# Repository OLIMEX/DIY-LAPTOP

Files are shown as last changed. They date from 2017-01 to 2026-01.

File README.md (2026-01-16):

OLIMEX Company Logo
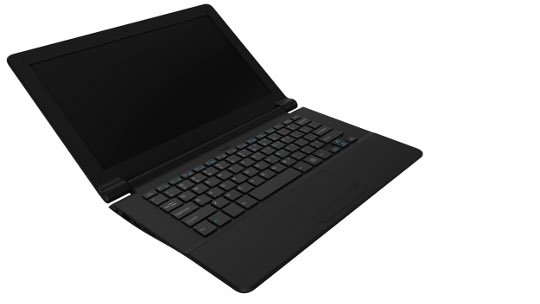
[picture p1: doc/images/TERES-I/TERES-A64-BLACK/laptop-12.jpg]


<br clear="right">

# TERES-I

<br><br>

## Overview

TERES-I is a Do-It-Yourself (DIY) Free/Open Source Hardware ([FOSH](https://wikipedia.org/wiki/Open-source_hardware)) and Software ([FOSS](https://wikipedia.org/wiki/Free_and_open-source_software)) laptop.
Stylish, elegant and lightweight, TERES-I is a convenient travel companion and is great for playing videos, browsing the web, or using a plethora of development suites.
It runs Linux on 64-bit ARM64 and x86 processors.

NOTE: TERES-I is currently considered an [evaluation board](doc/web/evaluation-board-notice.md) and not yet an end-product.

[Purchase your TERES-I here!](https://www.olimex.com/Products/DIY-Laptop/KITS)

| FEATURE | DESCRIPTION |
|:---:|:---:|
| **CPU** | [Quad-Core Allwinner A64 64-bit Cortex-A53](doc/datasheets/Allwinner-A64/A64_Datasheet_V1.1.pdf) |
| **Memory** | 2GB DDR3L RAM memory [2x Hynix H5TC8G63AMR-PBA](doc/datasheets/RAM/H5TC8G63AMR-PBA.pdf) |
| **Internal Storage** | 16GB eMMC memory [MTFC16GAKAENA-4M](doc/datasheets/eMMC/emmc_1664gb_ps8222_153b_v50_it.pdf) |
| **Monitor** | [LCD 11.6" 1366x768 resolution](doc/datasheets/TERES-015-LCD11.6/N116BGE-EA2.pdf) |
| **Video In** | [VGA 640x480 camera](HARDWARE/A64-TERES/TERES-019-Camera/N03A61B36DL32.pdf) |
| **Video Out** | mini HDMI |
| **Audio In/Out** | 2x (stereo) speakers; 2x 3.5mm audio jack (1x microphone in, 1x stereo out) |
| **Wireless** | Realtek 8723BS (WiFi 150Mb, BLE 4.0) |
| **USB** | 2x USB 2.0 |
| **Power** | 1x 9500mAh [battery](doc/datasheets/LiPo-Battery/JA426992P2P-Spec-Data-Sheet-3.7V-7000mAh--161201.pdf); 5V/3A input |
| **Weight** | 980 g (2.16 lb) |

## [Hardware](HARDWARE)

* [TERES-A64-WHITE](https://www.olimex.com/Products/DIY-Laptop/KITS/TERES-A64-WHITE)
* [TERES-A64-BLACK](https://www.olimex.com/Products/DIY-Laptop/KITS/TERES-A64-BLACK)
* [Spare parts](https://www.olimex.com/Products/DIY-Laptop/SPARE-PARTS)
* [Assembling your TERES-I](doc/web/hw_assembly.md)

## [Software](SOFTWARE)

TERES-I was designed to run on Linux distributions, but may also run Android and Windows operating systems.
The laptop's mainboard has eMMC flash loaded with Ubuntu Mate and basic programs – Internet browser, Open Office, Arduino IDE, IceStorm FPGA Verilog tools, a video player, etc.
Additional software is also available from Ubuntu repositories.

* [Installing an image](doc/web/sw_fresh-os.md)
* [Updating an image](doc/web/sw_updating-os.md)
* Building an image
  * [Internal script](SOFTWARE/A64-TERES/scripts/README.md)
  * [Manual build reference](http://linux-sunxi.org/Manual_build_howto)

## Other resources

* [FAQ](doc/web/res_faq.md)
* [Troubleshooting](https://www.olimex.com/forum/index.php?board=39.0)
* [Assembly manuals (PDF)](doc/manuals)
* [What's next?](doc/web/res_next-steps.md)
* [linux-sunxi Laptop Page](https://linux-sunxi.org/Olimex_Teres-A64) including hardware mods
* [Community Links](doc/web/res_community.md)
* 
## Community links

* Discord: #teres on Olimex [discord](https://discord.com/invite/QQEBXZk7y8) server
* IRC: #teres on OFTC.net, [webchat](https://webchat.oftc.net/?channels=#teres)

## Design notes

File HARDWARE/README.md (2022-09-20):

# Hardware

## Overview

All hardware schematics and board files are designed using [KiCad](http://kicad-pcb.org) open-source CAD software.

> KiCad is free software. KiCad is made available under the [GNU General Public License (GPL) version 3](https://www.gnu.org/licenses/gpl-3.0.en.html) or greater.

You may download KiCad and open for reviewing or editing each of the PCB files.
The schematics are also available as PDF files for easier viewing and/or printing.

**NOTE**: Please use the latest KiCad nightly development build, as the latest stable build may not have all required features.

## Introduction to the hardware of TERES-I

TERES-I internal electronics consists of the folowing boards:

### Main board ([PCB1-A64-MAIN](A64-TERES/TERES-PCB1-A64-MAIN))

The main board (**PCB1-A64-MAIN**) is comprised of:

* A64 processor
* RAM and flash NAND memories
* Power management unit
* LCD converter
* Connectors to different interfaces
* and others

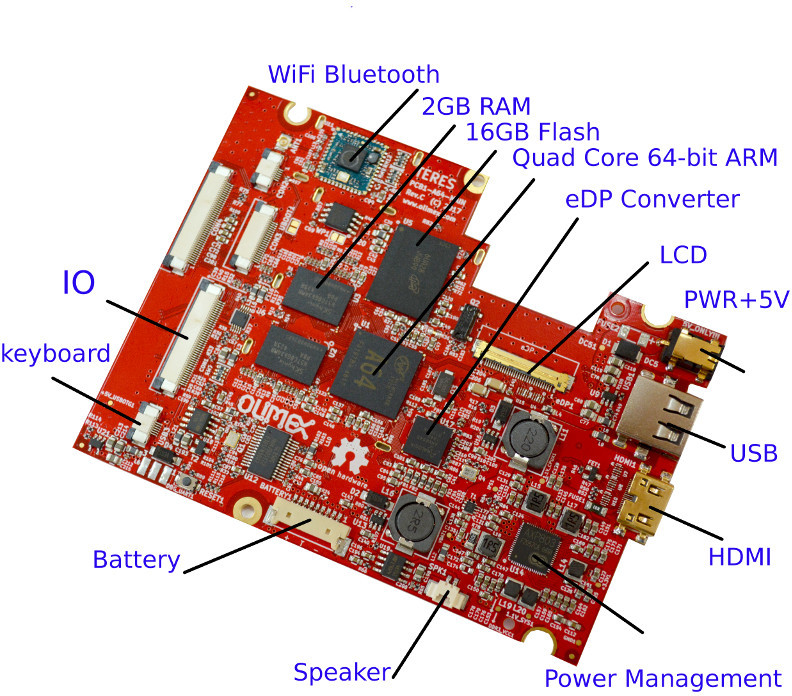
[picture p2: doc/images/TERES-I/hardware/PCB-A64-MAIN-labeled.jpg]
Main Board with Labels


Alternative main board processors and memory configuration options will be available in the future.
These should be compatible with all other existing boards.
Subsequent revisions are expected to have increased processing speed and improved memory performance.

### Keyboard controller ([TERES-PCB5-KEYBOARD](A64-TERES/TERES-PCB5-KEYBOARD))

The **KEYBOARD controller** board (**TERES-PCB5-KEYBOARD**) is responsible for handling the keyboard and touch pad interfaces.
This keyboard controller board allows you to completely reprogram the keyboard mapping and response according to your own taste.

This board contains an AVR processor.
Sources, binaries and update procedures for AVR firmware are available at GitHub.
Keyboard/touch controller firmware may be updated live on the board itself.
It can also be programmed using an Arduino microcontroller.
Touch screen parameters can also be changed.

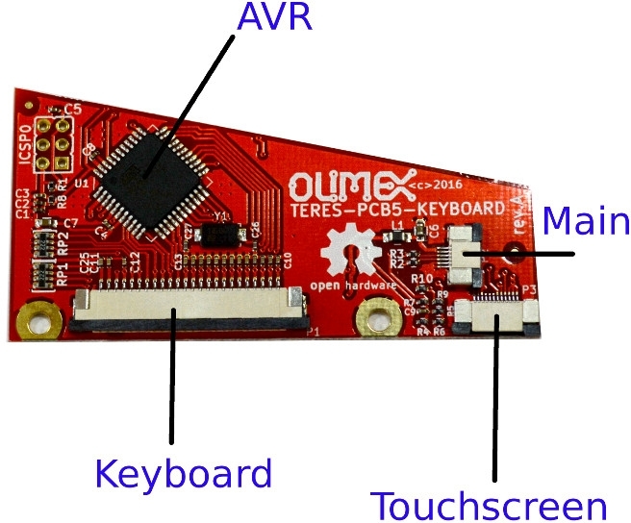
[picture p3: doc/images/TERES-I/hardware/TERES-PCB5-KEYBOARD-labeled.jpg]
Keyboard PCB with Labels


### I/O board ([TERES-PCB2-IO](A64-TERES/TERES-PCB2-IO))

The **IO** board (**TERES-PCB2-IO**) is comprised of:

- USB connector
- Headphone/debug connector
- SD card
- Speaker connector
- Microphone

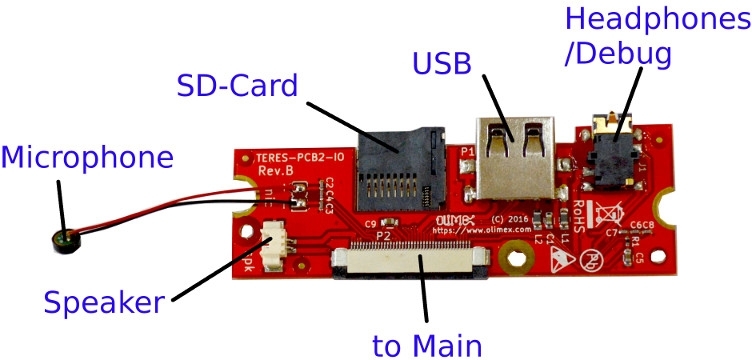
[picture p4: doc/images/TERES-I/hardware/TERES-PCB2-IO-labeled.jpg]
Power Button PCB with Labels


### Power button ([TERES-PCB4-PWR-BTN](A64-TERES/TERES-PCB4-PWR-BTN))

The **PWR** button board (**TERES-PCB4-PWR-BTN**) handles the keys for powering on and off the laptop.

Power Button PCB

### Touch buttons ([TERES-PCB3-TOUCH-BTN](A64-TERES/TERES-PCB3-TOUCH-BTN))

The **TOUCH** buttons board (**TERES-PCB3-TOUCH-BTN**) contains two buttons for left and right mouse click emulation.

Touch Button PCB - Front
Touch Button PCB - Rear

### Camera ([TERES-019-Camera](A64-TERES/TERES-019-Camera))

Camera PCB

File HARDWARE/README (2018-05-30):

# Hardware

## Overview

All hardware schematics and board files are designed using [KiCad](http://kicad-pcb.org) open-source CAD software.

> KiCad is free software. KiCad is made available under the GNU General Public License(GPL) version 3 or greater.

All KiCad design files are available within the [HARDWARE](HARDWARE) directory within this repository.
You may download KiCad* and open for reviewing or editing each of the PCB files.
The schematics are also available as PDF files for easier viewing and/or printing.

**NOTE**: Make sure to download the latest KiCad nightly development build.
The latest stable build may not have the features required.

## Introduction to the hardware of TERES-I

The TERES-I electronics part consists of five boards:

### Main board (PCB1-A64-MAIN)

The main board (PCB1-A64-MAIN) contains:

* A64 processor
* RAM and flash NAND memories
* Power management unit
* LCD converter
* Connectors to different interfaces
* and others

It looks like this:

Main Board with Labels

We expect to release extra main boards with different processors and memory configurations in the future.
These should work with all other existing boards.
It is expected newer main boards to have higher laptop speed and improved memory performance.

### Keyboard controller (TERES-PCB5-KEYBOARD)

The **KEYBOARD controller** board (**TERES-PCB5-KEYBOARD**) is responsible for handling the keyboard and touch pad interfaces.
This keyboard controller board allows you to completely reprogram the keyboard mapping and response according to your own taste.

The TERES-PCB5-KEYBOARD contains an AVR processor.
Sources, binaries and update procedures for the AVR firmware are available at GitHub.
You can update the firmware of the keyboard/touch controller live on the board itself.
It can also be programmed via an Arduino microcontroller.
Touch screen parameters can also be changed.

Keyboard PCB with Labels

### I/O board (TERES-PCB2-IO)

The **IO** board (**TERES-PCB2-IO**) contains the USB connector, headphone/debug connector, SD card, speaker connector and microphone.

Power Button PCB with Labels

### Power button (PCB4-PWR-BTN)

The **PWR** button board (**PCB4-PWR-BTN**) handles the keys for powering on and off the laptop.

Power Button PCB

### Touch buttons (TERES-PCB3-TOUCH-BTN)

The **TOUCH** buttons board (**TERES-PCB3-TOUCH-BTN**) contains two buttons for left and right mouse click emulation.

Touch Button PCB - Front
Touch Button PCB - Rear

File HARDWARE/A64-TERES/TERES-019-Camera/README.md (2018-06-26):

The camera module is not designed by Olimex LTD. It is a standard camera module and it is purchased separately.

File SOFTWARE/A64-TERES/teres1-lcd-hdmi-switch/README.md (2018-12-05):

# LCD(eDP)<->HDMI video switcher for Teres-I laptop

Script and DTB files that allow to switch video output medium 
from LCD(1366x768) to Dual display mode LCD(1366x768)+HDMI(1920x1080) and the other way around.

**WARNING! You need cable with mini HDMI connector to connect your monitor or TV 
(THE MINI HDMI CONNECTOR IS DIFFERENT FROM THE REGULAR HDMI CONNECTOR)**

	Ensure that you have a cable with proper connector and native HDMI monitor
	BEFORE YOU SET THE OUTPUT TO HDMI, ELSE IT WOULD BE HARD TO REVERT TO LCD.
 
If you set output to HDMI and you don't have HDMI monitor or 

How to install?

0. Download the files from this repository.

1. Copy files opt/teres... to /opt/teres recoursive. The command should be:
```
# sudo cp _path_to_file/teres /opt/teres -R
```
2. copy change-display in /usr/sbin directory
```
# sudo cp path_to_file/change-display /usr/local/sbin
```
3. Start the script change-display with 
```
# sudo change-display 
```
and follow the on-screen instructions.

4. Reboot the laptop.

## FAQ:

1. Can I have HDMI and LCD working at the same time?

A: Yes.

2. Does this work when I boot from the eMMC (e.g. I don't boot from a card)???

A: Yes.

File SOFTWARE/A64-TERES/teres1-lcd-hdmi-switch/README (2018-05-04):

# LCD(eDP)<->HDMI video switcher for Teres-I laptop

Script and DTB files that allow to switch video output medium 
from LCD(1366x768) to HDMI(1280x720) and the other way around.

**WARNING! You need cable with mini HDMI connector to connect your monitor or TV 
(THE MINI HDMI CONNECTOR IS DIFFERENT FROM THE REGULAR HDMI CONNECTOR)**

	Ensure that you have a cable with proper connector and native HDMI monitor
	BEFORE YOU SET THE OUTPUT TO HDMI, ELSE IT WOULD BE HARD TO REVERT TO LCD.
 
If you set output to HDMI and you don't have HDMI monitor or 

How to install?

0. Download the files from this repository.

1. Copy a64-olinuxino-hdmi.dtb and a64-olinuxino-lcd.dtb in /boot/a64/ directory,
where the default a64-olinuxino.dtb file is located. The command should be:
```
# sudo cp _path_to_file/a64-olinuxino-hdmi.dtb /boot/a64/
# sudo cp _path_to_file/a64-olinuxino-lcd.dtb /boot/a64/
```
2. copy change-display in /usr/sbin directory
```
# sudo cp path_to_file/change-display /usr/sbin
```
3. Start the script change-display with 
```
# sudo change-display 
```
and follow the on-screen instructions.

4. Reboot the laptop.

## FAQ:

1. Can I have HDMI and LCD working at the same time?

A: It might be possible but we couldn't get it working. If you manage to do it,
please share what you did so we can update this guide, we would test and publish it.

2. I changed the video output to HDMI but I don't have a cable with fitting mini HDMI 
connector nor HDMI minotor? What now?

A: Either find a cable with fitting connector and HDMI monitor or re-write 
the official image to a micro SD card and transfer it to the eMMC. Refer to 
chapter 10 of the user's manual "10. Installing a fresh official image to TERES-I".

3. Does this work when I boot from the eMMC (e.g. I don't boot from a card)???

A: Yes.

First experimental release.

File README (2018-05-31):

OLIMEX Company Logo


<br>

# TERES-I Laptop

<br><br>

## Overview

TERES-I is a Do-It-Yourself (DIY) Free/Open Source Hardware ([FOSH](https://wikipedia.org/wiki/Open-source_hardware)) and Software ([FOSS](https://wikipedia.org/wiki/Free_and_open-source_software)) laptop design leveraging ARM64 and x86 processors.
DIY kits are ready-to-assemble using the [instructions provided](doc/web/hw_assembly.md) and may be purchased [here](https://www.olimex.com/Products/DIY-Laptop/KITS).

* [What is TERES-I?](doc/web/intro_what-is-teres-i.md)
* [Where does the name TERES come from?](doc/web/intro_name-origin.md)
* [What makes this laptop so different?](doc/web/intro_what-is-unique.md)
* [Why does open-source matter so much?](doc/web/intro_importance-of-open-source.md)
* [Where are the open-source materials?](doc/web/intro_sources.md)

## Assembling your TERES-I

* [What do you get in the package?](doc/web/hw_in-the-box.md)
* [Assembling your TERES-I laptop](doc/web/hw_assembly.md)

## Hardware

* [TERES-A64-WHITE](https://www.olimex.com/Products/DIY-Laptop/KITS/TERES-A64-WHITE/open-source-hardware)
* [TERES-A64-BLACK](https://www.olimex.com/Products/DIY-Laptop/KITS/TERES-A64-BLACK/open-source-hardware)
* [Spare parts](https://www.olimex.com/Products/DIY-Laptop/SPARE-PARTS/)

## Software

TERES-I was designed to run on Linux distributions, but may also run Android and Windows operating systems.

* [Installing a fresh official image to TERES-I](doc/web/sw_fresh-os.md)
* [Updating an image](doc/web/sw_updating-os.md)
* [Building an image](SOFTWARE/A64-TERES/scripts/README.md)

## Other resources

* [FAQ](doc/web/res_faq.md)
* [Troubleshooting](doc/web/res_troubleshooting.md)
* [Download manuals](doc/manuals)
* [What's next?](doc/web/res_next-steps.md)
* [Community Links](doc/web/res_community.md)

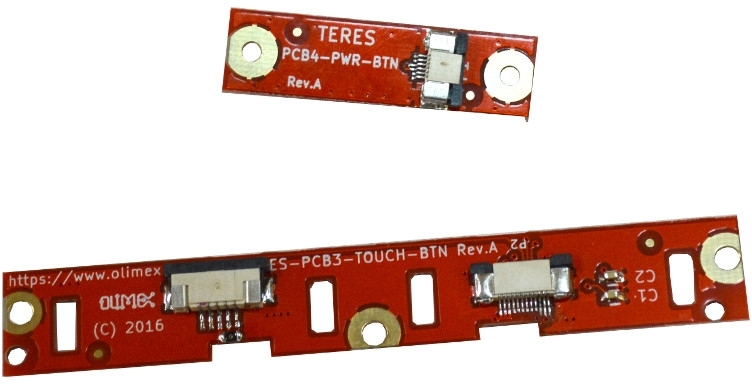
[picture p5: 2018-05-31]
doc/images/TERES-I/hardware/TERES-PCB3-TOUCH-BTN.jpg

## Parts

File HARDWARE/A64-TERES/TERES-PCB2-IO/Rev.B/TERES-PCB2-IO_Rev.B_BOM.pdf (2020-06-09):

TERES-PCB2-IO

Артикул
B

Ревизия

| Съставен елемент | Реви зия | Количество | Забележка
1 | ELECTRETE MICROPHONE 4x1.5mm (TERES) | | 1 | бр. | MIC
2 | SMD CAP 0402 10 PF NP0 50VDC | | 1 | бр. | C4
3 | SMD CAP 0402 33 PF 50VDC 5% | | 5 | бр. | C2, C3, C6, C7, C8
4 | SMD CAP 0603 10 UF 6.3V | | 3 | бр. | C1, C5, C9
5 | SMD CON 53261021 (TERES) | | 1 | бр. | P4
6 | SMD CON EZ-PJ-3510A-W-H (TERES) | | 1 | бр. | J1
7 | SMD CON FPV-WZA21-40LF | | 1 | бр. | P2
8 | SMD CON TF-9P-01 (TERES) | | 1 | бр. | MICRO_SD1
9 | SMD CON USB-3.5MM-DIP (TERES) | | 1 | бр. | P1
10 | SMD IND 0805 600 OHM 2A HIGH CURRENT | | 2 | бр. | L1, L2
11 | SMD RES 0402 2.2 K 5% | | 1 | бр. | R1
12 | ГПП TERES-PCB2 IO | B | 1 | бр. | PCB

# Bill Of Materials

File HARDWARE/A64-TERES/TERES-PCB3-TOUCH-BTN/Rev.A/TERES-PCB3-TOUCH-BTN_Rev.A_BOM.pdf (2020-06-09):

TERES-PCB3-TOUCH

Артикул
A

Ревизия

| Съставен елемент | Реви зия | Количество | Забележка
1 | SMD CAP 0603 10 NF X7R 50VDC 10% | | 2 | бр. | C1, C2
2 | SMD CON FPA-WZB25-05-LF (TERES) | | 1 | бр. | P1
3 | SMD CON FPV-WZA21-12-LF (TERES) | | 1 | бр. | P2
4 | SMD RES 0805 0 OHM 5% | | 1 | бр. | доработка на P1
5 | SMD SWITCH ТАКТИЛЕН TS-1187 (TERES) | | 2 | бр. | SWR1, SWL1
6 | ГПП TERES-PCB3 TOUCH | A | 1 | бр. | PCB

# Bill Of Materials

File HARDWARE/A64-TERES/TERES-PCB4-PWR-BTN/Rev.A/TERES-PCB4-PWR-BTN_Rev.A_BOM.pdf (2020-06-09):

TERES-PCB4-BTN

Артикул
A

Ревизия

| Съставен елемент | Реви зия | Количество | Забележка
1 | SMD CON FPV-WZA21-06-LF (TERES) | | 1 | бр. | P1
2 | SMD SWITCH ТАКТИЛЕН TS-1187 (TERES) | | 1 | бр. | SW1
3 | ГПП TERES-PCB4 BTN | A | 1 | бр. | PCB

# Bill Of Materials

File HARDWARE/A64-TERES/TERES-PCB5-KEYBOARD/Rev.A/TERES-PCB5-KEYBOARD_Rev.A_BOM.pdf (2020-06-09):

TERES-PCB5-KEYBOARD

Артикул
A1

Ревизия

| Съставен елемент | Реви зия | Количество | Забележка
1 | SMD CAP 0402 1 NF X7R 50VDC | | 16 | бр. | C10---C25
2 | SMD CAP 0402 100 NF 10% 10VDC | | 5 | бр. | C3, C4, C5, C8, C9
3 | SMD CAP 0402 22 PF NP0 5% | | 2 | бр. | C26, C27
4 | SMD CAP 0402 220 NF +80-20% 10VDC | | 2 | бр. | C1, C2
5 | SMD CAP 0603 1 UF 10V X5R | | 2 | бр. | C6, C7
6 | SMD CON FPA-WZB25-24-LF (TERES) | | 1 | бр. | P1
7 | SMD CON FPV-WZA21-06-LF (TERES) | | 1 | бр. | P2
8 | SMD CON FPV-WZA21-12-LF (TERES) | | 1 | бр. | P3
9 | SMD IC ATMEGA32U4-AU | | 1 | бр. | U1
10 | SMD IND 0805 600 OHM 2A HIGH CURRENT | | 1 | бр. | L1
11 | SMD QUARTZ 5x3.2mm 16 Mhz 20PPM 2P 12PF | | 1 | бр. | Y1
12 | SMD RES 0402 10 K 1% | | 7 | бр. | R1, R4, R5, R6, R7, R9, R10
13 | SMD RES 0402 22 OHM 5% | | 3 | бр. | R2, R3, R8
14 | SMD RMAT (4x0603) 1.5 K 5% | | 2 | бр. | RP1, RP2
15 | ГПП TERES-PCB5 KEYB | A | 1 | бр. | PCB

# Bill Of Materials

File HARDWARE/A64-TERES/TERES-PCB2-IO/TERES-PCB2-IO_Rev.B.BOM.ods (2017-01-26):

Designation | Quantity | Designator | Package
SMD КОНД 0603 10 UF 10V 20% | 3 | C1,C9,C5 | C_0603_5MIL_DWS
SMD КОНД 0402 33 PF +-0.25 PF | 5 | C2,C3,C6,C7,C8 | C_0402_SMALL
SMD КОНД 0402 10 PF NP0 50VDC | 1 | C4 | C_0402_SMALL
SMD СЪЕДИНИТЕЛ EZ-PJ-3510A-W-H | 1 | J1 | EZ-PJ-3510A-W-H
SMD ИНД 0805 600 OHM 2A HIGH CURRENT | 2 | L1,L2 | L_0805_5MIL_DWS
SMD СЪЕДИНИТЕЛ TF-9P-01 (TERES) | 1 | MICRO_SD1 | uSD-CARD-TERES
SMD СЪЕДИНИТЕЛ USB-3.5MM (TERES) | 1 | P1 | USB-A-THERES
SMD СЪЕДИНИТЕЛ FPV-WZA21-40LF | 1 | P2 | FPV-WZA21-40-LF
SMD СЪЕДИНИТЕЛ 53261021 (TERES) | 1 | P4 | CON-SPK-HERMES
SMD РЕЗ 0402 2.2 K 5% | 1 | R1 | R_0402_SMALL

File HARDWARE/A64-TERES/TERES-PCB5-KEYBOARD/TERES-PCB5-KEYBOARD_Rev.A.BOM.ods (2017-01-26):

Designation | Quantity | Designator | Package
SMD РЕЗ. 5x3.2mm 16 Mhz 30PPM 12PF | 1 | Y1 | Q5x3.25
SMD ИС ATMEGA32U4-AU | 1 | U1 | TQFP44
FPV-WZB25-24-LF | 1 | P1 | FLEX-CONN-KBD-TERES-24x1
SMD КОНД 0402 220 NF +80-20% 10VDC | 2 | C1, C2 | C0402
SMD КОНД 0402 100 NF 10% 10VDC | 5 | C3,C4,C5,C8,C9 | C0402
SMD КОНД 0603 1 UF 10V X5R | 2 | C6,C7 | C_0603_5MIL_DWS
SMD КОНД 0402 1 NF X7R 50VDC | 16 | C10,C11,C12,C13,C14,C15,C16,C17,C18,C19,C20,C21,C22,C23,C24,C25 | C0402
SMD КОНД 0402 22 PF NP0 5% | 2 | C26,C27 | C0402
SMD ИНД 0805 600 OHM 2A HIGH CURRENT | 1 | L1 | L_0805_5MIL_DWS
SMD РЕЗ 0402 10 K 5% | 1 | R1, R4,R5,R6,R7,R9,R10 | R_0402_5MIL_DWS
SMD РЕЗ 0402 22 OHM 5% | 3 | R2,R3,R8 | R_0402_5MIL_DWS
SMD РЕЗ.МАТРИЦА (4x0603) 1.5 K 5% | 2 | RP1,RP2 | R_MATRIX_4_KICAD
SMD СЪЕДИНИТЕЛ FPA-WZB25-05-LF (TERES) | 1 | P3 | FLEXCON-0.5-12
SMD СЪЕДИНИТЕЛ FPV-WZB201-06-LF | 1 | P2 | FLEXCON-0.5-6

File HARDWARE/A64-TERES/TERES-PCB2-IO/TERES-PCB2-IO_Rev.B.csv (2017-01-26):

Id | Designator | Package | Quantity | Designation | Supplier and ref
1 | J1 | EZ-PJ-3510A-W-H | 1 | AUDIOJACK_THERES
2 | P1 | USB-A-THERES | 1 | USB_A
3 | ,,,,, | Fiducial1x3_transp | 6
4 | Ref**,Ref**,Ref**,Ref**,Ref**,Ref**,Ref**,Ref**,Ref**,Ref** | via_09_07 | 10 | Val**
5 | MountingHole,MountingHole,MountingHole | Mounting_hole_2.5mm | 3 | Mounting_hole_3.3mm
6 | MountingHole,MountingHole | Mounting_hole_THERES | 2 | Mounting_hole_3.3mm
7 | P4 | CON-SPK-HERMES | 1 | CONN_01X02
8 | P2 | FPV-WZA21-40-LF | 1 | CONN_01X40
9 | C1,C9,C5 | C_0603_5MIL_DWS | 3 | 10uF
10 | C2,C3,C6,C7,C8 | C_0402_SMALL | 5 | 33pF
11 | C4 | C_0402_SMALL | 1 | 10pF
12 | L1,L2 | L_0805_5MIL_DWS | 2 | FB0805
13 | P3 | MIC-TERES | 1 | CONN_01X02
14 | R1 | R_0402_SMALL | 1 | 2.2K
15 |  | OLIMEX_LOGO_SMALL_TB | 1
16 | Ref** | LOGO_ANTISTATIC_SMALL_4.5mmX2.8mm | 1 | Val**
17 |  | LOGO_PBFREE | 1
18 |  | LOGO_RECYCLEBIN_1 | 1
19 | MICRO_SD1 | uSD-CARD-TERES | 1 | MICRO_SD(TFC-WXCP11-08-LF)

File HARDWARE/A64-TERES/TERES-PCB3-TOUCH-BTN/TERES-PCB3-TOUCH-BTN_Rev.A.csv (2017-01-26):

Id | Designator | Package | Quantity | Designation | Supplier and ref
1 | ,,,,,,,,,,,, | via_04_055 | 13
2 | MountingHole,MountingHole,MountingHole | Mounting_hole_TERES | 3 | Mounting_hole_3.3mm
3 | ,,, | Fiducial1x3_transp | 4
4 | C1,C2 | C_0603_5MIL_DWS | 2 | 10nF
5 | P2 | FLEXCON-0.5-12 | 1 | CONN_01X12
6 | P1 | FLEXCON_5x1mm | 1 | CONN_01X05
7 | SWR1,SWL1 | tacktil_5x5_teres | 2 | SW_PUSH
8 | MountingHole,MountingHole | NPTH_2.2mm | 2 | Mounting_hole_2.5mm

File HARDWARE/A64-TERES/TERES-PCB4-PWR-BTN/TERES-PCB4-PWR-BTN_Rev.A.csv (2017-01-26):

Id | Designator | Package | Quantity | Designation | Supplier and ref
1 | SW1 | tacktil_5x5_teres | 1 | SW_PUSH
2 | ,,, | Fiducial1x3_transp | 4
3 | MountingHole,MountingHole | Mounting_hole_2.5mm | 2 | Mounting_hole_2.5mm
4 | P1 | FLEXCON-0.5-6 | 1 | CONN_01X06

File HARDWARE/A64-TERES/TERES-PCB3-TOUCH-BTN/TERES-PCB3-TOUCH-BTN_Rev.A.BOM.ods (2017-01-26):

Designation | Quantity | Designator | Package
SMD КОНД 0603 10 NF X7R 50VDC 10% | 2 | C1,C2 | C_0603_5MIL_DWS
SMD СЪЕДИНИТЕЛ FPA-WZB25-05-LF (TERES) | 1 | P2 | FLEXCON-0.5-12
SMD СЪЕДИНИТЕЛ FPA-WZB25-05-LF (TERES) | 1 | P1 | FLEXCON_5x1mm
SMD КЛЮЧ ТАКТИЛЕН TS-1187 (TERES) | 2 | SWR1,SWL1 | tacktil_5x5_teres

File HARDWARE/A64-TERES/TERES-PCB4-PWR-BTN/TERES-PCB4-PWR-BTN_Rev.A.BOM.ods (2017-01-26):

Designation | Quantity | Designator | Package
SMD КЛЮЧ ТАКТИЛЕН TS-1187 (TERES) | 1 | SW1 | tacktil_5x5_teres
SMD СЪЕДИНИТЕЛ FPV-WZB201-06-LF | 1 | P1 | FLEXCON-0.5-6

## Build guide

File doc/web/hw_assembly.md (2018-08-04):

# TERES-I Assembly

## Table of Contents

* [Preparation](#preparation)
* [Included Materials](#included-materials)
* [Touchpad](#touchpad)
* [Touchpad Buttons](#touchpad-buttons)
* [Microphone](#microphone)
* [Power Buton](#power-button)
* [Mainboard](#mainboard)
* [Cabling](#cabling)
* [Speakers](#speakers)
* [Body Panels](#body-panels)
* [Camera](#camera)
* [WiFi](#wifi)
* [More Cabling](#more-cabling)
* [Magnet](#magnet)
* [Battery](#battery)
* [FInal Steps](#final-steps)

## Preparation

First, prepare a workspace with enough room and light to assemble the laptop.
Cover the workspace with soft material to prevent scratching the laptop's plastic parts.
Ideally use a grounded electronics mat.
Read and follow the instructions carefully and do not rush!
Disassembling the finished unit to fix earlier mistakes is considerably harder than assembling the unit!

## [Included Materials](hw_in-the-box.md)

## Touchpad

The assembly process begins with the **TERES-006-Keyboard**:

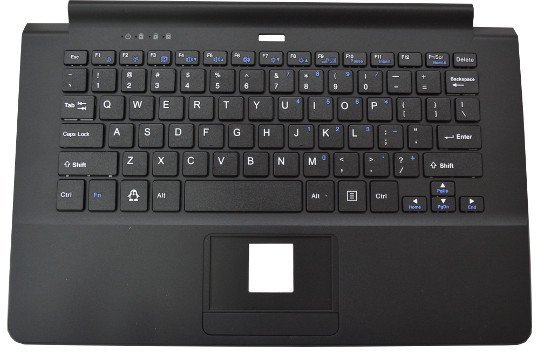
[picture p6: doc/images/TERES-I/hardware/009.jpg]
TERES-006-Keyboard 1
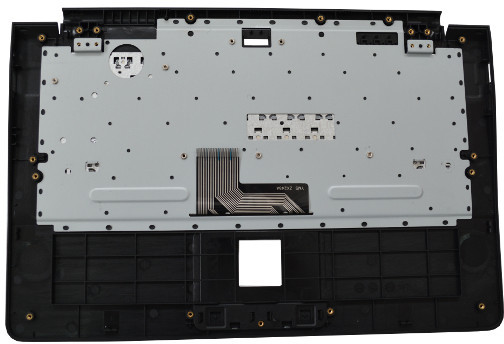
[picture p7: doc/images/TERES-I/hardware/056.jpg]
TERES-006-Keyboard 2
 

First attach the touchpad **TERES-023-Touch** to the keyboard's body:

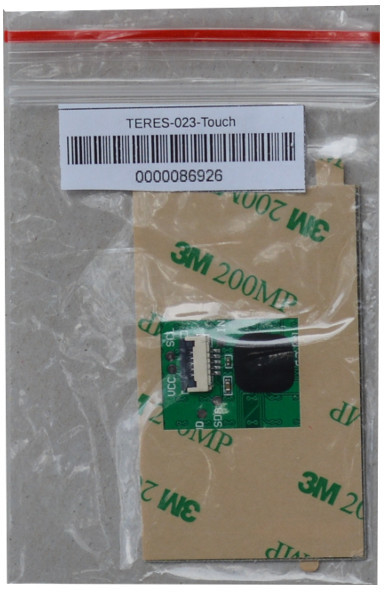
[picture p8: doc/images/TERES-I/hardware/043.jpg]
TERES-023-Touch 1
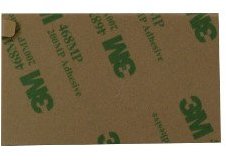
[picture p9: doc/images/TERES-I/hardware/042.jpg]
TERES-023-Touch 2
 

The touchpad uses double sided adhesive tape.
Remove the protective foil and place it on the top side of the keyboard body like shown in the pictures below:

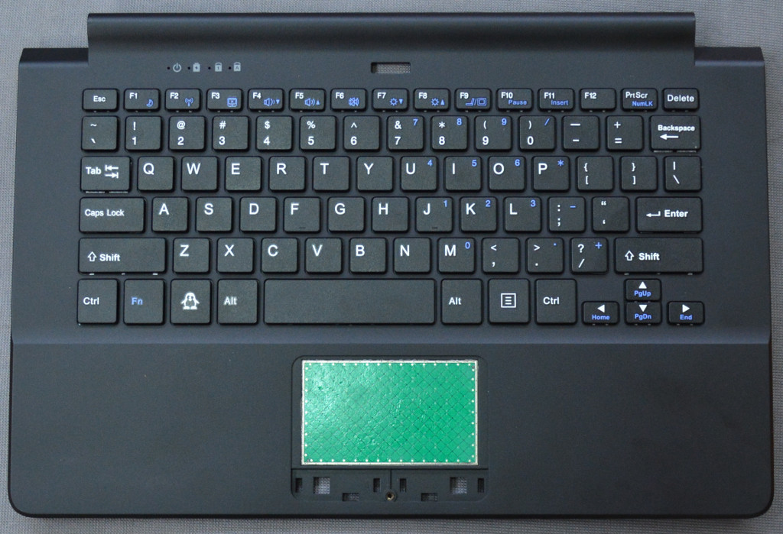
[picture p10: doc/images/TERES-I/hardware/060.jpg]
Tape install 1
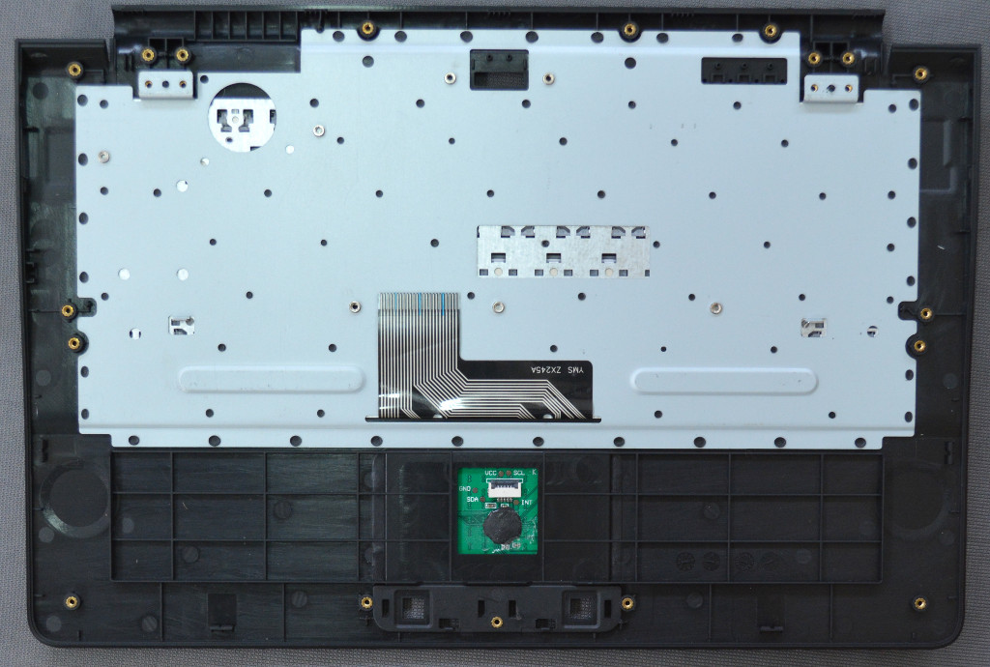
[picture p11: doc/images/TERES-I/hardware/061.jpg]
Tape install 2
 

Be careful to place the touchpad connector so that it faces the correct way!
The exposed pins of the connector must be pointing **up**.

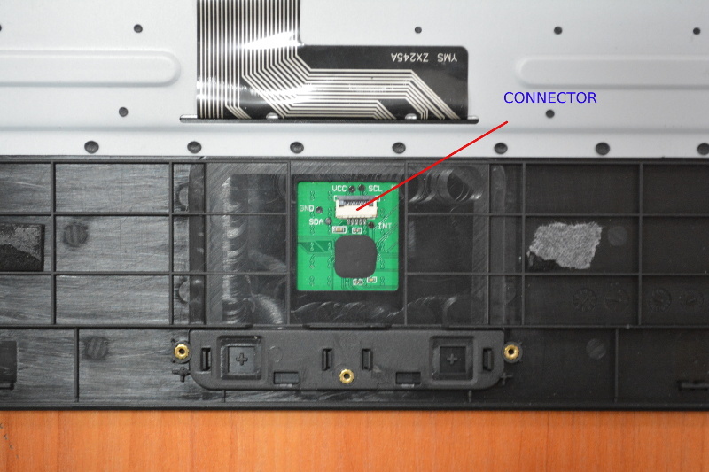
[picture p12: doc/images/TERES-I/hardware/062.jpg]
Touchpad connector


The touchpad snaps tightly to the upper side plastic.
You should place the pastic cover on an even surface and make sure the touchpad connector is fully inserted.

Next, turn over the cover and place **TERES-022-Touch-Cover** and **TERES-010-Touch-Btns** on top of the touchpad:

TERES-022-Touch-Cover TERES-010-Touch-Btns

The final result looks like this:

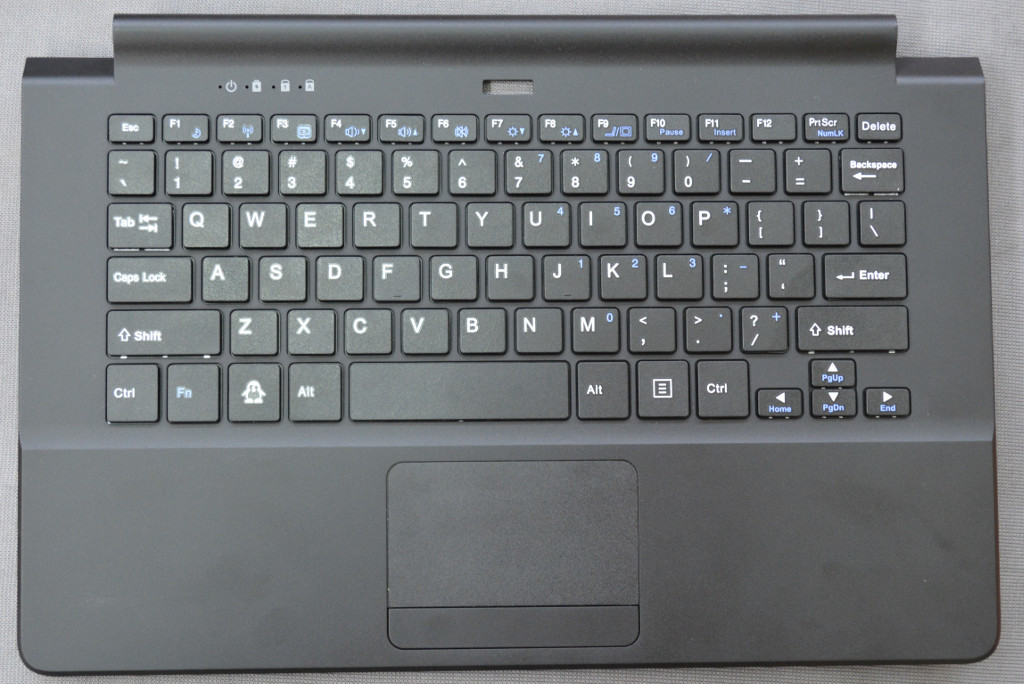
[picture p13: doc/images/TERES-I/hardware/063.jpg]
Keyboard top
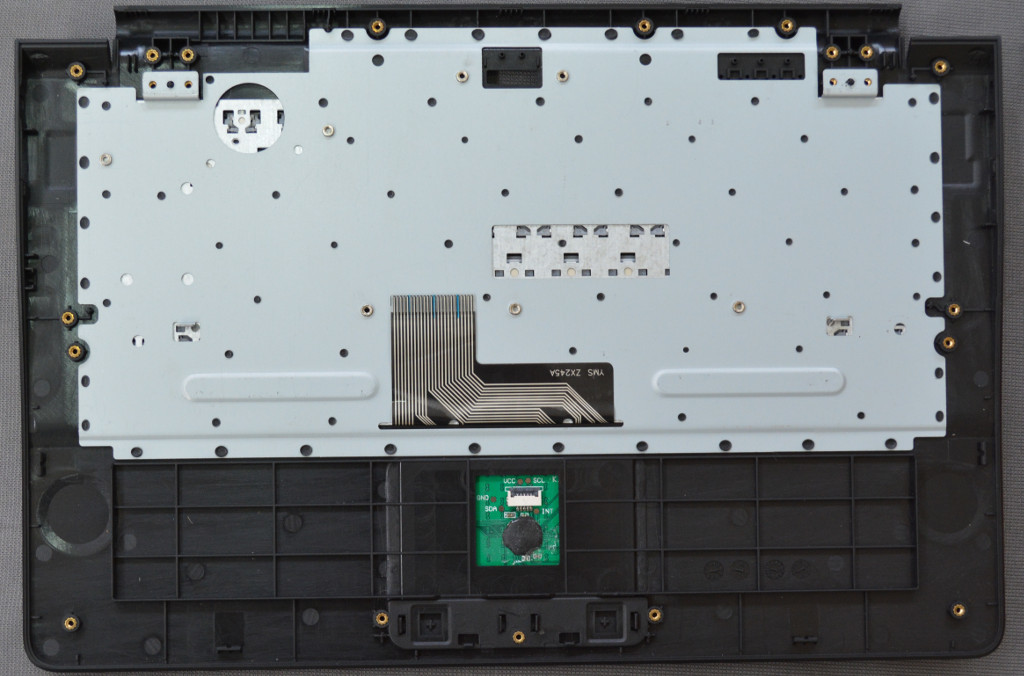
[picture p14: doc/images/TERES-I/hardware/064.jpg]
 

## Touchpad Buttons

The next step is to attach the TERES printed circuit boards to the keyboard body.
For this purpose use the **TERES-014-Screw-Set**.
Note that in this set there are 42 screws of different lengths:

* M2 x 1.5 ( 4 pcs)
* M2 x 3   ( 9 pcs)
* M2 x 4   (17 pcs)
* M2 x 5   (12 pcs)

It is a good practice to:

* Sort all the screws before you begin, as each screw must be placed in a specific location based on length
* Do not mix the lengths of the screws during installation; doing so may damage the plastic parts
* Be gentle! Do not torque the srews as tight as possible; this may break the plastic

All screws have same diameter (**M2**), but different lengths.
Use a metric ruler if you have difficulties determining the length.
For example, the **M2 x 5** screw would have **5mm** thread length (i.e. not including the head).

For the PCBs the **M2 x 3** screws must be used.

Now we assemble the **TERES-PCB3-Touch** PCB:

TERES-PCB3-Touch 1 TERES-PCB3-Touch 2

It is shown below, attached to the keyboard body.
Note that only the middle screw is used.
The other two screws will later be used when fixing the bottom plastic cover:

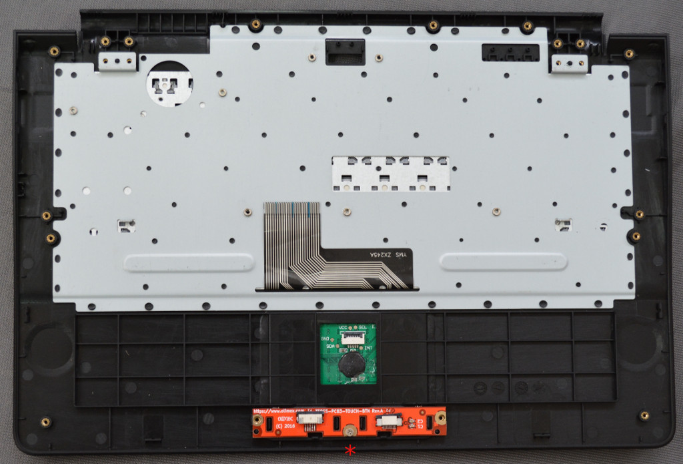
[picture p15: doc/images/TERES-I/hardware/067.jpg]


The next PCB to attach is the **TERES-PCB2-IO**:

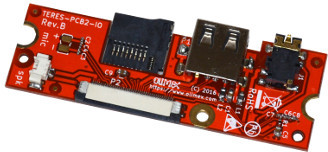
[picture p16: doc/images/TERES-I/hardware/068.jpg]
TERES-PCB2-IO 1
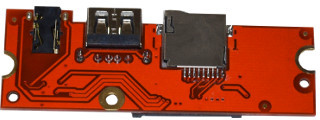
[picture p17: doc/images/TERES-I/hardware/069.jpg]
TERES-PCB2-IO 2
 

The PCB2 board has a microphone which has to be placed in the side pocket specially designated for it.

## Microphone

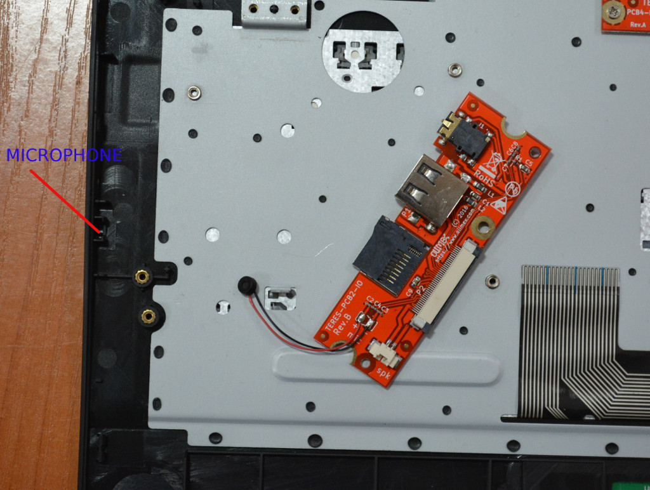
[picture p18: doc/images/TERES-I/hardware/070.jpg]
Microphone


After the microphone is put in place, slip the board at an angle into the side openings for the SD card, USB, and audio connector, then place it down.

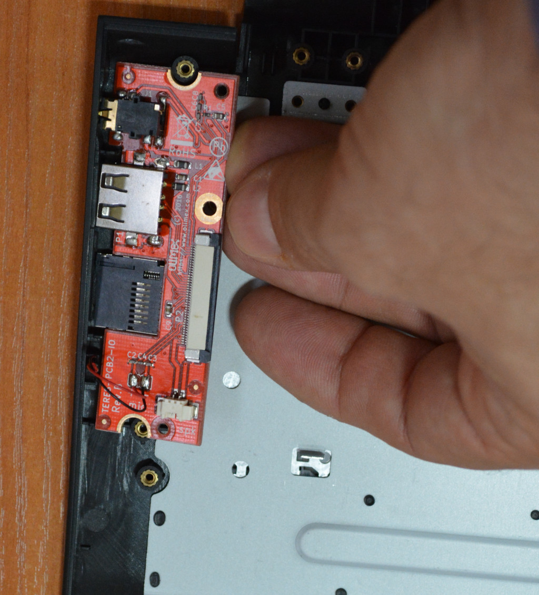
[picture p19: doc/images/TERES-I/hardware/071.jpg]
Placement


Then use one **M2 x 3** screw to fix the board:

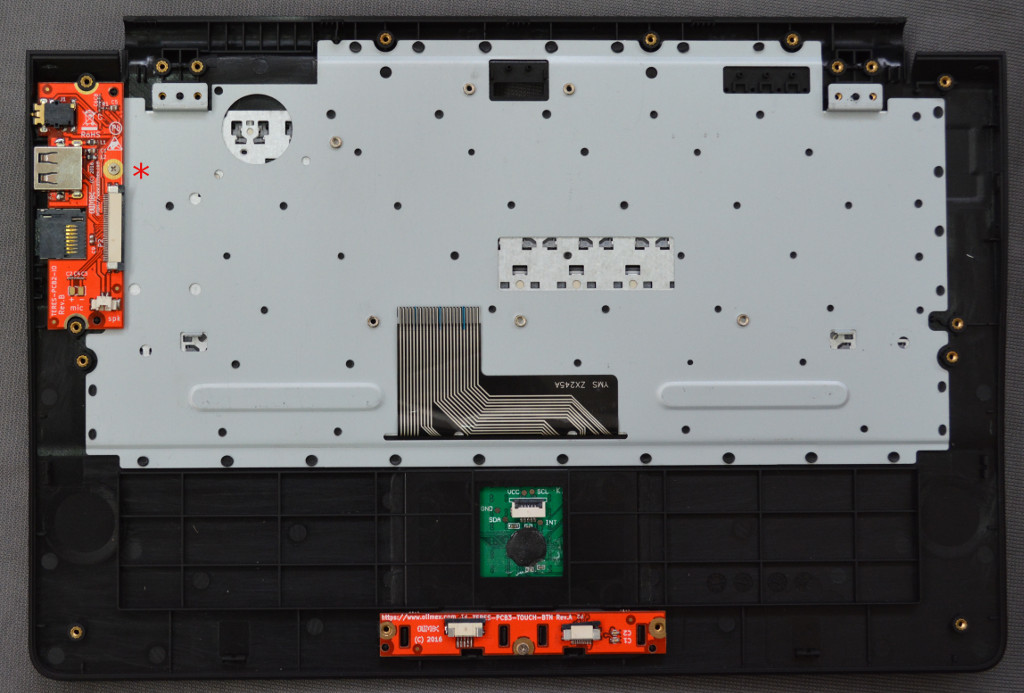
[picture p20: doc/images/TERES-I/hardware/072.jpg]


Please make sure that the side connectors are well aligned:

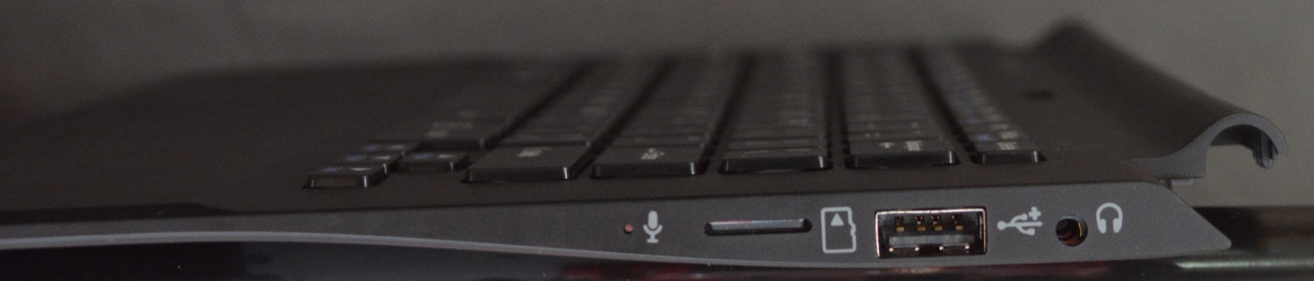
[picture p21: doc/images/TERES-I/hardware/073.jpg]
Keyboard side


## Power Button

Next you put the PWR button plastic:

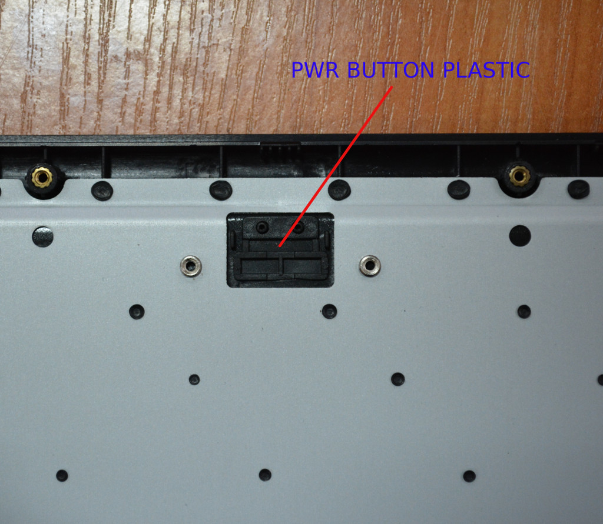
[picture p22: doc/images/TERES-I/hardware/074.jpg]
PWR button install
 PWR button

Then the LED pipe:

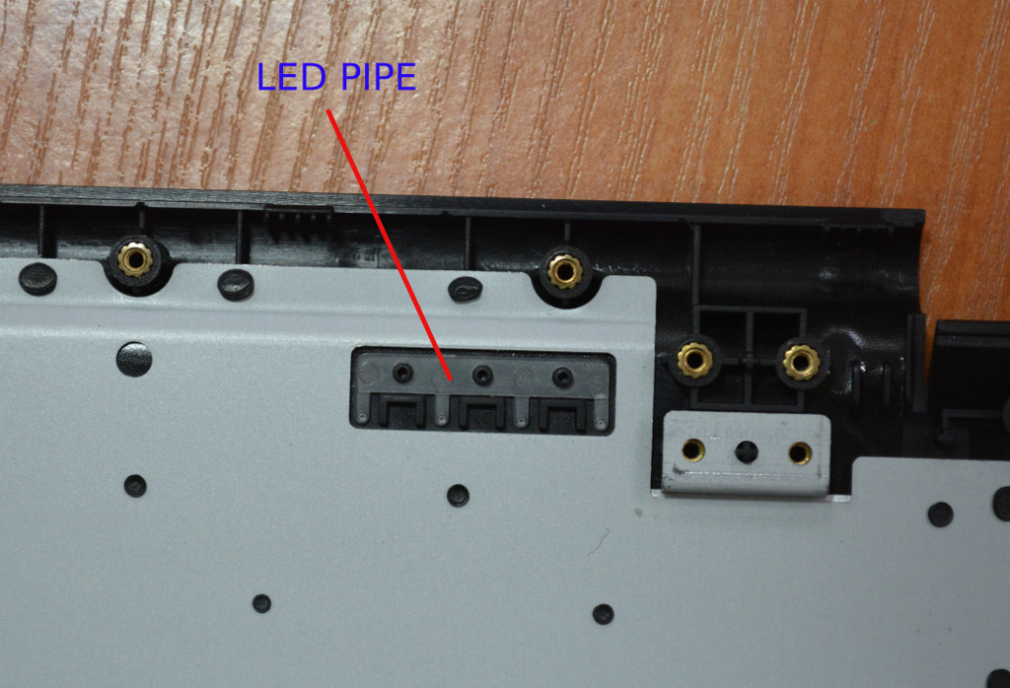
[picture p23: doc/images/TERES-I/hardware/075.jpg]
LED Pipe install
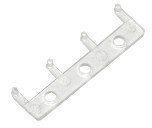
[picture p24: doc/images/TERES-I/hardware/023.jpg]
LED Pipe
 

Next attach the TERES-PCB4-Btn (the power button):

TERES-PCB4-Btn 1 TERES-PCB4-Btn 2

The TERES-PCB4-Btn is attached with two **M2 x 3** screws with the connector pointing to the right side:

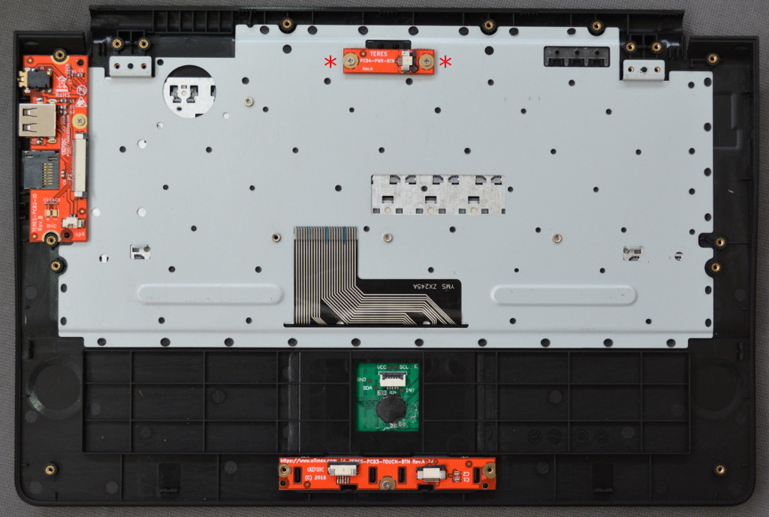
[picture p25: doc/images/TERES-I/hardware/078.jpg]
TERES-PCB4-Btn 3


## Mainboard

The next step is to assemble the big **TERES-PCB1-A64**:

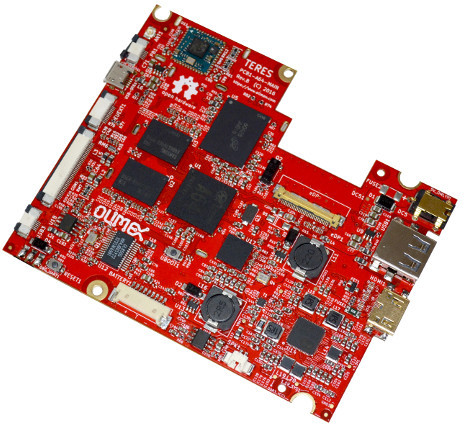
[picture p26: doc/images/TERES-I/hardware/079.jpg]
TERES-PCB1-A64 1
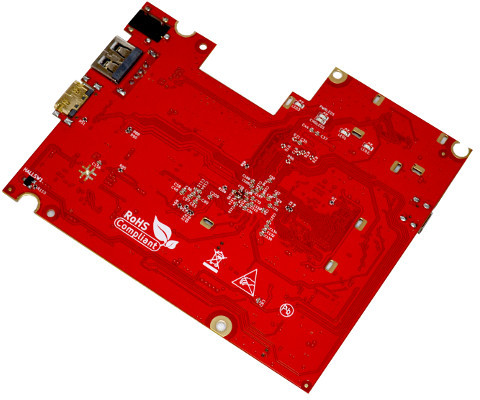
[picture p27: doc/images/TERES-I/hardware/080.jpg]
TERES-PCB1-A64 2
 

This is the main board and you should handle it very carefully.
Do not bend it, do not drop it, etc.
This board is very sensitive to static electricity; a grounding strap is recommended for use during handling.

It is a bit tricky to place the mainboard in the correct position as you must slide it in a way that the connectors enter properly in the plastic body side openings.
If you succeed you will see all the PCB support nuts from the keyboard body pass exactly through the openings of the PCB.
You need to use two **M2 x 3** screws to attach it:

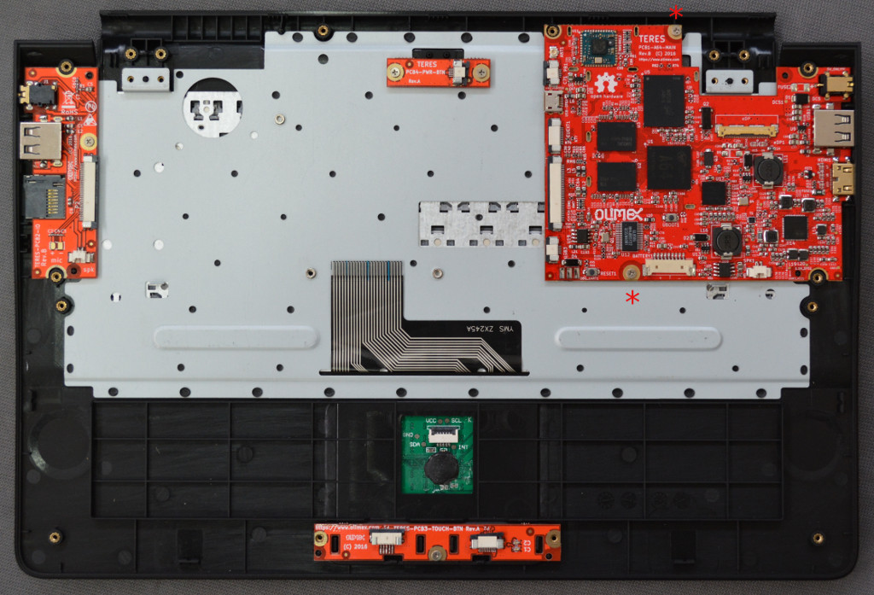
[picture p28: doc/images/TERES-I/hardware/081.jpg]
TERES-PCB1-A64 3


Again, ensure that the side connectors are properly aligned:

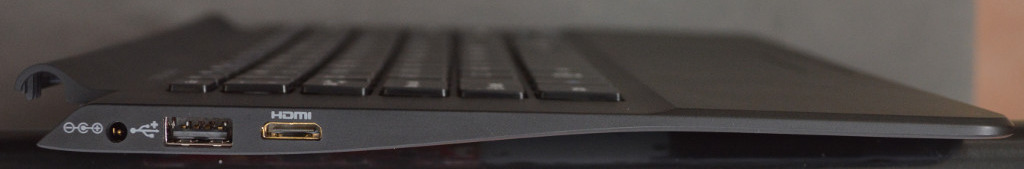
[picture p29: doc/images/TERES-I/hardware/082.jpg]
Keyboard left


## Cabling

Now connect **TERES-PCB2-IO** with **TERES-PCB1-A64**.
For this purpose, use the Flat Cable **TERES-027-FPC-IO-Main**. 

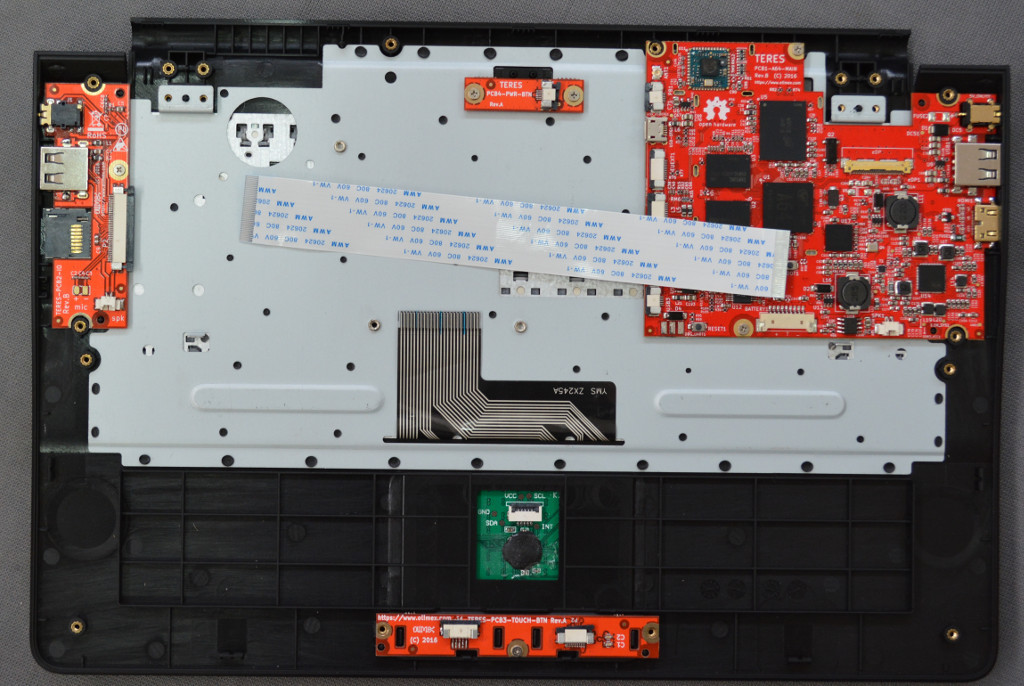
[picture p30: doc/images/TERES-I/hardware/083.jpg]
TERES-PCB2-IO 1


There are two 40-pin connectors on **TERES-PCB2-IO** and **TERES-PCB1-A64**.
You have to open the latch – pull the dark plastic of the connector up and insert the FPC cable above it with the contacts up:

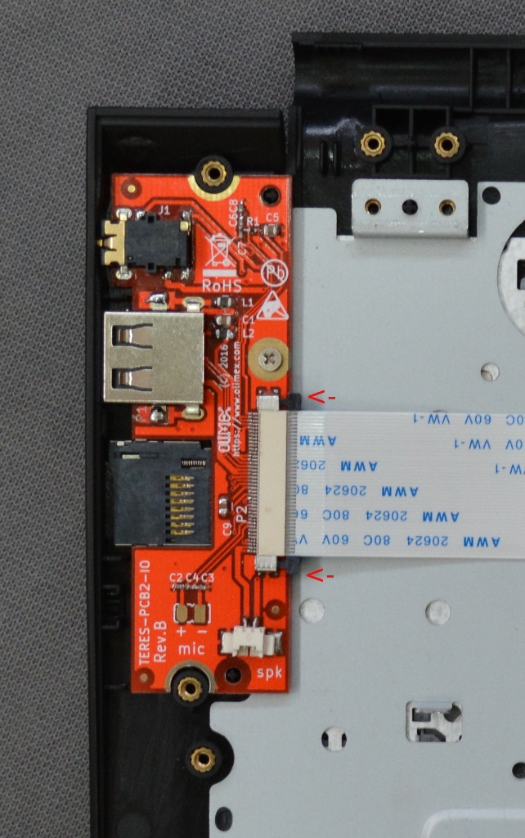
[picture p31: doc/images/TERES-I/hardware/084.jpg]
TERES-PCB2-IO 2


After you have inserted the cable, push the dark plastic back down so it locks the cable to the connector:

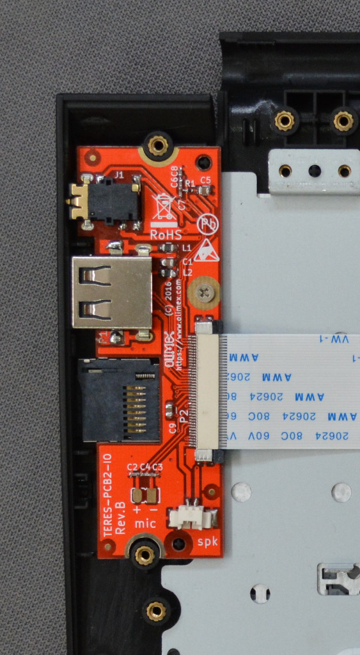
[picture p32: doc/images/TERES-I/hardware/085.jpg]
TERES-PCB2-IO 3


Repeat the same with the **TERES-PCB1-A64**.
**TERES-PCB2-IO** and **TERES-PCB1-A64** are now connected together:

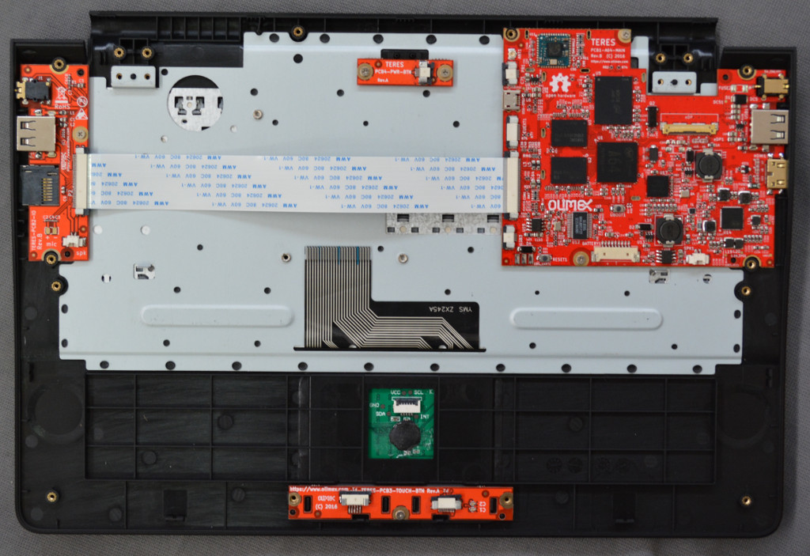
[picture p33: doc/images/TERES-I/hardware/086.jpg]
TERES-PCB2-IO 4


Do the same for **TERES-PCB4-Btn** and **TERES-PCB1-A64**.
Use the small flat cable **TERES-028-FPC-Pwr-Main**.
These connectors are similar to the previous ones.
You should again disengage the lock (pull the dark plastic up), then insert the flat cable with the contacts pointing UP between the white and dark plastic then push the dark plastic back.
Here is the flat cable connected to both connectors:

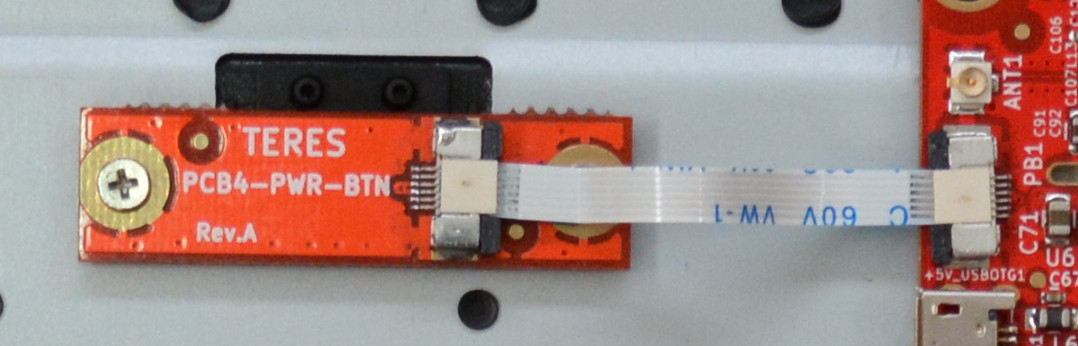
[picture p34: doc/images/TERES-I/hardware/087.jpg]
TERES-PCB4-Btn


The next step is to connect the touch panel **TERES-023-Touch** to the board with touch buttons **TERES-PCB3-TOUCH**.
Use the flat cable **TERES-029-FPC-Touch-Btn**.
Note that these connectors are different; the touch panel connector has a hinge and the dark plastic gets opened upside as on this picture:

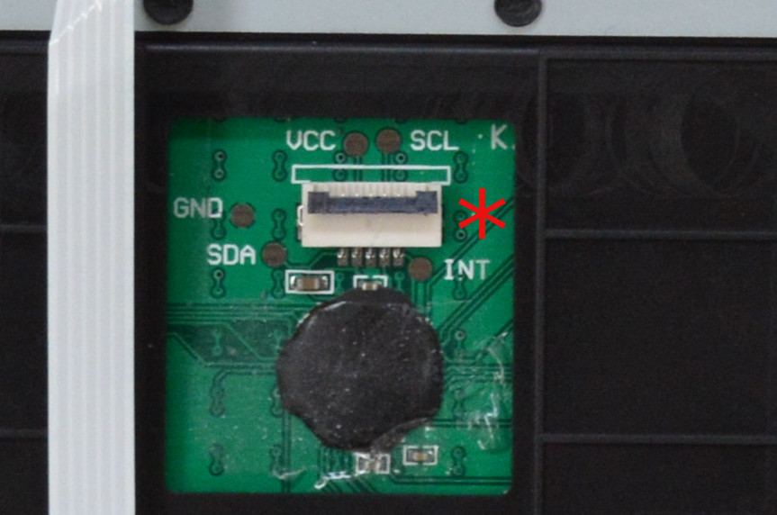
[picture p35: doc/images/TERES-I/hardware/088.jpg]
TERES-023-Touch 1


The flat cable is also inserted with the contacts pointing down and blue back up:

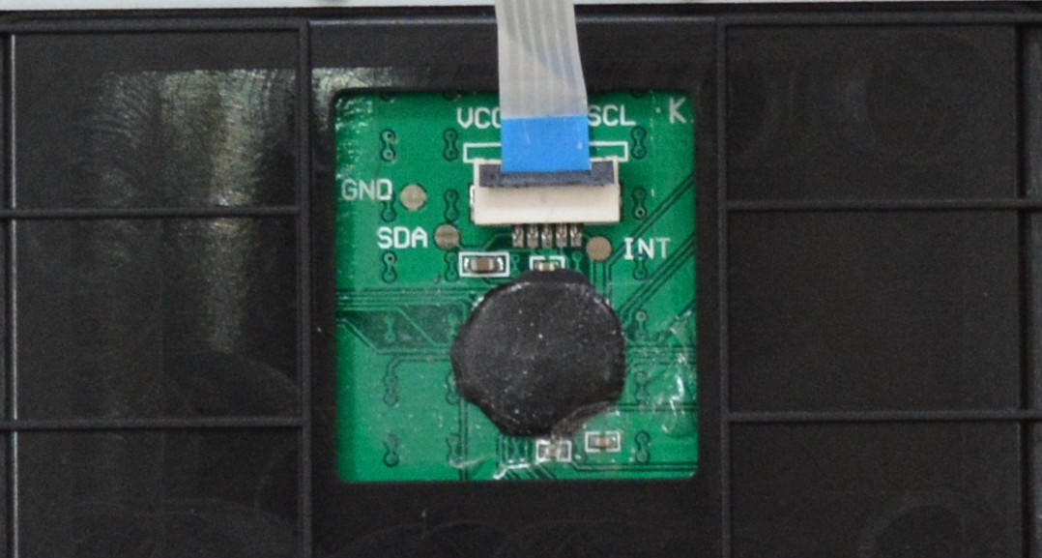
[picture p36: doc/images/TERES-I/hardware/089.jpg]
TERES-023-Touch 2


The connector on **TERES-PCB3-TOUCH** is also different so the cable is inserted below the dark plastic again with blue back pointing up:

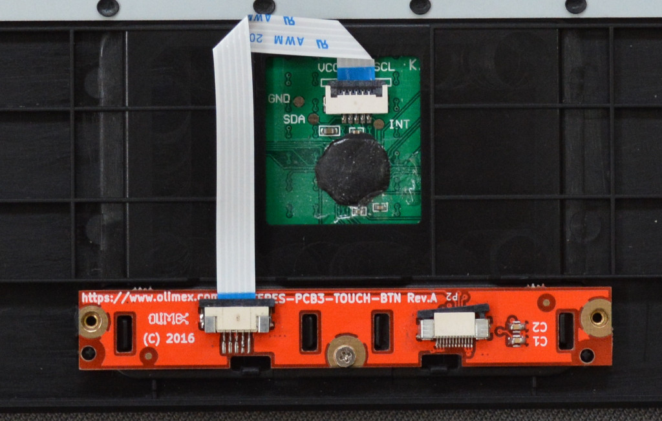
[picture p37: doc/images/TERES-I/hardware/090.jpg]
TERES-023-Touch 3


You have to bend the cable twice.
Do not bend at a very sharp angle and don't bend it too hard, or else it might get damaged!

The next step is to attach the **TERES-PCB5-KEYBOARD** to the keyboard flat cable as shown on the picture below.
Note that the cable goes under the black sliding plastic of the connector:

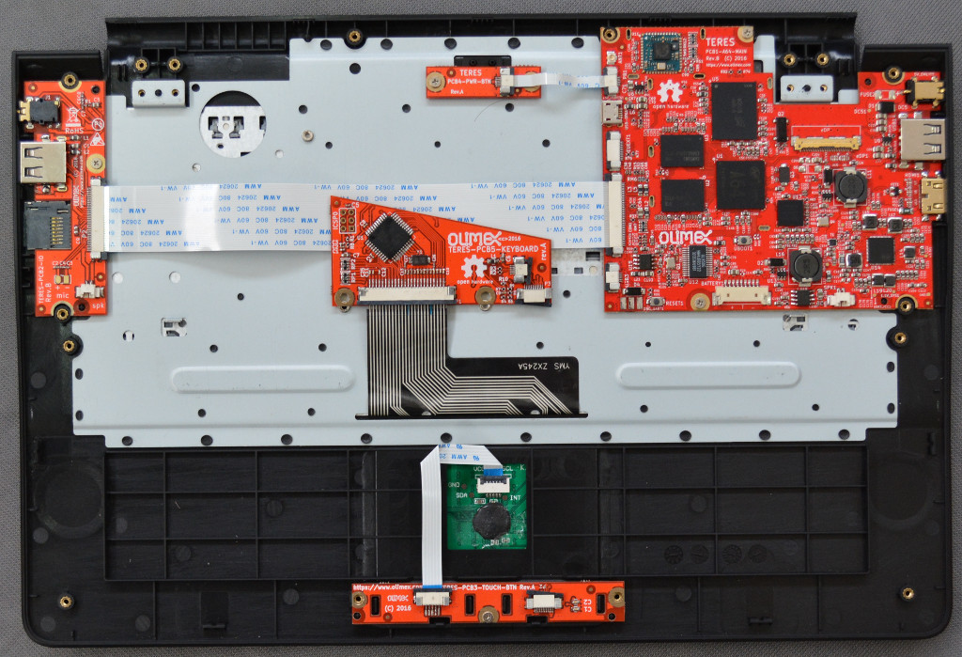
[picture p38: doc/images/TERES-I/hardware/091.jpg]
TERES-PCB5-KEYBOARD 1


Do not assemble the keyboard PCB to the plastic base at this time.

The next step is to connect **TERES-PCB5-KEYBOARD** with **TERES-PCB3-TOUCH**.
Use the **TERES-031-FPC-Kbd-Btn** flat cable for this purpose.
The cable is inserted with contacts up above the black plastic of the connector, in the same way as the power button and main board cables:

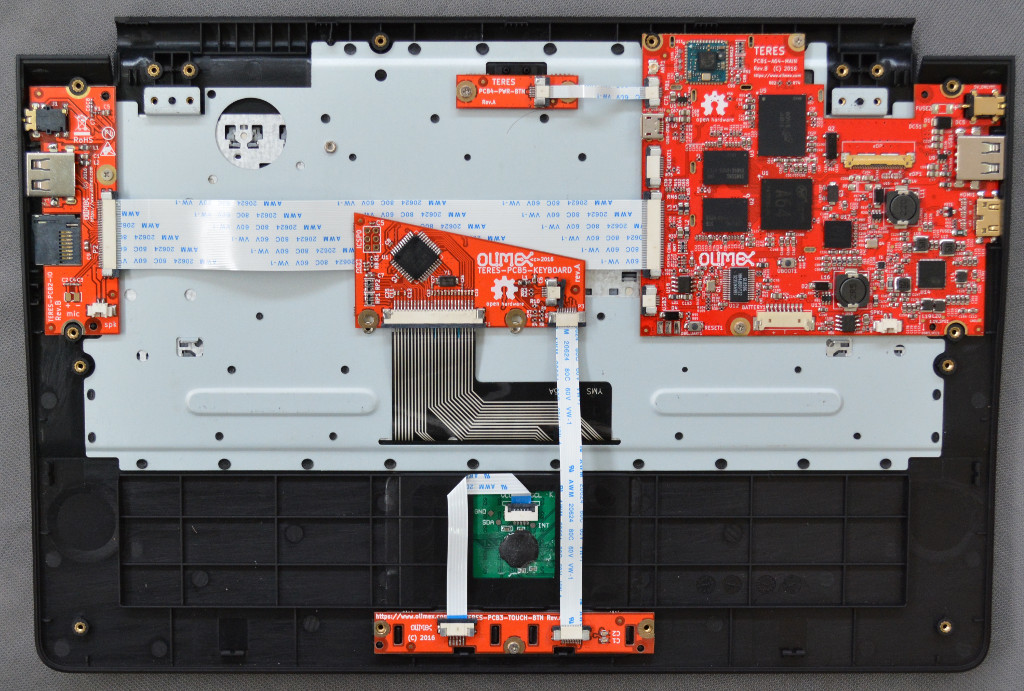
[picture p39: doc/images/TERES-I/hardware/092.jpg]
TERES-PCB5-KEYBOARD 2


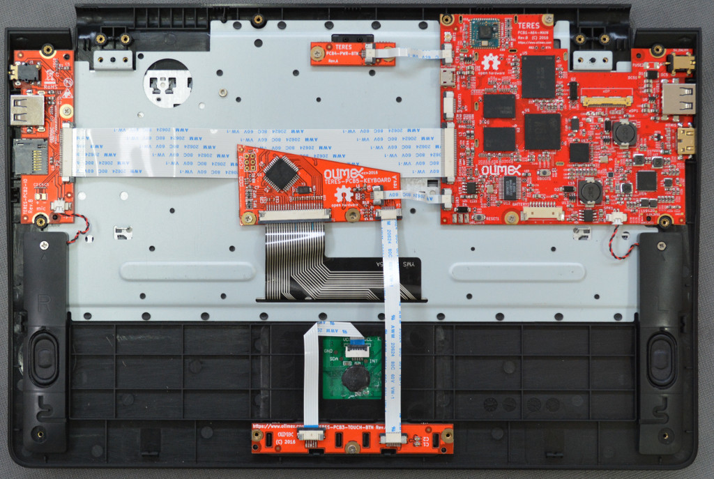
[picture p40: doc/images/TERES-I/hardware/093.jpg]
TERES-PCB5-KEYBOARD 3


Next connect **TERES-PCB5-KEYBOARD** with **TERES-PCB1-A64** and using one **M2 x 3** screw attach **TERES-PCB5-KEYBOARD** to the plastic body.
Note that only the left screw is placed.
The right screw will be installed later when attaching the bottom plastic.

## Speakers

The final assembly step is to attach the left and right speakers.
Look at the bottom side you will notice that **right** speaker is assembled at the **left** hand side, and the **left** speaker at the **right** hand side.

For this purpose use **M2 x 4** screws and only screw in the upper one.
The speaker connectors should be inserted in **TERES-PCB2-IO** and **TERES-PCB1-A64** boards.

## Body Panels

Now continue with LCD frame assembly using the **TERES-008-LCD-Back** as base:

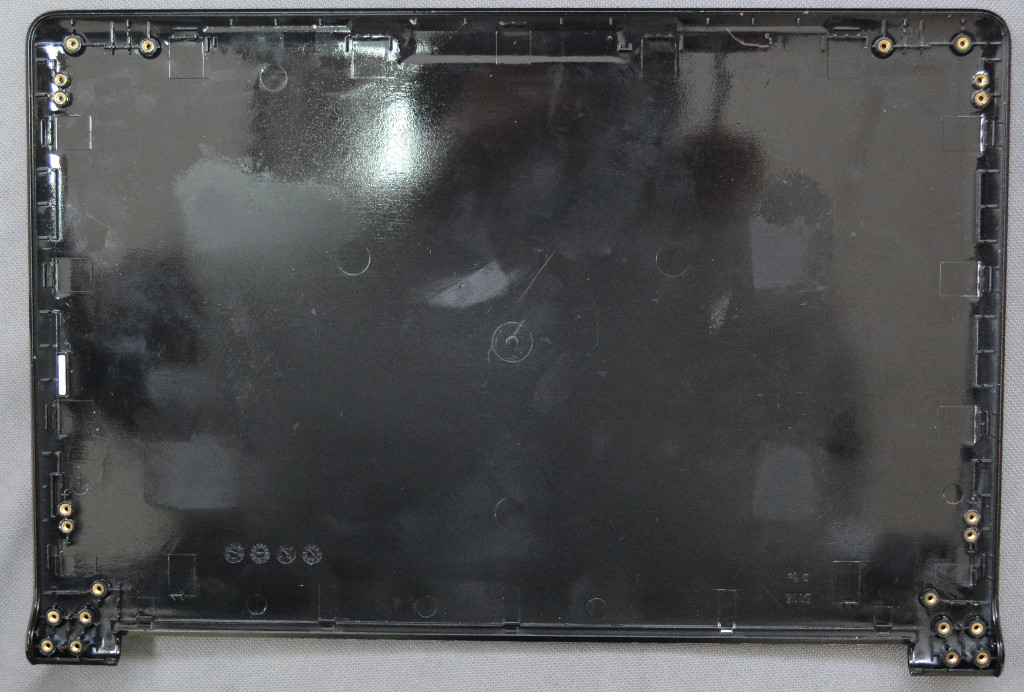
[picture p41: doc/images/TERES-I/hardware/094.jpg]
TERES-008-LCD-Back 1


First attach the metal hinges to the **TERES-016-Hinge-Set** using 8 pcs M2 x 4 screws:

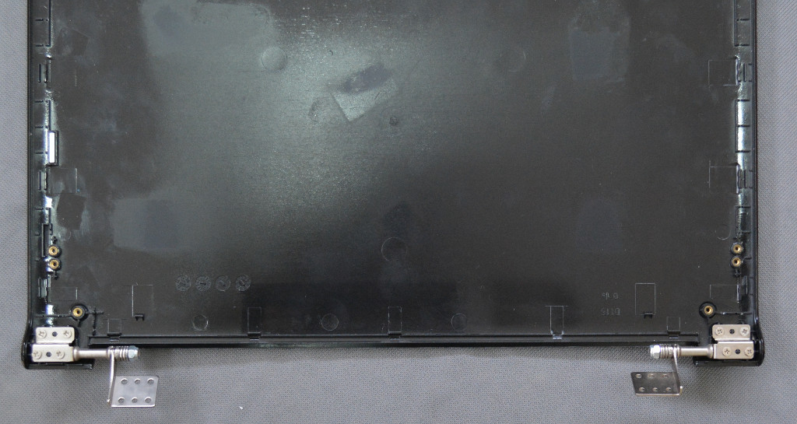
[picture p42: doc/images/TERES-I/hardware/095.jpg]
TERES-008-LCD-Back 2


Next attach **TERES-026-LCD-cable** to the **TERES-015-LCD** 11.6" panel ([datasheet](../datasheets/TERES-015-LCD11.6/N116BGE-EA2.pdf)):

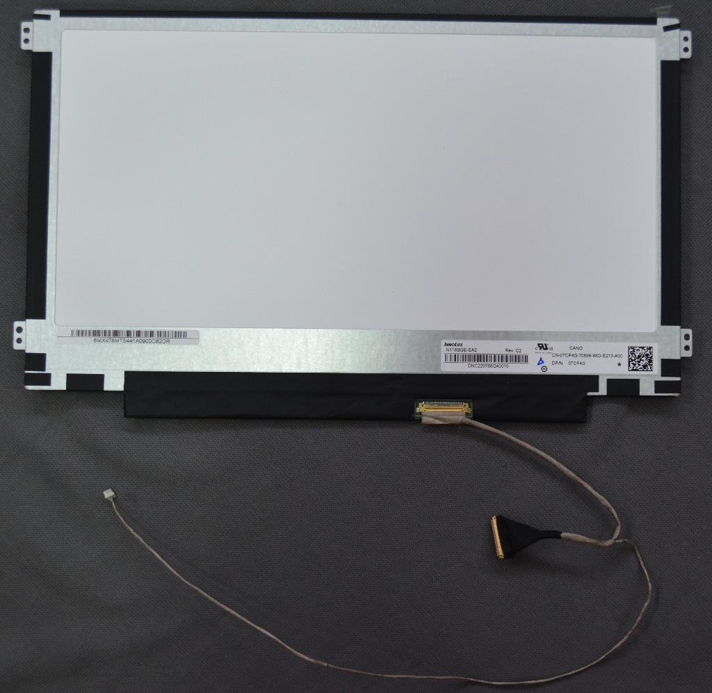
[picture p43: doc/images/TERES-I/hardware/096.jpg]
TERES-008-LCD-Back 3


With **M2 x 1.5** screws assemble the LCD to the plastic.
Note that only 4 screws are used!

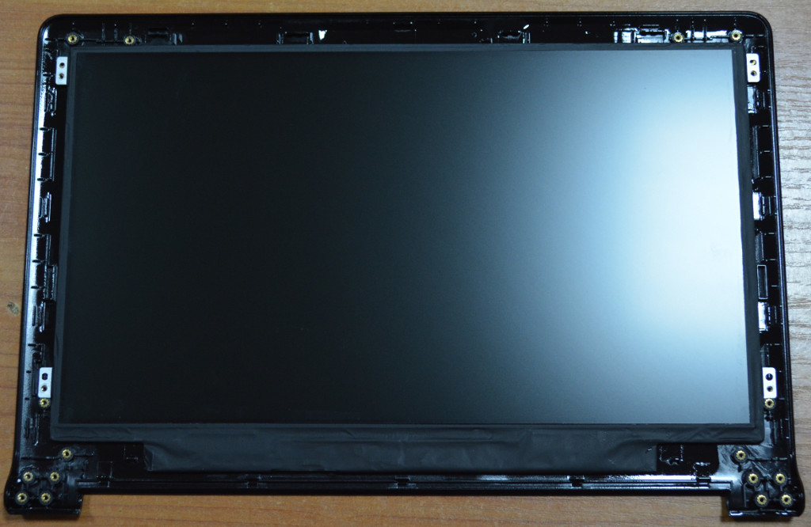
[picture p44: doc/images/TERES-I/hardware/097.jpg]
TERES-008-LCD-Back 4
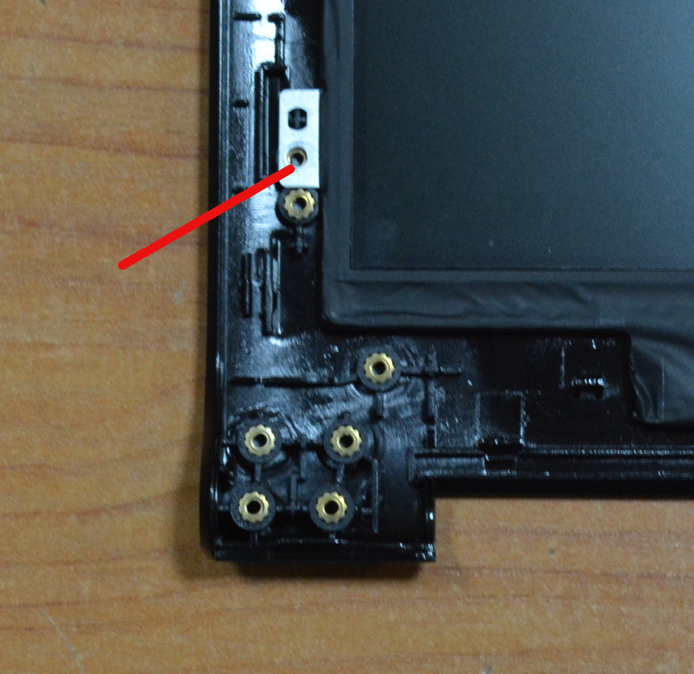
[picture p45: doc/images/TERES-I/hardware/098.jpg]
TERES-008-LCD-Back 5
  TERES-008-LCD-Back 6

## Camera

Connect the **TERES-019-Camera** to the four pin connector of the **TERES-026-LCD-cable**.
There are two holes in the camera board which attach to two pins on the plastic body.

TERES-019-Camera 1

TERES-019-Camera 2

## WiFi

On the other side attach **TERES-025-WiFi-Antenna** with double-sided adhesive tape to the plastic body:

TERES-025-WiFi-Antenna

## More Cabling

Follow the wiring shown on the picture below for the correct path of the LCD and WiFi cables.
Pay attention on how the cables go around the plastic locks and hinges!
The LCD cable wiring is probably most difficult part of the whole assembly and it is **incredibly important** to keep **EXACTLY** the same layout else the cover will **NOT** snap together properly later.

TERES-008-LCD-Back 3

## Magnet

The **018-Magnet** is placed in special place on the left hand of the LCD:

018-Magnet

Now place the panel.
If you did the wiring correctly, the panel will snap tightly.
You will have something like this:

TERES-008-LCD-Back 4

If the panel doesn't snap properly and you have to remove the cover to re-do the wiring, please, be patient else the plastic locks can break.
You can use a credit card or other similar card as a lever to separate the bottom and top parts of the display.

Then fix the upper corners with **M2 x 3** mm screws like this:

TERES-008-LCD-Back 5

Now place the **TERES-020-Camera-Lens** above the camera sensor and rubber mats over the two screws:

TERES-008-LCD-Back 6

Now assemble the LCD part with the keyboard body.
Use 6 screws **M2 x 4** mm for this purpose:

TERES-008-LCD-Back 7

Note that there are four places on the hinges but only three get assembled with screws.
The fourth hole should be left empty; the extra screw will come from the bottom plastic body attachment.
The places where you have to put screws are stamped at the metal hinges with arrows.

Next connect the WiFi antenna cable and LCD cable to **TERES-PCB1-A64**:

WiFi/LCD

## Battery

The next step is to attach four double adhesive mats that would hold the LiPo battery in place:

Battery 1

Attach the battery and plug the battery connector to the PCB1.
Mind the orientation of the cable and polarity!
Red cables should go to the left side.

Battery 2

## Final Steps

Next put the **TERES-021-Dust-Protectors** at the openings of the bottom plastic **TERES-005-Bottom**:

TERES-005-Bottom 1

In the next image, you see the dust covers placed over the two openings:

TERES-005-Bottom 2

Next assemble the bottom plastic using 12 **M2 x 5** screws:

TERES-005-Bottom 3

The final step is to attach the rubber mats to the four locations at the bottom:

TERES-005-Bottom 4

The assembly is now complete.
Now press the power button and the laptop will boot:

TERES-Assembled

Congratulations! You assembled your TERES-I laptop!

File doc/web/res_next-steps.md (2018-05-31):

# What's next?

This product is a [work-in-progress](evaluation-board-notice.md).

## More capability

We are designing new main boards with newer and more powerful processors with more RAM and NAND flash (the trade-off would be a shorter battery life, of course).

TERES-I comes with 1376x768 LCD configuration.
Future main boards aim at 1920x1080 pixels.

## More extensibility

A set of expansion boards are being considered that can turn the TERES-I into a "portable lab".
This may include capabilities such as a digital storage oscilloscope and logic analyzer.

Different main board configurations: the first iteration comes with ARM64 and x86 support.
The MIPS architecture is coming soon with other architectures to follow.
The concept is to make templates which others may use to customize so other SOCs may be used for a main board.

## More adoption

Being OSHW, community members are welcome to release their own ideas, software and hardware projects and designs compatible with the TERES-I.
We would love for you to help [contribute](../../CONTRIBUTING.md)!

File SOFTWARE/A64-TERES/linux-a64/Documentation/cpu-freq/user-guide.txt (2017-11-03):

     CPU frequency and voltage scaling code in the Linux(TM) kernel

		         L i n u x    C P U F r e q

			     U S E R   G U I D E

		    Dominik Brodowski  <linux@brodo.de>

   Clock scaling allows you to change the clock speed of the CPUs on the
    fly. This is a nice method to save battery power, because the lower
            the clock speed, the less power the CPU consumes.

Contents:
---------
1. Supported Architectures and Processors
1.1 ARM
1.2 x86
1.3 sparc64
1.4 ppc
1.5 SuperH
1.6 Blackfin

2. "Policy" / "Governor"?
2.1 Policy
2.2 Governor

3. How to change the CPU cpufreq policy and/or speed
3.1 Preferred interface: sysfs

1. Supported Architectures and Processors
=========================================

1.1 ARM
-------

The following ARM processors are supported by cpufreq:

ARM Integrator
ARM-SA1100
ARM-SA1110
Intel PXA

1.2 x86
-------

The following processors for the x86 architecture are supported by cpufreq:

AMD Elan - SC400, SC410
AMD mobile K6-2+
AMD mobile K6-3+
AMD mobile Duron
AMD mobile Athlon
AMD Opteron
AMD Athlon 64
Cyrix Media GXm
Intel mobile PIII and Intel mobile PIII-M on certain chipsets
Intel Pentium 4, Intel Xeon
Intel Pentium M (Centrino)
National Semiconductors Geode GX
Transmeta Crusoe
Transmeta Efficeon
VIA Cyrix 3 / C3
various processors on some ACPI 2.0-compatible systems [*]

[*] Only if "ACPI Processor Performance States" are available
to the ACPI<->BIOS interface.

1.3 sparc64
-----------

The following processors for the sparc64 architecture are supported by
cpufreq:

UltraSPARC-III

1.4 ppc
-------

Several "PowerBook" and "iBook2" notebooks are supported.

1.5 SuperH
----------

All SuperH processors supporting rate rounding through the clock
framework are supported by cpufreq.

1.6 Blackfin
------------

The following Blackfin processors are supported by cpufreq:

BF522, BF523, BF524, BF525, BF526, BF527, Rev 0.1 or higher
BF531, BF532, BF533, Rev 0.3 or higher
BF534, BF536, BF537, Rev 0.2 or higher
BF561, Rev 0.3 or higher
BF542, BF544, BF547, BF548, BF549, Rev 0.1 or higher

2. "Policy" / "Governor" ?
==========================

Some CPU frequency scaling-capable processor switch between various
frequencies and operating voltages "on the fly" without any kernel or
user involvement. This guarantees very fast switching to a frequency
which is high enough to serve the user's needs, but low enough to save
power.

2.1 Policy
----------

On these systems, all you can do is select the lower and upper
frequency limit as well as whether you want more aggressive
power-saving or more instantly available processing power.

2.2 Governor
------------

On all other cpufreq implementations, these boundaries still need to
be set. Then, a "governor" must be selected. Such a "governor" decides
what speed the processor shall run within the boundaries. One such
"governor" is the "userspace" governor. This one allows the user - or
a yet-to-implement userspace program - to decide what specific speed
the processor shall run at.

3. How to change the CPU cpufreq policy and/or speed
====================================================

3.1 Preferred Interface: sysfs
------------------------------

The preferred interface is located in the sysfs filesystem. If you
mounted it at /sys, the cpufreq interface is located in a subdirectory
"cpufreq" within the cpu-device directory
(e.g. /sys/devices/system/cpu/cpu0/cpufreq/ for the first CPU).

cpuinfo_min_freq :		this file shows the minimum operating
				frequency the processor can run at(in kHz) 
cpuinfo_max_freq :		this file shows the maximum operating
				frequency the processor can run at(in kHz) 
cpuinfo_transition_latency	The time it takes on this CPU to
				switch between two frequencies in nano
				seconds. If unknown or known to be
				that high that the driver does not
				work with the ondemand governor, -1
				(CPUFREQ_ETERNAL) will be returned.
				Using this information can be useful
				to choose an appropriate polling
				frequency for a kernel governor or
				userspace daemon. Make sure to not
				switch the frequency too often
				resulting in performance loss.
scaling_driver :		this file shows what cpufreq driver is
				used to set the frequency on this CPU

scaling_available_governors :	this file shows the CPUfreq governors
				available in this kernel. You can see the
				currently activated governor in

scaling_governor,		and by "echoing" the name of another
				governor you can change it. Please note
				that some governors won't load - they only
				work on some specific architectures or
				processors.

cpuinfo_cur_freq :		Current frequency of the CPU as obtained from
				the hardware, in KHz. This is the frequency
				the CPU actually runs at.

scaling_available_frequencies : List of available frequencies, in KHz.

scaling_min_freq and
scaling_max_freq		show the current "policy limits" (in
				kHz). By echoing new values into these
				files, you can change these limits.
				NOTE: when setting a policy you need to
				first set scaling_max_freq, then
				scaling_min_freq.

affected_cpus :			List of Online CPUs that require software
				coordination of frequency.

related_cpus :			List of Online + Offline CPUs that need software
				coordination of frequency.

scaling_driver :		Hardware driver for cpufreq.

scaling_cur_freq :		Current frequency of the CPU as determined by
				the governor and cpufreq core, in KHz. This is
				the frequency the kernel thinks the CPU runs
				at.

bios_limit :			If the BIOS tells the OS to limit a CPU to
				lower frequencies, the user can read out the
				maximum available frequency from this file.
				This typically can happen through (often not
				intended) BIOS settings, restrictions
				triggered through a service processor or other
				BIOS/HW based implementations.
				This does not cover thermal ACPI limitations
				which can be detected through the generic
				thermal driver.

If you have selected the "userspace" governor which allows you to
set the CPU operating frequency to a specific value, you can read out
the current frequency in

scaling_setspeed.		By "echoing" a new frequency into this
				you can change the speed of the CPU,
				but only within the limits of
				scaling_min_freq and scaling_max_freq.

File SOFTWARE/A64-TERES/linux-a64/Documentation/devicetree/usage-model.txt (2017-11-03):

Linux and the Device Tree
-------------------------
The Linux usage model for device tree data

Author: Grant Likely <grant.likely@secretlab.ca>

This article describes how Linux uses the device tree.  An overview of
the device tree data format can be found on the device tree usage page
at devicetree.org[1].

[1] http://devicetree.org/Device_Tree_Usage

The "Open Firmware Device Tree", or simply Device Tree (DT), is a data
structure and language for describing hardware.  More specifically, it
is a description of hardware that is readable by an operating system
so that the operating system doesn't need to hard code details of the
machine.

Structurally, the DT is a tree, or acyclic graph with named nodes, and
nodes may have an arbitrary number of named properties encapsulating
arbitrary data.  A mechanism also exists to create arbitrary
links from one node to another outside of the natural tree structure.

Conceptually, a common set of usage conventions, called 'bindings',
is defined for how data should appear in the tree to describe typical
hardware characteristics including data busses, interrupt lines, GPIO
connections, and peripheral devices.

As much as possible, hardware is described using existing bindings to
maximize use of existing support code, but since property and node
names are simply text strings, it is easy to extend existing bindings
or create new ones by defining new nodes and properties.  Be wary,
however, of creating a new binding without first doing some homework
about what already exists.  There are currently two different,
incompatible, bindings for i2c busses that came about because the new
binding was created without first investigating how i2c devices were
already being enumerated in existing systems.

1. History
----------
The DT was originally created by Open Firmware as part of the
communication method for passing data from Open Firmware to a client
program (like to an operating system).  An operating system used the
Device Tree to discover the topology of the hardware at runtime, and
thereby support a majority of available hardware without hard coded
information (assuming drivers were available for all devices).

Since Open Firmware is commonly used on PowerPC and SPARC platforms,
the Linux support for those architectures has for a long time used the
Device Tree.

In 2005, when PowerPC Linux began a major cleanup and to merge 32-bit
and 64-bit support, the decision was made to require DT support on all
powerpc platforms, regardless of whether or not they used Open
Firmware.  To do this, a DT representation called the Flattened Device
Tree (FDT) was created which could be passed to the kernel as a binary
blob without requiring a real Open Firmware implementation.  U-Boot,
kexec, and other bootloaders were modified to support both passing a
Device Tree Binary (dtb) and to modify a dtb at boot time.  DT was
also added to the PowerPC boot wrapper (arch/powerpc/boot/*) so that
a dtb could be wrapped up with the kernel image to support booting
existing non-DT aware firmware.

Some time later, FDT infrastructure was generalized to be usable by
all architectures.  At the time of this writing, 6 mainlined
architectures (arm, microblaze, mips, powerpc, sparc, and x86) and 1
out of mainline (nios) have some level of DT support.

2. Data Model
-------------
If you haven't already read the Device Tree Usage[1] page,
then go read it now.  It's okay, I'll wait....

2.1 High Level View
-------------------
The most important thing to understand is that the DT is simply a data
structure that describes the hardware.  There is nothing magical about
it, and it doesn't magically make all hardware configuration problems
go away.  What it does do is provide a language for decoupling the
hardware configuration from the board and device driver support in the
Linux kernel (or any other operating system for that matter).  Using
it allows board and device support to become data driven; to make
setup decisions based on data passed into the kernel instead of on
per-machine hard coded selections.

Ideally, data driven platform setup should result in less code
duplication and make it easier to support a wide range of hardware
with a single kernel image.

Linux uses DT data for three major purposes:
1) platform identification,
2) runtime configuration, and
3) device population.

2.2 Platform Identification
---------------------------
First and foremost, the kernel will use data in the DT to identify the
specific machine.  In a perfect world, the specific platform shouldn't
matter to the kernel because all platform details would be described
perfectly by the device tree in a consistent and reliable manner.
Hardware is not perfect though, and so the kernel must identify the
machine during early boot so that it has the opportunity to run
machine-specific fixups.

In the majority of cases, the machine identity is irrelevant, and the
kernel will instead select setup code based on the machine's core
CPU or SoC.  On ARM for example, setup_arch() in
arch/arm/kernel/setup.c will call setup_machine_fdt() in
arch/arm/kernel/devicetree.c which searches through the machine_desc
table and selects the machine_desc which best matches the device tree
data.  It determines the best match by looking at the 'compatible'
property in the root device tree node, and comparing it with the
dt_compat list in struct machine_desc.

The 'compatible' property contains a sorted list of strings starting
with the exact name of the machine, followed by an optional list of
boards it is compatible with sorted from most compatible to least.  For
example, the root compatible properties for the TI BeagleBoard and its
successor, the BeagleBoard xM board might look like:

	compatible = "ti,omap3-beagleboard", "ti,omap3450", "ti,omap3";
	compatible = "ti,omap3-beagleboard-xm", "ti,omap3450", "ti,omap3";

Where "ti,omap3-beagleboard-xm" specifies the exact model, it also
claims that it compatible with the OMAP 3450 SoC, and the omap3 family
of SoCs in general.  You'll notice that the list is sorted from most
specific (exact board) to least specific (SoC family).

Astute readers might point out that the Beagle xM could also claim
compatibility with the original Beagle board.  However, one should be
cautioned about doing so at the board level since there is typically a
high level of change from one board to another, even within the same
product line, and it is hard to nail down exactly what is meant when one
board claims to be compatible with another.  For the top level, it is
better to err on the side of caution and not claim one board is
compatible with another.  The notable exception would be when one
board is a carrier for another, such as a CPU module attached to a
carrier board.

One more note on compatible values.  Any string used in a compatible
property must be documented as to what it indicates.  Add
documentation for compatible strings in Documentation/devicetree/bindings.

Again on ARM, for each machine_desc, the kernel looks to see if
any of the dt_compat list entries appear in the compatible property.
If one does, then that machine_desc is a candidate for driving the
machine.  After searching the entire table of machine_descs,
setup_machine_fdt() returns the 'most compatible' machine_desc based
on which entry in the compatible property each machine_desc matches
against.  If no matching machine_desc is found, then it returns NULL.

The reasoning behind this scheme is the observation that in the majority
of cases, a single machine_desc can support a large number of boards
if they all use the same SoC, or same family of SoCs.  However,
invariably there will be some exceptions where a specific board will
require special setup code that is not useful in the generic case.
Special cases could be handled by explicitly checking for the
troublesome board(s) in generic setup code, but doing so very quickly
becomes ugly and/or unmaintainable if it is more than just a couple of
cases.

Instead, the compatible list allows a generic machine_desc to provide
support for a wide common set of boards by specifying "less
compatible" value in the dt_compat list.  In the example above,
generic board support can claim compatibility with "ti,omap3" or
"ti,omap3450".  If a bug was discovered on the original beagleboard
that required special workaround code during early boot, then a new
machine_desc could be added which implements the workarounds and only
matches on "ti,omap3-beagleboard".

PowerPC uses a slightly different scheme where it calls the .probe()
hook from each machine_desc, and the first one returning TRUE is used.
However, this approach does not take into account the priority of the
compatible list, and probably should be avoided for new architecture
support.

2.3 Runtime configuration
-------------------------
In most cases, a DT will be the sole method of communicating data from
firmware to the kernel, so also gets used to pass in runtime and
configuration data like the kernel parameters string and the location
of an initrd image.

Most of this data is contained in the /chosen node, and when booting
Linux it will look something like this:

	chosen {
		bootargs = "console=ttyS0,115200 loglevel=8";
		initrd-start = <0xc8000000>;
		initrd-end = <0xc8200000>;
	};

The bootargs property contains the kernel arguments, and the initrd-*
properties define the address and size of an initrd blob.  Note that
initrd-end is the first address after the initrd image, so this doesn't
match the usual semantic of struct resource.  The chosen node may also
optionally contain an arbitrary number of additional properties for
platform-specific configuration data.

During early boot, the architecture setup code calls of_scan_flat_dt()
several times with different helper callbacks to parse device tree
data before paging is setup.  The of_scan_flat_dt() code scans through
the device tree and uses the helpers to extract information required
during early boot.  Typically the early_init_dt_scan_chosen() helper
is used to parse the chosen node including kernel parameters,
early_init_dt_scan_root() to initialize the DT address space model,
and early_init_dt_scan_memory() to determine the size and
location of usable RAM.

On ARM, the function setup_machine_fdt() is responsible for early
scanning of the device tree after selecting the correct machine_desc
that supports the board.

2.4 Device population
---------------------
After the board has been identified, and after the early configuration data
has been parsed, then kernel initialization can proceed in the normal
way.  At some point in this process, unflatten_device_tree() is called
to convert the data into a more efficient runtime representation.
This is also when machine-specific setup hooks will get called, like
the machine_desc .init_early(), .init_irq() and .init_machine() hooks
on ARM.  The remainder of this section uses examples from the ARM
implementation, but all architectures will do pretty much the same
thing when using a DT.

As can be guessed by the names, .init_early() is used for any machine-
specific setup that needs to be executed early in the boot process,
and .init_irq() is used to set up interrupt handling.  Using a DT
doesn't materially change the behaviour of either of these functions.
If a DT is provided, then both .init_early() and .init_irq() are able
to call any of the DT query functions (of_* in include/linux/of*.h) to
get additional data about the platform.

The most interesting hook in the DT context is .init_machine() which
is primarily responsible for populating the Linux device model with
data about the platform.  Historically this has been implemented on
embedded platforms by defining a set of static clock structures,
platform_devices, and other data in the board support .c file, and
registering it en-masse in .init_machine().  When DT is used, then
instead of hard coding static devices for each platform, the list of
devices can be obtained by parsing the DT, and allocating device
structures dynamically.

The simplest case is when .init_machine() is only responsible for
registering a block of platform_devices.  A platform_device is a concept
used by Linux for memory or I/O mapped devices which cannot be detected
by hardware, and for 'composite' or 'virtual' devices (more on those
later).  While there is no 'platform device' terminology for the DT,
platform devices roughly correspond to device nodes at the root of the
tree and children of simple memory mapped bus nodes.

About now is a good time to lay out an example.  Here is part of the
device tree for the NVIDIA Tegra board.

/{
	compatible = "nvidia,harmony", "nvidia,tegra20";
	#address-cells = <1>;
	#size-cells = <1>;
	interrupt-parent = <&intc>;

	chosen { };
	aliases { };

	memory {
		device_type = "memory";
		reg = <0x00000000 0x40000000>;
	};

	soc {
		compatible = "nvidia,tegra20-soc", "simple-bus";
		#address-cells = <1>;
		#size-cells = <1>;
		ranges;

		intc: interrupt-controller@50041000 {
			compatible = "nvidia,tegra20-gic";
			interrupt-controller;
			#interrupt-cells = <1>;
			reg = <0x50041000 0x1000>, < 0x50040100 0x0100 >;
		};

		serial@70006300 {
			compatible = "nvidia,tegra20-uart";
			reg = <0x70006300 0x100>;
			interrupts = <122>;
		};

		i2s1: i2s@70002800 {
			compatible = "nvidia,tegra20-i2s";
			reg = <0x70002800 0x100>;
			interrupts = <77>;
			codec = <&wm8903>;
		};

		i2c@7000c000 {
			compatible = "nvidia,tegra20-i2c";
			#address-cells = <1>;
			#size-cells = <0>;
			reg = <0x7000c000 0x100>;
			interrupts = <70>;

			wm8903: codec@1a {
				compatible = "wlf,wm8903";
				reg = <0x1a>;
				interrupts = <347>;
			};
		};
	};

	sound {
		compatible = "nvidia,harmony-sound";
		i2s-controller = <&i2s1>;
		i2s-codec = <&wm8903>;
	};
};

At .init_machine() time, Tegra board support code will need to look at
this DT and decide which nodes to create platform_devices for.
However, looking at the tree, it is not immediately obvious what kind
of device each node represents, or even if a node represents a device
at all.  The /chosen, /aliases, and /memory nodes are informational
nodes that don't describe devices (although arguably memory could be
considered a device).  The children of the /soc node are memory mapped
devices, but the codec@1a is an i2c device, and the sound node
represents not a device, but rather how other devices are connected
together to create the audio subsystem.  I know what each device is
because I'm familiar with the board design, but how does the kernel
know what to do with each node?

The trick is that the kernel starts at the root of the tree and looks
for nodes that have a 'compatible' property.  First, it is generally
assumed that any node with a 'compatible' property represents a device
of some kind, and second, it can be assumed that any node at the root
of the tree is either directly attached to the processor bus, or is a
miscellaneous system device that cannot be described any other way.
For each of these nodes, Linux allocates and registers a
platform_device, which in turn may get bound to a platform_driver.

Why is using a platform_device for these nodes a safe assumption?
Well, for the way that Linux models devices, just about all bus_types
assume that its devices are children of a bus controller.  For
example, each i2c_client is a child of an i2c_master.  Each spi_device
is a child of an SPI bus.  Similarly for USB, PCI, MDIO, etc.  The
same hierarchy is also found in the DT, where I2C device nodes only
ever appear as children of an I2C bus node.  Ditto for SPI, MDIO, USB,
etc.  The only devices which do not require a specific type of parent
device are platform_devices (and amba_devices, but more on that
later), which will happily live at the base of the Linux /sys/devices
tree.  Therefore, if a DT node is at the root of the tree, then it
really probably is best registered as a platform_device.

Linux board support code calls of_platform_populate(NULL, NULL, NULL, NULL)
to kick off discovery of devices at the root of the tree.  The
parameters are all NULL because when starting from the root of the
tree, there is no need to provide a starting node (the first NULL), a
parent struct device (the last NULL), and we're not using a match
table (yet).  For a board that only needs to register devices,
.init_machine() can be completely empty except for the
of_platform_populate() call.

In the Tegra example, this accounts for the /soc and /sound nodes, but
what about the children of the SoC node?  Shouldn't they be registered
as platform devices too?  For Linux DT support, the generic behaviour
is for child devices to be registered by the parent's device driver at
driver .probe() time.  So, an i2c bus device driver will register a
i2c_client for each child node, an SPI bus driver will register
its spi_device children, and similarly for other bus_types.
According to that model, a driver could be written that binds to the
SoC node and simply registers platform_devices for each of its
children.  The board support code would allocate and register an SoC
device, a (theoretical) SoC device driver could bind to the SoC device,
and register platform_devices for /soc/interrupt-controller, /soc/serial,
/soc/i2s, and /soc/i2c in its .probe() hook.  Easy, right?

Actually, it turns out that registering children of some
platform_devices as more platform_devices is a common pattern, and the
device tree support code reflects that and makes the above example
simpler.  The second argument to of_platform_populate() is an
of_device_id table, and any node that matches an entry in that table
will also get its child nodes registered.  In the tegra case, the code
can look something like this:

static void __init harmony_init_machine(void)
{
	/* ... */
	of_platform_populate(NULL, of_default_bus_match_table, NULL, NULL);
}

"simple-bus" is defined in the ePAPR 1.0 specification as a property
meaning a simple memory mapped bus, so the of_platform_populate() code
could be written to just assume simple-bus compatible nodes will
always be traversed.  However, we pass it in as an argument so that
board support code can always override the default behaviour.

[Need to add discussion of adding i2c/spi/etc child devices]

Appendix A: AMBA devices
------------------------

ARM Primecells are a certain kind of device attached to the ARM AMBA
bus which include some support for hardware detection and power
management.  In Linux, struct amba_device and the amba_bus_type is
used to represent Primecell devices.  However, the fiddly bit is that
not all devices on an AMBA bus are Primecells, and for Linux it is
typical for both amba_device and platform_device instances to be
siblings of the same bus segment.

When using the DT, this creates problems for of_platform_populate()
because it must decide whether to register each node as either a
platform_device or an amba_device.  This unfortunately complicates the
device creation model a little bit, but the solution turns out not to
be too invasive.  If a node is compatible with "arm,amba-primecell", then
of_platform_populate() will register it as an amba_device instead of a
platform_device.

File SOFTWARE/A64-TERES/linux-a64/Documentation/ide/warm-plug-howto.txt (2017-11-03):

IDE warm-plug HOWTO
===================

To warm-plug devices on a port 'idex':

# echo -n "1" > /sys/class/ide_port/idex/delete_devices

unplug old device(s) and plug new device(s)

# echo -n "1" > /sys/class/ide_port/idex/scan

done

NOTE: please make sure that partitions are unmounted and that there are
no other active references to devices before doing "delete_devices" step,
also do not attempt "scan" step on devices currently in use -- otherwise
results may be unpredictable and lead to data loss if you're unlucky

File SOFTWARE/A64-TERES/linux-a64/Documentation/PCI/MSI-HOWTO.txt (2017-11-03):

		The MSI Driver Guide HOWTO
	Tom L Nguyen tom.l.nguyen@intel.com
			10/03/2003
	Revised Feb 12, 2004 by Martine Silbermann
		email: Martine.Silbermann@hp.com
	Revised Jun 25, 2004 by Tom L Nguyen
	Revised Jul  9, 2008 by Matthew Wilcox <willy@linux.intel.com>
		Copyright 2003, 2008 Intel Corporation

1. About this guide

This guide describes the basics of Message Signaled Interrupts (MSIs),
the advantages of using MSI over traditional interrupt mechanisms, how
to change your driver to use MSI or MSI-X and some basic diagnostics to
try if a device doesn't support MSIs.

2. What are MSIs?

A Message Signaled Interrupt is a write from the device to a special
address which causes an interrupt to be received by the CPU.

The MSI capability was first specified in PCI 2.2 and was later enhanced
in PCI 3.0 to allow each interrupt to be masked individually.  The MSI-X
capability was also introduced with PCI 3.0.  It supports more interrupts
per device than MSI and allows interrupts to be independently configured.

Devices may support both MSI and MSI-X, but only one can be enabled at
a time.

3. Why use MSIs?

There are three reasons why using MSIs can give an advantage over
traditional pin-based interrupts.

Pin-based PCI interrupts are often shared amongst several devices.
To support this, the kernel must call each interrupt handler associated
with an interrupt, which leads to reduced performance for the system as
a whole.  MSIs are never shared, so this problem cannot arise.

When a device writes data to memory, then raises a pin-based interrupt,
it is possible that the interrupt may arrive before all the data has
arrived in memory (this becomes more likely with devices behind PCI-PCI
bridges).  In order to ensure that all the data has arrived in memory,
the interrupt handler must read a register on the device which raised
the interrupt.  PCI transaction ordering rules require that all the data
arrive in memory before the value may be returned from the register.
Using MSIs avoids this problem as the interrupt-generating write cannot
pass the data writes, so by the time the interrupt is raised, the driver
knows that all the data has arrived in memory.

PCI devices can only support a single pin-based interrupt per function.
Often drivers have to query the device to find out what event has
occurred, slowing down interrupt handling for the common case.  With
MSIs, a device can support more interrupts, allowing each interrupt
to be specialised to a different purpose.  One possible design gives
infrequent conditions (such as errors) their own interrupt which allows
the driver to handle the normal interrupt handling path more efficiently.
Other possible designs include giving one interrupt to each packet queue
in a network card or each port in a storage controller.

4. How to use MSIs

PCI devices are initialised to use pin-based interrupts.  The device
driver has to set up the device to use MSI or MSI-X.  Not all machines
support MSIs correctly, and for those machines, the APIs described below
will simply fail and the device will continue to use pin-based interrupts.

4.1 Include kernel support for MSIs

To support MSI or MSI-X, the kernel must be built with the CONFIG_PCI_MSI
option enabled.  This option is only available on some architectures,
and it may depend on some other options also being set.  For example,
on x86, you must also enable X86_UP_APIC or SMP in order to see the
CONFIG_PCI_MSI option.

4.2 Using MSI

Most of the hard work is done for the driver in the PCI layer.  It simply
has to request that the PCI layer set up the MSI capability for this
device.

4.2.1 pci_enable_msi

int pci_enable_msi(struct pci_dev *dev)

A successful call allocates ONE interrupt to the device, regardless
of how many MSIs the device supports.  The device is switched from
pin-based interrupt mode to MSI mode.  The dev->irq number is changed
to a new number which represents the message signaled interrupt;
consequently, this function should be called before the driver calls
request_irq(), because an MSI is delivered via a vector that is
different from the vector of a pin-based interrupt.

4.2.2 pci_enable_msi_block

int pci_enable_msi_block(struct pci_dev *dev, int count)

This variation on the above call allows a device driver to request multiple
MSIs.  The MSI specification only allows interrupts to be allocated in
powers of two, up to a maximum of 2^5 (32).

If this function returns 0, it has succeeded in allocating at least as many
interrupts as the driver requested (it may have allocated more in order
to satisfy the power-of-two requirement).  In this case, the function
enables MSI on this device and updates dev->irq to be the lowest of
the new interrupts assigned to it.  The other interrupts assigned to
the device are in the range dev->irq to dev->irq + count - 1.

If this function returns a negative number, it indicates an error and
the driver should not attempt to request any more MSI interrupts for
this device.  If this function returns a positive number, it is
less than 'count' and indicates the number of interrupts that could have
been allocated.  In neither case is the irq value updated or the device
switched into MSI mode.

The device driver must decide what action to take if
pci_enable_msi_block() returns a value less than the number requested.
For instance, the driver could still make use of fewer interrupts;
in this case the driver should call pci_enable_msi_block()
again.  Note that it is not guaranteed to succeed, even when the
'count' has been reduced to the value returned from a previous call to
pci_enable_msi_block().  This is because there are multiple constraints
on the number of vectors that can be allocated; pci_enable_msi_block()
returns as soon as it finds any constraint that doesn't allow the
call to succeed.

4.2.3 pci_enable_msi_block_auto

int pci_enable_msi_block_auto(struct pci_dev *dev, unsigned int *count)

This variation on pci_enable_msi() call allows a device driver to request
the maximum possible number of MSIs.  The MSI specification only allows
interrupts to be allocated in powers of two, up to a maximum of 2^5 (32).

If this function returns a positive number, it indicates that it has
succeeded and the returned value is the number of allocated interrupts. In
this case, the function enables MSI on this device and updates dev->irq to
be the lowest of the new interrupts assigned to it.  The other interrupts
assigned to the device are in the range dev->irq to dev->irq + returned
value - 1.

If this function returns a negative number, it indicates an error and
the driver should not attempt to request any more MSI interrupts for
this device.

If the device driver needs to know the number of interrupts the device
supports it can pass the pointer count where that number is stored. The
device driver must decide what action to take if pci_enable_msi_block_auto()
succeeds, but returns a value less than the number of interrupts supported.
If the device driver does not need to know the number of interrupts
supported, it can set the pointer count to NULL.

4.2.4 pci_disable_msi

void pci_disable_msi(struct pci_dev *dev)

This function should be used to undo the effect of pci_enable_msi() or
pci_enable_msi_block() or pci_enable_msi_block_auto().  Calling it restores
dev->irq to the pin-based interrupt number and frees the previously
allocated message signaled interrupt(s).  The interrupt may subsequently be
assigned to another device, so drivers should not cache the value of
dev->irq.

Before calling this function, a device driver must always call free_irq()
on any interrupt for which it previously called request_irq().
Failure to do so results in a BUG_ON(), leaving the device with
MSI enabled and thus leaking its vector.

4.3 Using MSI-X

The MSI-X capability is much more flexible than the MSI capability.
It supports up to 2048 interrupts, each of which can be controlled
independently.  To support this flexibility, drivers must use an array of
`struct msix_entry':

struct msix_entry {
	u16 	vector; /* kernel uses to write alloc vector */
	u16	entry; /* driver uses to specify entry */
};

This allows for the device to use these interrupts in a sparse fashion;
for example, it could use interrupts 3 and 1027 and yet allocate only a
two-element array.  The driver is expected to fill in the 'entry' value
in each element of the array to indicate for which entries the kernel
should assign interrupts; it is invalid to fill in two entries with the
same number.

4.3.1 pci_enable_msix

int pci_enable_msix(struct pci_dev *dev, struct msix_entry *entries, int nvec)

Calling this function asks the PCI subsystem to allocate 'nvec' MSIs.
The 'entries' argument is a pointer to an array of msix_entry structs
which should be at least 'nvec' entries in size.  On success, the
device is switched into MSI-X mode and the function returns 0.
The 'vector' member in each entry is populated with the interrupt number;
the driver should then call request_irq() for each 'vector' that it
decides to use.  The device driver is responsible for keeping track of the
interrupts assigned to the MSI-X vectors so it can free them again later.

If this function returns a negative number, it indicates an error and
the driver should not attempt to allocate any more MSI-X interrupts for
this device.  If it returns a positive number, it indicates the maximum
number of interrupt vectors that could have been allocated. See example
below.

This function, in contrast with pci_enable_msi(), does not adjust
dev->irq.  The device will not generate interrupts for this interrupt
number once MSI-X is enabled.

Device drivers should normally call this function once per device
during the initialization phase.

It is ideal if drivers can cope with a variable number of MSI-X interrupts;
there are many reasons why the platform may not be able to provide the
exact number that a driver asks for.

A request loop to achieve that might look like:

static int foo_driver_enable_msix(struct foo_adapter *adapter, int nvec)
{
	while (nvec >= FOO_DRIVER_MINIMUM_NVEC) {
		rc = pci_enable_msix(adapter->pdev,
				     adapter->msix_entries, nvec);
		if (rc > 0)
			nvec = rc;
		else
			return rc;
	}

	return -ENOSPC;
}

4.3.2 pci_disable_msix

void pci_disable_msix(struct pci_dev *dev)

This function should be used to undo the effect of pci_enable_msix().  It frees
the previously allocated message signaled interrupts.  The interrupts may
subsequently be assigned to another device, so drivers should not cache
the value of the 'vector' elements over a call to pci_disable_msix().

Before calling this function, a device driver must always call free_irq()
on any interrupt for which it previously called request_irq().
Failure to do so results in a BUG_ON(), leaving the device with
MSI-X enabled and thus leaking its vector.

4.3.3 The MSI-X Table

The MSI-X capability specifies a BAR and offset within that BAR for the
MSI-X Table.  This address is mapped by the PCI subsystem, and should not
be accessed directly by the device driver.  If the driver wishes to
mask or unmask an interrupt, it should call disable_irq() / enable_irq().

4.4 Handling devices implementing both MSI and MSI-X capabilities

If a device implements both MSI and MSI-X capabilities, it can
run in either MSI mode or MSI-X mode, but not both simultaneously.
This is a requirement of the PCI spec, and it is enforced by the
PCI layer.  Calling pci_enable_msi() when MSI-X is already enabled or
pci_enable_msix() when MSI is already enabled results in an error.
If a device driver wishes to switch between MSI and MSI-X at runtime,
it must first quiesce the device, then switch it back to pin-interrupt
mode, before calling pci_enable_msi() or pci_enable_msix() and resuming
operation.  This is not expected to be a common operation but may be
useful for debugging or testing during development.

4.5 Considerations when using MSIs

4.5.1 Choosing between MSI-X and MSI

If your device supports both MSI-X and MSI capabilities, you should use
the MSI-X facilities in preference to the MSI facilities.  As mentioned
above, MSI-X supports any number of interrupts between 1 and 2048.
In constrast, MSI is restricted to a maximum of 32 interrupts (and
must be a power of two).  In addition, the MSI interrupt vectors must
be allocated consecutively, so the system might not be able to allocate
as many vectors for MSI as it could for MSI-X.  On some platforms, MSI
interrupts must all be targeted at the same set of CPUs whereas MSI-X
interrupts can all be targeted at different CPUs.

4.5.2 Spinlocks

Most device drivers have a per-device spinlock which is taken in the
interrupt handler.  With pin-based interrupts or a single MSI, it is not
necessary to disable interrupts (Linux guarantees the same interrupt will
not be re-entered).  If a device uses multiple interrupts, the driver
must disable interrupts while the lock is held.  If the device sends
a different interrupt, the driver will deadlock trying to recursively
acquire the spinlock.

There are two solutions.  The first is to take the lock with
spin_lock_irqsave() or spin_lock_irq() (see
Documentation/DocBook/kernel-locking).  The second is to specify
IRQF_DISABLED to request_irq() so that the kernel runs the entire
interrupt routine with interrupts disabled.

If your MSI interrupt routine does not hold the lock for the whole time
it is running, the first solution may be best.  The second solution is
normally preferred as it avoids making two transitions from interrupt
disabled to enabled and back again.

4.6 How to tell whether MSI/MSI-X is enabled on a device

Using 'lspci -v' (as root) may show some devices with "MSI", "Message
Signalled Interrupts" or "MSI-X" capabilities.  Each of these capabilities
has an 'Enable' flag which is followed with either "+" (enabled)
or "-" (disabled).

5. MSI quirks

Several PCI chipsets or devices are known not to support MSIs.
The PCI stack provides three ways to disable MSIs:

1. globally
2. on all devices behind a specific bridge
3. on a single device

5.1. Disabling MSIs globally

Some host chipsets simply don't support MSIs properly.  If we're
lucky, the manufacturer knows this and has indicated it in the ACPI
FADT table.  In this case, Linux automatically disables MSIs.
Some boards don't include this information in the table and so we have
to detect them ourselves.  The complete list of these is found near the
quirk_disable_all_msi() function in drivers/pci/quirks.c.

If you have a board which has problems with MSIs, you can pass pci=nomsi
on the kernel command line to disable MSIs on all devices.  It would be
in your best interests to report the problem to linux-pci@vger.kernel.org
including a full 'lspci -v' so we can add the quirks to the kernel.

5.2. Disabling MSIs below a bridge

Some PCI bridges are not able to route MSIs between busses properly.
In this case, MSIs must be disabled on all devices behind the bridge.

Some bridges allow you to enable MSIs by changing some bits in their
PCI configuration space (especially the Hypertransport chipsets such
as the nVidia nForce and Serverworks HT2000).  As with host chipsets,
Linux mostly knows about them and automatically enables MSIs if it can.
If you have a bridge unknown to Linux, you can enable
MSIs in configuration space using whatever method you know works, then
enable MSIs on that bridge by doing:

       echo 1 > /sys/bus/pci/devices/$bridge/msi_bus

where $bridge is the PCI address of the bridge you've enabled (eg
0000:00:0e.0).

To disable MSIs, echo 0 instead of 1.  Changing this value should be
done with caution as it could break interrupt handling for all devices
below this bridge.

Again, please notify linux-pci@vger.kernel.org of any bridges that need
special handling.

5.3. Disabling MSIs on a single device

Some devices are known to have faulty MSI implementations.  Usually this
is handled in the individual device driver, but occasionally it's necessary
to handle this with a quirk.  Some drivers have an option to disable use
of MSI.  While this is a convenient workaround for the driver author,
it is not good practise, and should not be emulated.

5.4. Finding why MSIs are disabled on a device

From the above three sections, you can see that there are many reasons
why MSIs may not be enabled for a given device.  Your first step should
be to examine your dmesg carefully to determine whether MSIs are enabled
for your machine.  You should also check your .config to be sure you
have enabled CONFIG_PCI_MSI.

Then, 'lspci -t' gives the list of bridges above a device.  Reading
/sys/bus/pci/devices/*/msi_bus will tell you whether MSIs are enabled (1)
or disabled (0).  If 0 is found in any of the msi_bus files belonging
to bridges between the PCI root and the device, MSIs are disabled.

It is also worth checking the device driver to see whether it supports MSIs.
For example, it may contain calls to pci_enable_msi(), pci_enable_msix() or
pci_enable_msi_block().

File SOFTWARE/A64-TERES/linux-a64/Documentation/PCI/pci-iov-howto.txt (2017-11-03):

		PCI Express I/O Virtualization Howto
		Copyright (C) 2009 Intel Corporation
		    Yu Zhao <yu.zhao@intel.com>

		Update: November 2012
			-- sysfs-based SRIOV enable-/disable-ment
		Donald Dutile <ddutile@redhat.com>

1. Overview

1.1 What is SR-IOV

Single Root I/O Virtualization (SR-IOV) is a PCI Express Extended
capability which makes one physical device appear as multiple virtual
devices. The physical device is referred to as Physical Function (PF)
while the virtual devices are referred to as Virtual Functions (VF).
Allocation of the VF can be dynamically controlled by the PF via
registers encapsulated in the capability. By default, this feature is
not enabled and the PF behaves as traditional PCIe device. Once it's
turned on, each VF's PCI configuration space can be accessed by its own
Bus, Device and Function Number (Routing ID). And each VF also has PCI
Memory Space, which is used to map its register set. VF device driver
operates on the register set so it can be functional and appear as a
real existing PCI device.

2. User Guide

2.1 How can I enable SR-IOV capability

Multiple methods are available for SR-IOV enablement.
In the first method, the device driver (PF driver) will control the
enabling and disabling of the capability via API provided by SR-IOV core.
If the hardware has SR-IOV capability, loading its PF driver would
enable it and all VFs associated with the PF.  Some PF drivers require
a module parameter to be set to determine the number of VFs to enable.
In the second method, a write to the sysfs file sriov_numvfs will
enable and disable the VFs associated with a PCIe PF.  This method
enables per-PF, VF enable/disable values versus the first method,
which applies to all PFs of the same device.  Additionally, the
PCI SRIOV core support ensures that enable/disable operations are
valid to reduce duplication in multiple drivers for the same
checks, e.g., check numvfs == 0 if enabling VFs, ensure
numvfs <= totalvfs.
The second method is the recommended method for new/future VF devices.

2.2 How can I use the Virtual Functions

The VF is treated as hot-plugged PCI devices in the kernel, so they
should be able to work in the same way as real PCI devices. The VF
requires device driver that is same as a normal PCI device's.

3. Developer Guide

3.1 SR-IOV API

To enable SR-IOV capability:
(a) For the first method, in the driver:
	int pci_enable_sriov(struct pci_dev *dev, int nr_virtfn);
	'nr_virtfn' is number of VFs to be enabled.
(b) For the second method, from sysfs:
	echo 'nr_virtfn' > \
        /sys/bus/pci/devices/<DOMAIN:BUS:DEVICE.FUNCTION>/sriov_numvfs

To disable SR-IOV capability:
(a) For the first method, in the driver:
	void pci_disable_sriov(struct pci_dev *dev);
(b) For the second method, from sysfs:
	echo  0 > \
        /sys/bus/pci/devices/<DOMAIN:BUS:DEVICE.FUNCTION>/sriov_numvfs

To notify SR-IOV core of Virtual Function Migration:
(a) In the driver:
	irqreturn_t pci_sriov_migration(struct pci_dev *dev);

3.2 Usage example

Following piece of code illustrates the usage of the SR-IOV API.

static int dev_probe(struct pci_dev *dev, const struct pci_device_id *id)
{
	pci_enable_sriov(dev, NR_VIRTFN);

	...

	return 0;
}

static void dev_remove(struct pci_dev *dev)
{
	pci_disable_sriov(dev);

	...
}

static int dev_suspend(struct pci_dev *dev, pm_message_t state)
{
	...

	return 0;
}

static int dev_resume(struct pci_dev *dev)
{
	...

	return 0;
}

static void dev_shutdown(struct pci_dev *dev)
{
	...
}

static int dev_sriov_configure(struct pci_dev *dev, int numvfs)
{
	if (numvfs > 0) {
		...
		pci_enable_sriov(dev, numvfs);
		...
		return numvfs;
	}
	if (numvfs == 0) {
		....
		pci_disable_sriov(dev);
		...
		return 0;
	}
}

static struct pci_driver dev_driver = {
	.name =		"SR-IOV Physical Function driver",
	.id_table =	dev_id_table,
	.probe =	dev_probe,
	.remove =	dev_remove,
	.suspend =	dev_suspend,
	.resume =	dev_resume,
	.shutdown =	dev_shutdown,
	.sriov_configure = dev_sriov_configure,
};

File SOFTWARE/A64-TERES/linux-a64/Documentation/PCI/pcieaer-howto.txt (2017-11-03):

   The PCI Express Advanced Error Reporting Driver Guide HOWTO
		T. Long Nguyen	<tom.l.nguyen@intel.com>
		Yanmin Zhang	<yanmin.zhang@intel.com>
				07/29/2006

1. Overview

1.1 About this guide

This guide describes the basics of the PCI Express Advanced Error
Reporting (AER) driver and provides information on how to use it, as
well as how to enable the drivers of endpoint devices to conform with
PCI Express AER driver.

1.2 Copyright (C) Intel Corporation 2006.

1.3 What is the PCI Express AER Driver?

PCI Express error signaling can occur on the PCI Express link itself
or on behalf of transactions initiated on the link. PCI Express
defines two error reporting paradigms: the baseline capability and
the Advanced Error Reporting capability. The baseline capability is
required of all PCI Express components providing a minimum defined
set of error reporting requirements. Advanced Error Reporting
capability is implemented with a PCI Express advanced error reporting
extended capability structure providing more robust error reporting.

The PCI Express AER driver provides the infrastructure to support PCI
Express Advanced Error Reporting capability. The PCI Express AER
driver provides three basic functions:

-	Gathers the comprehensive error information if errors occurred.
-	Reports error to the users.
-	Performs error recovery actions.

AER driver only attaches root ports which support PCI-Express AER
capability.

2. User Guide

2.1 Include the PCI Express AER Root Driver into the Linux Kernel

The PCI Express AER Root driver is a Root Port service driver attached
to the PCI Express Port Bus driver. If a user wants to use it, the driver
has to be compiled. Option CONFIG_PCIEAER supports this capability. It
depends on CONFIG_PCIEPORTBUS, so pls. set CONFIG_PCIEPORTBUS=y and
CONFIG_PCIEAER = y.

2.2 Load PCI Express AER Root Driver
There is a case where a system has AER support in BIOS. Enabling the AER
Root driver and having AER support in BIOS may result unpredictable
behavior. To avoid this conflict, a successful load of the AER Root driver
requires ACPI _OSC support in the BIOS to allow the AER Root driver to
request for native control of AER. See the PCI FW 3.0 Specification for
details regarding OSC usage. Currently, lots of firmwares don't provide
_OSC support while they use PCI Express. To support such firmwares,
forceload, a parameter of type bool, could enable AER to continue to
be initiated although firmwares have no _OSC support. To enable the
walkaround, pls. add aerdriver.forceload=y to kernel boot parameter line
when booting kernel. Note that forceload=n by default.

nosourceid, another parameter of type bool, can be used when broken
hardware (mostly chipsets) has root ports that cannot obtain the reporting
source ID. nosourceid=n by default.

2.3 AER error output
When a PCI-E AER error is captured, an error message will be outputed to
console. If it's a correctable error, it is outputed as a warning.
Otherwise, it is printed as an error. So users could choose different
log level to filter out correctable error messages.

Below shows an example:
0000:50:00.0: PCIe Bus Error: severity=Uncorrected (Fatal), type=Transaction Layer, id=0500(Requester ID)
0000:50:00.0:   device [8086:0329] error status/mask=00100000/00000000
0000:50:00.0:    [20] Unsupported Request    (First)
0000:50:00.0:   TLP Header: 04000001 00200a03 05010000 00050100

In the example, 'Requester ID' means the ID of the device who sends
the error message to root port. Pls. refer to pci express specs for
other fields.

3. Developer Guide

To enable AER aware support requires a software driver to configure
the AER capability structure within its device and to provide callbacks.

To support AER better, developers need understand how AER does work
firstly.

PCI Express errors are classified into two types: correctable errors
and uncorrectable errors. This classification is based on the impacts
of those errors, which may result in degraded performance or function
failure.

Correctable errors pose no impacts on the functionality of the
interface. The PCI Express protocol can recover without any software
intervention or any loss of data. These errors are detected and
corrected by hardware. Unlike correctable errors, uncorrectable
errors impact functionality of the interface. Uncorrectable errors
can cause a particular transaction or a particular PCI Express link
to be unreliable. Depending on those error conditions, uncorrectable
errors are further classified into non-fatal errors and fatal errors.
Non-fatal errors cause the particular transaction to be unreliable,
but the PCI Express link itself is fully functional. Fatal errors, on
the other hand, cause the link to be unreliable.

When AER is enabled, a PCI Express device will automatically send an
error message to the PCIe root port above it when the device captures
an error. The Root Port, upon receiving an error reporting message,
internally processes and logs the error message in its PCI Express
capability structure. Error information being logged includes storing
the error reporting agent's requestor ID into the Error Source
Identification Registers and setting the error bits of the Root Error
Status Register accordingly. If AER error reporting is enabled in Root
Error Command Register, the Root Port generates an interrupt if an
error is detected.

Note that the errors as described above are related to the PCI Express
hierarchy and links. These errors do not include any device specific
errors because device specific errors will still get sent directly to
the device driver.

3.1 Configure the AER capability structure

AER aware drivers of PCI Express component need change the device
control registers to enable AER. They also could change AER registers,
including mask and severity registers. Helper function
pci_enable_pcie_error_reporting could be used to enable AER. See
section 3.3.

3.2. Provide callbacks

3.2.1 callback reset_link to reset pci express link

This callback is used to reset the pci express physical link when a
fatal error happens. The root port aer service driver provides a
default reset_link function, but different upstream ports might
have different specifications to reset pci express link, so all
upstream ports should provide their own reset_link functions.

In struct pcie_port_service_driver, a new pointer, reset_link, is
added.

pci_ers_result_t (*reset_link) (struct pci_dev *dev);

Section 3.2.2.2 provides more detailed info on when to call
reset_link.

3.2.2 PCI error-recovery callbacks

The PCI Express AER Root driver uses error callbacks to coordinate
with downstream device drivers associated with a hierarchy in question
when performing error recovery actions.

Data struct pci_driver has a pointer, err_handler, to point to
pci_error_handlers who consists of a couple of callback function
pointers. AER driver follows the rules defined in
pci-error-recovery.txt except pci express specific parts (e.g.
reset_link). Pls. refer to pci-error-recovery.txt for detailed
definitions of the callbacks.

Below sections specify when to call the error callback functions.

3.2.2.1 Correctable errors

Correctable errors pose no impacts on the functionality of
the interface. The PCI Express protocol can recover without any
software intervention or any loss of data. These errors do not
require any recovery actions. The AER driver clears the device's
correctable error status register accordingly and logs these errors.

3.2.2.2 Non-correctable (non-fatal and fatal) errors

If an error message indicates a non-fatal error, performing link reset
at upstream is not required. The AER driver calls error_detected(dev,
pci_channel_io_normal) to all drivers associated within a hierarchy in
question. for example,
EndPoint<==>DownstreamPort B<==>UpstreamPort A<==>RootPort.
If Upstream port A captures an AER error, the hierarchy consists of
Downstream port B and EndPoint.

A driver may return PCI_ERS_RESULT_CAN_RECOVER,
PCI_ERS_RESULT_DISCONNECT, or PCI_ERS_RESULT_NEED_RESET, depending on
whether it can recover or the AER driver calls mmio_enabled as next.

If an error message indicates a fatal error, kernel will broadcast
error_detected(dev, pci_channel_io_frozen) to all drivers within
a hierarchy in question. Then, performing link reset at upstream is
necessary. As different kinds of devices might use different approaches
to reset link, AER port service driver is required to provide the
function to reset link. Firstly, kernel looks for if the upstream
component has an aer driver. If it has, kernel uses the reset_link
callback of the aer driver. If the upstream component has no aer driver
and the port is downstream port, we will perform a hot reset as the
default by setting the Secondary Bus Reset bit of the Bridge Control
register associated with the downstream port. As for upstream ports,
they should provide their own aer service drivers with reset_link
function. If error_detected returns PCI_ERS_RESULT_CAN_RECOVER and
reset_link returns PCI_ERS_RESULT_RECOVERED, the error handling goes
to mmio_enabled.

3.3 helper functions

3.3.1 int pci_enable_pcie_error_reporting(struct pci_dev *dev);
pci_enable_pcie_error_reporting enables the device to send error
messages to root port when an error is detected. Note that devices
don't enable the error reporting by default, so device drivers need
call this function to enable it.

3.3.2 int pci_disable_pcie_error_reporting(struct pci_dev *dev);
pci_disable_pcie_error_reporting disables the device to send error
messages to root port when an error is detected.

3.3.3 int pci_cleanup_aer_uncorrect_error_status(struct pci_dev *dev);
pci_cleanup_aer_uncorrect_error_status cleanups the uncorrectable
error status register.

3.4 Frequent Asked Questions

Q: What happens if a PCI Express device driver does not provide an
error recovery handler (pci_driver->err_handler is equal to NULL)?

A: The devices attached with the driver won't be recovered. If the
error is fatal, kernel will print out warning messages. Please refer
to section 3 for more information.

Q: What happens if an upstream port service driver does not provide
callback reset_link?

A: Fatal error recovery will fail if the errors are reported by the
upstream ports who are attached by the service driver.

Q: How does this infrastructure deal with driver that is not PCI
Express aware?

A: This infrastructure calls the error callback functions of the
driver when an error happens. But if the driver is not aware of
PCI Express, the device might not report its own errors to root
port.

Q: What modifications will that driver need to make it compatible
with the PCI Express AER Root driver?

A: It could call the helper functions to enable AER in devices and
cleanup uncorrectable status register. Pls. refer to section 3.3.

4. Software error injection

Debugging PCIe AER error recovery code is quite difficult because it
is hard to trigger real hardware errors. Software based error
injection can be used to fake various kinds of PCIe errors.

First you should enable PCIe AER software error injection in kernel
configuration, that is, following item should be in your .config.

CONFIG_PCIEAER_INJECT=y or CONFIG_PCIEAER_INJECT=m

After reboot with new kernel or insert the module, a device file named
/dev/aer_inject should be created.

Then, you need a user space tool named aer-inject, which can be gotten
from:
    http://www.kernel.org/pub/linux/utils/pci/aer-inject/

More information about aer-inject can be found in the document comes
with its source code.

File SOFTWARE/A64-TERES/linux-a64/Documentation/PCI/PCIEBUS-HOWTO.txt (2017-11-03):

		The PCI Express Port Bus Driver Guide HOWTO
	Tom L Nguyen tom.l.nguyen@intel.com
			11/03/2004

1. About this guide

This guide describes the basics of the PCI Express Port Bus driver
and provides information on how to enable the service drivers to
register/unregister with the PCI Express Port Bus Driver.

2. Copyright 2004 Intel Corporation

3. What is the PCI Express Port Bus Driver

A PCI Express Port is a logical PCI-PCI Bridge structure. There
are two types of PCI Express Port: the Root Port and the Switch
Port. The Root Port originates a PCI Express link from a PCI Express
Root Complex and the Switch Port connects PCI Express links to
internal logical PCI buses. The Switch Port, which has its secondary
bus representing the switch's internal routing logic, is called the
switch's Upstream Port. The switch's Downstream Port is bridging from
switch's internal routing bus to a bus representing the downstream
PCI Express link from the PCI Express Switch.

A PCI Express Port can provide up to four distinct functions,
referred to in this document as services, depending on its port type.
PCI Express Port's services include native hotplug support (HP),
power management event support (PME), advanced error reporting
support (AER), and virtual channel support (VC). These services may
be handled by a single complex driver or be individually distributed
and handled by corresponding service drivers.

4. Why use the PCI Express Port Bus Driver?

In existing Linux kernels, the Linux Device Driver Model allows a
physical device to be handled by only a single driver. The PCI
Express Port is a PCI-PCI Bridge device with multiple distinct
services. To maintain a clean and simple solution each service
may have its own software service driver. In this case several
service drivers will compete for a single PCI-PCI Bridge device.
For example, if the PCI Express Root Port native hotplug service
driver is loaded first, it claims a PCI-PCI Bridge Root Port. The
kernel therefore does not load other service drivers for that Root
Port. In other words, it is impossible to have multiple service
drivers load and run on a PCI-PCI Bridge device simultaneously
using the current driver model.

To enable multiple service drivers running simultaneously requires
having a PCI Express Port Bus driver, which manages all populated
PCI Express Ports and distributes all provided service requests
to the corresponding service drivers as required. Some key
advantages of using the PCI Express Port Bus driver are listed below:

	- Allow multiple service drivers to run simultaneously on
	  a PCI-PCI Bridge Port device.

	- Allow service drivers implemented in an independent
	  staged approach.

	- Allow one service driver to run on multiple PCI-PCI Bridge
	  Port devices.

	- Manage and distribute resources of a PCI-PCI Bridge Port
	  device to requested service drivers.

5. Configuring the PCI Express Port Bus Driver vs. Service Drivers

5.1 Including the PCI Express Port Bus Driver Support into the Kernel

Including the PCI Express Port Bus driver depends on whether the PCI
Express support is included in the kernel config. The kernel will
automatically include the PCI Express Port Bus driver as a kernel
driver when the PCI Express support is enabled in the kernel.

5.2 Enabling Service Driver Support

PCI device drivers are implemented based on Linux Device Driver Model.
All service drivers are PCI device drivers. As discussed above, it is
impossible to load any service driver once the kernel has loaded the
PCI Express Port Bus Driver. To meet the PCI Express Port Bus Driver
Model requires some minimal changes on existing service drivers that
imposes no impact on the functionality of existing service drivers.

A service driver is required to use the two APIs shown below to
register its service with the PCI Express Port Bus driver (see
section 5.2.1 & 5.2.2). It is important that a service driver
initializes the pcie_port_service_driver data structure, included in
header file /include/linux/pcieport_if.h, before calling these APIs.
Failure to do so will result an identity mismatch, which prevents
the PCI Express Port Bus driver from loading a service driver.

5.2.1 pcie_port_service_register

int pcie_port_service_register(struct pcie_port_service_driver *new)

This API replaces the Linux Driver Model's pci_register_driver API. A
service driver should always calls pcie_port_service_register at
module init. Note that after service driver being loaded, calls
such as pci_enable_device(dev) and pci_set_master(dev) are no longer
necessary since these calls are executed by the PCI Port Bus driver.

5.2.2 pcie_port_service_unregister

void pcie_port_service_unregister(struct pcie_port_service_driver *new)

pcie_port_service_unregister replaces the Linux Driver Model's
pci_unregister_driver. It's always called by service driver when a
module exits.

5.2.3 Sample Code

Below is sample service driver code to initialize the port service
driver data structure.

static struct pcie_port_service_id service_id[] = { {
	.vendor = PCI_ANY_ID,
	.device = PCI_ANY_ID,
	.port_type = PCIE_RC_PORT,
	.service_type = PCIE_PORT_SERVICE_AER,
	}, { /* end: all zeroes */ }
};

static struct pcie_port_service_driver root_aerdrv = {
	.name		= (char *)device_name,
	.id_table	= &service_id[0],

	.probe		= aerdrv_load,
	.remove		= aerdrv_unload,

	.suspend	= aerdrv_suspend,
	.resume		= aerdrv_resume,
};

Below is a sample code for registering/unregistering a service
driver.

static int __init aerdrv_service_init(void)
{
	int retval = 0;

	retval = pcie_port_service_register(&root_aerdrv);
	if (!retval) {
		/*
		 * FIX ME
		 */
	}
	return retval;
}

static void __exit aerdrv_service_exit(void)
{
	pcie_port_service_unregister(&root_aerdrv);
}

module_init(aerdrv_service_init);
module_exit(aerdrv_service_exit);

6. Possible Resource Conflicts

Since all service drivers of a PCI-PCI Bridge Port device are
allowed to run simultaneously, below lists a few of possible resource
conflicts with proposed solutions.

6.1 MSI Vector Resource

The MSI capability structure enables a device software driver to call
pci_enable_msi to request MSI based interrupts. Once MSI interrupts
are enabled on a device, it stays in this mode until a device driver
calls pci_disable_msi to disable MSI interrupts and revert back to
INTx emulation mode. Since service drivers of the same PCI-PCI Bridge
port share the same physical device, if an individual service driver
calls pci_enable_msi/pci_disable_msi it may result unpredictable
behavior. For example, two service drivers run simultaneously on the
same physical Root Port. Both service drivers call pci_enable_msi to
request MSI based interrupts. A service driver may not know whether
any other service drivers have run on this Root Port. If either one
of them calls pci_disable_msi, it puts the other service driver
in a wrong interrupt mode.

To avoid this situation all service drivers are not permitted to
switch interrupt mode on its device. The PCI Express Port Bus driver
is responsible for determining the interrupt mode and this should be
transparent to service drivers. Service drivers need to know only
the vector IRQ assigned to the field irq of struct pcie_device, which
is passed in when the PCI Express Port Bus driver probes each service
driver. Service drivers should use (struct pcie_device*)dev->irq to
call request_irq/free_irq. In addition, the interrupt mode is stored
in the field interrupt_mode of struct pcie_device.

6.2 MSI-X Vector Resources

Similar to the MSI a device driver for an MSI-X capable device can
call pci_enable_msix to request MSI-X interrupts. All service drivers
are not permitted to switch interrupt mode on its device. The PCI
Express Port Bus driver is responsible for determining the interrupt
mode and this should be transparent to service drivers. Any attempt
by service driver to call pci_enable_msix/pci_disable_msix may
result unpredictable behavior. Service drivers should use
(struct pcie_device*)dev->irq and call request_irq/free_irq.

6.3 PCI Memory/IO Mapped Regions

Service drivers for PCI Express Power Management (PME), Advanced
Error Reporting (AER), Hot-Plug (HP) and Virtual Channel (VC) access
PCI configuration space on the PCI Express port. In all cases the
registers accessed are independent of each other. This patch assumes
that all service drivers will be well behaved and not overwrite
other service driver's configuration settings.

6.4 PCI Config Registers

Each service driver runs its PCI config operations on its own
capability structure except the PCI Express capability structure, in
which Root Control register and Device Control register are shared
between PME and AER. This patch assumes that all service drivers
will be well behaved and not overwrite other service driver's
configuration settings.

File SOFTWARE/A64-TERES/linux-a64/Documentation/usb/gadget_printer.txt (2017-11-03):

                       Linux USB Printer Gadget Driver
                                 06/04/2007

              Copyright (C) 2007 Craig W. Nadler <craig@nadler.us>

GENERAL
=======

This driver may be used if you are writing printer firmware using Linux as
the embedded OS. This driver has nothing to do with using a printer with
your Linux host system.

You will need a USB device controller and a Linux driver for it that accepts
a gadget / "device class" driver using the Linux USB Gadget API. After the
USB device controller driver is loaded then load the printer gadget driver.
This will present a printer interface to the USB Host that your USB Device
port is connected to.

This driver is structured for printer firmware that runs in user mode. The
user mode printer firmware will read and write data from the kernel mode
printer gadget driver using a device file. The printer returns a printer status
byte when the USB HOST sends a device request to get the printer status.  The
user space firmware can read or write this status byte using a device file
/dev/g_printer . Both blocking and non-blocking read/write calls are supported.

HOWTO USE THIS DRIVER
=====================

To load the USB device controller driver and the printer gadget driver. The
following example uses the Netchip 2280 USB device controller driver:

modprobe net2280
modprobe g_printer

The follow command line parameter can be used when loading the printer gadget
(ex: modprobe g_printer idVendor=0x0525 idProduct=0xa4a8 ):

idVendor - This is the Vendor ID used in the device descriptor. The default is
	the Netchip vendor id 0x0525. YOU MUST CHANGE TO YOUR OWN VENDOR ID
	BEFORE RELEASING A PRODUCT. If you plan to release a product and don't
	already have a Vendor ID please see www.usb.org for details on how to
	get one.

idProduct - This is the Product ID used in the device descriptor. The default
	is 0xa4a8, you should change this to an ID that's not used by any of
	your other USB products if you have any. It would be a good idea to
	start numbering your products starting with say 0x0001.

bcdDevice - This is the version number of your product. It would be a good idea
	to put your firmware version here.

iManufacturer - A string containing the name of the Vendor.

iProduct - A string containing the Product Name.

iSerialNum - A string containing the Serial Number. This should be changed for
	each unit of your product.

iPNPstring -  The PNP ID string used for this printer. You will want to set
	either on the command line or hard code the PNP ID string used for
	your printer product.

qlen - The number of 8k buffers to use per endpoint. The default is 10, you
	should tune this for your product. You may also want to tune the
	size of each buffer for your product.

USING THE EXAMPLE CODE
======================

This example code talks to stdout, instead of a print engine.

To compile the test code below:

1) save it to a file called prn_example.c
2) compile the code with the follow command:
	 gcc prn_example.c -o prn_example

To read printer data from the host to stdout:

	# prn_example -read_data

To write printer data from a file (data_file) to the host:

	# cat data_file | prn_example -write_data

To get the current printer status for the gadget driver:

	# prn_example -get_status

	Printer status is:
	     Printer is NOT Selected
	     Paper is Out
	     Printer OK

To set printer to Selected/On-line:

	# prn_example -selected

To set printer to Not Selected/Off-line:

	# prn_example -not_selected

To set paper status to paper out:

	# prn_example -paper_out

To set paper status to paper loaded:

	# prn_example -paper_loaded

To set error status to printer OK:

	# prn_example -no_error

To set error status to ERROR:

	# prn_example -error

EXAMPLE CODE
============

#include <stdio.h>
#include <stdlib.h>
#include <fcntl.h>
#include <linux/poll.h>
#include <sys/ioctl.h>
#include <linux/usb/g_printer.h>

#define PRINTER_FILE			"/dev/g_printer"
#define BUF_SIZE			512

/*
 * 'usage()' - Show program usage.
 */

static void
usage(const char *option)		/* I - Option string or NULL */
{
	if (option) {
		fprintf(stderr,"prn_example: Unknown option \"%s\"!\n",
				option);
	}

	fputs("\n", stderr);
	fputs("Usage: prn_example -[options]\n", stderr);
	fputs("Options:\n", stderr);
	fputs("\n", stderr);
	fputs("-get_status    Get the current printer status.\n", stderr);
	fputs("-selected      Set the selected status to selected.\n", stderr);
	fputs("-not_selected  Set the selected status to NOT selected.\n",
			stderr);
	fputs("-error         Set the error status to error.\n", stderr);
	fputs("-no_error      Set the error status to NO error.\n", stderr);
	fputs("-paper_out     Set the paper status to paper out.\n", stderr);
	fputs("-paper_loaded  Set the paper status to paper loaded.\n",
			stderr);
	fputs("-read_data     Read printer data from driver.\n", stderr);
	fputs("-write_data    Write printer sata to driver.\n", stderr);
	fputs("-NB_read_data  (Non-Blocking) Read printer data from driver.\n",
			stderr);
	fputs("\n\n", stderr);

	exit(1);
}

static int
read_printer_data()
{
	struct pollfd	fd[1];

	/* Open device file for printer gadget. */
	fd[0].fd = open(PRINTER_FILE, O_RDWR);
	if (fd[0].fd < 0) {
		printf("Error %d opening %s\n", fd[0].fd, PRINTER_FILE);
		close(fd[0].fd);
		return(-1);
	}

	fd[0].events = POLLIN | POLLRDNORM;

	while (1) {
		static char buf[BUF_SIZE];
		int bytes_read;
		int retval;

		/* Wait for up to 1 second for data. */
		retval = poll(fd, 1, 1000);

		if (retval && (fd[0].revents & POLLRDNORM)) {

			/* Read data from printer gadget driver. */
			bytes_read = read(fd[0].fd, buf, BUF_SIZE);

			if (bytes_read < 0) {
				printf("Error %d reading from %s\n",
						fd[0].fd, PRINTER_FILE);
				close(fd[0].fd);
				return(-1);
			} else if (bytes_read > 0) {
				/* Write data to standard OUTPUT (stdout). */
				fwrite(buf, 1, bytes_read, stdout);
				fflush(stdout);
			}

		}

	}

	/* Close the device file. */
	close(fd[0].fd);

	return 0;
}

static int
write_printer_data()
{
	struct pollfd	fd[1];

	/* Open device file for printer gadget. */
	fd[0].fd = open (PRINTER_FILE, O_RDWR);
	if (fd[0].fd < 0) {
		printf("Error %d opening %s\n", fd[0].fd, PRINTER_FILE);
		close(fd[0].fd);
		return(-1);
	}

	fd[0].events = POLLOUT | POLLWRNORM;

	while (1) {
		int retval;
		static char buf[BUF_SIZE];
		/* Read data from standard INPUT (stdin). */
		int bytes_read = fread(buf, 1, BUF_SIZE, stdin);

		if (!bytes_read) {
			break;
		}

		while (bytes_read) {

			/* Wait for up to 1 second to sent data. */
			retval = poll(fd, 1, 1000);

			/* Write data to printer gadget driver. */
			if (retval && (fd[0].revents & POLLWRNORM)) {
				retval = write(fd[0].fd, buf, bytes_read);
				if (retval < 0) {
					printf("Error %d writing to %s\n",
							fd[0].fd,
							PRINTER_FILE);
					close(fd[0].fd);
					return(-1);
				} else {
					bytes_read -= retval;
				}

			}

		}

	}

	/* Wait until the data has been sent. */
	fsync(fd[0].fd);

	/* Close the device file. */
	close(fd[0].fd);

	return 0;
}

static int
read_NB_printer_data()
{
	int		fd;
	static char	buf[BUF_SIZE];
	int		bytes_read;

	/* Open device file for printer gadget. */
	fd = open(PRINTER_FILE, O_RDWR|O_NONBLOCK);
	if (fd < 0) {
		printf("Error %d opening %s\n", fd, PRINTER_FILE);
		close(fd);
		return(-1);
	}

	while (1) {
		/* Read data from printer gadget driver. */
		bytes_read = read(fd, buf, BUF_SIZE);
		if (bytes_read <= 0) {
			break;
		}

		/* Write data to standard OUTPUT (stdout). */
		fwrite(buf, 1, bytes_read, stdout);
		fflush(stdout);
	}

	/* Close the device file. */
	close(fd);

	return 0;
}

static int
get_printer_status()
{
	int	retval;
	int	fd;

	/* Open device file for printer gadget. */
	fd = open(PRINTER_FILE, O_RDWR);
	if (fd < 0) {
		printf("Error %d opening %s\n", fd, PRINTER_FILE);
		close(fd);
		return(-1);
	}

	/* Make the IOCTL call. */
	retval = ioctl(fd, GADGET_GET_PRINTER_STATUS);
	if (retval < 0) {
		fprintf(stderr, "ERROR: Failed to set printer status\n");
		return(-1);
	}

	/* Close the device file. */
	close(fd);

	return(retval);
}

static int
set_printer_status(unsigned char buf, int clear_printer_status_bit)
{
	int	retval;
	int	fd;

	retval = get_printer_status();
	if (retval < 0) {
		fprintf(stderr, "ERROR: Failed to get printer status\n");
		return(-1);
	}

	/* Open device file for printer gadget. */
	fd = open(PRINTER_FILE, O_RDWR);

	if (fd < 0) {
		printf("Error %d opening %s\n", fd, PRINTER_FILE);
		close(fd);
		return(-1);
	}

	if (clear_printer_status_bit) {
		retval &= ~buf;
	} else {
		retval |= buf;
	}

	/* Make the IOCTL call. */
	if (ioctl(fd, GADGET_SET_PRINTER_STATUS, (unsigned char)retval)) {
		fprintf(stderr, "ERROR: Failed to set printer status\n");
		return(-1);
	}

	/* Close the device file. */
	close(fd);

	return 0;
}

static int
display_printer_status()
{
	char	printer_status;

	printer_status = get_printer_status();
	if (printer_status < 0) {
		fprintf(stderr, "ERROR: Failed to get printer status\n");
		return(-1);
	}

	printf("Printer status is:\n");
	if (printer_status & PRINTER_SELECTED) {
		printf("     Printer is Selected\n");
	} else {
		printf("     Printer is NOT Selected\n");
	}
	if (printer_status & PRINTER_PAPER_EMPTY) {
		printf("     Paper is Out\n");
	} else {
		printf("     Paper is Loaded\n");
	}
	if (printer_status & PRINTER_NOT_ERROR) {
		printf("     Printer OK\n");
	} else {
		printf("     Printer ERROR\n");
	}

	return(0);
}

int
main(int  argc, char *argv[])
{
	int	i;		/* Looping var */
	int	retval = 0;

	/* No Args */
	if (argc == 1) {
		usage(0);
		exit(0);
	}

	for (i = 1; i < argc && !retval; i ++) {

		if (argv[i][0] != '-') {
			continue;
		}

		if (!strcmp(argv[i], "-get_status")) {
			if (display_printer_status()) {
				retval = 1;
			}

		} else if (!strcmp(argv[i], "-paper_loaded")) {
			if (set_printer_status(PRINTER_PAPER_EMPTY, 1)) {
				retval = 1;
			}

		} else if (!strcmp(argv[i], "-paper_out")) {
			if (set_printer_status(PRINTER_PAPER_EMPTY, 0)) {
				retval = 1;
			}

		} else if (!strcmp(argv[i], "-selected")) {
			if (set_printer_status(PRINTER_SELECTED, 0)) {
				retval = 1;
			}

		} else if (!strcmp(argv[i], "-not_selected")) {
			if (set_printer_status(PRINTER_SELECTED, 1)) {
				retval = 1;
			}

		} else if (!strcmp(argv[i], "-error")) {
			if (set_printer_status(PRINTER_NOT_ERROR, 1)) {
				retval = 1;
			}

		} else if (!strcmp(argv[i], "-no_error")) {
			if (set_printer_status(PRINTER_NOT_ERROR, 0)) {
				retval = 1;
			}

		} else if (!strcmp(argv[i], "-read_data")) {
			if (read_printer_data()) {
				retval = 1;
			}

		} else if (!strcmp(argv[i], "-write_data")) {
			if (write_printer_data()) {
				retval = 1;
			}

		} else if (!strcmp(argv[i], "-NB_read_data")) {
			if (read_NB_printer_data()) {
				retval = 1;
			}

		} else {
			usage(argv[i]);
			retval = 1;
		}
	}

	exit(retval);
}

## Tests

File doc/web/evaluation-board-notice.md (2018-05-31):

Evaluation Board/Kit Important Notice
=====================================

OLIMEX Ltd provides the enclosed product(s) under the following conditions:

This evaluation board/kit/module is intended for use for **ENGINEERING DEVELOPMENT, DEMONSTRATION OR EVALUATION PURPOSES ONLY** and is not considered by OLIMEX Ltd to be finished end-product fit for general consumer use.
Persons handling the product must have electronics training and observe good engineering practice standards.
As such the goods being provided are not intended to be complete in terms of required design-, marketing-, and/or manufacturing related protective considerations, including product safety and environmental measures typically found in the products that incorporate such semiconductor components or circuit boards.
This evaluation board/kit/module does not fall within the scope of the European Union directives regarding electromagnetic compatibility, FCC, CE or UL and therefore may not meet the technical requirements of these directives or other related documents.

The user assumes all responsibility and liability for proper and safe handling of the goods.
Further the user indemnifies OLIMEX from all claims arising from the handling or use of the goods.
Due to the open construction of the product, it's the user responsibility to take any and all appropriate precautions with regard to electrostatic discharge, conducted and radiated emissions.

**EXCEPT TO THE EXTENT OF THE INDEMNITY SET FORTH ABOVE NEITHER PARTY SHALL BE LIABLE TO THE OTHER FOR ANY INDIRECT SPECIAL INCIDENTAL OR CONSEQUENTIAL DAMAGES.**

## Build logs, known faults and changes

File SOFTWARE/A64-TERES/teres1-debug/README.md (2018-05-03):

# teres1-debug

teres1-debug and debug_switch.sh are DIY-TERES1 utilities for turning debug on or off 

Usage: All commands must be executed as superuser

- switch on/off debug for current session only until reboot
```bash
sudo teres1-debug on
```
or
```bash
sudo teres1-debug off
```

- switch on/off debug permanently
```bash
sudo debug_switch.sh on
```
or
```bash
sudo debug_switch.sh off
```

How to download and install:
```bash
git clone https://github.com/d3v1c3nv11/teres1-debug.git
cd teres1-debug
make
sudo make install
```
destination path for installing is /usr/local/sbin, to change - edit Makefile

Jack connection:
```bash
TX   RX
 |   |    
=== == ====|||||||||----------------------------
         |
        GND
```

## VERY IMPORTANT!!! 
## Use 3.3V level serial adapter! Consider our TERES-USB-DEBUG cable: https://www.olimex.com/Products/DIY-Laptop/KITS/TERES-USB-DEBUG/
## DO NOT USE RS232 LEVEL ADAPTERS!

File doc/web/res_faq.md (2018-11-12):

# Frequently Asked Questions (FAQ)

## General

* [Where does the name TERES come from?](intro_name-origin.md)
* [What makes this laptop so different?](intro_what-is-unique.md)
* [Why does open-source matter so much?](intro_importance-of-open-source.md)
* [Where are the open-source materials?](intro_sources.md)
* [How may I contribute to this project?](../../CONTRIBUTING.md)
* I have a question or feedback that does not constitute opening up a ticket. Where do I go?
  * Check out the [user forum](https://www.olimex.com/forum/index.php?board=39.0)!

## Hardware

* Where are the design files for a 3D-printed laptop enclosure?
  * A 3D-printed case design has been developed by [Fork Sand, Inc.](https://www.forksand.com) and the design files may be found [here.](https://code.forksand.com/forksand/olimex-teres-case)
* Are there alternative keyboard options available?
  * None are currently available. Please test compatibility, design a 3-D printed keyboard bezel, and it may get implemented!

## Software

* Does the TERES-I have an upstream mainline kernel? Upstream u-boot?
  * "It works with mainline kernel. There is a debian image with mainline u-boot and kernel." [as of linux-image-4.16.0-rc6-arm64]
  * References:
    * [Olimex Teres-A64: Current Status](http://linux-sunxi.org/Olimex_Teres-A64#Current_status)
    * [Linux mainlining effort](https://linux-sunxi.org/Linux_mainlining_effort)
    * [A64](https://linux-sunxi.org/A64)
    * [lkml.org patch](https://lkml.org/lkml/2018/4/30/288)
    * [Debian bug report](https://bugs.debian.org/cgi-bin/bugreport.cgi?bug=892786)
* How do I install operating system _____?
  * Please reference the [software documentation](../../SOFTWARE/README.md) section for details. If your desired operating system is not listed, it is most likely not yet supported. We'd love your help getting it to run on the TERES-I!

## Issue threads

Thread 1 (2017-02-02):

Would like to contribute

zeekhuge, 2017-02-02:
Hi, I would like to contribute (as well as learn along).
Can you please elaborate the "TO DO" list at
 DIY-LAPTOP/SOFTWARE/A64-TERES/README.md

Thanks.

felipesanches, 2017-03-09:
@ZeekHuge what are your skills? How do you see yourself contributing? Is there any specific area of the circuit/pcb design (or the computer in general) that you might be interested in improving? Perhaps (as you mentioned an interest in a "SOFTWARE" README) you may be more interested in the driver part of this project, right?

ZeekHuge, 2017-03-10:
@felipesanches Yes. I am more interested in drivers and the kernel part. Though I would be really happy to help in the circuit part too (along with learning about it).
I am an undergraduate student with Electronics and Telecommunication as my major.
I have worked on Embedded systems and was a GSoC-2016 student under BeagleBoard.org. I worked on the project called [BeagleScope](https://github.com/ZeekHuge/BeagleScope) . It involved developing support for PRUs and develop IIO drivers.

So, I would like to know if there are software gaps, bugs or requirements that I could help in ?

felipesanches, 2017-03-10:
@ZeekHuge Cool! I participated in GSoC 3 times (once as a mentor) but never on a hardware-related project.

I did work for 5 months on a project called MOD Duo (https://moddevices.com/) which used an A20-SOM. I'm not sure if the final product still uses it or if they changed the CPU, since I do not work there anymore and the motherboard design (even though it was designed with KiCAD and hosted on a private github repo) was never made public, unfortunately.

During the work at the above-mentioned startup, I did patch a portion of the ALSA sound drivers on the linux-sunxi fork of the kernel. I think perhaps https://github.com/linux-sunxi is what is used for this diy-laptop as well? Not sure. I'm still learning about it myself.

I must let you know that I'm not a mantainer of this laptop project (nor affiliated to OLIMEX in any manner), but only an enthusiast as yourself.

happy hacking,
Felipe Sanches

jonassmedegaard, 2017-11-06:
A starting point for improving Linux support for the A64 SoC used in TERES-I is http://linux-sunxi.org/Category:Development

macandchief, 2018-03-31:
I'd like to mention one thing, which is - hopefully - not an issue. I'm not sure where to write about it, so I just make a short note here.

You have the LCD cable near the hinges. This made me think of the MSI s271 notebooks, which had a "built in flaw". It had the cable also near the hinges. Every time the lid was opened or closed, the cable moved back and forth. On EVERY notebook there were broken cables after a while (the cable contained several thinner cables and sometimes the one for the speakers broke, sometimes the one for the LCD).

Im just mentioning it, because it's good to think about these design flaws and avoid them. Hopefully it is not an issue on the Teres I.

jcstaudt, 2018-05-18:
I'm not at all the arbiter for this, but the most commonly-accepted practice is:

* `CONTRIBUTING`
  * This document should be located at the root directory of the [DIY-LAPTOP](https://github.com/OLIMEX/DIY-LAPTOP) repository and describe the best-practices for everything to be contributed to the repo
  * As this repo contains both **HARDWARE** and **SOFTWARE** codebases, the `CONTRIBUTING` guide ought to link to other more-specific documentation located within each subdirectory
  * Regardless of experience, abiding by these guidelines should give a developer the proper knowledge to generate and commit reputable contributions
* `ISSUES`
  * @macandchief Things like this are highly important design considerations.  I've personally owned 5+ devices that self-destructed this way - remember the RAZR flip phones?
* `ISSUE TAGS`
  * A great tool for project managers to use is a leverage a `good first issue` tag on issues placed that are either trivial or require a limited scope of familiarity with the nature of the project
* `README`
  * @ZeekHuge Expressing the direction and intent of a project at the highest levels is greatly appreciated.  It takes a decent chunk of time and planning to establish such project-management-level material, but external contributors may take this information and run with it - often contributing content that is within scope and merit to the overall project.

TsvetanUsunov, 2018-05-18:
@jcstaudt I add you as collaborator to this repository

jcstaudt, 2018-05-31:
I constructed a CONTRIBUTING.md document at the root directory of this repository.

I will need some help from Olimex, particularly with the ``doc/web/dev_roadmap.md`` and ``doc/web/dev_wishlist.md`` files.  I'm new here, so it's not my call to say what is coming down the line or what is most needed.

@TsvetanUsunov et al, can you please review this CONTRIBUTING guide and let me know what you think?  Can we spend a little time developing a wishlist/roadmap?

Closed 2024-06-07.

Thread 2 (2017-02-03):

Where are the files for the case design?

whmountains, 2017-02-03:
This is an awesome laptop!!!

I can't find the CAD models for the case.  Did I just miss them or are they closed source? 😱 Or maybe you just used an off-the-shelf model.

Thanks

DanKoloff, 2017-02-14:
We didn't design the plastic enclosure. We used a ready case. Made the PCB design after we have acquired the case in order to fit.

jcstaudt, 2018-06-16:
Closing the loop:

A 3D-printed case design has been developed by [Fork Sand, Inc.](https://github.com/forksand) and the design files may be found [here](https://github.com/forksand/olimex-teres-case).  I have added a link within this repo's [FAQ](https://github.com/OLIMEX/DIY-LAPTOP/blob/master/doc/web/res_faq.md) page.

DanKoloff, 2019-01-28:
I can no longer find the files. Seems like Fork Sand, Inc. either deleted or set the repo private. Re-opening.

DanKoloff, 2019-01-28:
I guess they migrated to other platform and now the files are located here: https://code.forksand.com/forksand/olimex-teres-case

Closed 2019-01-31.

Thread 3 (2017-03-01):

3d models for the PCB components

felipesanches, 2017-03-01:
KICAD has a very nice 3d rendering feature.

I opened the PCB1 on the 3d viewer and only the bare PCB and half-a-dozen components (such as an 0805 part with L1 reference) got rendered in the scene.

I don't think this is very important. But certainly it would be neat to have the 3D models sorted out. Maybe it is just a matter of setting it up correctly as most 3d models are already provided in libraries just like parts symbols and footprints.

TsvetanUsunov, 2017-03-01:
we have no experience with 3D, all our kiCAD libraries are on github https://github.com/OLIMEX/KiCAD
anyone who can help is welcome

felipesanches, 2017-03-01:
If contributors are welcome, then it would be wiser to keep the issue open. There's no reason to feel ashamed of an open issue. :-) Please consider reopening this, in the hope of geting more visibility for potential contributors.

felipesanches, 2017-03-01:
Thanks :-D

jcstaudt, 2018-05-18:
If anyone can help locate some resources for me, I can probably become more useful.  I'm starting to wrap my head around [OpenSCAD](https://www.openscad.org).

felipesanches, 2018-05-18:
openscad is absolutely great! I love it!

DanKoloff, 2018-05-21:
KiCad has 3D view, it would probably be easier and more accessible if each component gets updated with height via KiCad. Our components and libraries are located here: https://github.com/OLIMEX/KiCAD (also there is again a funny answer to the re-occurring question "Why there are no 3D drawings for the components?") in the description :)

jcstaudt, 2018-05-31:
Please pardon the potentially ignorant question but, how are the [Olimex KiKad resources](https://github.com/OLIMEX/KiCAD) different than the [vanilla KiCad](https://kicad.github.io/footprints) ones or the resources recently [released by Digikey](https://github.com/digikey/digikey-kicad-library)?  Are any of them now redundant that can be re-referenced to point to upstream variants?

bkmgit, 2019-12-30:
The KiCAD 3D viewer seems to work ok. An exported image is attached. Exporting an STP file seems less reliable in KiCAD 5.1.5-1
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

bkmgit, 2019-12-30:
Possible solutions are
https://hackaday.com/2015/11/08/kicad-script-hack-for-better-mechanical-cad-export/#more-177033
https://github.com/marmni/FreeCAD-PCB

Closed 2020-07-14.

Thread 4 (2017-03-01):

RTL8723BS requires non-free firmware

felipesanches, 2017-03-01:
Please consider replacing the wifi chipset by something that does not require proprietary firmware.

One good candidate for that could be the chipset used on the tpe-n150usb dongle: https://www.thinkpenguin.com/gnu-linux/penguin-wireless-n-usb-adapter-gnu-linux-tpe-n150usb

This chipset also requires firmware, but the corresponding source code was released as free software and is available at:
https://github.com/qca/open-ath9k-htc-firmware

More info on the Atheros AR7010/AR9280/AR9287 chipset can be found here:
https://wikidevi.com/wiki/Atheros_AR7010

TsvetanUsunov, 2017-03-01:
we have Artheros WiFi https://www.olimex.com/Products/USB-Modules/MOD-WIFI-AR9271-ANT/ for these who want to have completely blob free WiFi
unfortunately this module is quite old and big we can't put it inside laptop space

felipesanches, 2017-03-01:
Is it only an issue with the component sizes / available PCB area? Or are there other known issues? Maybe cost of the parts? Or parts availability in stock?

Even though there are USB dongles such as the one you pointed out and the TPE-N150USB that I mentioned earlier, I can see how adopting a freedom-respecting chipset on the motherboard itself could be very positive for this project, given it's being advertised as a fully-free hardware design. Full software freedom would be a *very nice* badge to showcase.

It would be good to investigate the issue a bit deeper to make sure this is really something impossible to acchieve with the current laptop plastic case.

felipesanches, 2017-03-09:
@TsvetanUsunov Could you (or perhaps some of your co-workers) provide further insight into this issue?

jcstaudt, 2018-05-31:
If we may continue this discussion and determine the best path forward, I will dedicate some time to assist its integration.

In addition, I created a "[RISC-V Laptop Working Group](https://www.loomio.org/g/THbo1zmX)" that I believe Olimex would be a fantastic fit for.

felipesanches, 2020-07-14:
why was this closed?

Closed 2020-07-14.

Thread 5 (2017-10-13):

Kernel changes - Mainline

andir, 2017-10-13:
First let me say, that I am grateful that people are working on this! Thank you!

Are you planning on contributing the changes to the kernel sources into the upstream linux kernel?

In my opinion (and that of many others) a product that only runs on a (soon) ancient linux kernel with a custom patchset is not a product we would buy.

In the past there have been way too many ARM board (that look nice at a good price point) but lack proper mainline support…

bibor, 2017-10-27:
The sunxi comunity is working on A64 mainline support.
The results are documented here (not always up-to date)https://linux-sunxi.org/Linux_mainlining_effort https://linux-sunxi.org/A64

Closed 2024-06-07.

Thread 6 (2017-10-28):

Build problems

khumarahn, 2017-10-28:
Hi, I tried to follow the linux building instructions in https://github.com/OLIMEX/DIY-LAPTOP/blob/master/SOFTWARE/A64-TERES/scripts/readme.md

I am not an expert at all. I have a few comments/questions:
* I guess that "Getting source code" section needs to be updated with the new location. Why is arm trusted firmware not mirrored in olimex repo?
* There is a requirement for `gcc-4.7-arm-linux-gnueabihf` toolchain, seems that it is only used in `u_boot-new`. Can somebody comment? Why armhf when everything else is aarch64? Why gcc-4.7? It does not seem to be needed upstream.
* `./build_uboot.sh` fails with
```./build_uboot.sh: line 29: ../sunxi-pack-tools/bin/update_boot0: No such file or directory```
I updated sunxi-pack-tools with the newer https://github.com/longsleep/sunxi-pack-tools, and it worked.

(EDIT):
* I had to install dos2unix https://waterlan.home.xs4all.nl/dos2unix.html, and also fakeroot, which weren't mentioned in the instructions. Though, I am not on ubuntu where they may come by default.

khumarahn, 2017-10-28:
Also,
* `./make_simpleimage.sh teres.img 1000 ./linux-a64-3.10.104-1.tar.xz` fails with
```
Creating teres image teres.img of size 1000 MiB ...
Using Kernel from ./linux-a64-3.10.104-1.tar.xz ...
20+0 records in
20+0 records out
20971520 bytes (21 MB, 20 MiB) copied, 0.0116583 s, 1.8 GB/s
48+0 records in                   
48+0 records out                   
49152 bytes (49 kB, 48 KiB) copied, 0.00029765 s, 165 MB/s
960+0 records in                                   
960+0 records out                              
983040 bytes (983 kB, 960 KiB) copied, 0.002399 s, 410 MB/s
50+0 records in                           
50+0 records out                                          
52428800 bytes (52 MB, 50 MiB) copied, 0.0262658 s, 2.0 GB/s
mkfs.fat 4.0 (2016-05-06)                         
Total number of sectors (102400) not a multiple of sectors per track (63)!
Add mtools_skip_check=1 to your .mtoolsrc file to skip this test
```

Here I am not sure what's going on. Is it safe to add mtools_skip_check=1 to .mtoolsrc?

hehopmajieh, 2017-10-29:
Hi Alexey, since we need 32 bit SPL/boot0 to get u-boot running/64 bit
compiler exeeds 32k size of boot0/, we must use 32 bit compiler.
Did you clone proper sunxi-pack-tools branch /this branch is forked from
longsleep, as working/.

Best regards,
Dimitar

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

khumarahn, 2017-10-29:
ok, thanks for the explanation about the 32 bit compiler. I hope that the requirement for the old gcc-4.7 can be lifted at some point.

I didn't quite understand you about sunxi-pack-tools. I couldn't make work the version from here https://github.com/OLIMEX/DIY-LAPTOP/tree/master/SOFTWARE/A64-TERES/sunxi-pack-tools
(error is in the first post). Maybe it needs to be updated with a newer one from longsleep's repo?

hehopmajieh, 2017-10-29:
Hi Alexey,
i agree with you, i also finding some typos in this instructions. I will do
my best to fix it tomorrow.
Thank you.

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

khumarahn, 2017-11-05:
Something else missing in the instructions:
```
# cat etc/udev/hwdb.d/teres_kbd.hwdb
evdev:input:b0003v15BAp003C*
  KEYBOARD_KEY_7006f=brightnessdown
  KEYBOARD_KEY_70070=brightnessup
```

hehopmajieh, 2017-11-06:
Readme is up to date, and i think everything should work as expected.

Closed 2017-11-06.

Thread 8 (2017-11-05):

keyboard and touchpad

khumarahn, 2017-11-05:
This is an issue to track a couple of problems with the keyboard and touchpad. I'll attempt to do something about them, but it may take long time before I start, and then I am new to all this.

* Touchpad is very sensitive. Too sensitive to my taste, there are many accidental clicks. Need to understand how to decrease the sensitivity or disable tap clicks. I could not find a configurable option with xinput. Is there an AVR chip to program?
* When the lid is closed, it presses on the keyboard, for instance on the Delete key. I had a file deleted this way, lots of screenshots taken, many escapes pressed, etc.  It was really confusing. How to temporarily disable the keyboard (and the touchpad, just in case) when the lid is closed?

khumarahn, 2017-11-07:
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
this is what the screen looks like if I carry the laptop to work

khumarahn, 2017-11-07:
I wrote a script for handling keyboard and display when the lid is closed/open. It turned out to be very simple. One has to have the `acpid` daemon running, and create two files:
`/etc/acpi/events/lid`:
```
event=button/lid.*
action=/etc/acpi/actions/lid.sh %e
```
and `/etc/acpi/actions/lid.sh`:
```
#/bin/bash

# TODO: what if the laptop boots with the lid closed?
# probably, the keyboard and the lcd would be still enabled

# "open" or "close"
action="${@: -1}"

# usb bus id of keyboard+touchpad device
kbd="1-1.4"

# power for the lcd
lcd=/sys/class/backlight/lcd0/bl_power
lcd_off=1
lcd_on=0

case "${action}" in
    open)
        logger -t "acpi_lid:" "lid open, enabling usb ${kbd}, turning on lcd"
        echo "${kbd}" > /sys/bus/usb/drivers/usb/bind
        echo "${lcd_on}" > "${lcd}"
        ;;
    close)
        logger -t "acpi_lid:" "lid closed, disabling usb ${kbd}, turning off lcd"
        echo "${kbd}" > /sys/bus/usb/drivers/usb/unbind
        echo "${lcd_off}" > "${lcd}"
        ;;
    *)
        logger -t "acpi_lid:" "unknown option ${action}"
        ;;
esac
```
It seems to work. It depends onthe usb bus id of the keyboard+touchpad and the lcd brightness control location. Are these likely to change with time? Am I doing this right?

khumarahn, 2017-11-07:
For some reason, the `Fn+F1` button sends the acpi poweroff signal instead of the sleep signal. Can this be changed?

khumarahn, 2017-11-09:
Teres 1 slowly becomes *actually* usable for me. I plan to share my configs, or the system image, when I am done.

I need to figure out how to configure the touchpad. It is way to sensitive to taps, and very hard to scroll with two fingers. Is there any documentation for noobs here?

For example, what are the parameters
```
bool tap_enabled = true;

#define DRAGTIME 8

#define MINPRESS 3
#define min_CLICK_MS CLICK_MS-MINPRESS
uint8_t presstime;
#define DRAG_ENABLED 1
#define TP_LOCK	20
#define TAP_ENABLED 1

uint8_t time_zero;
uint8_t time_one;
uint8_t time_two;
uint8_t time_pressed;
#define PRETAP	3
#define CLICK_MS 8
uint8_t MR_B_REQ = 0;
#define TOUCH_TO	8
uint16_t startposX=0xffff;
uint16_t startposY=0xffff;
bool itsDone = false;
```
in https://github.com/OLIMEX/DIY-LAPTOP/blob/master/SOFTWARE/A64-TERES/TERES-KBD-RELEASE/TERES-HID/KeyboardMouse.h ?

And how to compile the keyboard files and flash them?

DanKoloff, 2017-11-09:
About compilation: https://github.com/d3v1c3nv11/TERES-KBD-RELEASE.git

On how to update: https://github.com/d3v1c3nv11/TERES-KBD-RELEASE/tree/master/upgrade

khumarahn, 2017-11-09:
Thanks, I will look at it.

I only now realized the the battery charge "percent" is reported as `/sys/class/power_supply/battery/capacity`. Maybe, this works better than the crude linear voltage approximation? I wrote another patch for lxde lxpanel: https://pastebin.com/AVwXS40n

Not yet clear how to estimate time to discharge, but this is secondary.

Lxde works mostly very well... the only problem I have is the volume regulation with alsa (I didn't install pulseaudio).

d3v1c3nv11, 2017-11-10:
About Sleep button:
add this line
```bash
KEYBOARD_KEY_70074=suspend
```
at the end of file /etc/udev/hwdb.d/teres_kbd.hwdb

khumarahn, 2017-11-10:
I am not on ubuntu... Is it possible to make the updater static?
```
# ./update
./hid_bootloader_cli: error while loading shared libraries: libusb-0.1.so.4: cannot open shared object file: No such file or directory
```
I will install the avr toolchain and build the updater in any case, but this takes time.

khumarahn, 2017-11-10:
The problem with libusb-0.1.so-4 was solved by installation of libusb-compat, the upgrade went through.

khumarahn, 2017-11-13:
I updated the keyboard firmware and made some test. With `acpi_listen` I get:
```
Fn+f1: nothing
Fn+f2: nothing
Fn+f3: nothing
Fn+f4: button/volumedown VOLDN 00000080 00000000 K
Fn+f5: button/volumeup VOLUP 00000080 00000000 K
Fn+f6: button/mute MUTE 00000080 00000000 K
Fn+f7: video/brightnessdown BRTDN 00000087 00000000 K
Fn+f8: video/brightnessup BRTUP 00000086 00000000 K
Fn+f9: nothing
Fn+f10: nothing
Fn+f11: nothing
Fn+f12: nothing
```

In X, with `xev`, I see:
```
Fn+f1: keycode 200 (keysym 0x1008ffb0, XF86TouchpadOn)
Fn+f2: keycode 186 (keysym 0x1008ff79, XF86ScrollDown)
Fn+f3: keycode 248 (keysym 0x0, NoSymbol)
Fn+f4: keycode 122 (keysym 0x1008ff11, XF86AudioLowerVolume)
Fn+f5: keycode 123 (keysym 0x1008ff13, XF86AudioRaiseVolume)
Fn+f6: keycode 121 (keysym 0x1008ff12, XF86AudioMute)
Fn+f7: keycode 232 (keysym 0x1008ff03, XF86MonBrightnessDown)
Fn+f8: keycode 233 (keysym 0x1008ff02, XF86MonBrightnessUp)
Fn+f9: keycode 133 (keysym 0xfe08, ISO_Next_Group)
Fn+f10: keycode 127 (keysym 0xff13, Pause)
Fn+f11: keycode 118 (keysym 0xff63, Insert)
```

It seems, f4-f12 are OK except maybe the `ISO_Next_Group` (what the hell is that!). F1-f3 may need some attention. I'd expect an acpi suspend event on f1, where there was an acpi shutdown event before. Also, the keycodes are strange.

d3v1c3nv11, 2017-11-13:
In our image keycodes reported by xev, evtest, etc., are result of codes generated by keyboard firmware as defined here [...ckickme...](https://github.com/d3v1c3nv11/TERES-KBD-RELEASE/blob/845a3a402929dd0c75d022a58aaac2c004191d55/TERES-HID/KeyboardMouse.h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), then is transcoded by hidkbd driver [...clickme...](https://github.com/OLIMEX/DIY-LAPTOP/blob/e10416c79304e478136b23271e14b708be277f6f/SOFTWARE/A64-TERES/linux-a64/drivers/hid/usbhid/usbkbd.c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) then changed by [...hwdb...](https://github.com/OLIMEX/DIY-LAPTOP/blob/e10416c79304e478136b23271e14b708be277f6f/SOFTWARE/A64-TERES/scripts/make_rootfs.sh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) to be reported to system right as labeled. You are free to change each of those elements to get the right codes for the linux distro you're using

Is this really an issue with our image and firmware? Should i consider it solved?

khumarahn, 2017-11-13:
Thanks for the explanation!

I don't know with what the issue is, and I did not look deep. I just checked Fn+f1 on the stock ubuntu, and it is just the same as above. There is no sleep event, and suspend does not happen.

I think the issue with the key mapping is not a big one, even though it would be good to do it properly. A bigger problem is the sensitivity of the touchpad. I would appreciate a hint here. I did not find any obvious clues and did not have time to investigate.

khumarahn, 2017-11-13:
Oooops, sorry. I forgot to change the hwdb, my bad. There is an acpi suspend event on stock ubuntu now! I will investigate.

khumarahn, 2017-11-13:
Suspend works! I make a mistake in `KEYBOARD_KEY_70071=suspend`. Suspend issue is closed, many thanks!

d3v1c3nv11, 2017-11-13:
Finally!

khumarahn, 2017-11-13:
Hey, I think it is early to close this issue. It was created for two things: sensitivity of the touchpad and that the lid presses of the keyboard. It is totally great to get the suspend button work, but it wasn't the focus.

Closed 2024-06-07.

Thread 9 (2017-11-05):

battery charge indication

khumarahn, 2017-11-05:
I can't make the battery indication work with lxde or lxqt. It seems that it is because some standard files like `charge_now` and `charge_full` or `energy_now` and `energy_full` are missing in the device folder:
```
# ls -al /sys/class/power_supply/battery
total 0
drwxr-xr-x 3 root root    0 Nov  5 14:37 .
drwxr-xr-x 5 root root    0 Nov  5 14:37 ..
-r--r--r-- 1 root root 4096 Nov  5 14:38 capacity
-r--r--r-- 1 root root 4096 Nov  5 14:48 current_now
lrwxrwxrwx 1 root root    0 Nov  5 14:48 device -> ../../../axp81x-supplyer.47
-r--r--r-- 1 root root 4096 Nov  5 14:48 energy_full_design
-r--r--r-- 1 root root 4096 Nov  5 14:48 health
-r--r--r-- 1 root root 4096 Nov  5 14:38 model_name
-r--r--r-- 1 root root 4096 Nov  5 14:48 online
drwxr-xr-x 2 root root    0 Nov  5 14:48 power
-r--r--r-- 1 root root 4096 Nov  5 14:48 present
-r--r--r-- 1 root root 4096 Nov  5 14:38 status
lrwxrwxrwx 1 root root    0 Nov  5 14:38 subsystem -> ../../../../../../class/power_supply
-r--r--r-- 1 root root 4096 Nov  5 14:48 technology
-r--r--r-- 1 root root 4096 Nov  5 14:48 temp
-r--r--r-- 1 root root 4096 Nov  5 14:38 type
-rw-r--r-- 1 root root 4096 Nov  5 14:37 uevent
-r--r--r-- 1 root root 4096 Nov  5 14:48 voltage_max_design
-r--r--r-- 1 root root 4096 Nov  5 14:48 voltage_min_design
-r--r--r-- 1 root root 4096 Nov  5 14:48 voltage_now
```
There is instead `voltage_now`, `voltage_min_design` and `voltage_max_design`, and probably the battery indication can be patched to use them. Or maybe one can make the `energy` or `charge` files appear?

P.S.:
The same applies to the popular cbatticon, this is how it determines remaining capacity:
```
    if (use_charge == FALSE) {
        return get_sysattr_double (battery_path, "energy_now", capacity);
    } else {
        return get_sysattr_double (battery_path, "charge_now", capacity);
    }
```
https://github.com/valr/cbatticon/blob/46bdd031c28d8d41807e4803880874cff2fa9cd5/cbatticon.c#L582

khumarahn, 2017-11-05:
One of the values is like 1000 times less than it should be:
```
$ cat /sys/class/power_supply/battery/voltage_min_design
3300
$ cat /sys/class/power_supply/battery/voltage_max_design
4200000
$ cat /sys/class/power_supply/battery/voltage_now
3973000
```

khumarahn, 2017-11-06:
a dirty patch for lxpanel-0.9.3: https://pastebin.com/YniYSytz. It shows the battery percentage, but does not estimate the remaining time. Partly because the battery capacity is reported as 7mWh, while I'd expect it to be 30Wh:
```
$ cat /sys/class/power_supply/battery/energy_full_design
7000
```

I see that the reported voltage changes a lot suddenly on adapter plug in/out, by like 0.2V, this is strange.

binutzu, 2018-02-10:
Just flashed image version 1.2 and while setting/tidying up the desktop again i noticed that the Mate battery charge monitoring plugin also does not recognize the  battery - says running on AC. At the same time the "default" power manager (icon) seems to work ok: on  battery + percentage.

On a different matter, there should be another way to update the system with the officially supported distro beside wiping the content of emmc...

DanKoloff, 2018-02-12:
@binutzu We are working on a better way of update.

macandchief, 2018-03-31:
May I ask: How many hours do you get approximately with the battery e.g. on 1/3 surfing, 1/3 video and 1/3 text editing?

khumarahn, 2018-03-31:
I'd say around 9 hours. Maybe shorter or longer.

binutzu, 2018-07-23:
@DanKoloff I updated my system to Ubuntu Bionic as described in posts of Olimex Forum for Teres-Laptop. It worked fine but the only thing remaining is the battery level display.
You mentioned that Olimex provides a custom charge indicator - is that a Mate Desktop specific one and is the source code available? I did not find it in this repo.

jcstaudt, 2018-12-28:
These are the only battery charge indicators I see, and believe them to be irrelevant. I have only ever seen ``battery_charge.bmp`` when the laptop is plugged in while powered down. I am using Olimex's OEM image v1.4:

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

The tooltip states ``System is running on AC power. No battery present`` when plugged in and when not plugged in. (This statement has often confused me on many laptops as the power input is post-DC-conversion, but that's quite out-of-scope of this issue :smiley:)

Closed 2024-06-07.

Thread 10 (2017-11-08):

teres1-ledctrl consumes 100% cpu

khumarahn, 2017-11-08:
I have another issue to submit.

Occasionally, `teres1-ledctrl` starts to consume 100% of the cpu (one core), and the leds do not work. I observed it on both the original ubuntu, and on my gentoo, where I compiled it myself.

This happens rarely, I have no idea what triggers it.

A screenshot:
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

khumarahn, 2017-11-08:
upd: turning the keyboard on and off as in #8 does trigger this. However, I do not remember how it happened with the stock ubuntu - I wasn't experimenting with anything this low level.

d3v1c3nv11, 2017-11-13:
This script fixed the issue:
```bash
#!/bin/sh
set -e

if [ "$2" = "suspend" ] || [ "$2" = "hybrid-sleep" ]; then
    case "$1" in
        pre) systemctl stop teres1-ledctrl ;;
        post) systemctl start teres1-ledctrl ;;
    esac
fi
```
create it with
```bash
sudo nano /lib/systemd/system-sleep/teres-services
```

hehopmajieh, 2017-11-13:
I think this is a workaround , not fix.  @d3v1c3nv11  take a look
[here](https://github.com/OLIMEX/DIY-LAPTOP/blob/master/SOFTWARE/A64-TERES/teres1-ledctrl/teres1-ledctrl.c#L82)
This will die in horrible pain, if file descriptor is missing. Simple file check will do the trick.

khumarahn, 2017-11-13:
Yeap, it is not the right fix. I have a script (in #8) which unbinds the keyboard device when the lid is closed. There I also had to add a restart of the led control service.

Also, I do not use systemd. I would happily use it, but it requires a recent kernel. Our 3.10 is just too old, while older versions of systemd require to many patches to compile. Luckily for me, gentoo comes with openrc. It is a very good init system, but it does not manage suspend.

khumarahn, 2017-11-22:
#13

d3v1c3nv11, 2017-11-22:
Merged.

khumarahn, 2017-11-22:
ok, thank you. It seems, this is done.

Closed 2017-11-22.

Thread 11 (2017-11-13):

keyboard and touchpad not working after firmware update

binutzu, 2017-11-13:
Hello,
I was following the issues logged here and was interested in the kbd/touchpad related ones. I applied the firmware update procedure with the latest firmware.tar.gz from github.
After executing the update command and pressing Fn+Tux+Esc, the update program completed but my keyboard and touchpad don't work anymore since then.
I tried reboot, shutdown and boot, plug the charging cable but no improvement.

#Using the debug console on audio jack i tried to upload an older firmware but the program  #fails with the message "Unable to find rebootor". It seems to me that it tries to open some USB device and does not find it. lsusb shows the following:
Bus 002 Device 001: ID 1d6b:0001 Linux Foundation 1.1 root hub
Bus 001 Device 003: ID 1908:2311 GEMBIRD
Bus 001 Device 002: ID 05e3:0608 Genesys Logic, Inc. Hub
Bus 001 Device 001: ID 1d6b:0002 Linux Foundation 2.0 root hub
Bus 004 Device 001: ID 1d6b:0001 Linux Foundation 1.1 root hub
Bus 003 Device 001: ID 1d6b:0002 Linux Foundation 2.0 root hub

What does lsusb show on a working TERES-I ?
Is there some way to repair the kbd and touchpad on my device?
Thanks!

khumarahn, 2017-11-13:
Hi, the update worked fine for me, and this is my lsusb.
```
# lsusb
Bus 002 Device 001: ID 1d6b:0001 Linux Foundation 1.1 root hub
Bus 001 Device 005: ID 15ba:003c Olimex Ltd.
Bus 001 Device 003: ID 1908:2311 GEMBIRD
Bus 001 Device 009: ID 05e3:0727 Genesys Logic, Inc. microSD Reader/Writer
Bus 001 Device 002: ID 05e3:0608 Genesys Logic, Inc. Hub
Bus 001 Device 001: ID 1d6b:0002 Linux Foundation 2.0 root hub
Bus 004 Device 001: ID 1d6b:0001 Linux Foundation 1.1 root hub
Bus 003 Device 001: ID 1d6b:0002 Linux Foundation 2.0 root hub
```
`15ba:003c` is the keyboard+touchpad

binutzu, 2017-11-14:
Right. I am missing that device.
Removing the battery does not help. Actually it seems that the laptop will not boot properly only with the power plug and with battery disconnected.

I checked the cables to&from the KBD PCB and look ok.
Interestingly when i disconect the cable leading to the main board no event is shown in dmesg. But when i inserted it back there was something:

[  441.966575] usb 1-1.4: new full-speed USB device number 12 using sunxi-ehci
[  442.080086] hid-generic 0003:15BA:003B.0007: hiddev0: USB HID v1.11 Device [HID 15ba:003b] on usb-sunxi-ehci-1.4/input0
[  444.601118] usb 1-1.4: USB disconnect, device number 12

For some reason the KBD controller disconnects immediately. What would cause this behaviour? There is no chance to do an update.

I would appreaciate any hints on how can i reprogram it or further troubleshoot.

DanKoloff, 2017-11-14:
@binutzu Are all ribbon cables properly connected as shown in the manual? Before and after inserting the ribbon cable the lock latches should be closed to keep the cable in place.

d3v1c3nv11, 2017-11-14:
```bash
hid-generic 0003:15BA:003B.0007: hiddev0: USB HID v1.11 Device [HID 15ba:003b] on usb-sunxi-ehci-1.4/input0
```
This is the bootloader and is active just for 2 seconds after power up. Try to make upgrade procedure using external usb keyboard. but instead of pressing Fn+Tux+esc keys you must restart PCB5 - disconnect from main board and insert it back.

binutzu, 2017-11-14:
Thanks for the feedback. Here a photo with the upper part of the cabling around the KBD PCB.
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

Now I use TERES with an external USB keyboard. I will try the command line options of  hid_bootloader_cli.c

d3v1c3nv11, 2017-11-14:
To start bootloader you can reset board shorting C5.

binutzu, 2017-11-14:
Great! i have again keyboard and touchpad!

Thanks all for support. I made a change to hid_bootloader_cli so that it does not try to hard reset the device by default. This way it waits for the bootloader and has time (2s?) to write the firmware.

hid_bootloader_cli should have an option to avoid the hard-reboot and just wait

khumarahn, 2017-11-14:
Off topic: @binutzu teach me how to use the audio jack console? What is the simplest setup, what to buy, what is the pinout on the audio jack?

binutzu, 2017-11-14:
@khumarahn Actually for me it was easier than i tought. I had a USB Serial TTL adapter with 3 wires and an old audio jack with 3 contacts. Using a multimeter I found what was the ground wire on each cable  and connected those. Then i was left with two other wires which means 2 combinations. I was lucky and got it right from the beginning. Otherwise just try the other combination.
You will get the bootloader messages by default and if debug=on in uEnv.txt then also the kernel console is available where you have tty access.

I found this very useful: [https://forum.pine64.org/showthread.php?tid=5026](url)

Using this serial console i could see that xenial, arch and even slackware miniroot is booting on the laptop and is a matter of loading automatically the modules + some config to have it run nicely

Closed 2017-11-14.

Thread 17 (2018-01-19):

Network Manager warnings about ipv6

xcko, 2018-01-19:
I've noticed these warning lines in the journal, default ubuntu mate image. Default Network manager config.
`NetworkManager: <warn> device (wlan0): The kernel does not support extended IFA_FLAGS needed by NM for IPv6 private addresses`
followed by:
`NetworkManager: <error> platform-linux: do-add-ipv6-address[4: <ipv6 addr>]: failure 22 (Invalid argument)`

Closed 2024-06-07.

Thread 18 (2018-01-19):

Different keyboard and mouse pin?

petterreinholdtsen, 2018-01-19:
I love the idea behind the laptop, and am really contemplating to get one.  But I would very much like to have a keyboard with a mouse pin, not a touchpad, similar to the keyboards on Thinkpads. A good keyboard with slight curves on each key (for the finger to feel if it is at the center or the edges of the keys), and a physical effect on the finger when a key press is registered is vital to be able to type very quickly.  The current keyboard is very flat, as far as I could tell from testing a friends version.  What is needed to use a different keyboard with a mouse pin, and replace the mousepad with mouse buttons?  Are there alternative keyboard suppliers available?

petterreinholdtsen, 2018-01-19:
Right.  I hope something come out of it.  I've been using Thinkpad X keyboards for the last 15-20 years, and my typing speed with such keyboard is above 300 presses per minute.  Moving to a keyboard with less finger feedback lead to a significant loss of typing speed.  As the keyboard is the main link between my head and my computer, it is quite important to me.  I prefer a mouse pin over a touchpad as the touchpad is located where I rest my hands, causing spurious mouse movement and clicks, and a mouse pin is quicker to operate when I move between windows. :)

Do you have links to the people working 3D printed plastics?  I would be perfectly willing to buy a loose thinkpad keyboard (for example a replacement part for a thinkpad X42/X230/whatnot), and use it instead of the default keyboard, but I lack the skill set required to make such modified enclosure myself.

jcstaudt, 2018-10-02:
A 3D-printed case design has been developed by [Fork Sand, Inc.](https://github.com/forksand) and the design files may be found [here](https://github.com/forksand/olimex-teres-case). I have added a link within this repo's [FAQ page](https://github.com/OLIMEX/DIY-LAPTOP/blob/master/doc/web/res_faq.md).

The OEM injection-molded plastic enclosure makes it too costly to modify in such a way that allows for configurable input devices, so a modification of the 3D-printed lower assembly would be required. There is a learning curve involved with tools such as [FreeCAD](https://forum.freecadweb.org/viewforum.php?f=36), but with some dedication and support from the community, it shouldn't be too laborious to carve out a place for a loose ThinkPad keyboard.

Closed 2018-10-02.

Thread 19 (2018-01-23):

3D files for the plastic case

abdberkana, 2018-01-23:
Hi all, can some one point me to the link where to download the 3D files of the enclosure ?

DanKoloff, 2018-01-23:
We don't have such. Refer to this blog post about the plastics: https://olimex.wordpress.com/2018/01/19/teres-i-diy-open-source-hardware-modular-hackers-laptop-update/

Quote from it: "As you all know we suck at mechanical engineering and we had to find all plastic parts from Chinese laptop supplier. Some people asked about possible 3D designs of the laptop case but we are not capable to do this..."

jcstaudt, 2018-06-16:
Closing the loop:

A 3D-printed case design has been developed by [Fork Sand, Inc.](https://github.com/forksand) and the design files may be found [here](https://github.com/forksand/olimex-teres-case).  I have added a link within this repo's [FAQ](https://github.com/OLIMEX/DIY-LAPTOP/blob/master/doc/web/res_faq.md) page.

Closed 2018-01-23.

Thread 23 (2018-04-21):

Post assembly feedback

utilum, 2018-04-21:
Way to go, guys!

Thank you so much. I've helped a 10 years old put the machine together in a couple of afternoons, it was a fun learning experience for both of us. And it _works as is_ !

The one glitch: No response from the touchpad. The connections are now under the glued battery, so not easily accessible. What do you suggest?

In retrospect, is it really necessary to glue the battery in? What to do if/when it needs replaing?

Keep up the good work.

DanKoloff, 2018-04-23:
Probably one of the connectors around TERES-PCB5-KEYBOARD or TERES-PCB3-TOUCH-BTN got loose.

Remove the battery carefully. Get rid of old double-sided tape carefully - without puncturing or compromising the battery. After it is removed from the panel, clean both sides with some cloth and alcohol. Fix connectors (refer to the pictures about which side has to be up, check if they are fully inserted, etc). After everything seems according to the master plan, re-attach the battery - maybe apply new double sided tape (shouldn't be hard to find in local book store).

< In retrospect, is it really necessary to glue the battery in? What to do if/when it needs replaing?

Even in very expensive tablets and smartphones you can see tape or glue used. Sometimes it is the fastest and most secure way. While it is not pretty, it is cheap to replace. At least we couldn't think of another way to keep the battery firmly in place. We are always open to suggestions for improvement, of course. If you have any idea how to attach it let us know.

jcstaudt, 2018-04-25:
I constructed my own DIY laptop last year using several clustered SBCs. I used pieces of Velcro (or similar brand) adhesive strips, cut to the desired size, to secure the SBCs, batteries, USB power/data hub PCBs, etc.  The adhesive used on these strips is quite strong and comes in several "strength" grades.  I was even able to place some strips on the bottom of a few SBCs and carefully removed them later on without damaging the boards.

One thing to consider, though, is that certain brands or strength grades may be constructed of thicker material; you'll have to ensure they will still fit in the enclosure without bulging the case or straining any hardware.

utilum, 2018-04-25:
Thank you for the detailed response @DanKoloff, and the suggestion @jcstaudt , adhesive strips of Velcro or another brand are a great idea. I'll try that when I fix and post results here.

albjeremias, 2018-05-23:
awesomeness!!! :)) just assembled mine.. as feedback the hardest part was the monitor, this wifi cable was really hard to put in place... the touchpad is not working perfectly.. has some glitches.. all the rest is so awesome! thank you guys!

utilum, 2018-05-31:
Frankly, I have not gotten to doing it yet, but I'm content with the solid advice I already found here, and can close the ticket if you like.

jcstaudt, 2018-05-31:
Thank you for the update.  Best of luck with the mod!

Closed 2018-05-31.

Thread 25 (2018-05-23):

other distro, besides ubuntu

albjeremias, 2018-05-23:
Hi! is the laptop supporting other distros? maybe debian or archlinux? If I want to try something like that, what do I need to keep in mind to don't brick the hardware?

More specificall, how can I install archlinux on this laptop?
On https://archlinuxarm.org/ says olimex is supporting them!

DanKoloff, 2018-05-24:
There is an unofficial Gentoo image, check this forum thread: https://www.olimex.com/forum/index.php?topic=5966.0

If things go bad just download the official image to a micro SD card and boot from there.

jcstaudt, 2018-05-31:
FYI: The link I see from reading the thread is [here](https://github.com/khumarahn/teres1-gentoo).

jcstaudt, 2018-05-31:
I'll see what I can do to document supported OSes with TERES.  It's just slightly difficult for me to be super thorough because I don't actually own a TERES -- I just want to see it succeed.

albjeremias, 2018-05-31:
theres this:
 - https://wiki.debian.org/InstallingDebianOn/Olimex/Teres-I
 - https://archlinuxarm.org/about/downloads (ARMv8 AArch64 Multi-platform) might work...
 - https://github.com/khumarahn/teres1-gentoo

I downloaded the gentoo image.. burn it to a sd card.. and nothing happens... I dunno how-to install !
(I have experience installing linux in peepz computers on more than 100 probably...)

 - the olimex bios is weird.. is there a button to select where to boot from?

DanKoloff, 2018-05-31:
The Gentoo author has published instructions:

"
To install to MMC, replace the contents of your /dev/mmcblk0p1 and /dev/mmcblk0p2 with what is in the respective partitions in the image. Then edit /etc/fstab and /boot/uEnv.txt.
"

> the olimex bios is weird..

TERES-I is not a conventional x86 laptop. Its has an ARM chip inside and ARM architecture, not x86. The ARM architecture is more common for tablets and smartphones (and some netbooks like Chromebook); the x86 is more common for personal computers and bigger laptops. Because of the ARM architecture, TERES-I has no BIOS either (in the traditional sense of "BIOS").

The typical way of installing the operating system of TERES-I is via a micro SD card (there is a slot on the TERES-I). It generally goes like this:

1. Download the latest image provided by Olimex
2. Download it to a micro SD card (8GB or bigger)
3. Insert the card in the laptop and start the laptop, it would boot from the micro SD card
4. A command line would appear and you execute an install script, that would move the files from the card to the eMMC memory inside
5. Remove the card, so TERES-I can now boot from the eMMC memory

> is there a button to select where to boot from?

No. There is a pre-defined priority list of boot mediums (the board would attempt to boot from different places in specific order - if it can't boot from the top priority place it would try from the second, then the third, and so on).

khumarahn, 2018-05-31:
@albjeremias hi, there is no more detailed guide, sorry. This is on purpose: I did not mean to be too user friendly, because maintaining linux for teres still requires expertise.

If you are adventurous, here are approximate (untested) instructions. Run them only if you understand what is going on and that this may kill your cat. Assuming you boot from gentoo micro sd card, run
```
mkdir /mnt/mmc-boot
mkdir /mnt/mmc-root
mount /dev/mmcblk0p1 /mnt/mmc-boot
mount /dev/mmcblk0p2 /mnt/mmc-root

mkdir /mnt/sd-root
mount --bind / /mnt/sd-root

rsync -aAxXhH --delete /boot/ /mnt/mmc-boot
rsync -aAxXhH --delete /mnt/sd-root/ /mnt/mmc-root
```
Then edit `/mnt/mmc-boot/uEnv.txt` and `/mnt/mmc-root/etc/fstab` to point to `mmcblk0` instead of `mmcblk1`.

See also [install_emmc.sh](https://github.com/OLIMEX/DIY-LAPTOP/blob/master/SOFTWARE/A64-TERES/scripts/platform-scripts/install_emmc.sh) which is a part of the official installation. It does the same and more.

TsvetanUsunov, 2018-05-31:
@albjeremias please do not take it offenseve but the questions you ask show that you have no much experience with linux, in this case may be good idea to stay with ubuntu as it's most user friendly distro for beginners.
Gentoo require you to compile everything from sources and this may be a bit confusing for novices. Arch also has not so many packages available as Ubuntu, for instance you should compile KiCad from sources in Arch as if I remember correctly the KiCad team work on Ubuntu and their nightly builds are for Ubuntu.

albjeremias, 2018-05-31:
lol! :-1: dude, i use linux since 15yrs... since fedora... i used gentoo, debian, rasppi, etc.. etc... i have much experience... im just no familiar with this ARM stuffs... and I want gentoo because i bet that is way faster than stupid ubuntu, and i hate that ubuntu sold our soulds to amazon once.

jcstaudt, 2018-05-31:
If I can bring this thread back on topic please...

I don't understand the mentality of intentional limited documentation.  It is completely valid to not provide half-complete walkthroughs which contains so many gaps that the user to becomes confused and wastes tons of time, potentially losing data.  Bold warnings are generally acceptable if there is inherent risk in a step of the process.  However, unless the products are flying off the shelves faster than they can be restocked, there is certainly value in making the product more powerful, easier to use, and more reliable.  I have never experienced thoughtfully-written documentation as being a negative factor in my professional career.

If any of you find value in this, I am happy to provide a general guide to load OSes on eMMC, as well as a comprehensive example.  If this is the case, I would appreciate some direction as to not waste time using a useless example.

More frankly, what is the completion criteria of this issue?

albjeremias, 2018-06-28:
but i cant just boot some distro from the sd card?

DanKoloff, 2018-06-28:
There is an Armbian image too now. Armbian is friendlier for people outside of electronics. Check here: https://www.armbian.com/olimex-teres-a64/

sameer, 2018-10-17:
Has anyone tried to get archlinux running?

jcstaudt, 2018-12-28:
@sameer Not that I'm aware, but I'll keep an eye out until then.. and, of course, please report back if you hear of anything. It looks like there are Arch options for Olimex's sister products, but I'm sure this is not news to you: https://archlinuxarm.org/platforms

jcstaudt, 2018-12-28:
@albjeremias You definitely can. I finally got a Teres so I can be of more help now. Once you download/extract/copy a valid ``.img`` file containing a valid boot partition onto a uSD card, the Teres will look to boot off of the uSD card before eMMC. In this way, you can have a stack of imaged uSD cards handy (I coincidentally do right now!) and freely boot whatever you want. If you so desire to copy an image to the eMMC, you can do so using your own method or one of the provided scripts. This is one of the particularly pleasant aspects of ARM boards. :smiley:

These are the available Teres image torrents I currently seed. Am I missing any (apart from the laundry list of past Armbian releases)? I will create a wiki page describing the official/unofficial distros with associated torrent files. Will that be enough to satisfy this issue for now?

- Android (Android_teres_rev4.torrent)
- Armbian's latest Debian stretch xfce desktop
- Armbian's latest Ubuntu bionic xfce desktop
- @khumarahn's Gentoo lxde desktop: 20180926
- Olimex's Ubuntu (xenial/mate) releases: 20161117, 20171211, 20181220

jcstaudt, 2018-12-31:
Based on the decision from issue #32, I uploaded all known (by me personally) torrent files for the A64-TERES. I also created a README within SOFTWARE/A64-TERES describing the currently available operating system images, both Olimex-supported and third-party. Issues related to the Olimex-supported Teres images should be created within this repository, and any issues with third-party images should be submitted through their respective maintainers. Once an alternative OS is deemed production-ready for the Teres, I will be happy to link it (with disclaimers, obviously) accordingly. I think these commits satisfy the requirements for this issue, so I'm closing it. Feel free to open it again, with comment, if you disagree.

Closed 2018-12-31.

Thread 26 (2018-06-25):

Add design files for TERES-019-Camera

jcstaudt, 2018-06-25:
While writing some documentation, I noticed that the design files for **TERES-019-Camera** seem to be missing.  Are they available, and if so, can we get them incorporated?

DanKoloff, 2018-06-26:
It is a standard camera module that we purchase. The camera is not designed by Olimex. I have only one document available and I will upload it now.

jcstaudt, 2018-06-29:
That is what I thought, but it's good to ask. More info would be great if you have it. Otherwise, we can close the issue for now.

Closed 2018-10-02.

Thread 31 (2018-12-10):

TERES-PCB5-KEYBOARD: Use keyboard/mouse simultaneously

jcstaudt, 2018-12-10:
Users do not normally have to use the keyboard and mouse simultaneously during everyday computer use. However, this feature is extremely useful when performing tasks such as gaming. In a first-person shooter, for example, it is imperative that you are able to move and look around at the same time.

The TERES-PCB5-KEYBOARD keyboard and mouse devices function one at a time, as if the signals are mux'ed onto the same communication channel. I understand that the TERES-I isn't currently a gaming beast, but it would be highly useful in light gaming applications (such as Minetest, FreeDoom, etc) to use them together with OEM hardware.

An easy work-around is to simply use USB-connected peripherals, but again, it would be nice to use the OEM hardware when these peripherals are unavailable.

DanKoloff, 2018-12-11:
Good suggestions, a little more info about that: this is not a hardware or muxing limitation. This was done on purpose with usability considerations in mind - we found it hard to use the keyboard freely when the touchpad is enabled - the palms were triggering the touchpad accidentally.

This can be improved by software means in the firmware of the keyboard/touchpad board.

jcstaudt, 2018-12-12:
That's a very good point, and a good decision to do that for better general usability. It sounds like the capacitance cap is not active, where the trackpad goes dead when a threshold is exceeded. I'd have to do some research on the AVR processor to see if this is possible. Additionally, I did notice that there is a dedicated key on the keyboard to enable/disable the trackpad. Maybe this could be used to toggle simultaneous operability instead? However, this modification would then not provide the standard/expected functionality of that key and would be better suited as an optional patch as to not confuse people.

Closed 2024-06-07.

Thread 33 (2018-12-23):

Touch-Screen 11.6'' for Pen-Input

rzerres, 2018-12-23:
###  Touch-Input Device
It would be very beneficial if the project could deliver a touch-input panel.
Enrich the portefolio to optionaly substitute the default 11.6'' LCD display, maybe combined with a digital pen or smart pen.

### Handwriting an pen driven notes
Combining the touch-input panel with an application like "Xournal" would make the TERES a low cost alternative for all students searching for a mobile notebook.

It would allow them, to take handwritten notes in any lectures and postprocess their notes as needed.
Because of the the small dimensions, its minimal weight and the low power consumption,  the device would last the day, be handy and applicable for mobile usage.

### Possible Hardware

Please take the appended list as a possibel starting point. I'm not in any way coupled with the hardware manufactures.

-  touch panel

https://yunlea.en.alibaba.com/product/60246567445-801466862/10_1_10_4_12_1_15_15_6_17_17_3_18_5_19_21_5_23_23_6_27_32_inch_Waterproof_usb_capacitive_touch_screen.htm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

- active pen
https://www.storexppen.com/list/6.html

jcstaudt, 2019-01-01:
I think it is a good idea. Many people consider the Teres a highly-portable notebook great for travel (myself included) and touch-screen capabilities could enhance that use-case. (The next obvious step supporting this concept would be to create a 2-in-1 enclosure, but that would involve researching and pursuing all new injection-molded plastics. Maybe re-purposing an existing platform would be more cost-effective.)

Let's consider the existing plastic enclosure. The current LCD cable runs along the left-hand-side metal hinge. The LCD shown in the link appears to have two ribbon cables more toward the center. Compatibilities/etc aside, modification to the case would be required for proper fitment. However, this could potentially remedy an issue https://github.com/OLIMEX/DIY-LAPTOP/issues/1#issuecomment-377710495. If not using the stock plastic enclosure, it would simply require screw/cabling clearance verification in the 3D-printed design files.

Either way, if this proposal is accepted, there's the process of designing another AV controller board and enabling device compatibility.

rzerres, 2019-01-01:
I dought that we can step forward in progressing the design or enhancement of the given enclosure, if  the project hasn't  defined, how to realize the touch functionality.

- [ ]  add-on  solution
use a given qualtiy proved product to put on top of the actualy used LCD
(compare this to the given starting point top comment of  #33)

- [ ]  new device
try to find a new product that combines touch and LCD functionality (e.g as used in Microsoft Surface ®)

Closed 2024-06-07.

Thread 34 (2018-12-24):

Don't power on the board when connected to power supply

jcstaudt, 2018-12-24:
Currently, if the laptop is off, then connected to mains power using the barrel jack, it will power itself on. This is not ideal when, for example, the battery is very low at the end of the day and I wish to charge it overnight. I feel that the laptop should only power on (from off, not standby or hibernation) when the power button is pressed manually or if a restart command was issued.

khumarahn, 2018-12-24:
I can't reproduce. My Teres does not turn on on power plug. But it does turn the display on for a few seconds, showing that it is charging.

jcstaudt, 2019-02-13:
This issue is now referenced as a known issue in Olimex' WordPress blog, dated 13 February 2019: [TERES-I Open Source Hardware Laptop has new experimental Armbian Mainline Linux image for download](https://olimex.wordpress.com/2019/02/13/teres-i-open-source-hardware-laptop-has-new-experimental-armbian-mainline-linux-image-for-download/)

> Automatically turns on upon applying power via the PWR_JACK, we need time to patch mainline uboot

khumarahn, 2019-02-13:
I can reproduce this now, with the new u-boot.

Closed 2024-06-07.

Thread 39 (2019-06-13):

installing os from sd card

Fre-d-die, 2019-06-13:
Hi, I am having booting from a sd card, I have burned khumarahns image of gentoo onto an sd card however when rebooting instead of booting the sd card ubuntu mate starts up as normal, could this be because the sd card is 128 gb? is their a way I can manually choose a boot device?

jcstaudt, 2019-06-28:
When a micro SD card is inserted, the device takes boot priority over onboard storage. However if uboot doesn't locate all expected resources and panics, it'll fall back to onboard storage as a secondary option. Although there are a few variables here, I suspect that the Gentoo image was simply not successfully imaged onto the card.

* What tool/method did you use to image the micro SD card?
* Will the device boot after imaging the card again or using a different card with the same image?
* What model is the 128GB card you used? Does an image file other than the Gentoo image boot properly using that card?

I'm on travel and cannot test khumarahn's image at the moment, but perhaps I can help more directly once I have access to my equipment again.

khumarahn, 2019-06-28:
Hi, @Fre-d-die created two parallel issues. We sorted it out here:
https://github.com/khumarahn/teres1-gentoo/issues/3

Closed 2019-06-28.

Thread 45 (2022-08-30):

Update the design with more efficient CPU

Kreyren, 2022-08-30:
### Is your feature request related to a problem? Please describe.**
<!--A clear and concise description of what the problem is. Ex. I'm always frustrated when [...]-->

Got Pinebook Pro recently and i hate that:
1. I don't have KiCAD files for it to easily add functionality that i need e.g. fingerprint, hotswappable batteries, etc..
2. The RK3399 has spectre and meltdown vulnerabilities and is allegedly using proprietary blobs

### Describe the solution you'd like
<!--A clear and concise description of what you want to happen.-->

My end goal is better, equal or tolerably worse alternative to Pinebook Pro that doesn't have security issues and proprietary blobs.

Can we do better with TERES-1? It's currently using the A64 which is too slow for me

### Describe alternatives you've considered
<!--A clear and concise description of any alternative solutions or features you've considered.-->

The IMX8QM-TUKHLA seems to be a good alternative to RK3399 with allegedly no blobs, but it's still not released and it seems that it's development stalled likely due to blobs..

The next best option seems to be the iMX8QuadPlus which compared to RK3399 has one less Cortex-A72, but according to https://olimex.wordpress.com/2022/01/25/imx8mplus-som-is-alive-and-boots there is an issue with supply

### Additional context
<!--Add any other context or screenshots about the feature request here.-->

I have experience with hardware and software development and am willing to help if you can do the brainstorm on what CPU should be used.

TsvetanUsunov, 2022-08-31:
IMX8QM processor alone is EUR 200 this is automotive grade processor and you are not correct, there is co-processor running non free firmware inside it, which takes care of all initializations of memory, etc. NXP provide SDK so you can write your own firmware, but do not have public the sources of the firmware which are used to ship the processors, which may need quite of work.

For IMX8MQP NXP is working to mainline it, so IMO is more suitable for FOSS OSHW product.

Kreyren, 2023-01-20:
@TsvetanUsunov In hypothetical scenario where we have the documentation needed to know how to make a board for it:

What about SnapDragon Mobile 845?
The PostmarketOS wiki says that it's mainlined[https://wiki.postmarketos.org/index.php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]

Kreyren, 2023-02-28:
Found RK3588S for which the datasheet is widely available and seems like a good option considering budget and resource efficiency.

In terms of mainlining, the work seems to be ongoing in 6.1

Kreyren, 2023-04-22:
Relevant: https://github.com/starfive-tech/VisionFive2/issues/39

Kreyren, 2024-06-11:
Considered `won't fix`

Closed 2024-06-07.

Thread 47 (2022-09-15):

Stage releases for this repository to make 3rd party fabrication easier

Kreyren, 2022-09-15:
This project is pain to fabricate through 3rd party thus proposing changes to address it.

### Expected behavior

Throw the repository at PCB manufacturers/fabricators to get quote for fabrication to choose the best one as fast and painlessly as possible

### Current behavior

When i sent this repository to a PCB Manufacturer then gross majority of them gets confused as it seems that their sales team doesn't know how to use GitHub and KiCAD and ask for additional informations that can be easily fetched from KiCAD.

### Proposed solution
GitHub has "Releases" So stage the following files in there per released version:
* Gerber Data - Ideally with recommended configuration for the fabrication
* Stack-up layout - Where should each layer go as F.Cu .. B.Cu is not easily understandable to some
* NC Drill data
* PCB specifics such as recommended and/or warning for incompatible:
    * materials
        * Thickness of material (for layers)
    * Glass Transition Temperature
    * Drawings
    * Minimal/maximal hole sizes
    * Surface Finish
    * Via process
    * Thickness of the copper traces
    * etc..
* Assembly drawings (for polarity and part orientation)[1][2]
   * Stack-up
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

^ These can and should be automated through Continuous Integration and Delivery management, recommending LaminarCI or WoodpeckerCI

### Additional info

Some manufacturers such as PCBWay do not need assembly drawings, because they have WebUI for the user to specify those which is usually not an option for local manufacturers.

Proposing to make the specifications into a range instead of fixed recommendations to enable optimization of the cost e.g. some manufacturers might prefer different layer heights to provide more economical offer.

Some manufacturers provide interface alike https://www.pcbway.com/project/shareproject that then allow the community to get very economical fabrications of an open-source projects by allowing multiple people to put on order and then make X amount of boards and redistribute it across those community members.. consider using that?

### TODO
* [ ] Resolve https://github.com/OLIMEX/DIY-LAPTOP/pull/48 which blocks further development on this issue
* [ ] Update schematics
* [ ] DIY-LAPTOP/HARDWARE/A64-TERES/TERES-PCB1-A64-MAIN/Rev.C/TERES_PCB1-A64-MAIN_Rev.C.pro
    * [ ] Drawing
    * [ ] Recommended Glass transition Temperature
    * [ ] Recommended surface finish(es)
    * [ ] Add Stack-up
    * [ ] Recommended minimal and maximal thickness of copper traces

### Relevants
1. interactive KiCAD BOM - https://hackaday.com/2018/09/04/interactive-kicad-boms-make-hand-assembly-a-breeze/
2. How to make fabricating drawings in KiCAD 5.0+ https://www.youtube.com/watch?v=9p5sAwXWMno

TsvetanUsunov, 2022-09-15:
why would you send repository with all unnecessary information to PCB producer? They only need drill files and gerbers which are generated from the KiCad with one single mouse click? They layer stackup info in in KiCad DRC rules.
How to use KiCad is essential if one wants to use and contribute.

TsvetanUsunov, 2022-09-15:
> btw. I am happy to passively work on this over time if you like the proposed solution

this would be great, as this is lot of work and I do not see when our developers will have free time to complete

Kreyren, 2022-09-15:
> why would you send repository with all unnecessary information to PCB producer? hey only need drill files and gerbers which are generated from the KiCad with one single mouse click? They layer stackup info in in KiCad DRC rules. -- @TsvetanUsunov (https://github.com/OLIMEX/DIY-LAPTOP/issues/47#issuecomment-1247652831)

To ease the 3rd party fabrication and enable people who are not familiar with KiCAD or are unable to use it to be able to get the printed boards to use the notebook.

Because currently many manufacturers don't use KiCAD and as you said only expect Gerbers and Drill files which is not my experience in practice as they need much more as explained in "Proposed solution" which currently makes the board very likely to be mis-fabricated so by providing the releases and indicating that the configuration in those should work for everyone then that makes the project significantly more available.

For example currently i have to pay ~8000 CZK (~327 EUR) for the kit sourcing the parts locally and being able to fabricate the PCBs locally i can get down by around 60% of the cost while also getting more people to get the notebook as fabricating at least 5 PCBs of the mainboard cuts the cost on nearly half of the current 80 EUR (where was this even fabricated it for it to cost this much? it's 8 layer A64 board.. the A64 costs like 4 EUR..).

>  How to use KiCad is essential if one wants to use and contribute. -- @TsvetanUsunov (https://github.com/OLIMEX/DIY-LAPTOP/issues/47#issuecomment-1247652831)

I disagree people don't need KiCAD to assemble the notebook and use it and as regular user won't ever have to use it because they are going to get very economical rapairs locally if needs be.. So to me making a set of releases that can be just thrown at the manufacturer by an inexperienced user seems as a good thing.

> this would be great, as this is lot of work and I do not see when our developers will have free time to complete -- @TsvetanUsunov (https://github.com/OLIMEX/DIY-LAPTOP/issues/47#issuecomment-1247652831)

Will update the issue with TODO list and will passively address them in my free time then, if you don't mind then i would prefer to use GNU Guile (recommended language for tasks alike by the GNU project) for the CI and using LaminarCI.

The language is based on lisp 1.0 (scheme) so it's generally very easy to learn by semi-experienced developer under few hours (minutes?).

TsvetanUsunov, 2022-09-16:
Although I like your enthusiasm I would first suggest you to manufacture and build one Laptop and then do anything on this repo.
From what I see  you lack basic knowledge for PCBs and manufacturing it's wrong to RP something you still do not understand. We will not merge such PRs.
For instance why change the KiCAD version without anything inside changed? What will happen when KiCAD moves from 6.X to 6.X+1 new PR? What is the purpose new versions of KiCAD always will open the old projects. This is non necessary nor it have sense.
Removing the PCB material FR4 without knowing what is it wrong.
Trying to translate few words from Bulgarian to English (google will translate pretty decent) but breaking the format and names which is already linked in many documents and pages on our web is also not acceptable.
My advice is: build everything from zero and once you do this successfully do the changes you think are necessary so we can review and merge. Do not guess what is this and that and if it's important or not, if we put it there it's important, if you do  not understand what is it is not ground to remove it :)

Kreyren, 2022-09-16:
Disclaimer: i don't mean to be rude, i want to clarify on the chosen approach.

> Although I like your enthusiasm I would first suggest you to manufacture and build one Laptop and then do anything on this repo.
> From what I see you lack basic knowledge for PCBs and manufacturing it's wrong to RP something you still do not understand. We will not merge such PRs. -- @TsvetanUsunov (https://github.com/OLIMEX/DIY-LAPTOP/issues/47#issuecomment-1248950654)

I develop and fabricate PCBs on semi-regulate basis monthly mostly focusing on single, ~4 layers and ~8 layer PCBs and fabrication by hand, but i recognize that i lack practical experience with +10 layers.

> For instance why change the KiCAD version without anything inside changed? -- @TsvetanUsunov (https://github.com/OLIMEX/DIY-LAPTOP/issues/47#issuecomment-1248950654)

Because files were last changed 4 years ago and since then kicad changed file format and many things inside it so to me it makes sense to update it now.

> What will happen when KiCAD moves from 6.X to 6.X+1 new PR?  -- @TsvetanUsunov (https://github.com/OLIMEX/DIY-LAPTOP/issues/47#issuecomment-1248950654)

In ideal world run tests and merge a new version automatically though CI/CD which is practically impossible to do for KICAD without functional electronic computer assisted development (fECAD) such as the solution used for modeling through OpenSCAD and libFive since the current python scripting backend is immature and not sustainable in production environment.

I am aware of the issue which is why I created https://github.com/OLIMEX/DIY-LAPTOP/pull/49 to standardize the development environment so that 6.0.7 would be used until it's decided that it should be updated again.

FWIW KiCAD people said that they put a lot of effort into making sure that KICAD translates the files from one version to another on version update, but i need to do more research into that until i can in clear mind propose it.

> What is the purpose new versions of KiCAD always will open the old projects. This is non necessary nor it have sense. -- @TsvetanUsunov (https://github.com/OLIMEX/DIY-LAPTOP/issues/47#issuecomment-1248950654)

The new version can't open the schematics files without issues and they have to be manually to correctly convert the schematics to pcb designer as they need minor changes for the symbols.

> Removing the PCB material FR4 without knowing what is it wrong. -- @TsvetanUsunov (https://github.com/OLIMEX/DIY-LAPTOP/issues/47#issuecomment-1248950654)

I removed it from BOM, because from my experience it's no longer being included in it as it's cost varies per manufacturer which seems to be the same reasoning to why KiCAD is not including it in the generated BOM.. In general manufacturers just want to know the list of components that they will put on the board.

>  Trying to translate few words from Bulgarian to English (google will translate pretty decent) but breaking the format and names which is already linked in many documents and pages on our web is also not acceptable. -- @TsvetanUsunov (https://github.com/OLIMEX/DIY-LAPTOP/issues/47#issuecomment-1248950654)

Open-source the website so that the changes can be made with the merge request then? Or adjust the wording so that it refers to the file considering that it now has a documentation and technical drawing?

> My advice is: build everything from zero and once you do this successfully do the changes you think are necessary so we can review and merge. Do not guess what is this and that and if it's important or not, if we put it there it's important, if you do not understand what is it is not ground to remove it :) -- @TsvetanUsunov (https://github.com/OLIMEX/DIY-LAPTOP/issues/47#issuecomment-1248950654)

I don't touch things i don't understand.. if that happened i would highlight the area in schematics/pcb designer and asked for clarification, what i did is added technical drawings and documentation and then launched two kicads and compared layer to layer to make sure the version update didn't corrupt anything.

Btw. Did you miss that i closed https://github.com/OLIMEX/DIY-LAPTOP/pull/48 (that had corruption due to the schematic issues) and replaced it with https://github.com/OLIMEX/DIY-LAPTOP/pull/50 ?

Kreyren, 2022-09-16:
Talking about the issue with kicad version management with kicad people the proposed approach was to make a CI/CD implementation that generates gerbers and schematics from two different versions and then runs diffoscope on them to capture any irregularities across versions which i was told is sustainable in production, but would need to research it more.

Was told that version should be updated every 2 weeks ish which is +- what i do in my development as well.

Closed 2022-09-16.

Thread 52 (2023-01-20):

Expand the BOOT partition size on the official image to fix upgrades

Kreyren, 2023-01-20:
[The official image for teres-1](https://ftp.olimex.com/Allwinner_Images/A64-Teres/linux/xenial-teres-bspkernel-20190121_144941_EET-1_hdmi_out_v1_5.zip) is unable to successfully upgrade distribution release, because the BOOT partition has 50MB where invoking `$ do-release-upgrade` requires additional ~14MB and doing GUI `update-manager` will demand additional ~48.14MB and upgrading from bionic seems to need around 150MB.

### Steps to Reproduce
1. Boot the image
2. Do:
* `# apt update && apt upgrade -y && apt dist-upgrade -y && reboot`
* `do-release-upgrade`

### Proposal
Expand the boot partition from 50MB -> 200MB

---

CC @TsvetanUsunov

DanKoloff, 2023-01-20:
https://github.com/OLIMEX/DIY-LAPTOP/blob/master/doc/web/sw_updating-os.md

"Important! Currently the image upgrade is possible only via a clean install (via SD card). Running "sudo apt upgrade" would lead to unexpected results and problems! Avoid running "apt upgrade"!"

Kreyren, 2023-01-20:
> master/doc/web/sw_updating-os.md -- @DanKoloff (https://github.com/OLIMEX/DIY-LAPTOP/issues/52#issuecomment-1398246623)

I understood from that i am supposed to install that OS on the emmc and then do the upgrade from there no?

Btw. The steps on https://github.com/OLIMEX/DIY-LAPTOP/blob/master/doc/web/sw_fresh-os.md using `install_emmc.sh` failed for me as well so i downloaded the image on the OS booted from the SDcard and then flashed it on internal storage using `dd`

DanKoloff, 2023-01-20:
> I understood from that i am supposed to install that OS on the emmc and then do the upgrade from there no?

Seriously, how ambiguous can "Avoid running "apt upgrade"!" be?

Kreyren, 2023-01-21:
@DanKoloff I was talking about upgrading the OS as described in https://github.com/OLIMEX/DIY-LAPTOP/blob/master/doc/web/sw_fresh-os.md

1. The `install_emmc.sh` doesn't work for me reliably
2. Doing `dd` from booted SDCard to internal storage results in corrupted image

So the only way that works for me now is to just use the SDCard and upgrade the OS which requires ~300MB of boot partition to succeed (up until jammy that breaks the system)

In relation to https://github.com/OLIMEX/DIY-LAPTOP/blob/master/doc/web/sw_fresh-os.md?rgh-link-date=2023-01-20T12%3A12%3A08Z the image has very outdated kernel, OS and non-functional web browser along side majority of packages so `apt update` doesn't really cut it

Kreyren, 2024-06-11:
Considered `won't fix`

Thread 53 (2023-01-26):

Liberate WIFI/BLE module

Kreyren, 2023-01-26:
The mainboard revision C of teres a64 is using a proprietary rtlwifi/rt18723bs, this issue is created to work on a solution for it to be replaced with a libre alternative.

Kreyren, 2023-03-02:
CC @TsvetanUsunov can you confirm that the mainboard is designed to have swappable atheron chip which is why it has the blue daughter board on atm and if so which one? I want to make an entry about this on the wiki.

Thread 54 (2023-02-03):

Bigger Battery

Kreyren, 2023-02-03:
The current 9K mAh battery ain't enough for me is there any compatible battery that i can just put in the system assuming a 3D printed case to handle mounting?

Kreyren, 2024-06-11:
Discussed on IRC, was told that the X-Power 803 doesn't support higher battery capacity in a sane way.

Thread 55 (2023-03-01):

Proposals for the next design

Kreyren, 2023-03-01:
Context: I am working on a custom magnesium case for the teres's next chip and i want to ideally just adjust the daughter boards instead of having to maintain fork of the mainboard + making it less painful to add features such as RFID, hot-swappable batteries etc..

---

The idea of these proposals is to make the current design easily expandable and changable while reducing the need to rework PCBs for e.g. use of different case and devices.

### Standalone right-side I/O

Currently the mainboard and right side I/O are the same board:

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

Instead proposing to split the right side I/O as it's case-specific feature that limits modularity.

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

### Adjust SBC designs

Adjust the SBC designs so that they can be a drop-in replacement in teres without affecting the functionality of the SBC itself.

in real world example: deprecate the TERES-PCB1-A64 and rework OlinuXino-A64 (not suggesting to do that now, but for future chips)

### Add edge connector for UEXT

Currently to add devices, one has to scrape solder mask and solder wires to the mainboard's bus so instead proposing to add UEXT connector so that devices can be easily added in.

The idea is that device's PCBs can then be connected to UEXT and ancored inside the case with e.g. hot glue, double-sided tape or adjusting the case design.

---

So overall the design should imho be just a chipless case that people can choose which chip they want to have in it.

---

CC @TsvetanUsunov

TsvetanUsunov, 2024-06-07:
I already think for re-design but not in the same plastic case, stay tuned it will pop on our blog :)

Kreyren, 2024-06-11:
> I already think for re-design but not in the same plastic case, stay tuned it will pop on our blog :) -- @TsvetanUsunov

Can you please consider making it some functional SOM so that we can have 2~4 layer platform PCBs that can be easily fabricated by the users including locally with the SOM  being less than 50x50mm (bcs 3rd party will make 8 layer PCBs that are very economical e.g. 2 EUR for 5 that way) which can just have the CPU RAM and ideally serial console so that it can work independently to slot into the body to easily change the chips? It would make the design a lot more usable.

Closed 2024-06-07.

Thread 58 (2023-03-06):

Add an ability to poweron/wake up the system

Kreyren, 2023-03-06:
Currently i always have to get up and turn the system on or open the lid when i want to access it remotely -> Proposing to implement some way to power it on/wake up to manage this scenario

The RTL8723BS has a `WLAN to wake-up HOST` on pin 13 which is connected to A64's WL-WAKE-AP E13 pin, but i have no idea how to use it and neither does the sunxi community

---

Alternative approach: PiKVM-like implementation that can access the system remotely? https://invidious.esmailelbob.xyz/watch?v=BpKcqLcApTQ

---

CC @TsvetanUsunov halp

haraldg, 2023-04-10:
Isn't that something that needs to be handled in the driver for RTL8723BS?

Kreyren, 2023-07-16:
> Isn't that something that needs to be handled in the driver for RTL8723BS? -- @haraldg

Apparently so but i wasn't able to get it to work so far thus why am i annoying tsvetan :D

haraldg, 2023-07-16:
I think there are basically 3 possible reasons why it doesn't work:
1. The RTL8723BS driver doesn't actually support this yet.
2. The driver would work, but the chip gets powered down too far and can not properly process it.
3. The WL-WAKE-AP E13 pin actually gets triggered but the system fails to wake up.

(1) is clearly a driver problem and can only be addressed there. (2) might be a problem with the HW design or the devicetree file. (3) might be a problem with the devicetree file or some sunxi specific code. It might also need some support from https://github.com/crust-firmware/crust to get this to work.

Obviously the first step forward is to figure out, which of the above it is.

Closed 2024-06-07.

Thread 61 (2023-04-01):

Add resettable fuse for 5VDC3A on the Vin

Kreyren, 2023-04-01:
Referencing https://www.olimex.com/forum/index.php?topic=7782.0

Proposing to integrate **resettable fuse** for 5VDC3A on the Vin

Options: https://eu.mouser.com/c/circuit-protection/thermistors/resettable-fuses-pptc/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

So that if the user overvoltages the laptop it won't damage anything

DanKoloff, 2023-04-03:
I don't we would place fuse by default. We have provided the option to add fuse, user can cut between the pads of FUSE2 and add such there. Refer to the picture below

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

Kreyren, 2023-04-03:
@DanKoloff i think you missunderstod, the proposed fuse (e.g. https://eu.mouser.com/ProductDetail/onsemi/NIV6350MT2TXG?qs=xZ%2FP%252Ba9zWqa2xJAD3VNXxQ%3D%3D) seems to be a 0.659 EUR integrated circuit component that automatically cuts power when it goes past the 5VDC3A otherwise it lets power go through, the reset it handled by the fuse itself without the need of user doing anything.

FUSE2 is not an option without developing a daughter board on top of it as the pining is not compatible:

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

Kreyren, 2023-09-22:
@DanKoloff Did you read the reply?

xloem, 2024-06-07:
Noting it sounds like olimex does not want to add a fuse, but aren’t there 2-lead resettable fuses? What is the advantage of an entire integrated chip?

It would be super nice to have a fuse there by default, prevent board damage.

TsvetanUsunov, 2024-06-07:
I do wonder why additional fuse is necessary if the power is supplied with Adapter which already have all the protections?

xloem, 2024-06-07:
Some of us prefer to power the laptop with DC. https://linux-sunxi.org/Olimex_Teres-A64#Cut_the_power_cable
I saw the same topic somewhere else on cutting the power cable, not certain where.

khumarahn, 2024-06-07:
I cannot use the stock power adapter for teres: it only fits the European power socket, it is bulky, and I travel quite a lot. I use instead a usb cable and charge from various usb chargers.

I never had any problems with this, but I don't think that it is safe to rely on protections of the power adapter.

Kreyren, 2024-06-11:
> Some of us prefer to power the laptop with DC. https://linux-sunxi.org/Olimex_Teres-A64#Cut_the_power_cable I saw the same topic somewhere else on cutting the power cable, not certain where. -- @xloem (https://github.com/OLIMEX/DIY-LAPTOP/issues/61#issuecomment-2154824652)

It's me who wrote that there as i basically charge the laptop from any kind of power source that i can find.. e.g. i often splice the cables together with WAGO connectors to charge in the car, friend's phone, escooter or even stuff like disassmbling street light and connecting aligator clips to the power there to charge it (.. when really desperate and the situation needs it..)

Afaik other teres users do the same just usually not as extreme e.g. charging from a portable solar panel is apparently very common which afaik has an increased risk for spikes in voltage/current.

also as said in https://github.com/OLIMEX/DIY-LAPTOP/issues/67 the stock adapter is useless shit.

FWIW also currently working on a standard to get a screwable connectors e.g.  YC8 (https://www.youtube.com/watch?v=stdiyrQk3VU) to deprecate the need for WAGOs in my teres development, but i am struggling to figure out how to make them water-proof and non-annoying to use.

Kreyren, 2024-06-11:
Additionally: Not completed and moved in https://git.dotya.ml/KREYLIMEX/TERES/issues/23

Closed 2023-04-03.

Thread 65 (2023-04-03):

Re-consider the use of eMMC Modules

Kreyren, 2023-04-03:
### Context

a while ago i proposed this to tsvetan to use the eMMC modules commonly used by hobby-oriented companies to make their emmc's swappable without the need of soldering such as:

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

afaiu he didn't like the idea bcs OLIMEX's consumers are mostly from the industrial sector where such use is likely to cause issues with data transfer due to e.g. vibration

### Proposal

Consider adjusting the pinning on the teres to make it possible for the user to unsolder the eMMC and add a pre-designed daughter board on it's place that would enable the swappable emmc without soldering on demand that way.

Kreyren, 2024-06-11:
Judging by https://www.olimex.com/Products/SOM/NXP-iMX8/iMX8MP-SOM-EVB-IND/ it appears implemented.

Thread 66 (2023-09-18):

Provide the firmware for RTL8723BS in the repository

Kreyren, 2023-09-18:
The current design is dependent on that file to get the WiFi and BLE to work

DanKoloff, 2023-10-03:
I don't think we have it. I think it has Realtek firmware and the firmware sources probably are not open source. Drivers should be available tho.

Kreyren, 2023-10-03:
@DanKoloff There seems to be sources for the driver, but i wasn't able to figure out if it's open-source or not e.g. https://github.com/anthonywong/rtl8723bs

Additionally it's in [linux-firmware](https://git.kernel.org/pub/scm/linux/kernel/git/firmware/linux-firmware.git) so at very least i would at least provide a text file pointing out where to find it.

Kreyren, 2023-10-03:
Actually it seems to be there in https://github.com/torvalds/linux/tree/cbf3a2cb156a2c911d8f38d8247814b4c07f49a2/drivers/staging/rtl8723bs and under GPLv2.. i try to mess with it..

Kreyren, 2023-10-03:
oh i seem to already have this running on my experimental NixOS build so yes it seems that the driver if open-source and mainlined

Closed 2023-10-03.

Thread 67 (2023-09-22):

Won't charge anymore after extensive daily use

Kreyren, 2023-09-22:
I've been using my teres every day since i got it and now i have to angle the charging port in weird ways for it to have contact and charge..

The issue is only on the male side so i just cut the cable and spliced a new connector with WAGO, but it's still pretty annoying..

Proposing for the next version to use more robust one

DanKoloff, 2023-09-25:
We also replace these connectors on the test computers from time to time. They indeed start to expire after around 1000 times plugging and unplugging.

Kreyren, 2023-09-26:
> We also replace these connectors on the test computers from time to time. They indeed start to expire after around 1000 times plugging and unplugging. -- @DanKoloff (https://github.com/OLIMEX/DIY-LAPTOP/issues/67#issuecomment-1733634230)

So USB-C next? Or is there any more rugged connector you can recommend? (making a new PCB for teres so brainstorm would help)

xloem, 2024-06-01:
I use SAE 12v and IDE 12/5v.

I think with regard to ruggedness the key is to figure out how to get stress to load the casing rather than solder joints or contacts.

Kreyren, 2024-06-11:
Considered `won't fix`

Closed 2024-06-07.

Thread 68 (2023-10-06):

Fastboot?

Kreyren, 2023-10-06:
Reading through the docs it seems that the A64 should be capable of Fastboot mode, but there doesn't seem to be any way to enter this mode on teres?

The fastboot is expected to be used to flash things directly in the eMMC.

CC @DanKoloff

DanKoloff, 2023-10-09:
Not sure if Linux has good support for fastboot at all. I think it is some Android thing that maybe isn't well supported in Linux at all.

Kreyren, 2023-10-10:
> Not sure if Linux has good support for fastboot at all. I think it is some Android thing that maybe isn't well supported in Linux at all. -- @DanKoloff (https://github.com/OLIMEX/DIY-LAPTOP/issues/68)

it's a communication protocol not some android thing.. android ppl just use it often..

Linux is it's bootloader level thing, see https://gitlab.com/pine64-android/brandy/blob/master/u-boot-2014.07/usb_sunxi/usb_fastboot.c and https://www.mail-archive.com/linux-sunxi@googlegroups.com/msg18696.html and uboot implementation https://github.com/u-boot/u-boot/blob/d9bb6d779b69c2548891e568e5e2a23e1b7eedaa/cmd/fastboot.c#L60

also https://linux-sunxi.org/Fastboot

The general practice is that there is a physical button on the board that is held down (teres has a convinient hole at the back of the chasis that is not used) and then connecting an USB to get in fastboot mode or `fastboot usb 0` from uboot cmdline (assuming that it's compiled in)

Alternatively there is also https://linux-sunxi.org/U-Boot/USB_Mass_Storage to get write access to the eMMC in theory

Kreyren, 2023-10-11:
Did some research in this and thanks to #linux-sunxi:

A64 has 3 known ways to get write access to the emmc:
1. Proprietary FEL protocol that is used as a last resort in case the device is hard bricked and should be avoided otherwise, it can be accessed through the FEI pin on the chip which is non-interrupt
2. Fastboot which can be used by compiling that in u-boot with an option `CONFIG_USB_MUSB_GADGET=y`
3. UMS which can be also compiled in u-boot with at least `CMD_USB_MASS_STORAGE=y`

the sunxi wiki also mentions USB 2.0 OTG port that teres doesn't seem to have implemented in it's DTS with a declaration alike:

```
&usb_otg {
	dr_mode = "host";
	status = "okay";
};
```

Additionally the daughter board that this port is routed into should probably have a thicker trace for the USB5V and be labeled correctly as USB5VOTG

Closed 2024-06-07.

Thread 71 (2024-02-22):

[REQUEST] Open-Source the list of compatible DRAM modules for the A64

Kreyren, 2024-02-22:
Referencing: https://git.dotya.ml/KREYLIMEX/Teres/issues/12

The OLIMEX OlinuXino-A64's schematics have a note:

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

Requesting to open-source this list to make mainboard adjustments easier.

Kreyren, 2024-06-11:
> what do you mean by open source this list? -- @TsvetanUsunov (https://github.com/OLIMEX/DIY-LAPTOP/issues/71#issuecomment-2154728034)

pineppl said that allwinner provides them with a list of modules that the manufacturer tested and has useful notes for, so that when people are manufacturing the design themselves to be able to pick the available module or be able to do 3GB RAM + for custom A64-based designs e.g. i wanted to have a A64 SOM to make a PCBs for a 3D printer.

> changing the DDR usually includes tuning of the DRAM controller parameters, if you want you can experiment with any other DDRs just have to run tests and see the optimal parameters which to load to the DRAM controller, the memories are not so easy to exchange like the resistors -- @TsvetanUsunov (https://github.com/OLIMEX/DIY-LAPTOP/issues/71#issuecomment-2154728034)

It would require making some kind of management to be able to easily change the module as the pin layout and routing often changes, if you have any relevant data on the subject it might help some users who were modding the design.

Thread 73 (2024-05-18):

FEL doesn't work

Kreyren, 2024-05-18:
It's not possible to enter [FEL](https://linux-sunxi.org/FEL) through holding **RESET1** button and the powering up with the USB cable connected to the USB-OTG.

Using the UBOOT1 button seems to prevent the u-boot phase and might be in FEL, but it doesn't get detected by sunxi-tools or in dmesg

Kreyren, 2024-05-19:
Seems that it doesn't even let me in FEL when requested from uboot:

```
-Boot SPL 2024.01-armbian (Feb 09 2024 - 18:59:43 +0000)
DRAM: 2048 MiB
Trying to boot from MMC1
NOTICE:  BL31: v2.9(debug):armbian
NOTICE:  BL31: Built : 18:58:03, Feb  9 2024
NOTICE:  BL31: Detected Allwinner A64/H64/R18 SoC (1689)
NOTICE:  BL31: Found U-Boot DTB at 0x20a4700, model: Olimex A64 Teres-I
INFO:    ARM GICv2 driver initialized
INFO:    Configuring SPC Controller
INFO:    PMIC: Probing AXP803 on RSB
INFO:    PMIC: aldo1 voltage: 2.800V
INFO:    PMIC: dcdc1 voltage: 3.300V
INFO:    PMIC: dcdc5 voltage: 1.500V
INFO:    PMIC: dcdc6 voltage: 1.100V
INFO:    PMIC: dldo1 voltage: 3.300V
INFO:    PMIC: dldo2 voltage: 2.500V
INFO:    PMIC: dldo3 voltage: 1.200V
INFO:    PMIC: dldo4 voltage: 3.300V
INFO:    PMIC: fldo1 voltage: 1.200V
INFO:    PMIC: Enabling DC SW
INFO:    BL31: Platform setup done
INFO:    BL31: Initializing runtime services
INFO:    BL31: cortex_a53: CPU workaround for 843419 was applied
INFO:    BL31: cortex_a53: CPU workaround for 855873 was applied
INFO:    BL31: cortex_a53: CPU workaround for 1530924 was applied
INFO:    PSCI: Suspend is available via SCPI
INFO:    BL31: Preparing for EL3 exit to normal world
INFO:    Entry point address = 0x4a000000
INFO:    SPSR = 0x3c9
ns16550_serial serial@1c28000: pinctrl_select_state_full: uclass_get_device_by_phandle_id: err=-19

U-Boot 2024.01-armbian (Feb 09 2024 - 18:59:43 +0000) Allwinner Technology

CPU:   Allwinner A64 (SUN50I)
Model: Olimex A64 Teres-I
DRAM:  2 GiB
Core:  74 devices, 24 uclasses, devicetree: separate
WDT:   Not starting watchdog@1c20ca0
MMC:   mmc@1c0f000: 0, mmc@1c10000: 2, mmc@1c11000: 1
Loading Environment from FAT... Unable to use mmc 0:1...
In:    serial,usbkbd
Out:   serial,vidconsole
Err:   serial,vidconsole
Net:   No ethernet found.
230454 bytes read in 12 ms (18.3 MiB/s)
starting USB...
Bus usb@1c1b000: USB EHCI 1.00
scanning bus usb@1c1b000 for devices... 4 USB Device(s) found
       scanning usb for storage devices... 0 Storage Device(s) found
Autoboot in 1 seconds, press <Space> to stop
=> go 0x10000
## Starting application at 0x00010000 ...
"Synchronous Abort" handler, esr 0x02000000
elr: ffffffff8c0bf004 lr : 000000004a00dbb8 (reloc)
elr: 0000000000010004 lr : 00000000bdf5ebb8
x0 : 0000000000000001 x1 : 00000000b9f41238
x2 : 00000000b9f41238 x3 : 0000000001c28000
x4 : 0000000000000000 x5 : 0000000000000004
x6 : 00000000bdfe0e50 x7 : 0000000000001558
x8 : 0000000000000010 x9 : 0000000000000008
x10: 0000000000000001 x11: 0000000000000001
x12: 0000000000000010 x13: 00000000be1ff3c8
x14: 0000000000000008 x15: 0000000000000000
x16: 0000000000010000 x17: 0000000000000004
x18: 00000000b9f30d90 x19: 00000000b9f41238
x20: 0000000000010000 x21: 0000000000000002
x22: 0000000000000001 x23: 0000000000000002
x24: 00000000bdff60c4 x25: 0000000000000000
x26: 0000000000000000 x27: 0000000000000000
x28: 00000000b9f40560 x29: 00000000b9f26600

Code: 00000000 00000000 00000000 ea000016 (4e4f4765)
Resetting CPU ...

resetting ...

U-Boot SPL 2024.01-armbian (Feb 09 2024 - 18:59:43 +0000)
...
```

DanKoloff, 2024-05-29:
I believe you can create SD card that forces FEL. You need to check the A64 article about FEL:

https://linux-sunxi.org/A64#FEL_booting

Kreyren, 2024-05-29:
> I believe you can create SD card that forces FEL. You need to check the A64 article about FEL:
>
> [linux-sunxi.org/A64#FEL_booting](https://linux-sunxi.org/A64#FEL_booting) -- @DanKoloff (https://github.com/OLIMEX/DIY-LAPTOP/issues/73#issuecomment-2137017844)

I didn't have success with the SD Card, notice the:

```
=> go 0x10000
## Starting application at 0x00010000 ...
"Synchronous Abort" handler, esr 0x02000000
elr: ffffffff8c0bf004 lr : 000000004a00dbb8 (reloc)
elr: 0000000000010004 lr : 00000000bdf5ebb8
x0 : 0000000000000001 x1 : 00000000b9f41238
x2 : 00000000b9f41238 x3 : 0000000001c28000
x4 : 0000000000000000 x5 : 0000000000000004
x6 : 00000000bdfe0e50 x7 : 0000000000001558
x8 : 0000000000000010 x9 : 0000000000000008
x10: 0000000000000001 x11: 0000000000000001
x12: 0000000000000010 x13: 00000000be1ff3c8
x14: 0000000000000008 x15: 0000000000000000
x16: 0000000000010000 x17: 0000000000000004
x18: 00000000b9f30d90 x19: 00000000b9f41238
x20: 0000000000010000 x21: 0000000000000002
x22: 0000000000000001 x23: 0000000000000002
x24: 00000000bdff60c4 x25: 0000000000000000
x26: 0000000000000000 x27: 0000000000000000
x28: 00000000b9f40560 x29: 00000000b9f26600

Code: 00000000 00000000 00000000 ea000016 (4e4f4765)
Resetting CPU ...

resetting ...

U-Boot SPL 2024.01-armbian (Feb 09 2024 - 18:59:43 +0000)
```

Which afaik does the same thing.. Even when it's forced it seems to cause the chip to crash
-> Did OLIMEX do any modification to the invidual chips? It's reported to work on other A64s
-> Can you look into the docs you have from allwinner to see what might be causing this as i couldn't find a rationale in the publicly available once and it doesn't seem to be something trivial like current leakage in the reset circuit.

DanKoloff, 2024-05-30:
We haven't modified any chips. We don't have anything extra, all we've got we've published online. FEL is inside the chip and it can't be affected by hardware or software.

How did you prepare that card? First make a the simplest test with only the fel-sdboot.sunxi on the card. It is not meant to be a conclusive solution, just to test entering FEL via SD card. Download this:

https://github.com/linux-sunxi/sunxi-tools/blob/master/bin/fel-sdboot.sunxi

Then download it to your card with:

dd if=fel-sdboot.sunxi of=/dev/xxxxxx bs=1k seek=8

where /dev/xxxxxx is the location of the SD card as assigned by Linux.

Also maybe check here https://linux-sunxi.org/FEL/USBBoot

Closed 2024-06-07.

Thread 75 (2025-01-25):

[Question] What is the part that is used as the touchpad ?

tranquillity-codes, 2025-01-25:
The site just states [TERES-023-Touch](https://www.olimex.com/Products/DIY-Laptop/SPARE-PARTS/TERES-023-Touch/), and we can't find any info about what part it is, as well as any kind of traces and information about the part - all we can find are 3 pictures, 1 in this repository (images/TERES-I/hardware/043.jpg) and two low-res ones on the site.

Kreyren, 2025-01-25:
Afaik it's generic off the shelf touchpad that came with the chasis that is then routed to the chip via https://github.com/OLIMEX/DIY-LAPTOP/tree/rel3/HARDWARE/A64-TERES/TERES-PCB3-TOUCH-BTN/Rev.A (verified on my teres)

@TsvetanUsunov or @DanKoloff probably have a reference somewhere what exact part it is (I kinda put it in place with a very strong tape and now i can't remove that non-destructively without a lot of heat and solvents to check as the original glue seemed kinda too weak to me :D) , but if you are looking for a reference or just want to make your own then https://ploopyco.github.io/trackpad/assembly-instructions/ should have everything you need and you can adjust it's dimensions to fit in the teres's chasis.

tranquillity-codes, 2025-01-25:
The chassis is custom-made, no ? Or is it off-the-shelf ? Would be nice to figure out what that part is too, I suppose, if it's off-the-shelf...

Would also be interesting to know where is OLIMEX sourcing it from

DanKoloff, 2025-01-27:
There is a repository with reverse engineering of the plastic case made by another company, maybe it would be useful:

[Teres case reverse engineered](https://code.forksand.com/forksand/olimex-teres-case)

We don't have source files for the plastic case and such. We purchased the TERES-I case ourselves but we never got design files from the manufacturer. So we first got the case then designed the insides to fit in this case and we empirically measured and tested.

Kreyren, 2025-01-27:
> The chassis is custom-made, no ? Or is it off-the-shelf ? Would be nice to figure out what that part is too, I suppose, if it's off-the-shelf... -- @tranquillity-codes (https://github.com/OLIMEX/DIY-LAPTOP/issues/75#issuecomment-2614002018)

The chasis is off the shelf with there being a community alternatives that are open-source and very economical to get them made as the teres's size makes it to not fit in common low-end 3D printers and afaik most of the teres users seems to design their own chasis as the design is simple and can be made in few mins.

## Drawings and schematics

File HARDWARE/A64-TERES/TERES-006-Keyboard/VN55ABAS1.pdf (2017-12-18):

LEVEL 1 ENVIRONMENTAL RELATED SUBSTANCES TO BE CONTROLLED SHOULD NEVER BE USED.

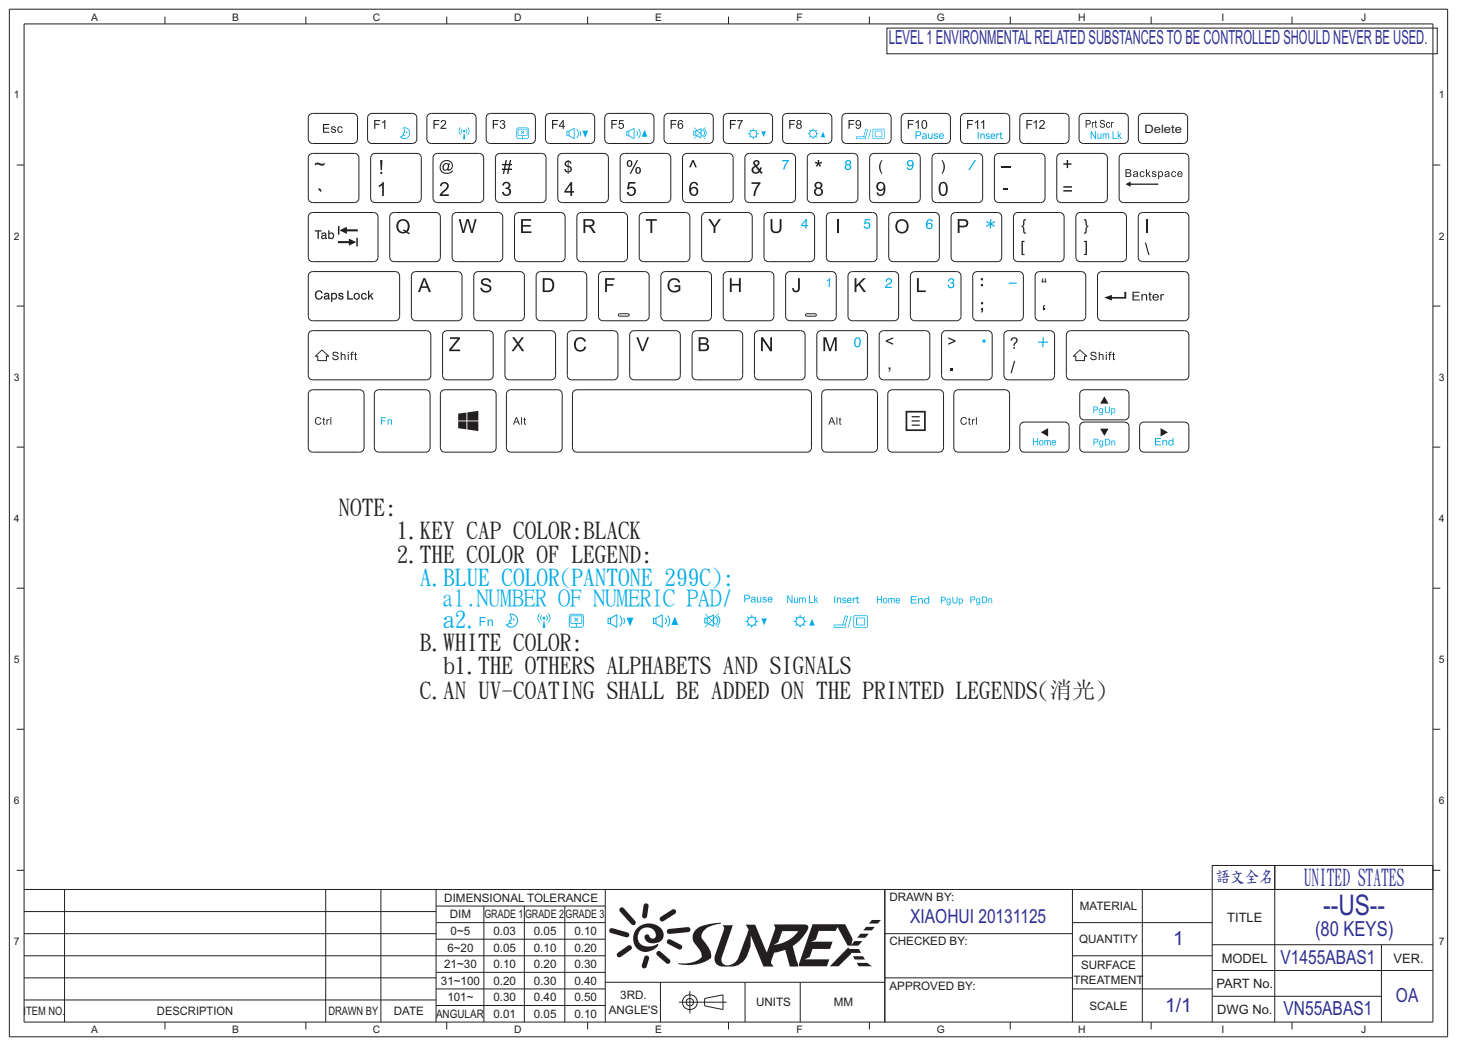
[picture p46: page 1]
語文全名; UNITED STATES; VN55ABAS1; ITEM NO.; DESCRIPTION; DRAWN BY; DATE; ANGULAR; ANGLE'S; DWG No.; UNITS; CHECKED BY:; APPROVED BY:; SCALE; Delete

NOTE:
1.KEY CAP COLOR:BLACK
2.THE COLOR OF LEGEND:
A.BLUE COLOR(PANTONE 299C):
a1.NUMBER OF NUMERIC PAD/
B.WHITE COLOR:
b1.THE OTHERS ALPHABETS AND SIGNALS
C.AN UV-COATING SHALL BE ADDED ON THE PRINTED LEGENDS(消光)

DIMENSIONAL TOLERANCE | | DRAWN BY: XIAOHUI 20131125 | MATERIAL | | TITLE | --US--(80 KEYS)
DIM | GRADE 1 | GRADE 2GRADE 3
0~5 | 0.03 | 0.05 | 0.10 | | | QUANTITY | 1
6~20 | 0.05 | 0.10 | 0.20
21~30 | 0.10 | 0.20 | 0.30 | | | SURFACE TREATMENT
31~100 | 0.20 | 0.30 | 0.40 | | | | | PART No. | | OA

MODEL | V1455ABAS1 | VER.

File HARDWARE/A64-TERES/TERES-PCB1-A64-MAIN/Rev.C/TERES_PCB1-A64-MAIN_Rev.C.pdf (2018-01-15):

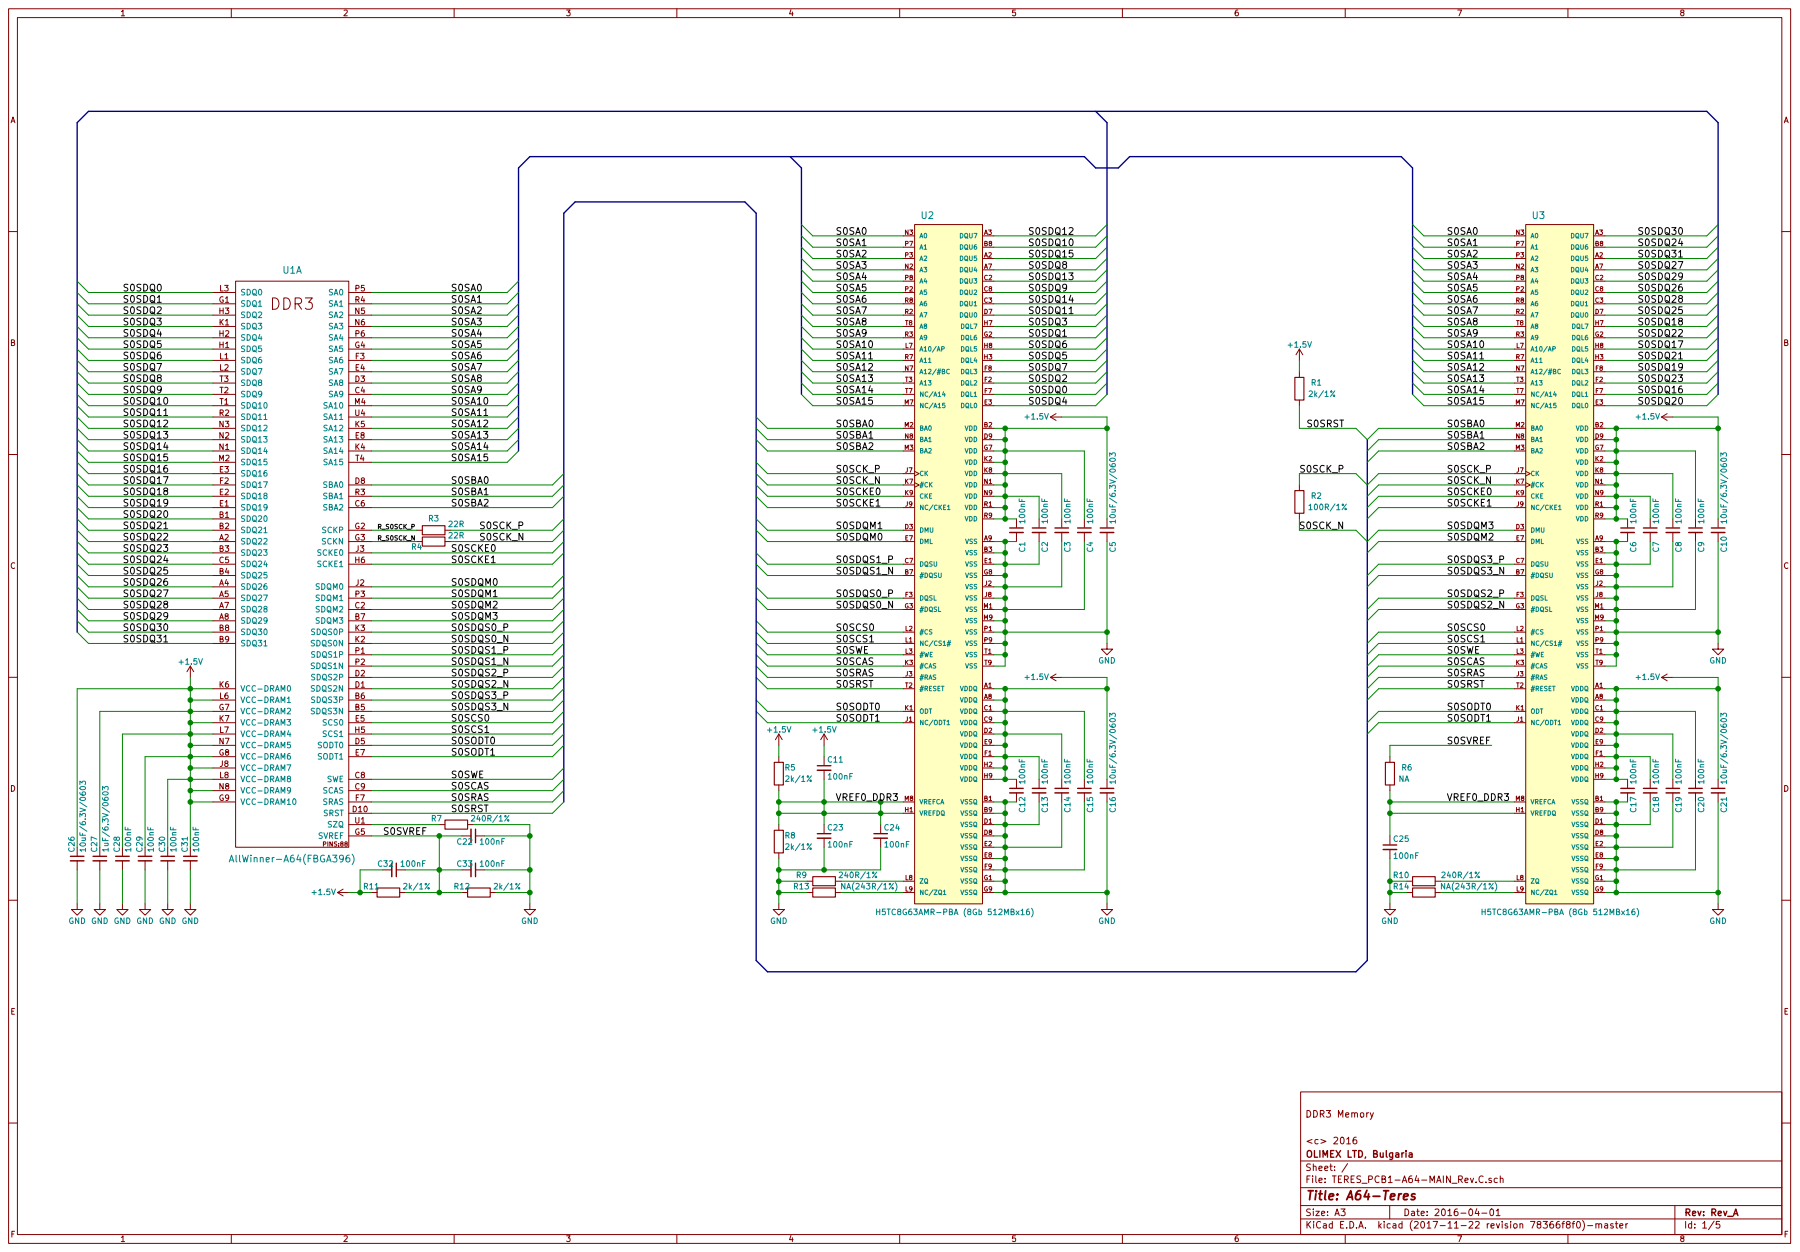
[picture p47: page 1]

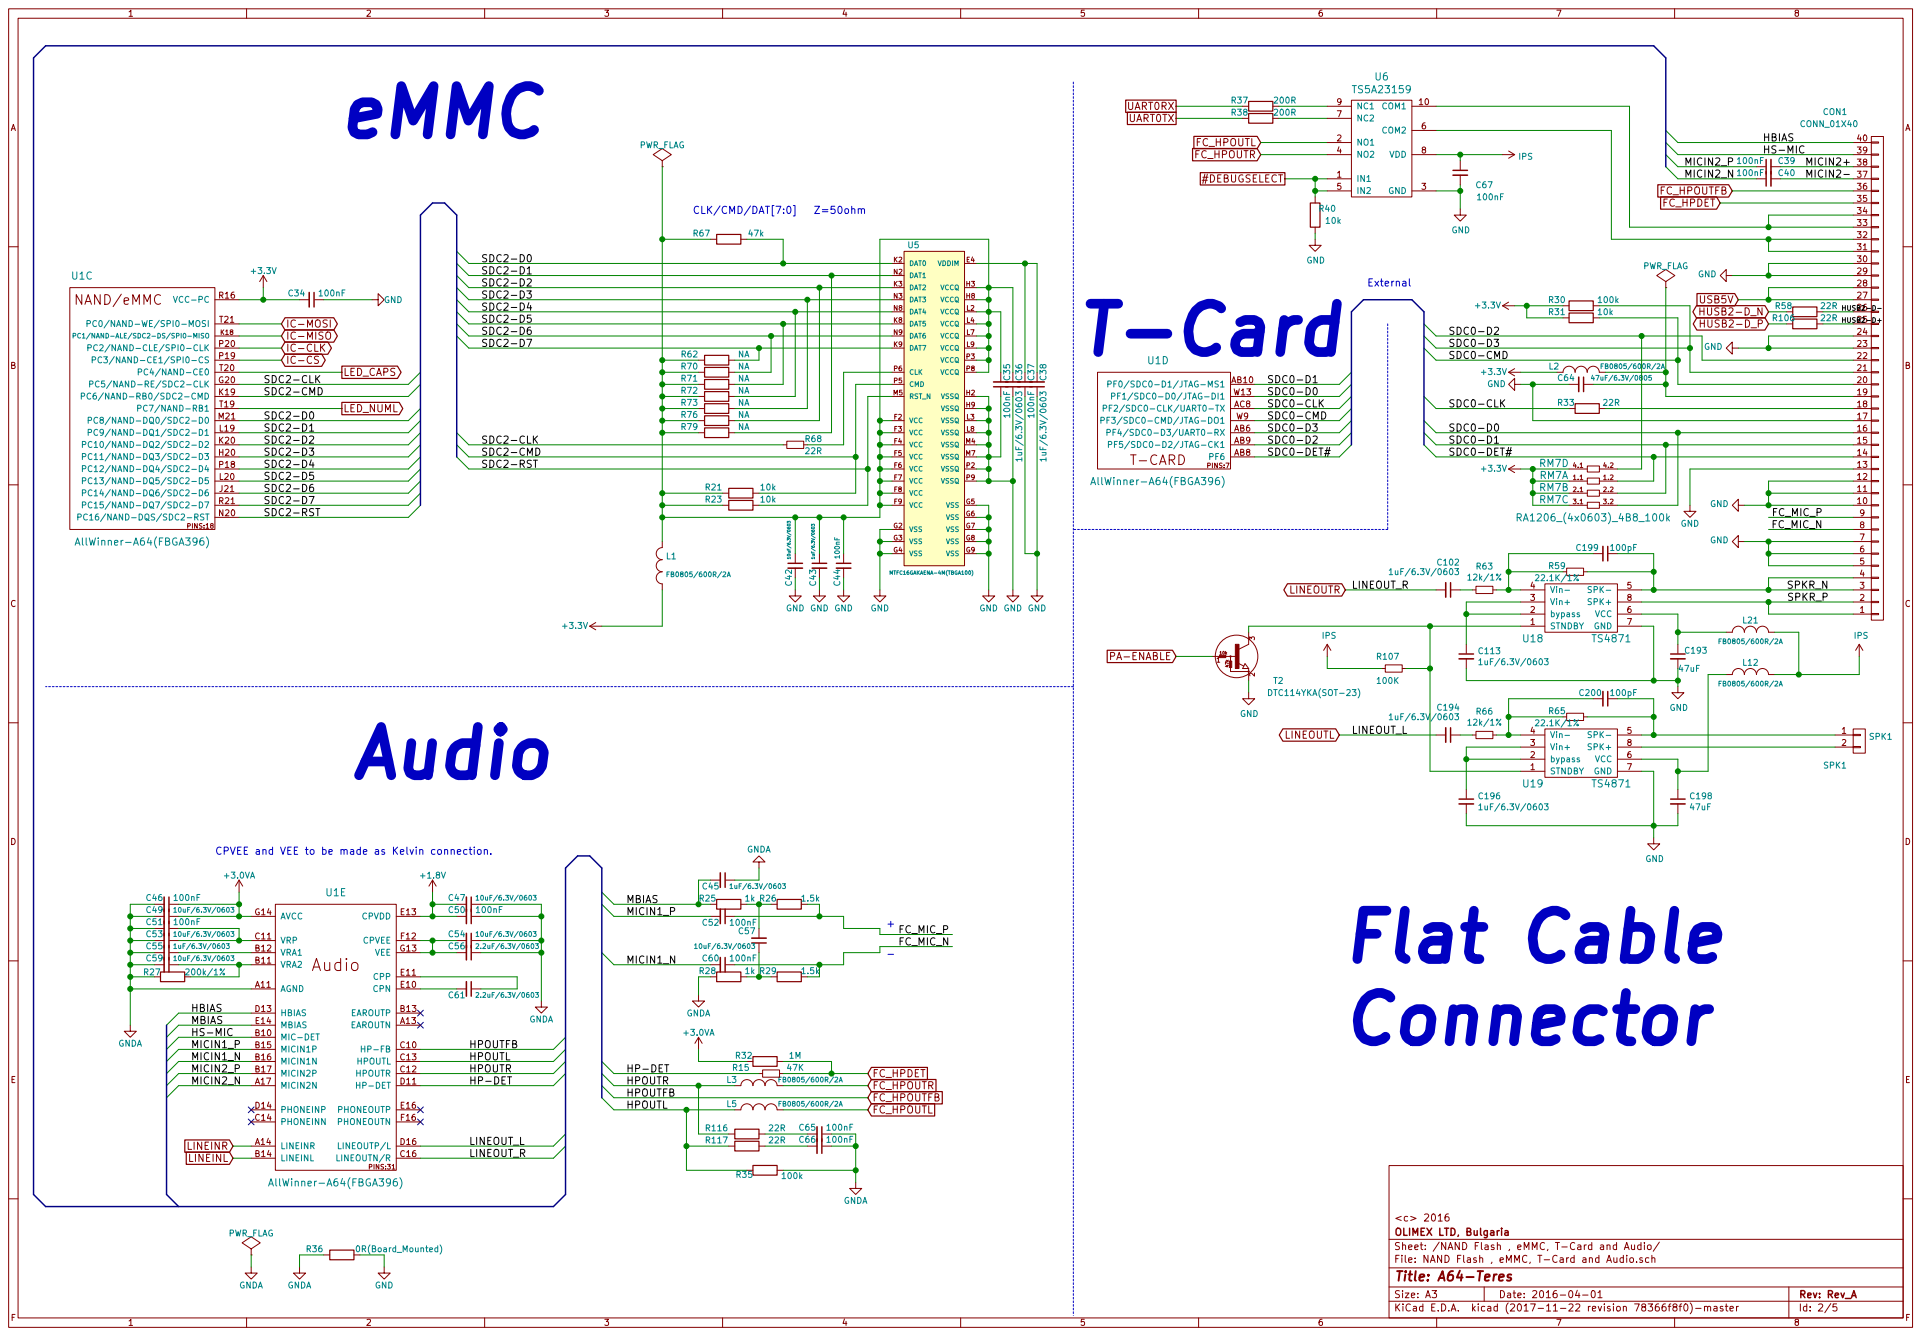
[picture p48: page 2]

Sheet: /NAND Flash , eMMC, T-Card and Audio/
File: NAND Flash , eMMC, T-Card and Audio.sch
Id: 2/5 Title: A64-Teres

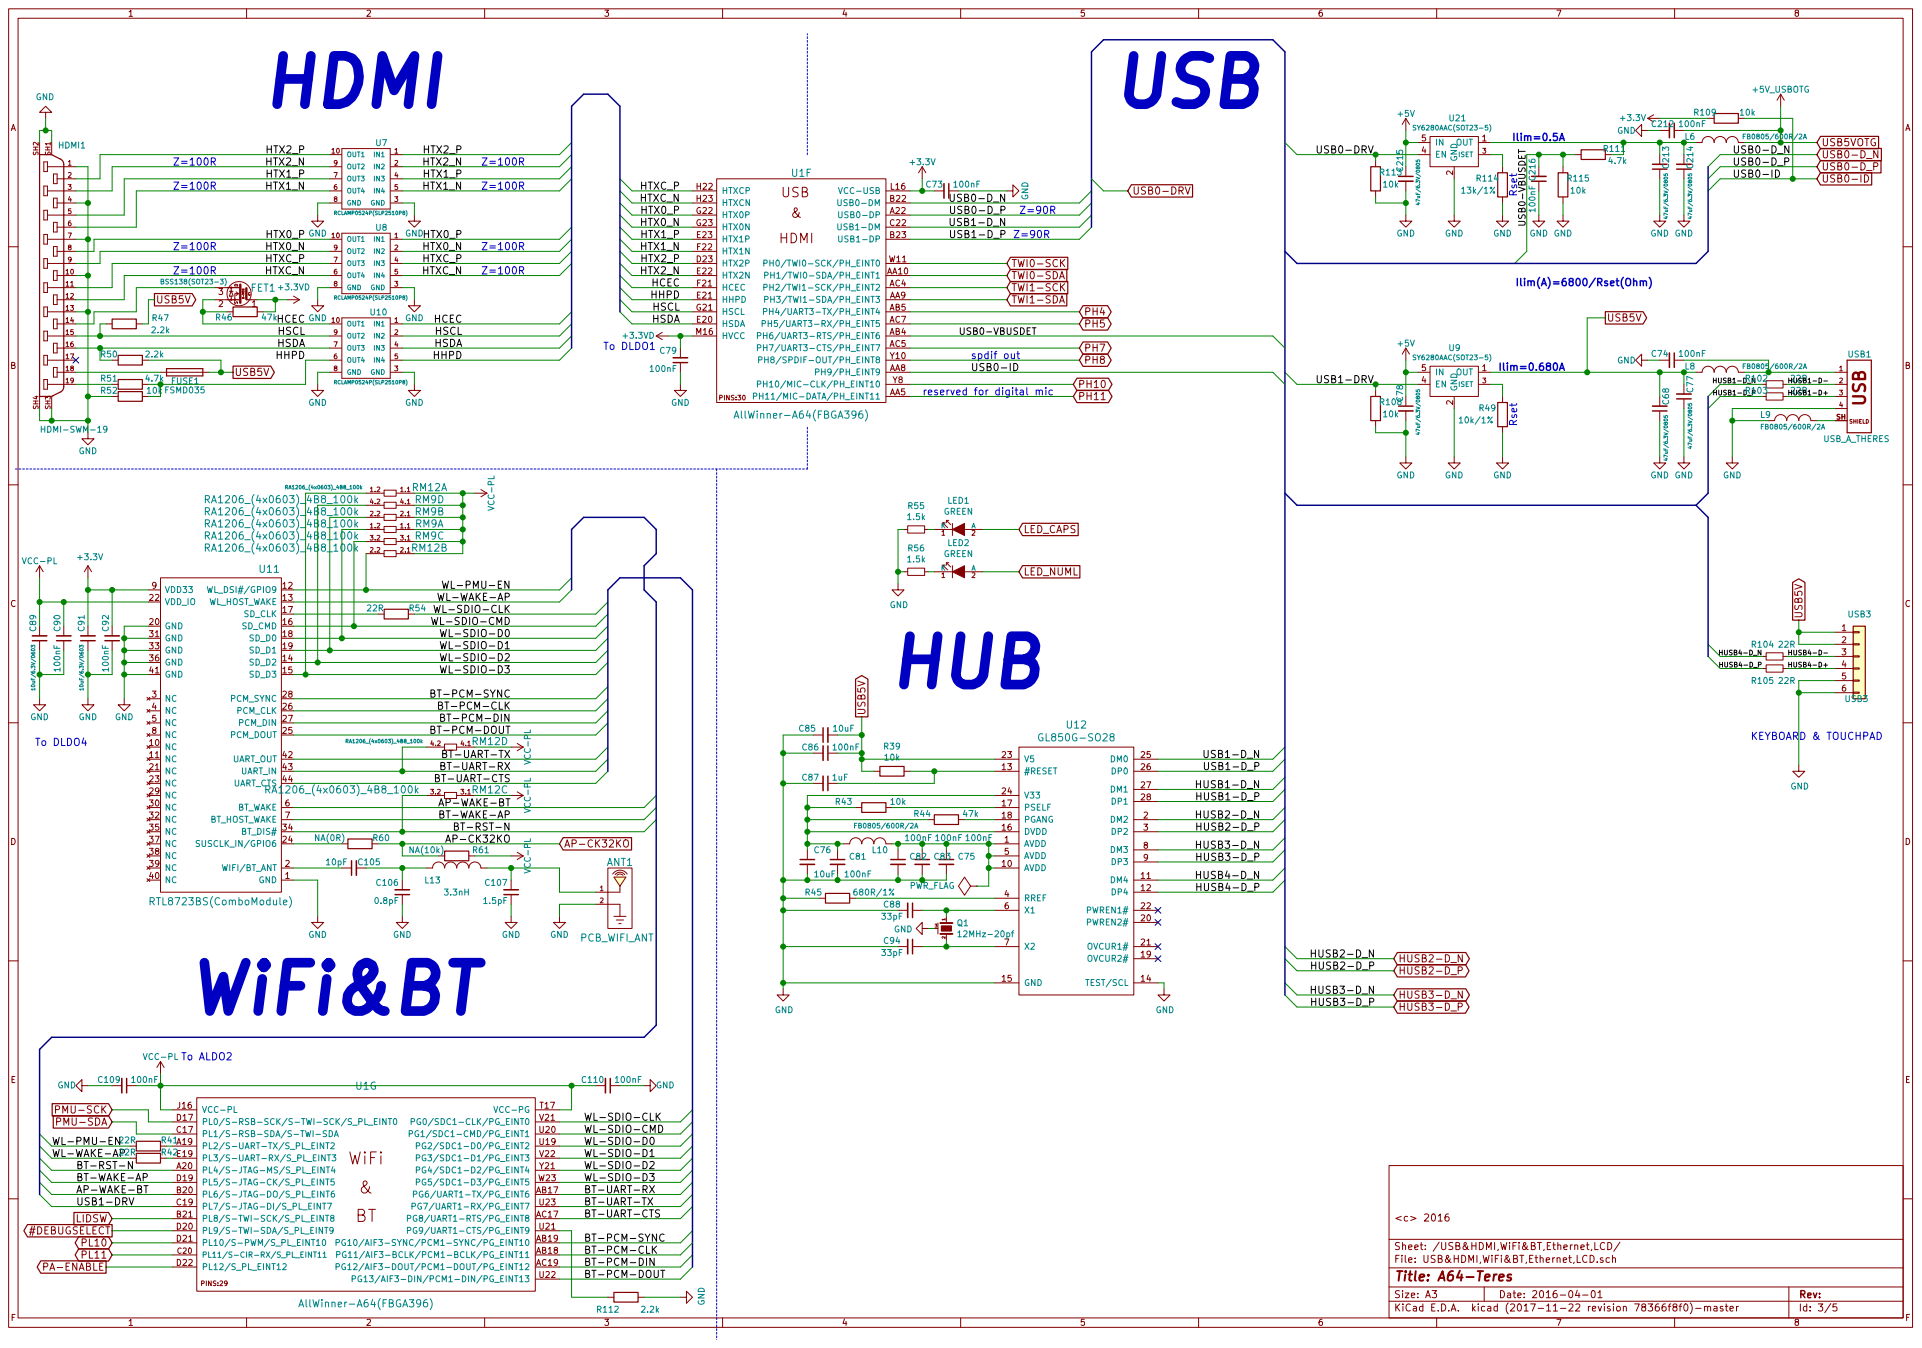
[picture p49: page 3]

Ilim(A)=6800/Rset(Ohm) Rset

reserved for digital mic

BT-PCM-DOUT AP-WAKE-BT BT-WAKE-AP

AP-WAKE-BT BT-WAKE-AP

WL-SDIO-CMD
WL-SDIO-D0
WL-SDIO-D1
WL-SDIO-D2
WL-SDIO-D3 BT-UART-RX

File: USB&HDMI,WiFi&BT,Ethernet,LCD.sch
Id: 3/5 Title: A64-Teres

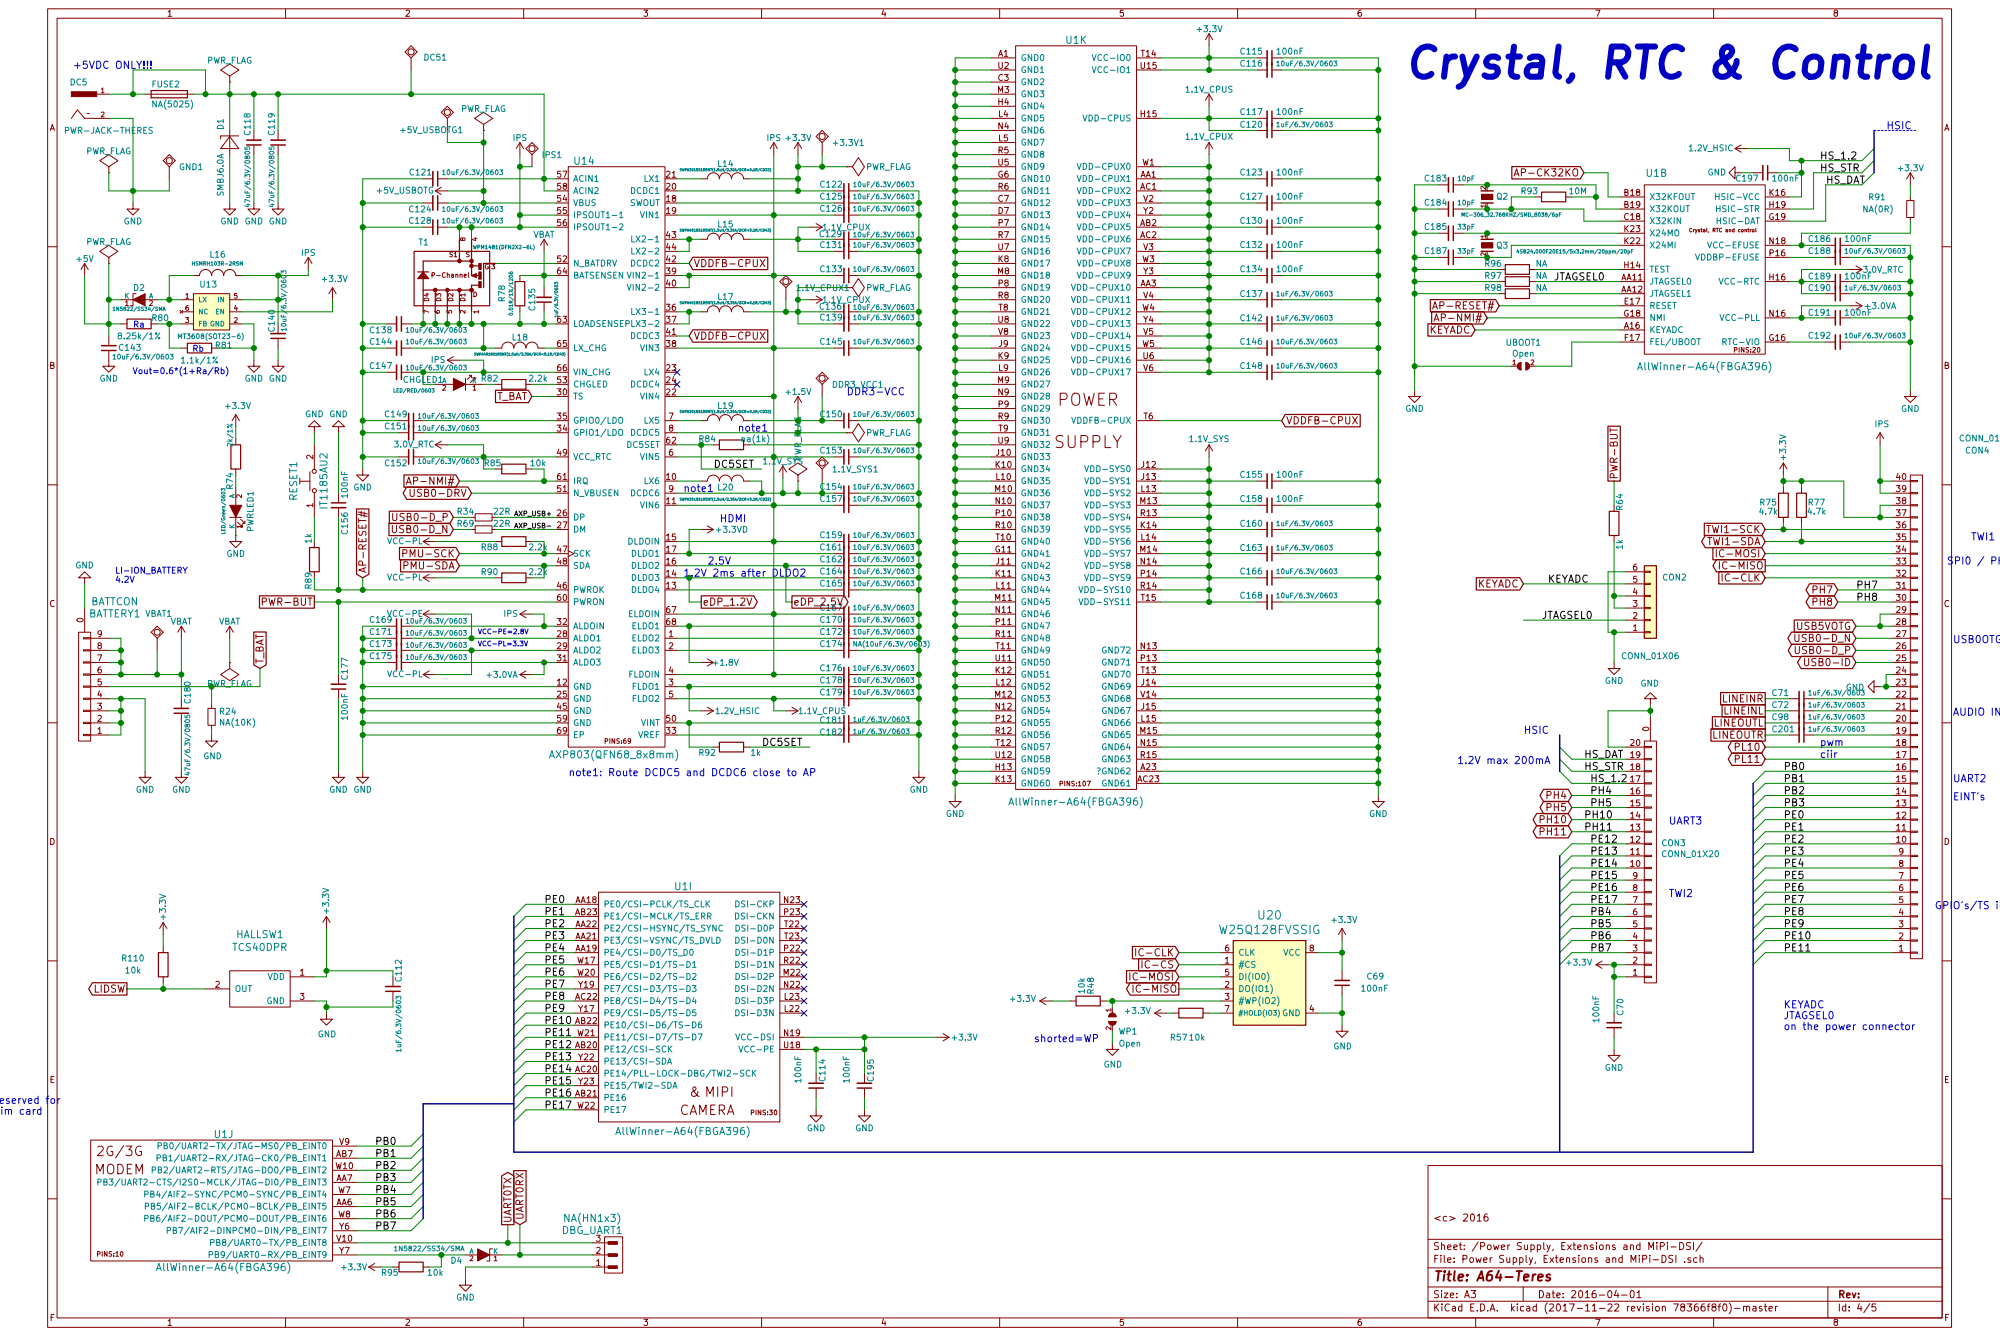
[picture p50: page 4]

Crystal, RTC and control PINS:20 KEYADC A16

reserved for sim card

Sheet: /Power Supply, Extensions and MiPi-DSI/ <c> 2016

File: Power Supply, Extensions and MiPi-DSI .sch
Id: 4/5 Title: A64-Teres

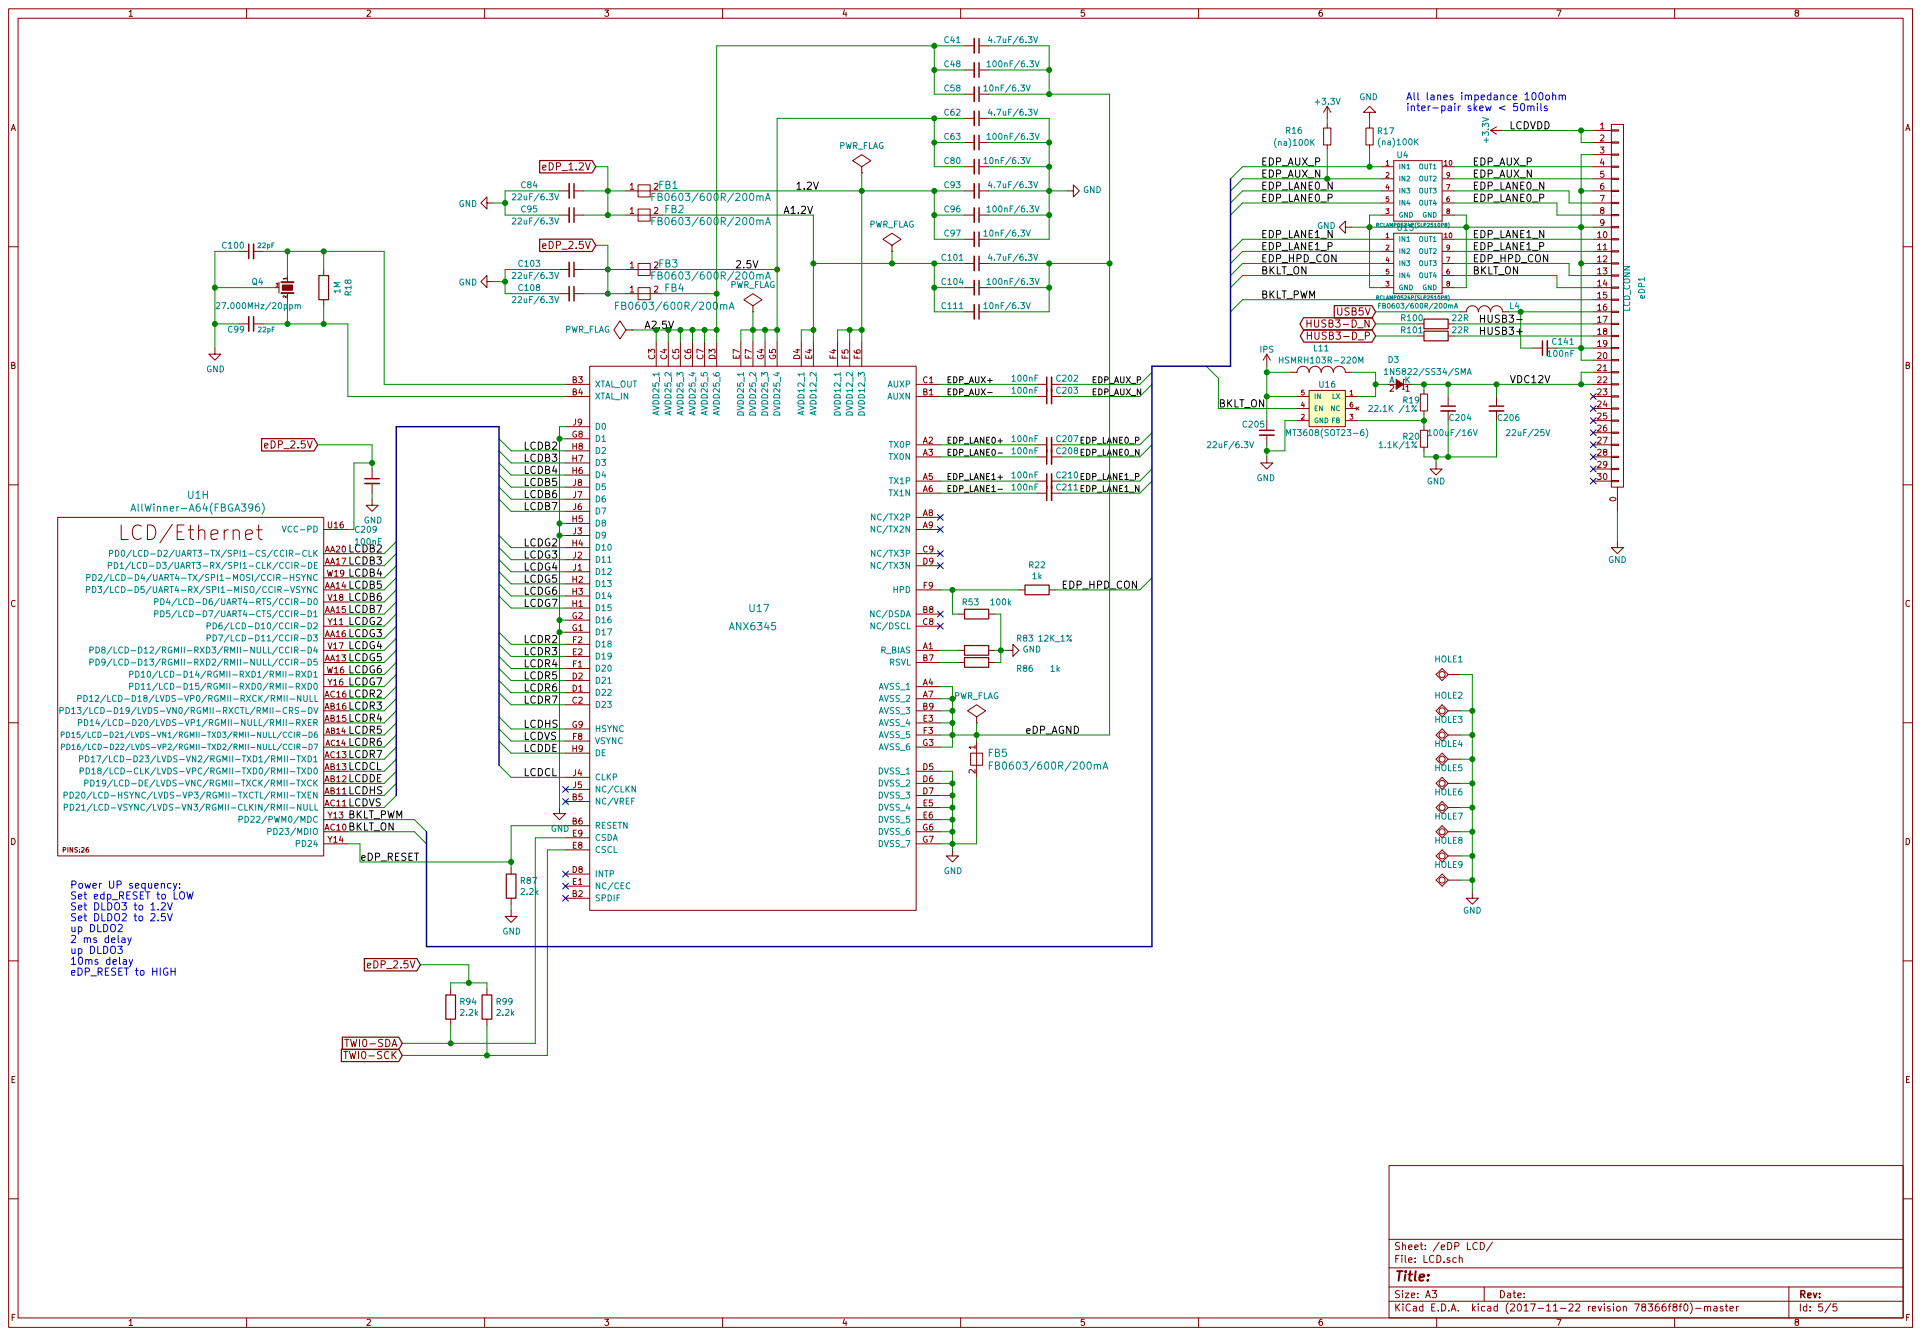
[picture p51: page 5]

Id: 5/5 Title: File: LCD.sch Sheet: /eDP LCD/ +3.3V

22uF/6.3V C108 | PWR_FLAG

14
15
16
17

HUSB3+ | | 18

19
20

LCDB3
LCDB4
LCDB5
LCDB6
LCDB7

LCDG3
LCDG4
LCDG5
LCDG6
LCDG7

LCDR3
LCDR4
LCDR5
LCDR6
LCDR7

LCDVS
LCDDE

LCDCL
LCDHS

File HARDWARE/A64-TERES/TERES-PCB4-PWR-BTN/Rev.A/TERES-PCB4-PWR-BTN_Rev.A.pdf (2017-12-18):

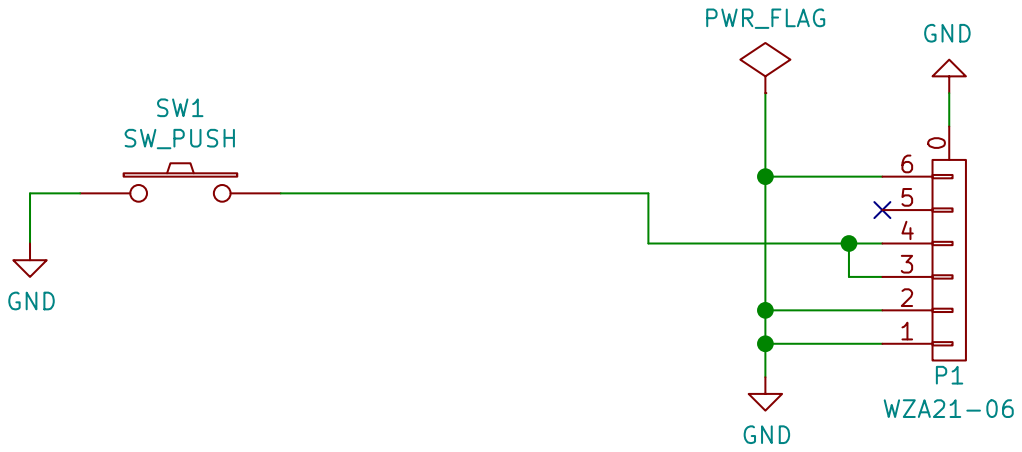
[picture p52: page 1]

File: PCB4-PWR-BTN_Rev.A.sch Sheet: /
Id: 1/1 Title:

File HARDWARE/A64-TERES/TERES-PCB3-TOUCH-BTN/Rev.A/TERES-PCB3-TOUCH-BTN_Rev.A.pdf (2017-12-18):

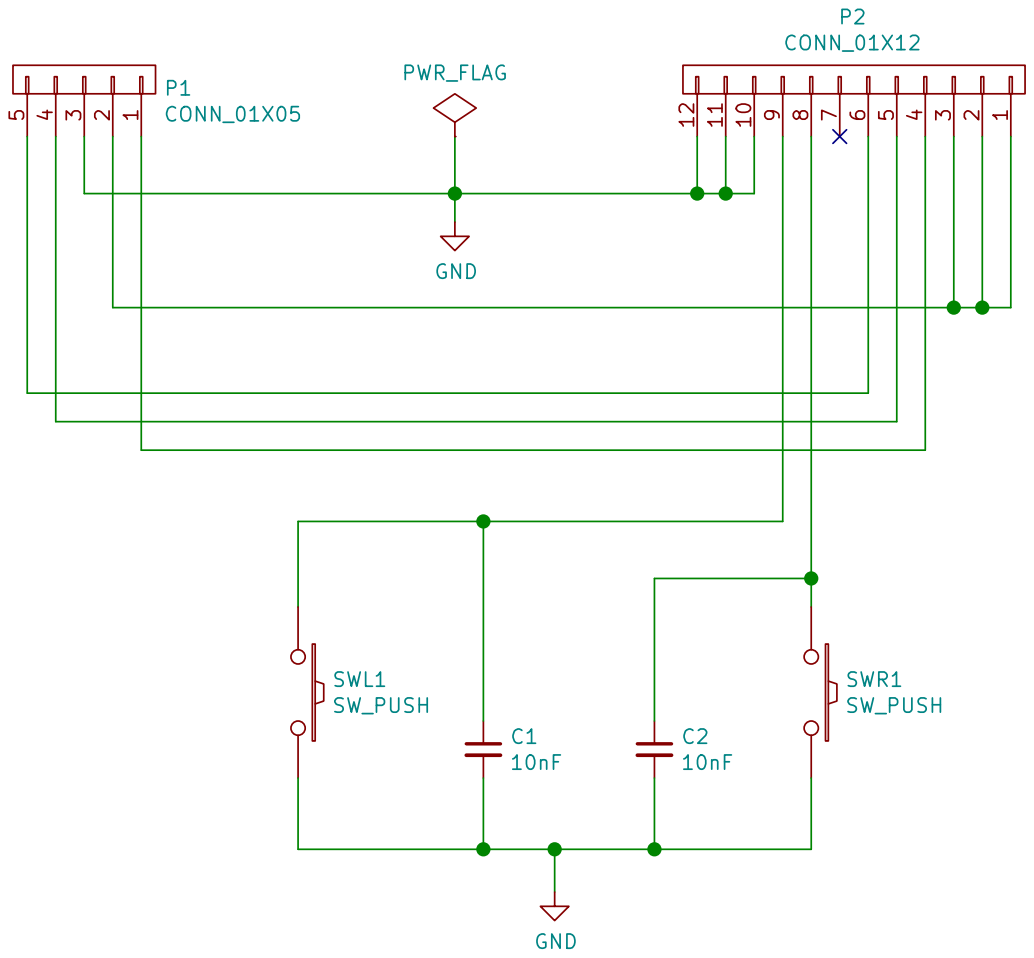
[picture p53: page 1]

File: TERES-PCB3-TOUCH-BTN_Rev.A.sch Sheet: /
Id: 1/1 Title:

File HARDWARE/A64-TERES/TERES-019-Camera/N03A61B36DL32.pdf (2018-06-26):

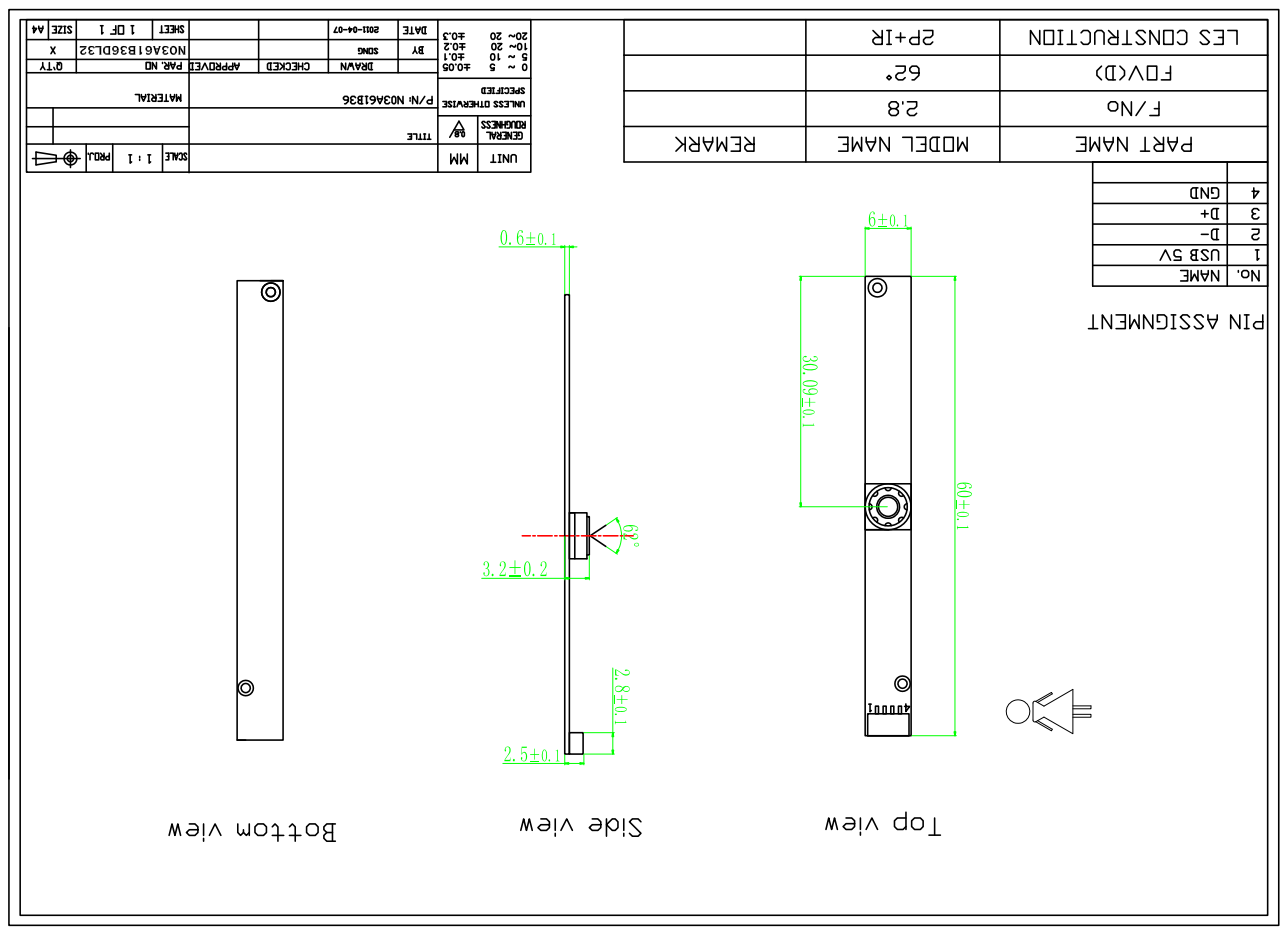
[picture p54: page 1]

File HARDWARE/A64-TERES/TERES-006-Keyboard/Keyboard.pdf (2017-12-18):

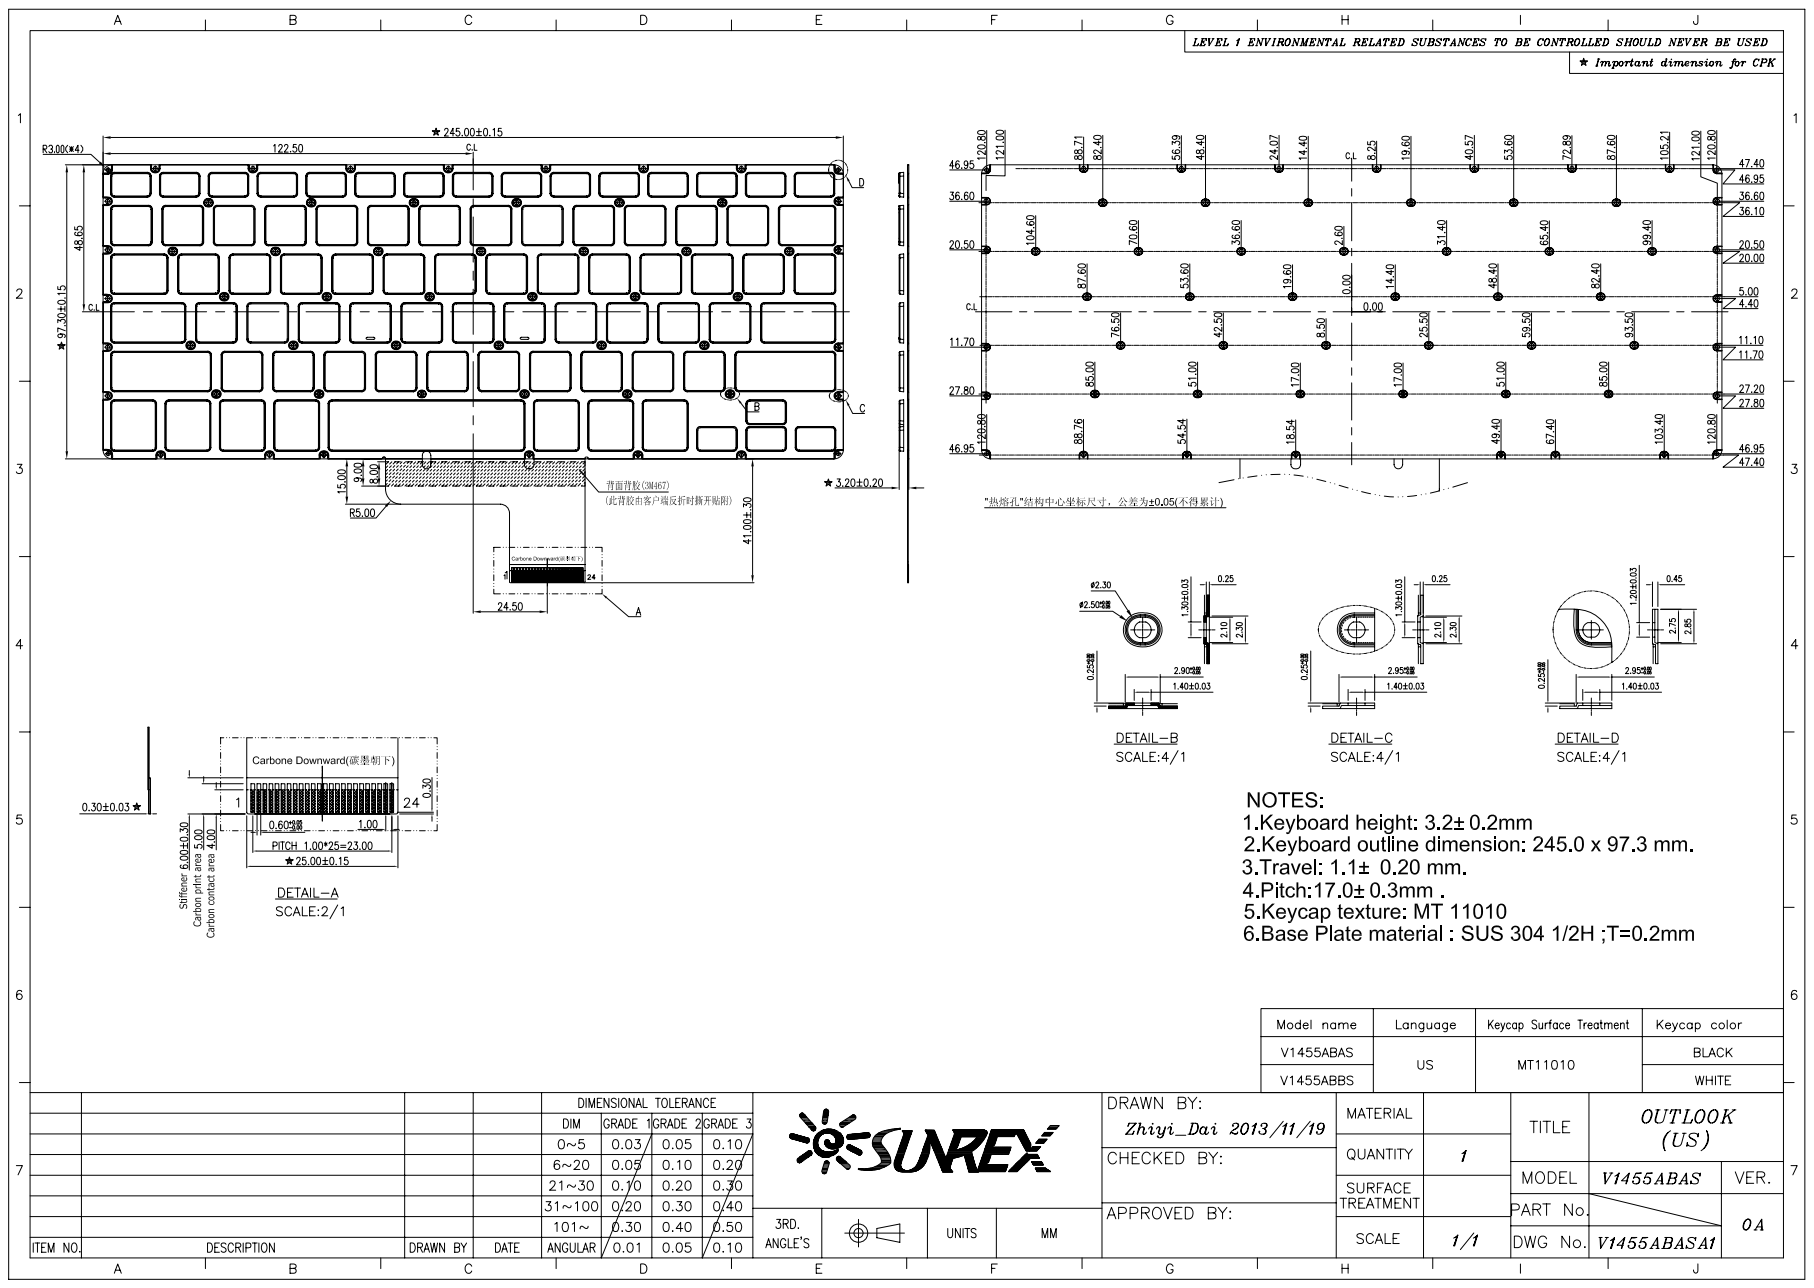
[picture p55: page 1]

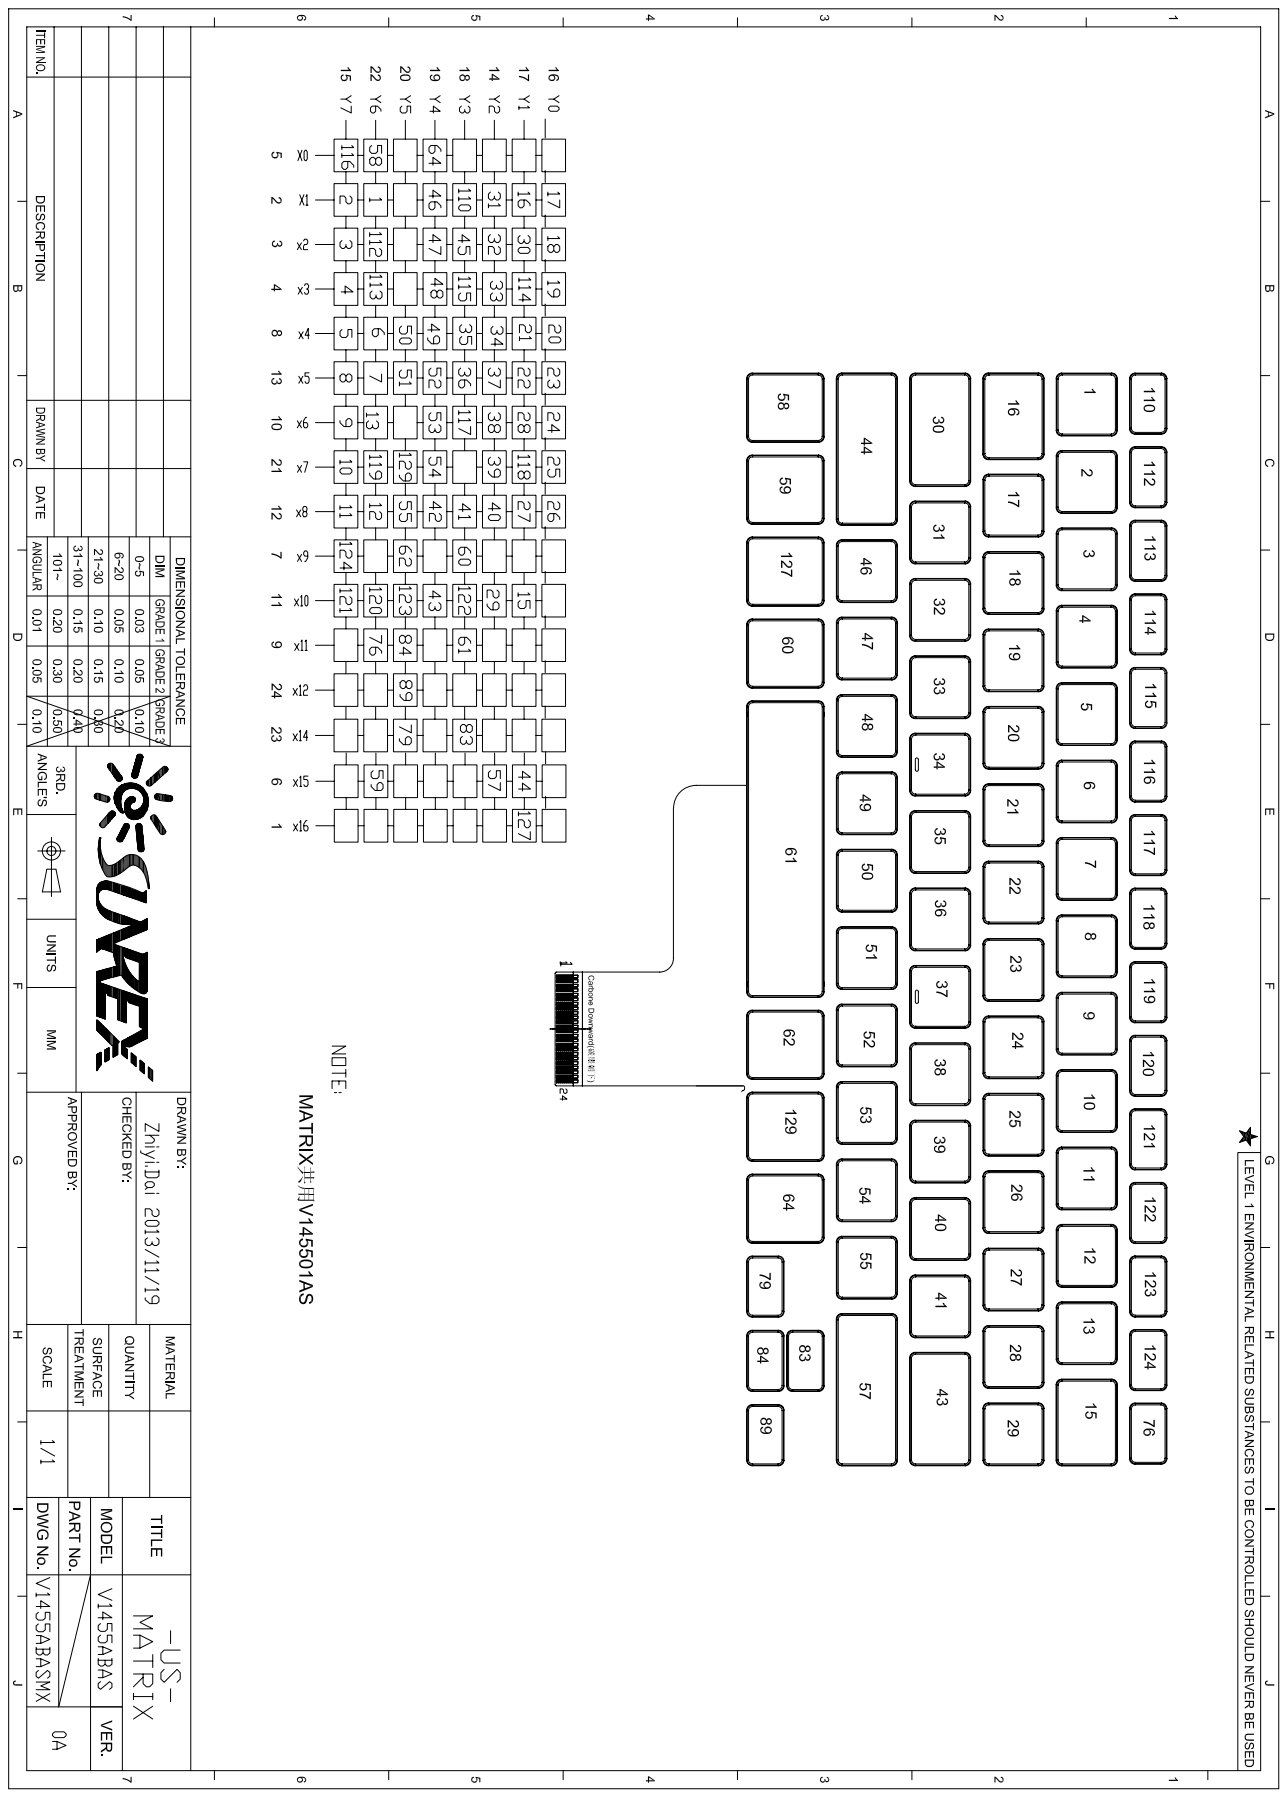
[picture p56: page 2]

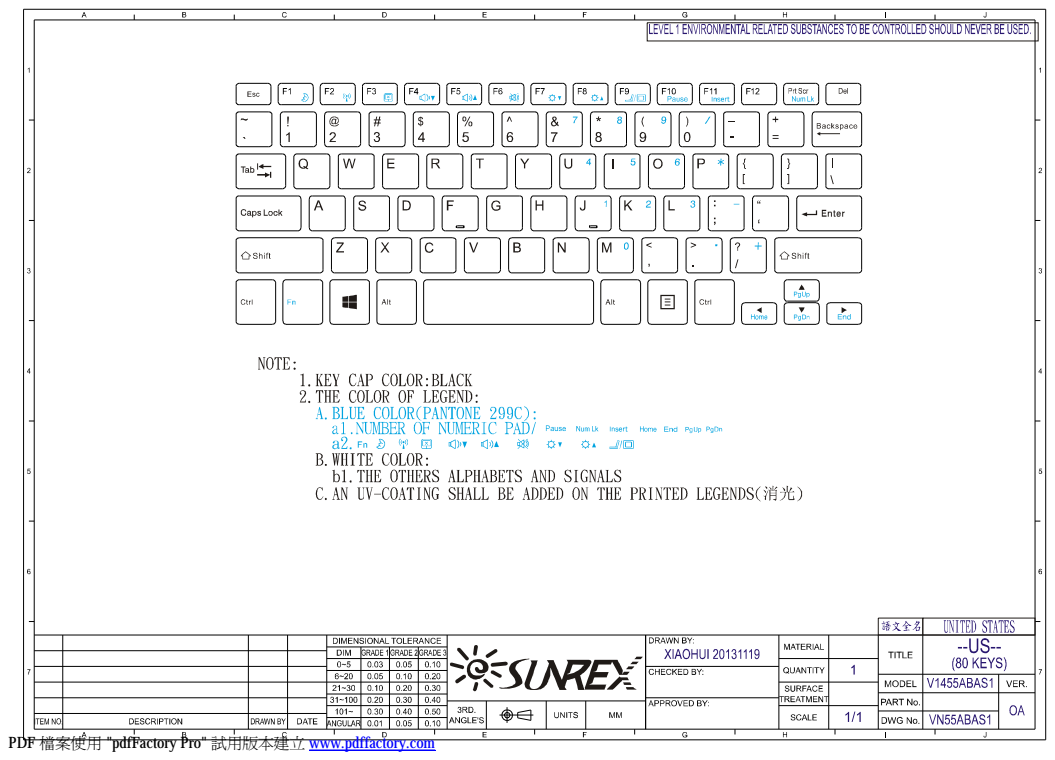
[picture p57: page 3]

PDF 檔案使用 "pdfFactory Pro" 試用版本建立 www.pdffactory.com

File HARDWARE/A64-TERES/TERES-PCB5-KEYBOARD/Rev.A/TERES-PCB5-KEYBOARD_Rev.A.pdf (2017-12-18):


KBD_X2
KBD_X1

(OC0B/SCL/INT0)PD0 18

KBD_X9 | (XCK1/CTS)PD5 22
KBD_X0 | (T1/OC4D/ADC9)PD6 26
KBD_X3 | (T0/OC4D/ADC10)PD7 27

KBD_X10 | (ADC5/TMS)PF5 38
KBD_X6 | (ADC6/TDO)PF6 37
KBD_X11

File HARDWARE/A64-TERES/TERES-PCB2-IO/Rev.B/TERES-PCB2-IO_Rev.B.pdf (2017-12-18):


HS-MIC
MIC2_P
MIC2_N

MIC- | 33

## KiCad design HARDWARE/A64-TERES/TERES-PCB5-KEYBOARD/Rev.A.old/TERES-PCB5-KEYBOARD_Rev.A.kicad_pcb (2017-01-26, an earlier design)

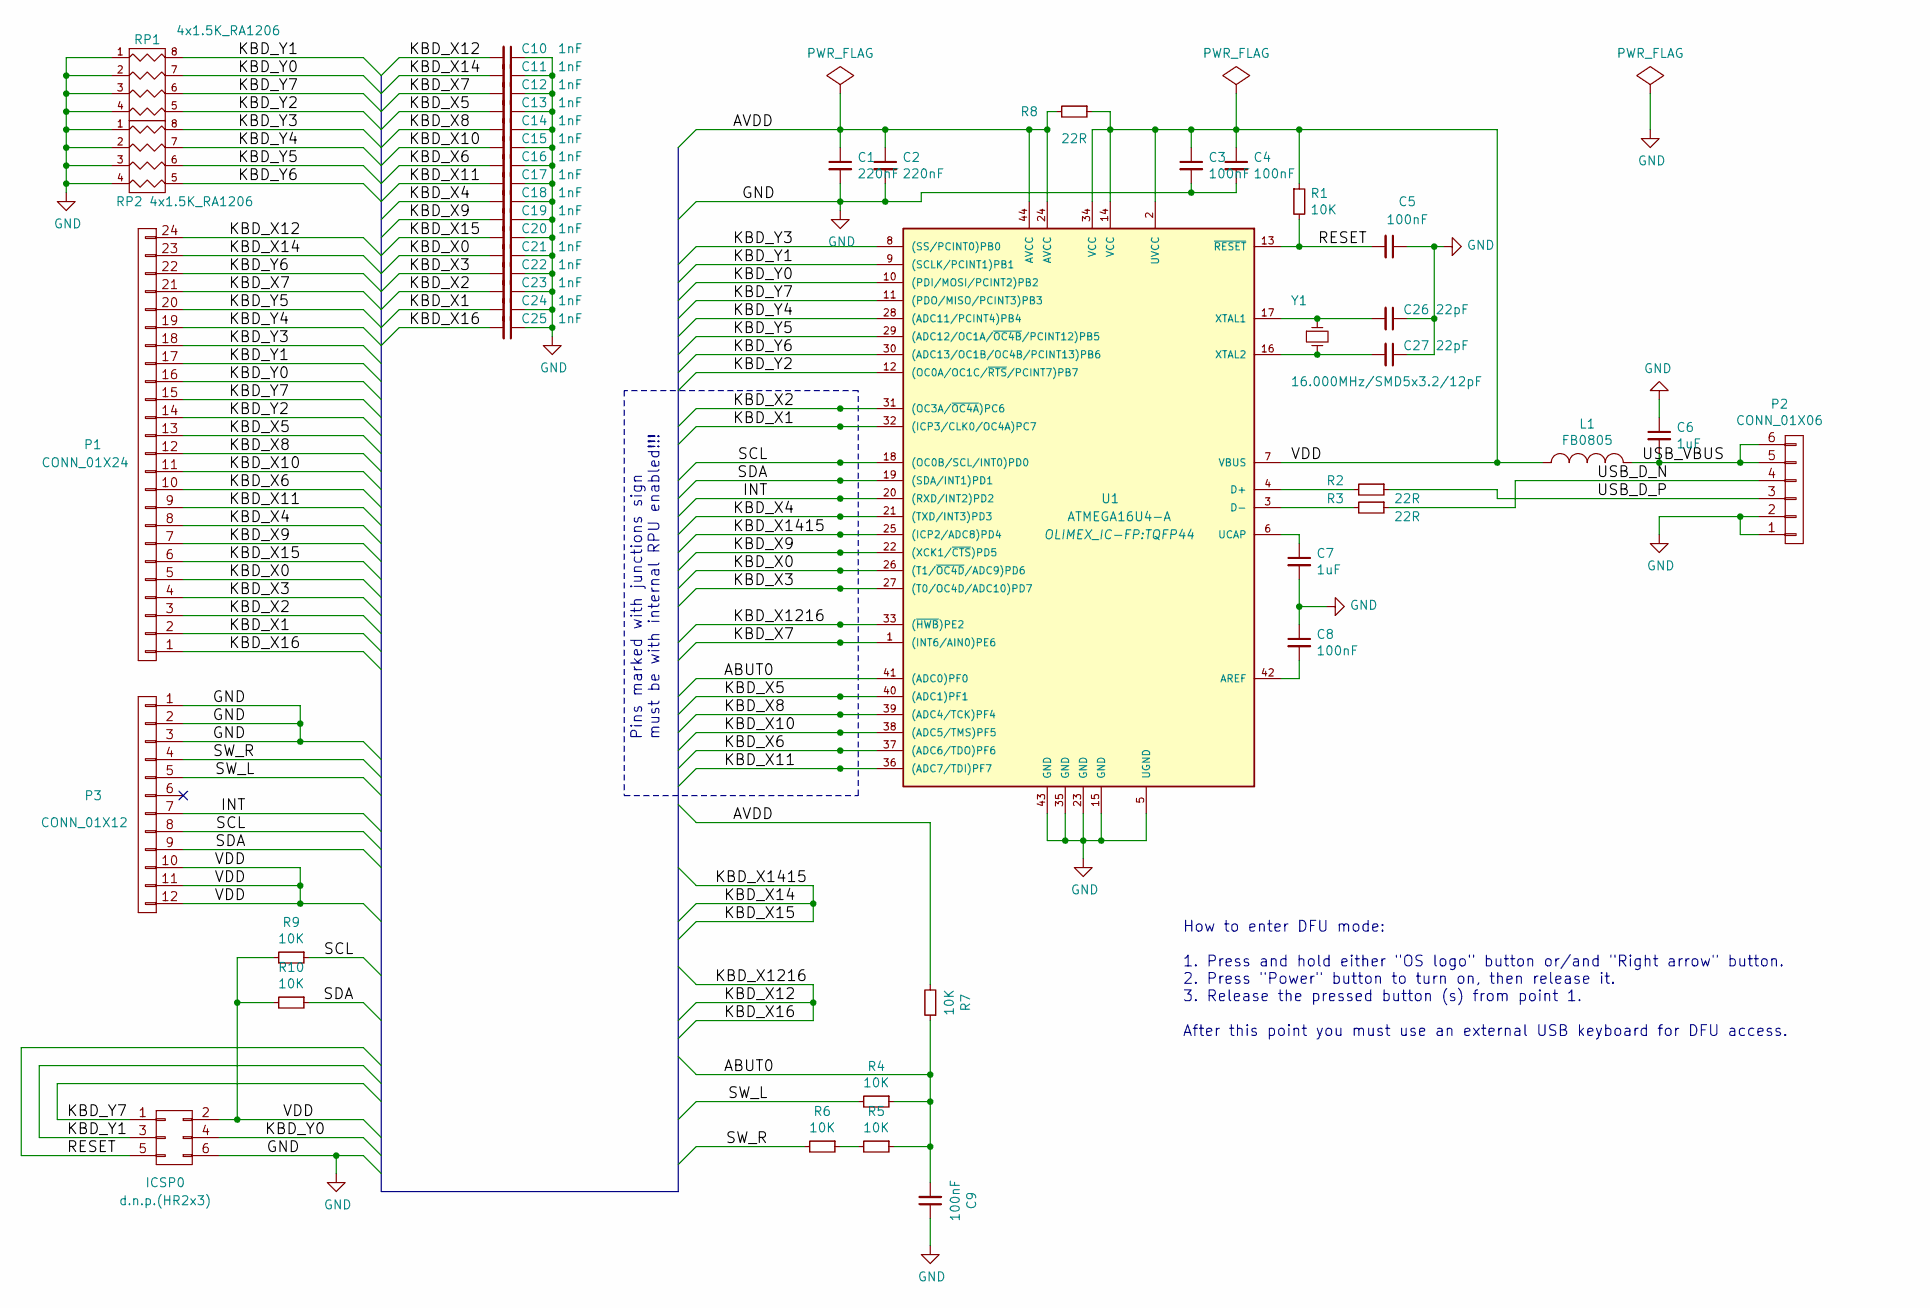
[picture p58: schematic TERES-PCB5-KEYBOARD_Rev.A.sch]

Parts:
C1: 220nF; C_0603_5MIL_DWS
C2: 220nF; C0402
C3, C4, C5, C8, C9: 100nF; C0402
C6, C7: 1uF; C_0603_5MIL_DWS
C10, C11, C12, C13, C14, C15, C16, C17, C18, C19, C20, C21, C22, C23, C24, C25: 1nF; C0402
C26, C27: 22pF; C0402
ICSP0: d.n.p.(HR2x3); HN2x3
L1: FB0805; L_0805_5MIL_DWS
P1: CONN_01X24; FLEX-CONN-KBD-TERES-24x1
P2: CONN_01X06; FLEXCON-0.5-6
P3: CONN_01X12; FLEXCON-0.5-12
R1, R4, R5, R6, R7, R9, R10: 10K; R_0402_5MIL_DWS
R2, R3, R8: 22R; R_0402_5MIL_DWS
RP1, RP2: 4x1.5K_RA1206; R_MATRIX_4_KICAD
U1: ATMEGA16U4-A; TQFP44
Y1: 16.000MHz/SMD5x3.2/12pF; Q5x3.25

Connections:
/ABUT0: C9.2, R4.1, R5.1, R7.1, U1.41 ((ADC0)PF0)
/AVDD: C1.1, C2.1, R7.2, R8.2, U1.24 (AVCC), U1.44 (AVCC)
/INT: P3.7, U1.20 ((RXD/INT2)PD2)
/KBD_X0: C21.2, P1.5, U1.26 ((T1/~OC4D~/ADC9)PD6)
/KBD_X1: C24.2, P1.2, U1.32 ((ICP3/CLK0/OC4A)PC7)
/KBD_X2: C23.2, P1.3, U1.31 ((OC3A/~OC4A~)PC6)
/KBD_X3: C22.2, P1.4, U1.27 ((T0/OC4D/ADC10)PD7)
/KBD_X4: C18.2, P1.8, U1.21 ((TXD/INT3)PD3)
/KBD_X5: C13.2, P1.13, U1.40 ((ADC1)PF1)
/KBD_X6: C16.2, P1.10, U1.37 ((ADC6/TDO)PF6)
/KBD_X7: C12.2, P1.21, U1.1 ((INT6/AIN0)PE6)
/KBD_X8: C14.2, P1.12, U1.39 ((ADC4/TCK)PF4)
/KBD_X9: C19.2, P1.7, U1.22 ((XCK1/~CTS~)PD5)
/KBD_X10: C15.2, P1.11, U1.38 ((ADC5/TMS)PF5)
/KBD_X11: C17.2, P1.9, U1.36 ((ADC7/TDI)PF7)
/KBD_X12: C10.2, C25.2, P1.1, P1.24, U1.33 ((~HWB~)PE2)
/KBD_X14: C11.2, C20.2, P1.6, P1.23, U1.25 ((ICP2/ADC8)PD4)
/KBD_Y0: ICSP0.4, P1.16, RP1.7 (R2), U1.10 ((PDI/MOSI/PCINT2)PB2)
/KBD_Y1: ICSP0.3, P1.17, RP1.8 (R1), U1.9 ((SCLK/PCINT1)PB1)
/KBD_Y2: P1.14, RP1.5 (R4), U1.12 ((OC0A/OC1C/~RTS~/PCINT7)PB7)
/KBD_Y3: P1.18, RP2.8 (R1), U1.8 ((SS/PCINT0)PB0)
/KBD_Y4: P1.19, RP2.7 (R2), U1.28 ((ADC11/PCINT4)PB4)
/KBD_Y5: P1.20, RP2.6 (R3), U1.29 ((ADC12/OC1A/~OC4B~/PCINT12)PB5)
/KBD_Y6: P1.22, RP2.5 (R4), U1.30 ((ADC13/OC1B/OC4B/PCINT13)PB6)
/KBD_Y7: ICSP0.1, P1.15, RP1.6 (R3), U1.11 ((PDO/MISO/PCINT3)PB3)
/RESET: C5.2, ICSP0.5, R1.2, U1.13 (~RESET~)
/SCL: P3.8, R9.1, U1.18 ((OC0B/SCL/INT0)PD0)
/SDA: P3.9, R10.1, U1.19 ((SDA/INT1)PD1)
/SW_L: P3.5, R4.2
/SW_R: P3.4, R6.2
/USB_D_N: P2.4, R3.1
/USB_D_P: P2.3, R2.1
/USB_VBUS: C6.2, L1.2, P2.5, P2.6
/VDD: C3.1, C4.1, ICSP0.2, L1.1, P3.10, P3.11, P3.12, R1.1, R8.1, R9.2, R10.2, U1.2 (UVCC), U1.7 (VBUS), U1.14 (VCC), U1.34 (VCC)
GND: C1.2, C2.2, C3.2, C4.2, C5.1, C6.1, C7.2, C8.1, C9.1, C10.1, C11.1, C12.1, C13.1, C14.1, C15.1, C16.1, C17.1, C18.1, C19.1, C20.1, C21.1, C22.1, C23.1, C24.1, C25.1, C26.1, C27.1, ICSP0.6, P1.0, P2.0, P2.1, P2.2, P3.0, P3.1, P3.2, P3.3, RP1.1, RP1.2, RP1.3, RP1.4, RP2.1, RP2.2, RP2.3, RP2.4, U1.5 (UGND), U1.15 (GND), U1.23 (GND), U1.35 (GND), U1.43 (GND)
unnamed: C7.1, U1.6 (UCAP)
unnamed: C8.2, U1.42 (AREF)
unnamed: C26.2, U1.17 (XTAL1), Y1.1
unnamed: C27.2, U1.16 (XTAL2), Y1.2
unnamed: R2.2, U1.4 (D+)
unnamed: R3.2, U1.3 (D-)
unnamed: R5.2, R6.1

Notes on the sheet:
Pins marked with junctions sign must be with internal RPU enabled!!!
How to enter DFU mode: 1. Press and hold either "OS logo" button or/and "Right arrow" button. 2. Press "Power" button to turn on, then release it. 3. Release the pressed button (s) from point 1. After this point you must use an external USB keyboard for DFU access.

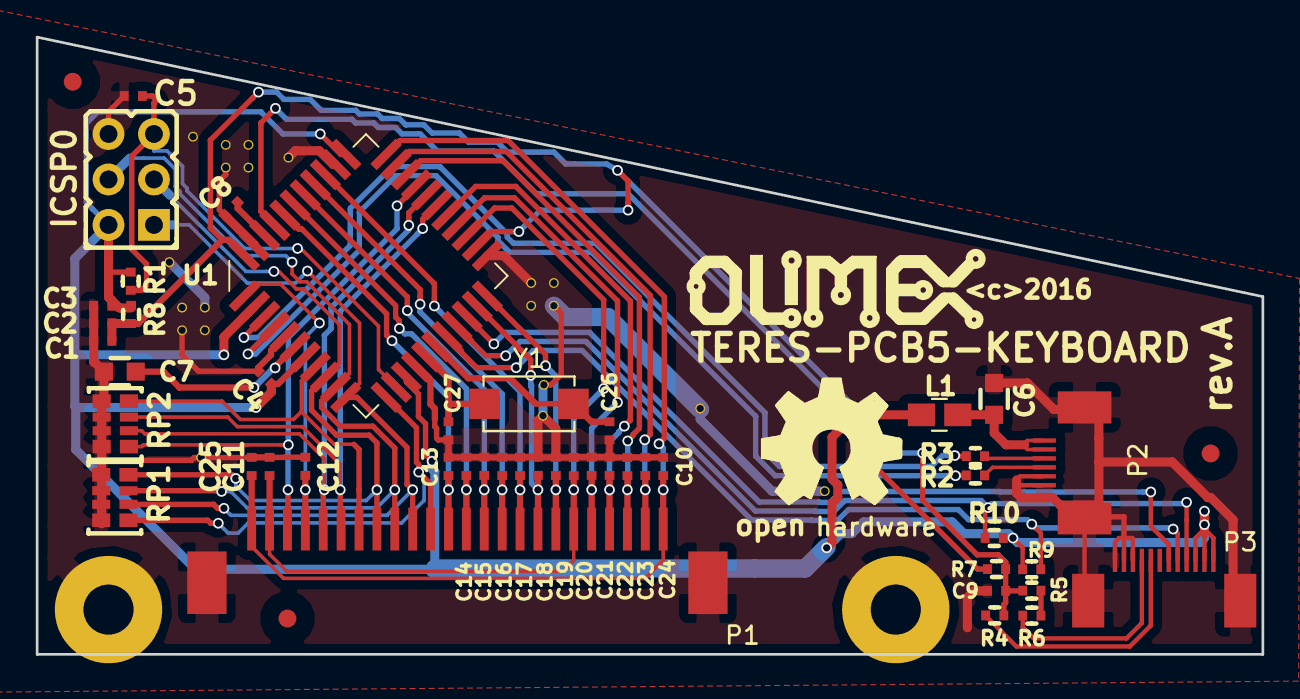
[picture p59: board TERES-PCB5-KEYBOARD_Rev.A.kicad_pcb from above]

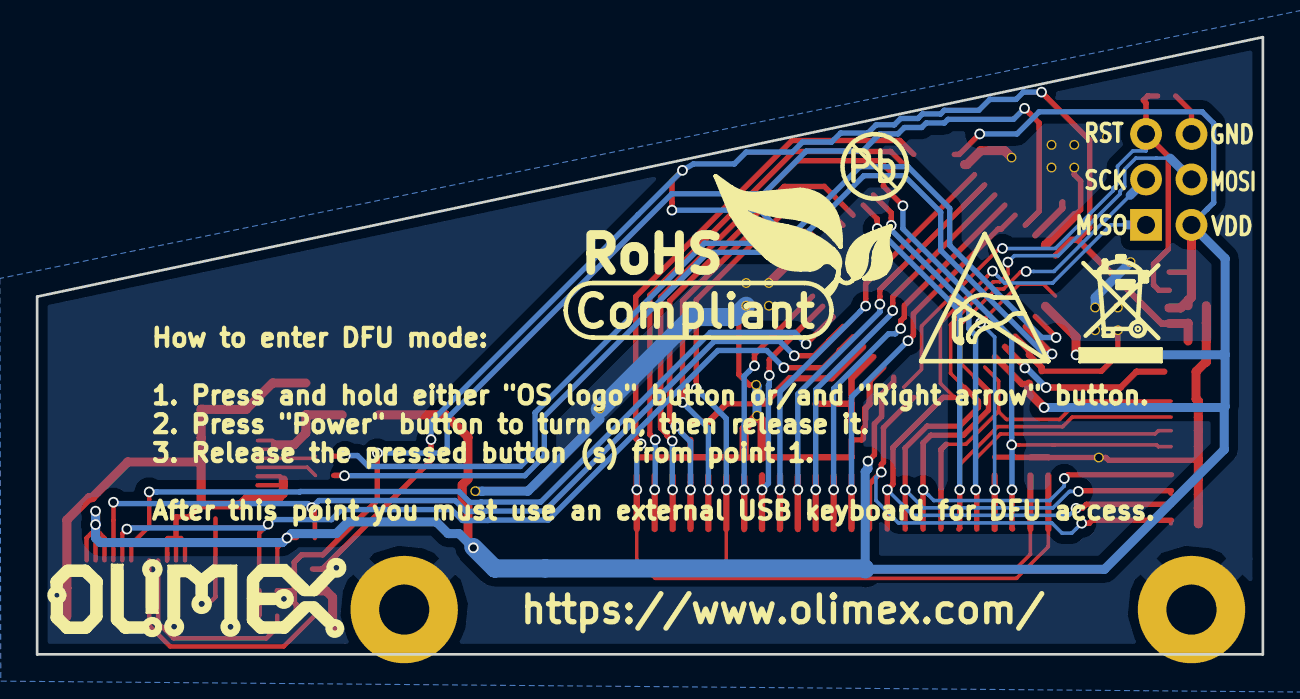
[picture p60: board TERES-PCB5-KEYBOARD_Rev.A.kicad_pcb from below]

Board: 2 copper layers, 68.5 x 34.5 mm, 50 parts (2 on the bottom side), 42 nets.

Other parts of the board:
MountingHole: Mounting_hole_2.5mm
MountingHole#2: Mounting_hole_2.5mm
Ref**: Val**; LOGO_ANTISTATIC_1
Ref**#2: Val**; LOGO_ROHS_1

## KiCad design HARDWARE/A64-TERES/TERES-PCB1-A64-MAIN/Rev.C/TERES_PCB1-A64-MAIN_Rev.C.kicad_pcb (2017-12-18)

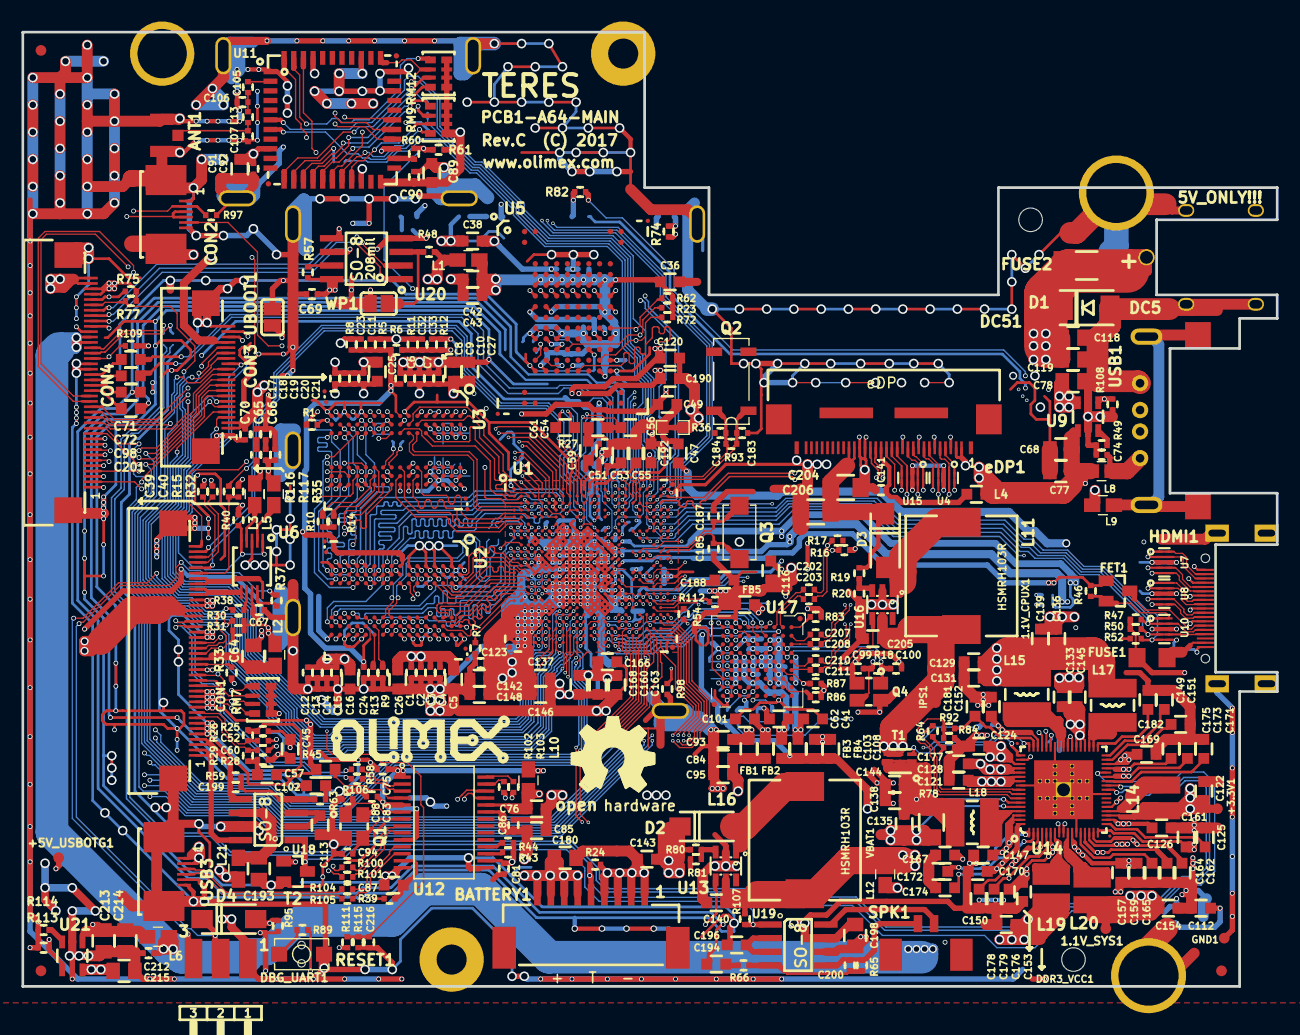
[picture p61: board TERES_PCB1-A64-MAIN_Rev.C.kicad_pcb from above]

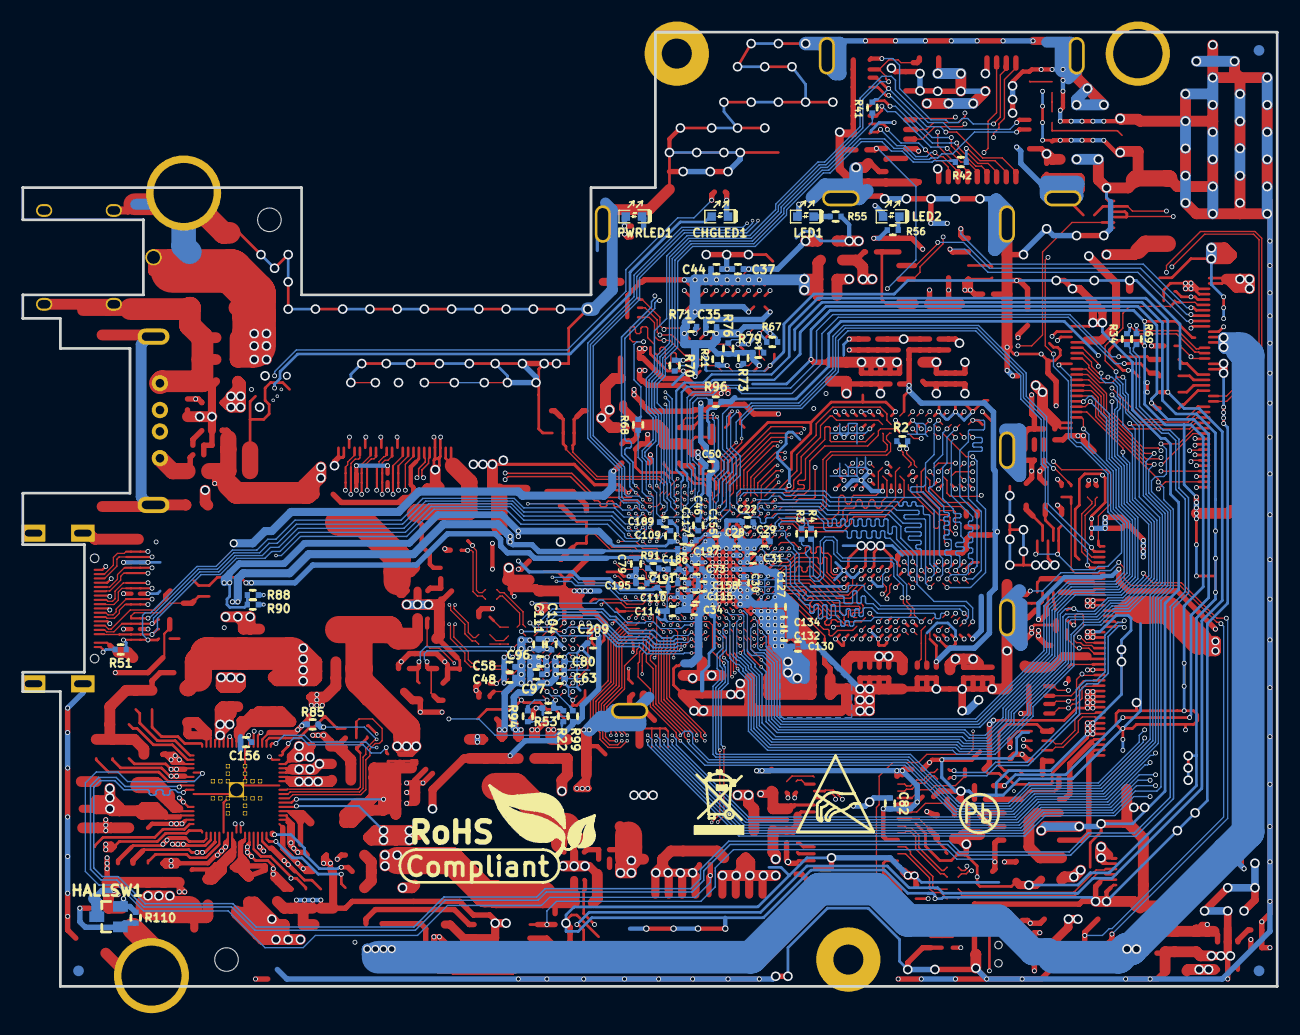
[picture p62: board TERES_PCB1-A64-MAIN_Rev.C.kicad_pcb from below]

Board: 6 copper layers, 117.0 x 89.0 mm, 443 parts (75 on the bottom side), 414 nets.

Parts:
1.1V_CPUX1, 1.1V_SYS1: TESTPAD; TESTPAD_40-ROUND
+3.3V1: TESTPAD; TESTPAD_40-ROUND
+5V_USBOTG1: +5V_USBOTG; TESTPAD_40-ROUND
ANT1: PCB_WIFI_ANT; U.FL-R-SMT-1
BATTERY1: BATTCON; BATCONN-TERES
C1, C2, C3, C4, C6, C7, C8, C9, C11, C12, C13, C14, C15, C17, C18, C19, C20, C22, C23, C24, C25, C28, C29, C30, C31, C32, C33, C34, C35, C37, C39, C40, C44, C46, C50, C51, C52, C60, C65, C66, C67, C69, C70, C73, C74, C75, C79, C81, C82, C83, C86, C90, C92, C109, C110, C114, C115, C117, C123, C127, C130, C132, C134, C141, C155, C156, C158, C177, C186, C189, C191, C195, C197, C202, C203, C207, C208, C209, C210, C211, C212, C216: 100nF; C_0402_5MIL_DWS
C5, C10, C16, C21, C26, C42, C47, C49, C53, C54, C57, C59, C89, C91, C116, C121, C122, C124, C125, C126, C128, C129, C131, C133, C136, C138, C139, C140, C143, C144, C145, C146, C147, C148, C149, C150, C151, C152, C153, C154, C157, C159, C161, C162, C164, C165, C166, C167, C168, C169, C170, C171, C172, C173, C175, C176, C178, C179, C188, C192: 10uF/6.3V/0603; C_0603_5MIL_DWS
C27, C36, C38, C43, C45, C55, C71, C72, C98, C102, C112, C113, C120, C135, C137, C142, C160, C163, C181, C182, C190, C194, C196, C201: 1uF/6.3V/0603; C_0603_5MIL_DWS
C41, C62, C93, C101: 4.7uF/6.3V; C_0603_5MIL_DWS
C48, C63, C96, C104: 100nF/6.3V; C_0402_5MIL_DWS
C56, C61: 2.2uF/6.3V/0603; C_0603_5MIL_DWS
C58, C80, C97, C111: 10nF/6.3V; C_0402_5MIL_DWS
C64, C68, C77, C78, C118, C119, C180, C213, C214, C215: 47uF/6.3V/0805; C_0805_5MIL_DWS
C76: 10uF; C_0603_5MIL_DWS
C84, C95, C103, C108, C205: 22uF/6.3V; C_0603_5MIL_DWS
C85: 10uF; R_0603_5MIL_DWS
C87: 1uF; C_0603_5MIL_DWS
C88, C94, C185, C187: 33pF; C_0402_5MIL_DWS
C99, C100: 22pF; C_0402_5MIL_DWS
C105, C183, C184: 10pF; C_0402_5MIL_DWS
C106: 0.8pF; C_0402_5MIL_DWS
C107: 1.5pF; C_0402_5MIL_DWS
C174: NA(10uF/6.3V/0603); C_0603_5MIL_DWS
C193, C198: 47uF; C_0805_5MIL_DWS
C199, C200: 100pF; C_0402_5MIL_DWS
C204, C206: 22uF/25V; C_1206_5MIL_DWS
CHGLED1: LED/RED/0603; LED_0603_KA
CON1, CON4: CONN_01X40; FPV-WZA21-40-LF
CON2: CONN_01X06; FLEXCON-0.5-6
CON3: CONN_01X20; FPV-WZA21-20-LF
D1: SMBJ6.0A; DO214AA
D2, D3, D4: 1N5822/SS34/SMA; SMA-KA
DBG_UART1: NA(HN1x3); HN1x3(SMD)
DC5: PWR-JACK-THERES; DC-055-TERES
DC51: TESTPAD; TESTPAD_40-ROUND
DDR3_VCC1: TESTPAD; TESTPAD_40-ROUND
FB1, FB2, FB3, FB4, FB5: FB0603/600R/200mA; L_0603_5MIL_DWS
FET1: BSS138(SOT23-3); SOT23
FUSE1: FSMD035; FUSE-1206
FUSE2: NA(5025); FUSE-5025
GND1: TESTPAD; TESTPAD_40-ROUND
HALLSW1: TCS40DPR; SOT23
HDMI1: HDMI-SWM-19; HDMI-MINI-TERES
HOLE1, HOLE2, HOLE3, HOLE4, HOLE5, HOLE6, HOLE7, HOLE8, HOLE9: TESTPAD; Oval_Drill
IPS1: TESTPAD; TESTPAD_40-ROUND
L1, L2, L3, L5, L6, L8, L9, L10, L12, L21: FB0805/600R/2A; L_0805_5MIL_DWS
L4: FB0603/600R/200mA; L_0603_5MIL_DWS
L11: HSMRH103R-220M; HSMRH103R
L13: 3.3nH; R_0402_5MIL_DWS
L14, L19, L20: SWPA3015S1R5NT(1.5uH/2.30A/DCR<0.1R/CD32); CD32
L15, L17, L18: SWPA4018S1R5NT(1.5uH/3.35A/DCR<0.1R/CD43); CD42(43)
L16: HSMRH103R-2R5M; HSMRH103R
LED1, LED2: GREEN; LED_0603_KA
MountingHole: Mounting_hole_3.3mm
MountingHole#2: Mounting_hole_3.3mm; Mounting_hole_2.8mm
MountingHole#3, MountingHole#5: Mounting_hole_3.3mm; NPTH_2.2mm
MountingHole#4, MountingHole#6: Mounting_hole_3.3mm; Mounting_hole_5.6mm_TERES
MountingHole#7: Mounting_hole_3.3mm; Mounting_hole_TERES_4.6mm
PWRLED1: LED/Green/0603; LED_0603_KA
Q1: 12MHz-20pf; TSX-3.2x2.5mm_GND(3)
Q2: MC-306_32.768KHZ/SMD_8038/6pF; MC306-HS
Q3: 4SB24.000F20E15/5x3.2mm/20ppm/20pF; Q5x3.25
Q4: 27.000MHz/20ppm; TSX-3.2x2.5mm_GND(3)
R1, R5, R8, R11, R12, R74: 2k/1%; R_0402_5MIL_DWS
R2: 100R/1%; R_0402_5MIL_DWS
R3, R4, R33, R34, R41, R42, R54, R58, R68, R69, R100, R101, R102, R103, R104, R105, R106, R116, R117: 22R; R_0402_5MIL_DWS
R6, R62, R70, R71, R72, R73, R76, R79, R96, R97, R98: NA; R_0402_5MIL_DWS
R7, R9, R10: 240R/1%; R_0402_5MIL_DWS
R13, R14: NA(243R/1%); R_0402_5MIL_DWS
R15: 47K; R_0402_5MIL_DWS
R16, R17: (na)100K; R_0402_5MIL_DWS
R18, R32: 1M; R_0402_5MIL_DWS
R19: 22.1K /1%; R_0402_5MIL_DWS
R20: 1.1K/1%; R_0402_5MIL_DWS
R21, R23, R31, R39, R40, R43, R48, R52, R57, R85, R95, R108, R109, R110, R113, R115: 10k; R_0402_5MIL_DWS
R22, R25, R28, R64, R86, R89, R92: 1k; R_0402_5MIL_DWS
R24: NA(10K); R_0402_5MIL_DWS
R26, R29, R55, R56: 1.5k; R_0402_5MIL_DWS
R27: 200k/1%; R_0402_5MIL_DWS
R30, R35, R53: 100k; R_0402_5MIL_DWS
R36: 0R(Board_Mounted); 0R_0603
R37, R38: 220R; R_0402_5MIL_DWS
R44, R46, R67: 47k; R_0402_5MIL_DWS
R45: 680R/1%; R_0603_5MIL_DWS
R47, R50, R82, R87, R88, R90, R94, R99, R112: 2.2k; R_0402_5MIL_DWS
R49: 10k/1%; R_0402_5MIL_DWS
R51, R75, R77, R111: 4.7k; R_0402_5MIL_DWS
R59, R65: 22.1K/1%; R_0402_5MIL_DWS
R60, R91: NA(0R); R_0402_5MIL_DWS
R61: NA(10k); R_0402_5MIL_DWS
R63, R66: 12k/1%; R_0402_5MIL_DWS
R78: 0.01R/1%/1206; R_1206_5MIL_DWS
R80: 8.25k/1%; R_0402_5MIL_DWS
R81: 1.1k/1%; R_0402_5MIL_DWS
R83: 12K_1%; R_0402_5MIL_DWS
R84: na(1k); R_0402_5MIL_DWS
R93: 10M; R_0402_5MIL_DWS
R107: 150K; R_0402_5MIL_DWS
R114: 13k/1%; R_0402_5MIL_DWS
RESET1: IT1185AU2; uTACTIL
RM7, RM9, RM12: RA1206_(4x0603)_4B8_100k; R_MATRIX_4
Ref**: Val**; LOGO_ANTISTATIC_1
Ref**#2: Val**; LOGO_ROHS_1
SPK1: SPK1; CON-SPK-TERES
T1: WPM1481(DFN2X2-6L); DFN2x2-6L
T2: DTC114YKA(SOT-23); SOT23
U1: AllWinner-A64(FBGA396); FBGA396
U2, U3: K4B4G1646Q-HYK0(FBGA-96_256Mx16_DDR3-1600_11-11-1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; FBGA96(HYNIX_SAMSUNG_512MX16_DDR3)
U4, U7, U8, U10, U15: RCLAMP0524P(SLP2510P8); SLP2510P8
U5: MTFC4GACAANA-4M_IT(TBGA100); TBGA100
U6: TS5A23159; VSSOP-10
U9, U21: SY6280AAC(SOT23-5); SOT-23-5
U11: RTL8723BS(ComboModule); RL-SM02BD(RTL8723BS)
U12: GL850G-SO28; SSOP28
U13, U16: MT3608(SOT23-6); SOT23-6
U14: AXP803(QFN68_8x8mm); QFN68
U17: ANX6345; BGA_8x8mm_81p_0.8
U18, U19: TS4871; SO-8
U20: W25Q128FVSSIG; SO-8_208mil
UBOOT1: Open; SJ
USB1: USB_A_THERES; USB-A-TERES
USB3: USB3; FLEXCON-0.5-6
VBAT1: TESTPAD; TESTPAD_40-ROUND
WP1: Open; SJ
eDP1: LCD_CONN; eDP-TERES

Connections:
1.1V_CPUS: C117.2, C120.2, C179.2, U1.H15, U14.5
1.1V_CPUX: 1.1V_CPUX1.1, C123.2, C127.2, C129.2, C130.2, C131.2, C132.2, C134.2, C136.2, C137.2, C139.2, C142.2, C146.2, C148.2, L15.2, L17.2, U1.AA1, U1.AA3, U1.AB2, U1.AC1, U1.AC2, U1.U6, U1.V2, U1.V3, U1.V4, U1.V5, U1.V6, U1.W1, U1.W3, U1.W4, U1.W5, U1.Y2, U1.Y3, U1.Y4
1.1V_SYS: 1.1V_SYS1.1, C154.2, C155.2, C158.2, C160.2, C163.2, C166.2, C168.2, L20.2, U1.J12, U1.J13, U1.K14, U1.L13, U1.L14, U1.M13, U1.M14, U1.N14, U1.P14, U1.R13, U1.R14, U1.T15, U14.9
1.2V_HSIC: C178.2, C197.1, CON3.17, U1.K16, U14.3
3.0V_RTC: C152.1, C189.2, C190.2, R85.2, U1.H16, U14.49
#DEBUGSELECT: R40.2, U1.D20, U6.1, U6.5
+1.5V: C1.1, C2.1, C3.1, C4.1, C5.1, C6.1, C7.1, C8.1, C9.1, C10.1, C11.1, C12.1, C13.1, C14.1, C15.1, C16.1, C17.1, C18.1, C19.1, C20.1, C21.1, C26.1, C27.1, C28.1, C29.1, C30.1, C31.1, C32.2, C150.2, DDR3_VCC1.1, L19.2, R1.2, R5.2, R11.2, U1.G7, U1.G8, U1.G9, U1.J8, U1.K6, U1.K7, U1.L6, U1.L7, U1.L8, U1.N7, U1.N8, U2.A1, U2.A8, U2.B2, U2.C1, U2.C9, U2.D2, U2.D9, U2.E9, U2.F1, U2.G7, U2.H2, U2.H9, U2.K2, U2.K8, U2.N1, U2.N9, U2.R1, U2.R9, U3.A1, U3.A8, U3.B2, U3.C1, U3.C9, U3.D2, U3.D9, U3.E9, U3.F1, U3.G7, U3.H2, U3.H9, U3.K2, U3.K8, U3.N1, U3.N9, U3.R1, U3.R9, U14.8
+1V8: C47.2, C50.2, C170.2, U1.E13, U14.68
+3.0VA: C46.1, C49.1, C175.1, C191.2, R32.2, U1.G14, U1.N16, U14.31
+3.3VD: C79.2, C161.2, FET1.1, R46.1, U1.M16, U14.17
+3V3: +3.3V1.1, C34.2, C69.2, C70.2, C73.2, C91.2, C92.2, C112.2, C114.2, C115.2, C116.2, C122.2, C195.2, CON3.1, CON3.2, CON4.37, CON4.38, HALLSW1.1, L1.1, L2.1, L14.2, R16.1, R30.2, R31.2, R48.2, R57.2, R74.1, R75.1, R77.1, R91.1, R95.2, R109.2, R110.2, RM7.1.1, RM7.2.1, RM7.3.1, RM7.4.1, U1.L16, U1.N19, U1.R16, U1.T14, U1.U15, U1.U18, U11.9, U13.4, U14.20, U20.8, eDP1.1, eDP1.2
+5V: C78.1, C143.2, C215.1, D2.1, R80.1, U9.5, U21.5
/NAND Flash , eMMC, T-Card and Audio/FC_MIC_N: C60.1, CON1.8, R29.1
/NAND Flash , eMMC, T-Card and Audio/FC_MIC_P: C52.1, CON1.9, R26.1
/NAND Flash , eMMC, T-Card and Audio/HBIAS: CON1.40, U1.D13
/NAND Flash , eMMC, T-Card and Audio/HP-DET: R15.2, U1.D11
/NAND Flash , eMMC, T-Card and Audio/HPOUTL: L5.1, R35.2, R117.2, U1.C13
/NAND Flash , eMMC, T-Card and Audio/HPOUTR: L3.1, R116.2, U1.C12
/NAND Flash , eMMC, T-Card and Audio/HS-MIC: CON1.39, U1.B10
/NAND Flash , eMMC, T-Card and Audio/HUSB2-D+: CON1.25, R106.1
/NAND Flash , eMMC, T-Card and Audio/HUSB2-D-: CON1.26, R58.1
/NAND Flash , eMMC, T-Card and Audio/MBIAS: C45.2, R25.2, U1.E14
/NAND Flash , eMMC, T-Card and Audio/MICIN1_N: C60.2, U1.B16
/NAND Flash , eMMC, T-Card and Audio/MICIN1_P: C52.2, U1.B15
/NAND Flash , eMMC, T-Card and Audio/MICIN2+: C39.2, CON1.38
/NAND Flash , eMMC, T-Card and Audio/MICIN2-: C40.2, CON1.37
/NAND Flash , eMMC, T-Card and Audio/MICIN2_N: C40.1, U1.A17
/NAND Flash , eMMC, T-Card and Audio/MICIN2_P: C39.1, U1.B17
/NAND Flash , eMMC, T-Card and Audio/SDC0-CLK: R33.2, U1.AC8
/NAND Flash , eMMC, T-Card and Audio/SDC0-CMD: CON1.20, R31.1, U1.W9
/NAND Flash , eMMC, T-Card and Audio/SDC0-D0: CON1.16, RM7.3.2, U1.W13
/NAND Flash , eMMC, T-Card and Audio/SDC0-D1: CON1.15, RM7.2.2, U1.AB10
/NAND Flash , eMMC, T-Card and Audio/SDC0-D2: CON1.22, RM7.4.2, U1.AB9
/NAND Flash , eMMC, T-Card and Audio/SDC0-D3: CON1.21, R30.1, U1.AB6
/NAND Flash , eMMC, T-Card and Audio/SDC0-DET#: CON1.14, RM7.1.2, U1.AB8
/NAND Flash , eMMC, T-Card and Audio/SDC2-CLK: R68.2, U1.G20
/NAND Flash , eMMC, T-Card and Audio/SDC2-CMD: R21.1, U1.K19, U5.P5
/NAND Flash , eMMC, T-Card and Audio/SDC2-D0: R67.1, U1.M21, U5.K2
/NAND Flash , eMMC, T-Card and Audio/SDC2-D1: R79.1, U1.L19, U5.N2
/NAND Flash , eMMC, T-Card and Audio/SDC2-D2: R76.1, U1.K20, U5.K3
/NAND Flash , eMMC, T-Card and Audio/SDC2-D3: R73.1, U1.H20, U5.N3
/NAND Flash , eMMC, T-Card and Audio/SDC2-D4: R72.1, U1.P18, U5.N8
/NAND Flash , eMMC, T-Card and Audio/SDC2-D5: R71.1, U1.L20, U5.K8
/NAND Flash , eMMC, T-Card and Audio/SDC2-D6: R70.1, U1.J21, U5.N9
/NAND Flash , eMMC, T-Card and Audio/SDC2-D7: R62.1, U1.R21, U5.K9
/NAND Flash , eMMC, T-Card and Audio/SDC2-RST: R23.1, U1.N20, U5.M5
/NAND Flash , eMMC, T-Card and Audio/SPKR_N: C199.1, CON1.3, CON1.4, R59.1, U18.5
/NAND Flash , eMMC, T-Card and Audio/SPKR_P: CON1.1, CON1.2, U18.8
/Power Supply, Extensions and MiPi-DSI/AXP_USB+: R34.1, U14.26
/Power Supply, Extensions and MiPi-DSI/AXP_USB-: R69.1, U14.27
/Power Supply, Extensions and MiPi-DSI/DC5SET: R84.2, R92.1, U14.62
/Power Supply, Extensions and MiPi-DSI/HS_DAT: CON3.19, U1.G19
/Power Supply, Extensions and MiPi-DSI/HS_STR: CON3.18, U1.H19
/Power Supply, Extensions and MiPi-DSI/JTAGSEL0: CON2.2, R97.1, U1.AA11
/Power Supply, Extensions and MiPi-DSI/PB0: CON4.16, U1.V9
/Power Supply, Extensions and MiPi-DSI/PB1: CON4.15, U1.AB7
/Power Supply, Extensions and MiPi-DSI/PB2: CON4.14, U1.W10
/Power Supply, Extensions and MiPi-DSI/PB3: CON4.13, U1.AA7
/Power Supply, Extensions and MiPi-DSI/PB4: CON3.6, U1.W7
/Power Supply, Extensions and MiPi-DSI/PB5: CON3.5, U1.AA6
/Power Supply, Extensions and MiPi-DSI/PB6: CON3.4, U1.W8
/Power Supply, Extensions and MiPi-DSI/PB7: CON3.3, U1.Y6
/Power Supply, Extensions and MiPi-DSI/PE0: CON4.12, U1.AA18
/Power Supply, Extensions and MiPi-DSI/PE1: CON4.11, U1.AB23
/Power Supply, Extensions and MiPi-DSI/PE2: CON4.10, U1.AA22
/Power Supply, Extensions and MiPi-DSI/PE3: CON4.9, U1.AA21
/Power Supply, Extensions and MiPi-DSI/PE4: CON4.8, U1.AA19
/Power Supply, Extensions and MiPi-DSI/PE5: CON4.7, U1.W17
/Power Supply, Extensions and MiPi-DSI/PE6: CON4.6, U1.W20
/Power Supply, Extensions and MiPi-DSI/PE7: CON4.5, U1.Y19
/Power Supply, Extensions and MiPi-DSI/PE8: CON4.4, U1.AC22
/Power Supply, Extensions and MiPi-DSI/PE9: CON4.3, U1.Y17
/Power Supply, Extensions and MiPi-DSI/PE10: CON4.2, U1.AB22
/Power Supply, Extensions and MiPi-DSI/PE11: CON4.1, U1.W21
/Power Supply, Extensions and MiPi-DSI/PE12: CON3.12, U1.AB20
/Power Supply, Extensions and MiPi-DSI/PE13: CON3.11, U1.Y22
/Power Supply, Extensions and MiPi-DSI/PE14: CON3.10, U1.AC20
/Power Supply, Extensions and MiPi-DSI/PE15: CON3.9, U1.Y23
/Power Supply, Extensions and MiPi-DSI/PE16: CON3.8, U1.AB21
/Power Supply, Extensions and MiPi-DSI/PE17: CON3.7, U1.W22
/R_S0SCK_N: R4.2, U1.G3
/R_S0SCK_P: R3.2, U1.G2
/S0SA0: U1.P5, U2.N3, U3.N3
/S0SA1: U1.R4, U2.P7, U3.P7
/S0SA2: U1.N5, U2.P3, U3.P3
/S0SA3: U1.N6, U2.N2, U3.N2
/S0SA4: U1.P6, U2.P8, U3.P8
/S0SA5: U1.G4, U2.P2, U3.P2
/S0SA6: U1.F3, U2.R8, U3.R8
/S0SA7: U1.E4, U2.R2, U3.R2
/S0SA8: U1.D3, U2.T8, U3.T8
/S0SA9: U1.C4, U2.R3, U3.R3
/S0SA10: U1.M4, U2.L7, U3.L7
/S0SA11: U1.U4, U2.R7, U3.R7
/S0SA12: U1.K5, U2.N7, U3.N7
/S0SA13: U1.E8, U2.T3, U3.T3
/S0SA14: U1.K4, U2.T7, U3.T7
/S0SA15: U1.T4, U2.M7, U3.M7
/S0SBA0: U1.D8, U2.M2, U3.M2
/S0SBA1: U1.R3, U2.N8, U3.N8
/S0SBA2: U1.C6, U2.M3, U3.M3
/S0SCAS: U1.C9, U2.K3, U3.K3
/S0SCKE0: U1.J3, U2.K9, U3.K9
/S0SCKE1: U1.H6, U2.J9, U3.J9
/S0SCK_N: R2.1, R4.1, U2.K7, U3.K7
/S0SCK_P: R2.2, R3.1, U2.J7, U3.J7
/S0SCS0: U1.E5, U2.L2, U3.L2
/S0SCS1: U1.H5, U2.L1, U3.L1
/S0SDQ0: U1.L3, U2.F7
/S0SDQ1: U1.G1, U2.G2
/S0SDQ2: U1.H3, U2.F2
/S0SDQ3: U1.K1, U2.H7
/S0SDQ4: U1.H2, U2.E3
/S0SDQ5: U1.H1, U2.H3
/S0SDQ6: U1.L1, U2.H8
/S0SDQ7: U1.L2, U2.F8
/S0SDQ8: U1.T3, U2.A7
/S0SDQ9: U1.T2, U2.C8
/S0SDQ10: U1.T1, U2.B8
/S0SDQ11: U1.R2, U2.D7
/S0SDQ12: U1.N3, U2.A3
/S0SDQ13: U1.N2, U2.C2
/S0SDQ14: U1.N1, U2.C3
/S0SDQ15: U1.M2, U2.A2
/S0SDQ16: U1.E3, U3.F7
/S0SDQ17: U1.F2, U3.H8
/S0SDQ18: U1.E2, U3.H7
/S0SDQ19: U1.E1, U3.F8
/S0SDQ20: U1.B1, U3.E3
/S0SDQ21: U1.B2, U3.H3
/S0SDQ22: U1.A2, U3.G2
/S0SDQ23: U1.B3, U3.F2
/S0SDQ24: U1.C5, U3.B8
/S0SDQ25: U1.B4, U3.D7
/S0SDQ26: U1.A4, U3.C8
/S0SDQ27: U1.A5, U3.A7
/S0SDQ28: U1.A7, U3.C3
/S0SDQ29: U1.A8, U3.C2
/S0SDQ30: U1.B8, U3.A3
/S0SDQ31: U1.B9, U3.A2
/S0SDQM0: U1.J2, U2.E7
/S0SDQM1: U1.P3, U2.D3
/S0SDQM2: U1.C2, U3.E7
/S0SDQM3: U1.B7, U3.D3
/S0SDQS0_N: U1.K2, U2.G3
/S0SDQS0_P: U1.K3, U2.F3
/S0SDQS1_N: U1.P2, U2.B7
/S0SDQS1_P: U1.P1, U2.C7
/S0SDQS2_N: U1.D1, U3.G3
/S0SDQS2_P: U1.D2, U3.F3
/S0SDQS3_N: U1.B5, U3.B7
/S0SDQS3_P: U1.B6, U3.C7
/S0SODT0: U1.D5, U2.K1, U3.K1
/S0SODT1: U1.E7, U2.J1, U3.J1
/S0SRAS: U1.F7, U2.J3, U3.J3
/S0SRST: R1.1, U1.D10, U2.T2, U3.T2
/S0SVREF: C22.2, C32.1, C33.2, R6.2, R11.1, R12.2, U1.G5
/S0SWE: U1.C8, U2.L3, U3.L3
/USB&HDMI,WiFi&BT,Ethernet,LCD/AP-WAKE-BT: U1.B20, U11.6
/USB&HDMI,WiFi&BT,Ethernet,LCD/BT-PCM-CLK: U1.AB18, U11.26
/USB&HDMI,WiFi&BT,Ethernet,LCD/BT-PCM-DIN: U1.AC19, U11.27
/USB&HDMI,WiFi&BT,Ethernet,LCD/BT-PCM-DOUT: U1.U22, U11.25
/USB&HDMI,WiFi&BT,Ethernet,LCD/BT-PCM-SYNC: U1.AB19, U11.28
/USB&HDMI,WiFi&BT,Ethernet,LCD/BT-RST-N: RM12.3.2, U1.A20, U11.34
/USB&HDMI,WiFi&BT,Ethernet,LCD/BT-UART-CTS: U1.AC17, U11.44
/USB&HDMI,WiFi&BT,Ethernet,LCD/BT-UART-RX: RM12.4.2, U1.AB17, U11.43
/USB&HDMI,WiFi&BT,Ethernet,LCD/BT-UART-TX: U1.U23, U11.42
/USB&HDMI,WiFi&BT,Ethernet,LCD/BT-WAKE-AP: U1.D19, U11.7
/USB&HDMI,WiFi&BT,Ethernet,LCD/HCEC: FET1.2, R46.2, U1.F21, U10.1, U10.10
/USB&HDMI,WiFi&BT,Ethernet,LCD/HHPD: R51.1, R52.1, U1.E21, U10.5, U10.6
/USB&HDMI,WiFi&BT,Ethernet,LCD/HSCL: HDMI1.15, R47.2, U1.G21, U10.2, U10.9
/USB&HDMI,WiFi&BT,Ethernet,LCD/HSDA: HDMI1.16, R50.2, U1.E20, U10.4, U10.7
/USB&HDMI,WiFi&BT,Ethernet,LCD/HTX0_N: HDMI1.9, U1.G23, U8.2, U8.9
/USB&HDMI,WiFi&BT,Ethernet,LCD/HTX0_P: HDMI1.8, U1.G22, U8.1, U8.10
/USB&HDMI,WiFi&BT,Ethernet,LCD/HTX1_N: HDMI1.6, U1.F22, U7.5, U7.6
/USB&HDMI,WiFi&BT,Ethernet,LCD/HTX1_P: HDMI1.5, U1.E23, U7.4, U7.7
/USB&HDMI,WiFi&BT,Ethernet,LCD/HTX2_N: HDMI1.3, U1.E22, U7.2, U7.9
/USB&HDMI,WiFi&BT,Ethernet,LCD/HTX2_P: HDMI1.2, U1.D23, U7.1, U7.10
/USB&HDMI,WiFi&BT,Ethernet,LCD/HTXC_N: HDMI1.12, U1.H23, U8.5, U8.6
/USB&HDMI,WiFi&BT,Ethernet,LCD/HTXC_P: HDMI1.11, U1.H22, U8.4, U8.7
/USB&HDMI,WiFi&BT,Ethernet,LCD/HUSB1-D+: R103.1, USB1.3
/USB&HDMI,WiFi&BT,Ethernet,LCD/HUSB1-D-: R102.1, USB1.2
/USB&HDMI,WiFi&BT,Ethernet,LCD/HUSB1-D_N: R102.2, U12.27
/USB&HDMI,WiFi&BT,Ethernet,LCD/HUSB1-D_P: R103.2, U12.28
/USB&HDMI,WiFi&BT,Ethernet,LCD/HUSB4-D+: R105.1, USB3.4
/USB&HDMI,WiFi&BT,Ethernet,LCD/HUSB4-D-: R104.1, USB3.3
/USB&HDMI,WiFi&BT,Ethernet,LCD/HUSB4-D_N: R104.2, U12.11
/USB&HDMI,WiFi&BT,Ethernet,LCD/HUSB4-D_P: R105.2, U12.12
/USB&HDMI,WiFi&BT,Ethernet,LCD/USB0-VBUSDET: C216.2, R111.1, R115.2, U1.AB4
/USB&HDMI,WiFi&BT,Ethernet,LCD/USB1-DRV: R108.2, U1.C19, U9.4
/USB&HDMI,WiFi&BT,Ethernet,LCD/USB1-D_N: U1.C22, U12.25
/USB&HDMI,WiFi&BT,Ethernet,LCD/USB1-D_P: U1.B23, U12.26
/USB&HDMI,WiFi&BT,Ethernet,LCD/WL-PMU-EN: R41.1, RM12.2.2, U11.12
/USB&HDMI,WiFi&BT,Ethernet,LCD/WL-SDIO-CLK: R54.2, U1.V21
/USB&HDMI,WiFi&BT,Ethernet,LCD/WL-SDIO-CMD: RM9.3.2, U1.U20, U11.16
/USB&HDMI,WiFi&BT,Ethernet,LCD/WL-SDIO-D0: RM9.1.2, U1.U19, U11.18
/USB&HDMI,WiFi&BT,Ethernet,LCD/WL-SDIO-D1: RM9.2.2, U1.V22, U11.19
/USB&HDMI,WiFi&BT,Ethernet,LCD/WL-SDIO-D2: RM9.4.2, U1.Y21, U11.14
/USB&HDMI,WiFi&BT,Ethernet,LCD/WL-SDIO-D3: RM12.1.2, U1.W23, U11.15
/USB&HDMI,WiFi&BT,Ethernet,LCD/WL-WAKE-AP: R42.1, U11.13
/VREF0_DDR3: C11.2, C23.1, C24.1, C25.1, R5.1, R6.1, R8.2, U2.H1, U2.M8, U3.H1, U3.M8
/eDP LCD/1.2V: C93.2, C96.2, C97.2, FB1.2, U17.F4, U17.F5, U17.F6
/eDP LCD/2.5V: C62.2, C63.2, C80.2, FB3.2, U17.E7, U17.F7, U17.G4, U17.G5
/eDP LCD/A1.2V: C101.2, C104.2, C111.2, FB2.2, U17.D4, U17.E4
/eDP LCD/A2.5V: C41.2, C48.2, C58.2, FB4.2, U17.C3, U17.C4, U17.C5, U17.C6, U17.C7, U17.D3
/eDP LCD/BKLT_ON: U1.AC10, U15.5, U15.6, U16.4, eDP1.14
/eDP LCD/BKLT_PWM: U1.Y13, eDP1.15
/eDP LCD/EDP_AUX+: C202.1, U17.C1
/eDP LCD/EDP_AUX-: C203.1, U17.B1
/eDP LCD/EDP_AUX_N: C203.2, R16.2, U4.2, U4.9, eDP1.5
/eDP LCD/EDP_AUX_P: C202.2, R17.2, U4.1, U4.10, eDP1.4
/eDP LCD/EDP_HPD_CON: R22.2, U15.4, U15.7, eDP1.13
/eDP LCD/EDP_LANE0+: C207.1, U17.A2
/eDP LCD/EDP_LANE0-: C208.1, U17.A3
/eDP LCD/EDP_LANE0_N: C208.2, U4.4, U4.7, eDP1.7
/eDP LCD/EDP_LANE0_P: C207.2, U4.5, U4.6, eDP1.8
/eDP LCD/EDP_LANE1+: C210.1, U17.A5
/eDP LCD/EDP_LANE1-: C211.1, U17.A6
/eDP LCD/EDP_LANE1_N: C211.2, U15.1, U15.10, eDP1.10
/eDP LCD/EDP_LANE1_P: C210.2, U15.2, U15.9, eDP1.11
/eDP LCD/HUSB3+: R101.2, eDP1.18
/eDP LCD/HUSB3-: R100.2, eDP1.17
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

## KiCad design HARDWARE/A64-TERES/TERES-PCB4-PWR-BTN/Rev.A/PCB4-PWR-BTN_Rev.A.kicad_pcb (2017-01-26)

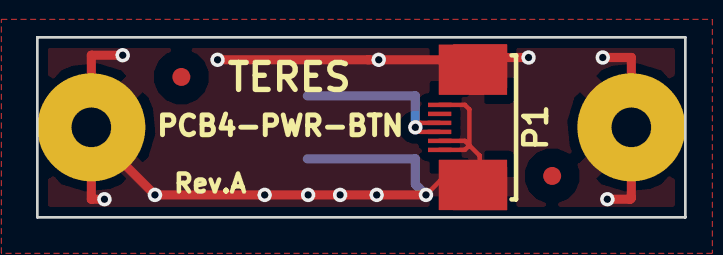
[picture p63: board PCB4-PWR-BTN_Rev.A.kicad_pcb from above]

Board: 2 copper layers, 36.0 x 10.0 mm, 4 parts (1 on the bottom side), 2 nets.

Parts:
MountingHole: Mounting_hole_2.5mm
MountingHole#2: Mounting_hole_2.5mm
P1: CONN_01X06; FLEXCON-0.5-6
SW1: SW_PUSH; tacktil_5x5_teres

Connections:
GND: P1.0, P1.1, P1.2, P1.6, SW1.1
unnamed: P1.3, P1.4, SW1.2

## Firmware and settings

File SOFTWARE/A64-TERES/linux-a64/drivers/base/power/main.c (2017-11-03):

/*
 * drivers/base/power/main.c - Where the driver meets power management.
 *
 * Copyright (c) 2003 Patrick Mochel
 * Copyright (c) 2003 Open Source Development Lab
 *
 * This file is released under the GPLv2
 *
 *
 * The driver model core calls device_pm_add() when a device is registered.
 * This will initialize the embedded device_pm_info object in the device
 * and add it to the list of power-controlled devices. sysfs entries for
 * controlling device power management will also be added.
 *
 * A separate list is used for keeping track of power info, because the power
 * domain dependencies may differ from the ancestral dependencies that the
 * subsystem list maintains.
 */

#include <linux/device.h>
#include <linux/kallsyms.h>
#include <linux/export.h>
#include <linux/mutex.h>
#include <linux/pm.h>
#include <linux/pm_runtime.h>
#include <linux/resume-trace.h>
#include <linux/interrupt.h>
#include <linux/sched.h>
#include <linux/async.h>
#include <linux/suspend.h>
#include <trace/events/power.h>
#include <linux/cpufreq.h>
#include <linux/cpuidle.h>
#include <linux/timer.h>
#include <linux/wakeup_reason.h>
#include <linux/delay.h>

#include "../base.h"
#include "power.h"

typedef int (*pm_callback_t)(struct device *);

/*
 * The entries in the dpm_list list are in a depth first order, simply
 * because children are guaranteed to be discovered after parents, and
 * are inserted at the back of the list on discovery.
 *
 * Since device_pm_add() may be called with a device lock held,
 * we must never try to acquire a device lock while holding
 * dpm_list_mutex.
 */

LIST_HEAD(dpm_list);
static LIST_HEAD(dpm_prepared_list);
static LIST_HEAD(dpm_suspended_list);
static LIST_HEAD(dpm_late_early_list);
static LIST_HEAD(dpm_noirq_list);

struct suspend_stats suspend_stats;
static DEFINE_MUTEX(dpm_list_mtx);
static pm_message_t pm_transition;

struct dpm_watchdog {
	struct device		*dev;
	struct task_struct	*tsk;
	struct timer_list	timer;
};

static int async_error;

/**
 * device_pm_sleep_init - Initialize system suspend-related device fields.
 * @dev: Device object being initialized.
 */
void device_pm_sleep_init(struct device *dev)
{
	dev->power.is_prepared = false;
	dev->power.is_suspended = false;
	init_completion(&dev->power.completion);
	complete_all(&dev->power.completion);
	dev->power.wakeup = NULL;
	INIT_LIST_HEAD(&dev->power.entry);
}

/**
 * device_pm_lock - Lock the list of active devices used by the PM core.
 */
void device_pm_lock(void)
{
	mutex_lock(&dpm_list_mtx);
}

/**
 * device_pm_unlock - Unlock the list of active devices used by the PM core.
 */
void device_pm_unlock(void)
{
	mutex_unlock(&dpm_list_mtx);
}

/**
 * device_pm_add - Add a device to the PM core's list of active devices.
 * @dev: Device to add to the list.
 */
void device_pm_add(struct device *dev)
{
	pr_debug("PM: Adding info for %s:%s\n",
		 dev->bus ? dev->bus->name : "No Bus", dev_name(dev));
	mutex_lock(&dpm_list_mtx);
	if (dev->parent && dev->parent->power.is_prepared)
		dev_warn(dev, "parent %s should not be sleeping\n",
			dev_name(dev->parent));
	list_add_tail(&dev->power.entry, &dpm_list);
	mutex_unlock(&dpm_list_mtx);
}

/**
 * device_pm_remove - Remove a device from the PM core's list of active devices.
 * @dev: Device to be removed from the list.
 */
void device_pm_remove(struct device *dev)
{
	pr_debug("PM: Removing info for %s:%s\n",
		 dev->bus ? dev->bus->name : "No Bus", dev_name(dev));
	complete_all(&dev->power.completion);
	mutex_lock(&dpm_list_mtx);
	list_del_init(&dev->power.entry);
	mutex_unlock(&dpm_list_mtx);
	device_wakeup_disable(dev);
	pm_runtime_remove(dev);
}

/**
 * device_pm_move_before - Move device in the PM core's list of active devices.
 * @deva: Device to move in dpm_list.
 * @devb: Device @deva should come before.
 */
void device_pm_move_before(struct device *deva, struct device *devb)
{
	pr_debug("PM: Moving %s:%s before %s:%s\n",
		 deva->bus ? deva->bus->name : "No Bus", dev_name(deva),
		 devb->bus ? devb->bus->name : "No Bus", dev_name(devb));
	/* Delete deva from dpm_list and reinsert before devb. */
	list_move_tail(&deva->power.entry, &devb->power.entry);
}

/**
 * device_pm_move_after - Move device in the PM core's list of active devices.
 * @deva: Device to move in dpm_list.
 * @devb: Device @deva should come after.
 */
void device_pm_move_after(struct device *deva, struct device *devb)
{
	pr_debug("PM: Moving %s:%s after %s:%s\n",
		 deva->bus ? deva->bus->name : "No Bus", dev_name(deva),
		 devb->bus ? devb->bus->name : "No Bus", dev_name(devb));
	/* Delete deva from dpm_list and reinsert after devb. */
	list_move(&deva->power.entry, &devb->power.entry);
}

/**
 * device_pm_move_last - Move device to end of the PM core's list of devices.
 * @dev: Device to move in dpm_list.
 */
void device_pm_move_last(struct device *dev)
{
	pr_debug("PM: Moving %s:%s to end of list\n",
		 dev->bus ? dev->bus->name : "No Bus", dev_name(dev));
	list_move_tail(&dev->power.entry, &dpm_list);
}

static ktime_t initcall_debug_start(struct device *dev)
{
	ktime_t calltime = ktime_set(0, 0);

	if (pm_print_times_enabled) {
		pr_info("calling  %s+ @ %i, parent: %s\n",
			dev_name(dev), task_pid_nr(current),
			dev->parent ? dev_name(dev->parent) : "none");
		calltime = ktime_get();
	}

	return calltime;
}

static void initcall_debug_report(struct device *dev, ktime_t calltime,
				  int error)
{
	ktime_t delta, rettime;

	if (pm_print_times_enabled) {
		rettime = ktime_get();
		delta = ktime_sub(rettime, calltime);
		pr_info("call %s+ returned %d after %Ld usecs\n", dev_name(dev),
			error, (unsigned long long)ktime_to_ns(delta) >> 10);
		if(initcall_debug_delay_ms > 0){
		    printk("sleep %d ms for debug. \n", initcall_debug_delay_ms);
		    msleep(initcall_debug_delay_ms);
		}
	}
}

/**
 * dpm_wait - Wait for a PM operation to complete.
 * @dev: Device to wait for.
 * @async: If unset, wait only if the device's power.async_suspend flag is set.
 */
static void dpm_wait(struct device *dev, bool async)
{
	if (!dev)
		return;

	if (async || (pm_async_enabled && dev->power.async_suspend))
		wait_for_completion(&dev->power.completion);
}

static int dpm_wait_fn(struct device *dev, void *async_ptr)
{
	dpm_wait(dev, *((bool *)async_ptr));
	return 0;
}

static void dpm_wait_for_children(struct device *dev, bool async)
{
       device_for_each_child(dev, &async, dpm_wait_fn);
}

/**
 * pm_op - Return the PM operation appropriate for given PM event.
 * @ops: PM operations to choose from.
 * @state: PM transition of the system being carried out.
 */
static pm_callback_t pm_op(const struct dev_pm_ops *ops, pm_message_t state)
{
	switch (state.event) {
#ifdef CONFIG_SUSPEND
	case PM_EVENT_SUSPEND:
		return ops->suspend;
	case PM_EVENT_RESUME:
		return ops->resume;
#endif /* CONFIG_SUSPEND */
#ifdef CONFIG_HIBERNATE_CALLBACKS
	case PM_EVENT_FREEZE:
	case PM_EVENT_QUIESCE:
		return ops->freeze;
	case PM_EVENT_HIBERNATE:
		return ops->poweroff;
	case PM_EVENT_THAW:
	case PM_EVENT_RECOVER:
		return ops->thaw;
		break;
	case PM_EVENT_RESTORE:
		return ops->restore;
#endif /* CONFIG_HIBERNATE_CALLBACKS */
	}

	return NULL;
}

/**
 * pm_late_early_op - Return the PM operation appropriate for given PM event.
 * @ops: PM operations to choose from.
 * @state: PM transition of the system being carried out.
 *
 * Runtime PM is disabled for @dev while this function is being executed.
 */
static pm_callback_t pm_late_early_op(const struct dev_pm_ops *ops,
				      pm_message_t state)
{
	switch (state.event) {
#ifdef CONFIG_SUSPEND
	case PM_EVENT_SUSPEND:
		return ops->suspend_late;
	case PM_EVENT_RESUME:
		return ops->resume_early;
#endif /* CONFIG_SUSPEND */
#ifdef CONFIG_HIBERNATE_CALLBACKS
	case PM_EVENT_FREEZE:
	case PM_EVENT_QUIESCE:
		return ops->freeze_late;
	case PM_EVENT_HIBERNATE:
		return ops->poweroff_late;
	case PM_EVENT_THAW:
	case PM_EVENT_RECOVER:
		return ops->thaw_early;
	case PM_EVENT_RESTORE:
		return ops->restore_early;
#endif /* CONFIG_HIBERNATE_CALLBACKS */
	}

	return NULL;
}

/**
 * pm_noirq_op - Return the PM operation appropriate for given PM event.
 * @ops: PM operations to choose from.
 * @state: PM transition of the system being carried out.
 *
 * The driver of @dev will not receive interrupts while this function is being
 * executed.
 */
static pm_callback_t pm_noirq_op(const struct dev_pm_ops *ops, pm_message_t state)
{
	switch (state.event) {
#ifdef CONFIG_SUSPEND
	case PM_EVENT_SUSPEND:
		return ops->suspend_noirq;
	case PM_EVENT_RESUME:
		return ops->resume_noirq;
#endif /* CONFIG_SUSPEND */
#ifdef CONFIG_HIBERNATE_CALLBACKS
	case PM_EVENT_FREEZE:
	case PM_EVENT_QUIESCE:
		return ops->freeze_noirq;
	case PM_EVENT_HIBERNATE:
		return ops->poweroff_noirq;
	case PM_EVENT_THAW:
	case PM_EVENT_RECOVER:
		return ops->thaw_noirq;
	case PM_EVENT_RESTORE:
		return ops->restore_noirq;
#endif /* CONFIG_HIBERNATE_CALLBACKS */
	}

	return NULL;
}

static char *pm_verb(int event)
{
	switch (event) {
	case PM_EVENT_SUSPEND:
		return "suspend";
	case PM_EVENT_RESUME:
		return "resume";
	case PM_EVENT_FREEZE:
		return "freeze";
	case PM_EVENT_QUIESCE:
		return "quiesce";
	case PM_EVENT_HIBERNATE:
		return "hibernate";
	case PM_EVENT_THAW:
		return "thaw";
	case PM_EVENT_RESTORE:
		return "restore";
	case PM_EVENT_RECOVER:
		return "recover";
	default:
		return "(unknown PM event)";
	}
}

static void pm_dev_dbg(struct device *dev, pm_message_t state, char *info)
{
	dev_dbg(dev, "%s%s%s\n", info, pm_verb(state.event),
		((state.event & PM_EVENT_SLEEP) && device_may_wakeup(dev)) ?
		", may wakeup" : "");
}

static void pm_dev_err(struct device *dev, pm_message_t state, char *info,
			int error)
{
	printk(KERN_ERR "PM: Device %s failed to %s%s: error %d\n",
		dev_name(dev), pm_verb(state.event), info, error);
}

static void dpm_show_time(ktime_t starttime, pm_message_t state, char *info)
{
	ktime_t calltime;
	u64 usecs64;
	int usecs;

	calltime = ktime_get();
	usecs64 = ktime_to_ns(ktime_sub(calltime, starttime));
	do_div(usecs64, NSEC_PER_USEC);
	usecs = usecs64;
	if (usecs == 0)
		usecs = 1;
	pr_info("PM: %s%s%s of devices complete after %ld.%03ld msecs\n",
		info ?: "", info ? " " : "", pm_verb(state.event),
		usecs / USEC_PER_MSEC, usecs % USEC_PER_MSEC);
}

static int dpm_run_callback(pm_callback_t cb, struct device *dev,
			    pm_message_t state, char *info)
{
	ktime_t calltime;
	int error;

	if (!cb)
		return 0;

	calltime = initcall_debug_start(dev);
	pm_dev_dbg(dev, state, info);
	error = cb(dev);
	suspend_report_result(cb, error);

	initcall_debug_report(dev, calltime, error);

	return error;
}

/**
 * dpm_wd_handler - Driver suspend / resume watchdog handler.
 *
 * Called when a driver has timed out suspending or resuming.
 * There's not much we can do here to recover so BUG() out for
 * a crash-dump
 */
static void dpm_wd_handler(unsigned long data)
{
	struct dpm_watchdog *wd = (void *)data;
	struct device *dev      = wd->dev;
	struct task_struct *tsk = wd->tsk;

	dev_emerg(dev, "**** DPM device timeout ****\n");
	show_stack(tsk, NULL);

	BUG();
}

/**
 * dpm_wd_set - Enable pm watchdog for given device.
 * @wd: Watchdog. Must be allocated on the stack.
 * @dev: Device to handle.
 */
static void dpm_wd_set(struct dpm_watchdog *wd, struct device *dev)
{
	struct timer_list *timer = &wd->timer;

	wd->dev = dev;
	wd->tsk = get_current();

	init_timer_on_stack(timer);
	timer->expires = jiffies + (initcall_debug_delay_ms/1000 + 12) * HZ;
	timer->function = dpm_wd_handler;
	timer->data = (unsigned long)wd;
	add_timer(timer);
}

/**
 * dpm_wd_clear - Disable pm watchdog.
 * @wd: Watchdog to disable.
 */
static void dpm_wd_clear(struct dpm_watchdog *wd)
{
	struct timer_list *timer = &wd->timer;

	del_timer_sync(timer);
	destroy_timer_on_stack(timer);
}

/*------------------------- Resume routines -------------------------*/

/**
 * device_resume_noirq - Execute an "early resume" callback for given device.
 * @dev: Device to handle.
 * @state: PM transition of the system being carried out.
 *
 * The driver of @dev will not receive interrupts while this function is being
 * executed.
 */
static int device_resume_noirq(struct device *dev, pm_message_t state)
{
	pm_callback_t callback = NULL;
	char *info = NULL;
	int error = 0;

	TRACE_DEVICE(dev);
	TRACE_RESUME(0);

	if (dev->power.syscore)
		goto Out;

	if (dev->pm_domain) {
		info = "noirq power domain ";
		callback = pm_noirq_op(&dev->pm_domain->ops, state);
	} else if (dev->type && dev->type->pm) {
		info = "noirq type ";
		callback = pm_noirq_op(dev->type->pm, state);
	} else if (dev->class && dev->class->pm) {
		info = "noirq class ";
		callback = pm_noirq_op(dev->class->pm, state);
	} else if (dev->bus && dev->bus->pm) {
		info = "noirq bus ";
		callback = pm_noirq_op(dev->bus->pm, state);
	}

	if (!callback && dev->driver && dev->driver->pm) {
		info = "noirq driver ";
		callback = pm_noirq_op(dev->driver->pm, state);
	}

	error = dpm_run_callback(callback, dev, state, info);

 Out:
	TRACE_RESUME(error);
	return error;
}

/**
 * dpm_resume_noirq - Execute "noirq resume" callbacks for all devices.
 * @state: PM transition of the system being carried out.
 *
 * Call the "noirq" resume handlers for all devices in dpm_noirq_list and
 * enable device drivers to receive interrupts.
 */
static void dpm_resume_noirq(pm_message_t state)
{
	ktime_t starttime = ktime_get();

	mutex_lock(&dpm_list_mtx);
	while (!list_empty(&dpm_noirq_list)) {
		struct device *dev = to_device(dpm_noirq_list.next);
		int error;

		get_device(dev);
		list_move_tail(&dev->power.entry, &dpm_late_early_list);
		mutex_unlock(&dpm_list_mtx);

		error = device_resume_noirq(dev, state);
		if (error) {
			suspend_stats.failed_resume_noirq++;
			dpm_save_failed_step(SUSPEND_RESUME_NOIRQ);
			dpm_save_failed_dev(dev_name(dev));
			pm_dev_err(dev, state, " noirq", error);
		}

		mutex_lock(&dpm_list_mtx);
		put_device(dev);
	}
	mutex_unlock(&dpm_list_mtx);
	dpm_show_time(starttime, state, "noirq");
	resume_device_irqs();
	cpuidle_resume();
}

/**
 * device_resume_early - Execute an "early resume" callback for given device.
 * @dev: Device to handle.
 * @state: PM transition of the system being carried out.
 *
 * Runtime PM is disabled for @dev while this function is being executed.
 */
static int device_resume_early(struct device *dev, pm_message_t state)
{
	pm_callback_t callback = NULL;
	char *info = NULL;
	int error = 0;

	TRACE_DEVICE(dev);
	TRACE_RESUME(0);

	if (dev->power.syscore)
		goto Out;

	if (dev->pm_domain) {
		info = "early power domain ";
		callback = pm_late_early_op(&dev->pm_domain->ops, state);
	} else if (dev->type && dev->type->pm) {
		info = "early type ";
		callback = pm_late_early_op(dev->type->pm, state);
	} else if (dev->class && dev->class->pm) {
		info = "early class ";
		callback = pm_late_early_op(dev->class->pm, state);
	} else if (dev->bus && dev->bus->pm) {
		info = "early bus ";
		callback = pm_late_early_op(dev->bus->pm, state);
	}

	if (!callback && dev->driver && dev->driver->pm) {
		info = "early driver ";
		callback = pm_late_early_op(dev->driver->pm, state);
	}

	error = dpm_run_callback(callback, dev, state, info);

 Out:
	TRACE_RESUME(error);

	pm_runtime_enable(dev);
	return error;
}

/**
 * dpm_resume_early - Execute "early resume" callbacks for all devices.
 * @state: PM transition of the system being carried out.
 */
static void dpm_resume_early(pm_message_t state)
{
	ktime_t starttime = ktime_get();

	mutex_lock(&dpm_list_mtx);
	while (!list_empty(&dpm_late_early_list)) {
		struct device *dev = to_device(dpm_late_early_list.next);
		int error;

		get_device(dev);
		list_move_tail(&dev->power.entry, &dpm_suspended_list);
		mutex_unlock(&dpm_list_mtx);

		error = device_resume_early(dev, state);
		if (error) {
			suspend_stats.failed_resume_early++;
			dpm_save_failed_step(SUSPEND_RESUME_EARLY);
			dpm_save_failed_dev(dev_name(dev));
			pm_dev_err(dev, state, " early", error);
		}

		mutex_lock(&dpm_list_mtx);
		put_device(dev);
	}
	mutex_unlock(&dpm_list_mtx);
	dpm_show_time(starttime, state, "early");
}

/**
 * dpm_resume_start - Execute "noirq" and "early" device callbacks.
 * @state: PM transition of the system being carried out.
 */
void dpm_resume_start(pm_message_t state)
{
	dpm_resume_noirq(state);
	dpm_resume_early(state);
}
EXPORT_SYMBOL_GPL(dpm_resume_start);

/**
 * device_resume - Execute "resume" callbacks for given device.
 * @dev: Device to handle.
 * @state: PM transition of the system being carried out.
 * @async: If true, the device is being resumed asynchronously.
 */
static int device_resume(struct device *dev, pm_message_t state, bool async)
{
	pm_callback_t callback = NULL;
	char *info = NULL;
	int error = 0;
	struct dpm_watchdog wd;

	TRACE_DEVICE(dev);
	TRACE_RESUME(0);

	if (dev->power.syscore)
		goto Complete;

	dpm_wait(dev->parent, async);
	device_lock(dev);

	/*
	 * This is a fib.  But we'll allow new children to be added below
	 * a resumed device, even if the device hasn't been completed yet.
	 */
	dev->power.is_prepared = false;
	dpm_wd_set(&wd, dev);

	if (!dev->power.is_suspended)
		goto Unlock;

	if (dev->pm_domain) {
		info = "power domain ";
		callback = pm_op(&dev->pm_domain->ops, state);
		goto Driver;
	}

	if (dev->type && dev->type->pm) {
		info = "type ";
		callback = pm_op(dev->type->pm, state);
		goto Driver;
	}

	if (dev->class) {
		if (dev->class->pm) {
			info = "class ";
			callback = pm_op(dev->class->pm, state);
			goto Driver;
		} else if (dev->class->resume) {
			info = "legacy class ";
			callback = dev->class->resume;
			goto End;
		}
	}

	if (dev->bus) {
		if (dev->bus->pm) {
			info = "bus ";
			callback = pm_op(dev->bus->pm, state);
		} else if (dev->bus->resume) {
			info = "legacy bus ";
			callback = dev->bus->resume;
			goto End;
		}
	}

 Driver:
	if (!callback && dev->driver && dev->driver->pm) {
		info = "driver ";
		callback = pm_op(dev->driver->pm, state);
	}

 End:
	error = dpm_run_callback(callback, dev, state, info);
	dev->power.is_suspended = false;

 Unlock:
	device_unlock(dev);
	dpm_wd_clear(&wd);

 Complete:
	complete_all(&dev->power.completion);

	TRACE_RESUME(error);

	return error;
}

static void async_resume(void *data, async_cookie_t cookie)
{
	struct device *dev = (struct device *)data;
	int error;

	error = device_resume(dev, pm_transition, true);
	if (error)
		pm_dev_err(dev, pm_transition, " async", error);
	put_device(dev);
}

static bool is_async(struct device *dev)
{
	return dev->power.async_suspend && pm_async_enabled
		&& !pm_trace_is_enabled();
}

/**
 * dpm_resume - Execute "resume" callbacks for non-sysdev devices.
 * @state: PM transition of the system being carried out.
 *
 * Execute the appropriate "resume" callback for all devices whose status
 * indicates that they are suspended.
 */
void dpm_resume(pm_message_t state)
{
	struct device *dev;
	ktime_t starttime = ktime_get();

	might_sleep();

	mutex_lock(&dpm_list_mtx);
	pm_transition = state;
	async_error = 0;

	list_for_each_entry(dev, &dpm_suspended_list, power.entry) {
		INIT_COMPLETION(dev->power.completion);
		if (is_async(dev)) {
			get_device(dev);
			async_schedule(async_resume, dev);
		}
	}

	while (!list_empty(&dpm_suspended_list)) {
		dev = to_device(dpm_suspended_list.next);
		get_device(dev);
		if (!is_async(dev)) {
			int error;

			mutex_unlock(&dpm_list_mtx);

			error = device_resume(dev, state, false);
			if (error) {
				suspend_stats.failed_resume++;
				dpm_save_failed_step(SUSPEND_RESUME);
				dpm_save_failed_dev(dev_name(dev));
				pm_dev_err(dev, state, "", error);
			}

			mutex_lock(&dpm_list_mtx);
		}
		if (!list_empty(&dev->power.entry))
			list_move_tail(&dev->power.entry, &dpm_prepared_list);
		put_device(dev);
	}
	mutex_unlock(&dpm_list_mtx);
	async_synchronize_full();
	dpm_show_time(starttime, state, NULL);

	cpufreq_resume();
}

/**
 * device_complete - Complete a PM transition for given device.
 * @dev: Device to handle.
 * @state: PM transition of the system being carried out.
 */
static void device_complete(struct device *dev, pm_message_t state)
{
	void (*callback)(struct device *) = NULL;
	char *info = NULL;

	if (dev->power.syscore)
		return;

	device_lock(dev);

	if (dev->pm_domain) {
		info = "completing power domain ";
		callback = dev->pm_domain->ops.complete;
	} else if (dev->type && dev->type->pm) {
		info = "completing type ";
		callback = dev->type->pm->complete;
	} else if (dev->class && dev->class->pm) {
		info = "completing class ";
		callback = dev->class->pm->complete;
	} else if (dev->bus && dev->bus->pm) {
		info = "completing bus ";
		callback = dev->bus->pm->complete;
	}

	if (!callback && dev->driver && dev->driver->pm) {
		info = "completing driver ";
		callback = dev->driver->pm->complete;
	}

	if (callback) {
		pm_dev_dbg(dev, state, info);
		callback(dev);
	}

	device_unlock(dev);

	pm_runtime_put(dev);
}

/**
 * dpm_complete - Complete a PM transition for all non-sysdev devices.
 * @state: PM transition of the system being carried out.
 *
 * Execute the ->complete() callbacks for all devices whose PM status is not
 * DPM_ON (this allows new devices to be registered).
 */
void dpm_complete(pm_message_t state)
{
	struct list_head list;

	might_sleep();

	INIT_LIST_HEAD(&list);
	mutex_lock(&dpm_list_mtx);
	while (!list_empty(&dpm_prepared_list)) {
		struct device *dev = to_device(dpm_prepared_list.prev);

		get_device(dev);
		dev->power.is_prepared = false;
		list_move(&dev->power.entry, &list);
		mutex_unlock(&dpm_list_mtx);

		device_complete(dev, state);

		mutex_lock(&dpm_list_mtx);
		put_device(dev);
	}
	list_splice(&list, &dpm_list);
	mutex_unlock(&dpm_list_mtx);
}

/**
 * dpm_resume_end - Execute "resume" callbacks and complete system transition.
 * @state: PM transition of the system being carried out.
 *
 * Execute "resume" callbacks for all devices and complete the PM transition of
 * the system.
 */
void dpm_resume_end(pm_message_t state)
{
	dpm_resume(state);
	dpm_complete(state);
}
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

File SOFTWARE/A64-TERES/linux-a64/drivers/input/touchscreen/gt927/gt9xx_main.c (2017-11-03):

/* drivers/input/touchscreen/gt9xx.c
 * 
 * 2010 - 2012 Goodix Technology.
 * 
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
 * Version:1.2
 * Author:andrew@goodix.com
 * Release Date:2012/10/15
 * Revision record:
 *      V1.0:2012/08/31,first Release
 *      V1.2:2012/10/15,modify gtp_reset_guitar,slot report,tracking_id & 0x0F
 *
 */

#include <linux/irq.h>
#include <linux/pinctrl/pinctrl.h>
#include <linux/pinctrl/pinconf-sunxi.h>
#include <linux/pinctrl/consumer.h>
#include "gt9xx.h"
#include "gt9xx_config.h"

#if GTP_ICS_SLOT_REPORT
    #include <linux/input/mt.h>
#endif

static const char *goodix_ts_name = "gt9xx";
static struct workqueue_struct *goodix_wq;
static struct i2c_client * i2c_connect_client = NULL; 
static u8 config[GTP_CONFIG_MAX_LENGTH + GTP_ADDR_LENGTH]
                = {GTP_REG_CONFIG_DATA >> 8, GTP_REG_CONFIG_DATA & 0xff};

#if GTP_HAVE_TOUCH_KEY
	static const u16 touch_key_array[] = GTP_KEY_TAB;
	#define GTP_MAX_KEY_NUM	 (sizeof(touch_key_array)/sizeof(touch_key_array[0]))
#endif

static s8 gtp_i2c_test(struct i2c_client *client);
void gtp_reset_guitar(s32 ms);
void gtp_int_sync(s32 ms);

#ifdef CONFIG_HAS_EARLYSUSPEND
static void goodix_ts_early_suspend(struct early_suspend *h);
static void goodix_ts_late_resume(struct early_suspend *h);
#endif
 
//#if GTP_CREATE_WR_NODE
//extern s32 init_wr_node(struct i2c_client*);
//extern void uninit_wr_node(void);
//#endif

//#if GTP_AUTO_UPDATE
//extern u8 gup_init_update_proc(struct goodix_ts_data *);
//#endif

#if GTP_ESD_PROTECT
static struct delayed_work gtp_esd_check_work;
static struct workqueue_struct * gtp_esd_check_workqueue = NULL;
static void gtp_esd_check_func(struct work_struct *);
#endif


#define CTP_NAME GTP_I2C_NAME
#define CTP_IRQ_NUMBER          (config_info.int_number)
#define CTP_IRQ_MODE		(IRQF_TRIGGER_FALLING)
static int screen_max_x = 0;
static int screen_max_y = 0;
static int revert_x_flag = 0;
static int revert_y_flag = 0;
static int exchange_x_y_flag = 0;
static char irq_pin_name[8];

struct ctp_config_info config_info = {
	.input_type = CTP_TYPE,
	.name = NULL,
	.int_number = 0,
};

static u32 debug_mask = 0;
enum{
	DEBUG_INIT = 1U << 0,
	DEBUG_SUSPEND = 1U << 1,
	DEBUG_INT_INFO = 1U << 2,
	DEBUG_X_Y_INFO = 1U << 3,
	DEBUG_KEY_INFO = 1U << 4,
	DEBUG_WAKEUP_INFO = 1U << 5,
	DEBUG_OTHERS_INFO = 1U << 6,
};
#define dprintk(level_mask,fmt,arg...)    if(unlikely(debug_mask & level_mask)) \
        printk("***CTP***"fmt, ## arg)

static __u32 twi_id = 0;

static const unsigned short normal_i2c[2] = {0x5d,I2C_CLIENT_END};
static const uint8_t chip_id_value[3] = {0x11,0x27,0x28};
static uint8_t read_chip_value[3] = {0x81,0x41,0};

static int fw_index = 0;
static int update_enable = 0;

char *firmware_name = "GT927_1030_D2A9.BIN";

static int name2index(const char* name)
{
	int i = 0;
	
	for (i=0; i<ARRAY_SIZE(gt9xx_fw_grp); i++) {
		if (!strcmp(name, gt9xx_fw_grp[i].name))
		{
            printk("gt9xx:index = %d\n",i);
			return i;
		}
	}
    pr_err("gt9xx:config name %s,not in array!please check sys_config!\n",name);
	return -1;
}
static int ctp_wakeup(int status,int ms)
{
	dprintk(DEBUG_INIT,"***CTP*** %s:status:%d,ms = %d\n",__func__,status,ms);

	if (status == 0) {

		if(ms == 0) {
			__gpio_set_value(config_info.wakeup_gpio.gpio, 0);
		}else {
			__gpio_set_value(config_info.wakeup_gpio.gpio, 0);
			msleep(ms);
			__gpio_set_value(config_info.wakeup_gpio.gpio, 1);
		}
	}
	if (status == 1) {
		if(ms == 0) {
			__gpio_set_value(config_info.wakeup_gpio.gpio, 1);
		}else {
			__gpio_set_value(config_info.wakeup_gpio.gpio, 1);
			msleep(ms);
			__gpio_set_value(config_info.wakeup_gpio.gpio, 0);
		}
	}
	msleep(5);

	return 0;
}
static void gtp_set_int_value(int status)
{
        long unsigned int	config;
		
		config = SUNXI_PINCFG_PACK(SUNXI_PINCFG_TYPE_FUNC,0xFFFF);
	    pin_config_get(SUNXI_PINCTRL,irq_pin_name,&config);

		if (1 != SUNXI_PINCFG_UNPACK_VALUE(config)){
		      config = SUNXI_PINCFG_PACK(SUNXI_PINCFG_TYPE_FUNC,1);
			  pin_config_set(SUNXI_PINCTRL,irq_pin_name,config);;
	    }

        __gpio_set_value(CTP_IRQ_NUMBER, status);   
}
static void gtp_io_init(int ms)
{       
        ctp_wakeup(0, 0);
        msleep(ms);
        
        gtp_set_int_value(0);
        msleep(2);
        
        ctp_wakeup(1, 0);
        msleep(6);

        
#if GTP_ESD_PROTECT
     //   gtp_init_ext_watchdog(client);
#endif
        
}
static void gtp_set_io_int(void)
{
        long unsigned int	config;
		config = SUNXI_PINCFG_PACK(SUNXI_PINCFG_TYPE_FUNC,0xFFFF);
	    pin_config_get(SUNXI_PINCTRL,irq_pin_name,&config);

		if (6 != SUNXI_PINCFG_UNPACK_VALUE(config)){		
		      config = SUNXI_PINCFG_PACK(SUNXI_PINCFG_TYPE_FUNC,6);		 
			  pin_config_set(SUNXI_PINCTRL,irq_pin_name,config);
	    }
        
}
//#define CTP_IRQ_MODE		(TRIG_EDGE_NEGATIVE)

//#define GTP_MAX_HEIGHT   screen_max_x
//#define GTP_MAX_WIDTH    screen_max_y
/****************************************** 
**int2io:                                 
**status:                                 
**      1:io output 0:io input            
**level:                                  
**      1:output high 0:output low        
******************************************/
void int2io(int status,int level)
{
    int req_success;

    req_success = (0 == gpio_request(config_info.int_number, NULL));
    if(status == 1)
    {
        dprintk(DEBUG_INIT,"irq pin set to output function\n");
        gpio_direction_output(config_info.int_number, level);
    }
    else if(status == 0)
    {
        gpio_direction_input(config_info.int_number);
    }
    if(req_success){
        gpio_free(config_info.int_number);
    }
    else
    {
        printk("int2io gpio request failed! config_info.irq_gpio_number = %d,ret = %d\n",config_info.int_number,req_success);
    }

}
void gtp_irq_disable(struct goodix_ts_data *ts)
{
        unsigned long irqflags;
		int ret;

        dprintk(DEBUG_INIT,"%s ---start!---\n", __func__);
        spin_lock_irqsave(&ts->irq_lock, irqflags);
        if (!ts->irq_is_disable) {
               ts->irq_is_disable = 1; 
               ret = input_set_int_enable(&(config_info.input_type), 0);
			   if (ret < 0)		          
			   	  printk("%s irq disable failed\n", goodix_ts_name);
        }
        spin_unlock_irqrestore(&ts->irq_lock, irqflags);
}

/*******************************************************
Function:
	Disable IRQ Function.

Input:
	ts:	i2c client private struct.
	
Output:
	None.
*******************************************************/
void gtp_irq_enable(struct goodix_ts_data *ts)
{
        unsigned long irqflags = 0;
		int ret;

        dprintk(DEBUG_INIT,"%s ---start!---\n", __func__);
    
        spin_lock_irqsave(&ts->irq_lock, irqflags);
        if (ts->irq_is_disable) {
                ts->irq_is_disable = 0; 
                ret = input_set_int_enable(&(config_info.input_type), 1);	
				if (ret < 0)		            
					printk("%s irq enable failed\n", goodix_ts_name);
        }
        spin_unlock_irqrestore(&ts->irq_lock, irqflags);
}
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

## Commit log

2017-01-26 Hardware files
    [LCD.sch, NAND Flash , eMMC, T-Card and Audio.sch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]
2017-01-29 * Added ARM Trusted firmware * Linux Kernel sources * U-Boot Sources
    [1066mhz_4x128mx16.cfg, 1066mhz_4x256mx16.cfg, 800mhz_2x128mx16.cfg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]
2017-01-29 Revert "* Added ARM Trusted firmware"
    This reverts commit 7bf9b8c44a5f25e1aac19fd17593456e6771502c.
    [1066mhz_4x128mx16.cfg, 1066mhz_4x256mx16.cfg, 800mhz_2x128mx16.cfg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]
2017-01-29 * Added ARM Trusted Firmwre
2017-01-29 * Added U-Boot sources
    [1066mhz_4x128mx16.cfg, 1066mhz_4x256mx16.cfg, 800mhz_2x128mx16.cfg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]
2017-01-29 * Added Linux Kernel
    [ALSA-Configuration.txt, ConfigurationXML.h, alsa-parameters.txt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]
2017-01-30 * Added Device Tree for Teres
2017-10-13 Import repos from https://github.com/A64-TERES
    [1066mhz_4x128mx16.cfg, 1066mhz_4x256mx16.cfg, 800mhz_2x128mx16.cfg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]
2017-11-06 Fixed wrong regex, now script report correct device partitions
2017-11-06 install-arduino-ide.sh added, this script will install Arduino IDE
2017-11-06 Disable wake up by inserting AC adapter
2017-11-22 teres1-ledctrl: add more looops
2017-11-22 input device by path
2017-12-18 Added schematics files in PDF
2017-12-18 Updated to release version
    [LCD.sch, NAND Flash , eMMC, T-Card and Audio.sch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]
2017-12-18 added schematics in pdf
2017-12-21 c204, c206 values fixed
    [LCD.sch]
2018-05-18 Code cleanup: formatting, added conditional error
    [teres1-audioselect.c]
2018-05-31 Moved old/PCB_NAME -> PCB_NAME/Rev.X<.old>
    [LCD.sch, NAND Flash , eMMC, T-Card and Audio.sch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]
2018-05-31 Moved old/KiCAD* -> KiCad/*.old
2018-05-31 Create evaluation-board-notice.md
    This document is referenced from https://www.olimex.com/Products/Disclamer/evaluation-board-notice/
2018-05-31 Move assembly instruction to hardware section
    Link "doc/web/hw_in-the-box.md" to be moved to assembly page.
2018-05-31 Add assembled laptop image
    Was missing at some point during the migration
2018-06-05 Added link to community 3d-printing effort
2018-06-13 Link reference to 3rd-party 3D-printed case design
    Maybe this case design can be formally adopted?
2018-06-24 Create LICENSE: Dean Camera's LUFA USB stack
2018-06-25 Add reference to TERES-019-Camera
2018-10-15 Remove identical backups since it's all code versioned
    [TERES-PCB2-IO_Rev.B.kicad_pcb, TERES-PCB3-TOUCH-BTN_Rev.A.kicad_pcb, TERES-PCB4-PWR-BTN_Rev.A.kicad_pcb]
2018-12-05 Interrupt boot from 's' key to avoid debug jack uart unwanted chars
2018-12-05 MMC Driver ported from BSP3.0
2018-12-05 Changes for MMC BSP 3.0 driver
2018-12-05 Dual display mode enabled by default Driver modified to support custom HDMI resolutions
2018-12-07 Fixed typos. Since boot partition detect is done by u-boot, there is no change in kernel part table, so mmcblk0 will be boot device in any case
2019-01-22 Chromium disable seccomp filter teres1-debug fixed install dependecy
2019-03-04 make_simpleimage.sh: Fix on mkfs.ext4 options
    Disable options metadata_csum & 64bit after mkfs.ext4
    using tune2fs. Fixes the following error on boot:
    [ 37.259701] EXT4-fs (mmcblk0p2): couldn't mount as ext3 due to feature incompatibilities
    [ 37.269247] EXT4-fs (mmcblk0p2): couldn't mount as ext2 due to feature incompatibilities
    [ 37.288201] JBD2: Unrecognised features on journal
    [ 37.293429] EXT4-fs (mmcblk0p2): error loading journal
    [ 37.349186] UDF-fs: warning (device mmcblk0p2): udf_fill_super: No partition found (2)
2020-06-09 add BOMs in PDF format PCB1-PCB5
2021-09-25 600 DPI scan of keyboard traces.
    This is a scan of the plastic film under the keyboard keys, made with a Canon MX922 printer.
2022-09-14 PCB1_A64_MAIN_REV_C: Translated in English
    The manufacturer that I sent this to was confused by the bulgarian so I translated this in english.
2024-03-14 README: Add link on OFTC #teres
    Add an IRC room used by teres users to talk and work on the device

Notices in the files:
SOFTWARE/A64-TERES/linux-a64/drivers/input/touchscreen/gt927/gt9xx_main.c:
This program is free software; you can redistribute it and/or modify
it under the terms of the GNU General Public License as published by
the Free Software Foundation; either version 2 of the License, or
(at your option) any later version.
